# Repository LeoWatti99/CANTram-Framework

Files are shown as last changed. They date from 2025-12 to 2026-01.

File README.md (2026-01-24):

# CAN-TRAM-Framework
Das CAN-TRAM-Framework ist ein mikrocontrollerbasiertes, modulares Steuerungssystem, dass sich aus einzelnen Modulen zusammensetzen lässt. Die Struktur des Systems orientiert sich an üblichen SPS-Systemen, sodass eine CPU bzw. ein Hauptmodul um beliebig viele Module erweitert werden kann, um Funktionen hinzuzufügen.



## Inventor CAD Dateien öffnen
Die CAD Dateien des Projekts sind im Ordner [Inventor CAD](https://github.com/LeoWatti99/CANTram-Framework/tree/main/Inventor%20CAD)) enthalten. Um das Projekt wie vorgesehen zu öffnen muss in **Inventor 2025 oder höher** die Datei [Controller.ipj](https://github.com/LeoWatti99/CANTram-Framework/blob/main/Inventor%20CAD/Controller.ipj) geöffnet werden.

## KiCAD Schaltungen öffnen
Im Ordner [KiCad Schaltungen](https://github.com/LeoWatti99/CANTram-Framework/tree/main/KiCad%20Schaltungen) sind alle Projekte der einzelnen Platinen enthalten. Darin befinden sich sowhol Prototypen Schaltungen als auch aktuelle Modulplatinen. Um die Projekt zu öffnen wird **KiCAD 9.0.6 benötigt**. über die **.kicad_pro-Dateien** in den Unterordnern können die Projekte vollständig mit der Verlinkung zwischen Schaltplan und Layout geöffnet werden.

## C++ Framework
Die Firmware des Systems ist als C++ Bibliothek im Ordner [Framework](https://github.com/LeoWatti99/CANTram-Framework/tree/main/Framework) enthalten. 

## Dokumentation 
Die Software-Dokumentation kann [hier](https://leowatti99.github.io/CANTram-Framework/inherits.html) geöffnet werden. Sie wird automatisch durch **Doxygen** erstellt und nach Änderungen des Codes aktualisiert.

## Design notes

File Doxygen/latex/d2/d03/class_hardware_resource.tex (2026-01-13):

\doxysection{Hardware\+Resource Class Reference}
\hypertarget{class_hardware_resource}{}\label{class_hardware_resource}\index{HardwareResource@{HardwareResource}}

Base class for hardware resources like UART, SPI, I2C, PWM, etc.  

{\ttfamily \#include $<$Hardware\+Resource.\+h$>$}

Inheritance diagram for Hardware\+Resource\+:
\nopagebreak
\begin{figure}[H]
\begin{center}
\leavevmode
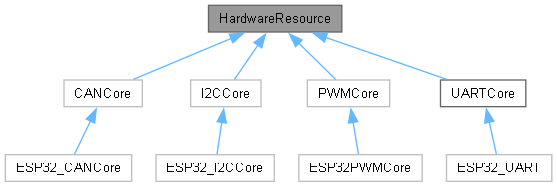
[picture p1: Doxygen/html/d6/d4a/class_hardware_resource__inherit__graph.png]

\end{center}
\end{figure}
\doxysubsubsection*{Public Types}
\begin{DoxyCompactItemize}
\item 
enum \mbox{\hyperlink{class_hardware_resource_adead6978be3d7b86c18e3d3e051381e6}{Type}} \{ \newline
\mbox{\hyperlink{class_hardware_resource_adead6978be3d7b86c18e3d3e051381e6ac6f39e4a2dbc764df53048f26209f0a1}{UART}}
, \mbox{\hyperlink{class_hardware_resource_adead6978be3d7b86c18e3d3e051381e6a63a2eead0d2771007afa8c8af281c50d}{SPI}}
, \mbox{\hyperlink{class_hardware_resource_adead6978be3d7b86c18e3d3e051381e6ac77292ec986f613995babba396598dbc}{I2C}}
, \mbox{\hyperlink{class_hardware_resource_adead6978be3d7b86c18e3d3e051381e6ac2fe3e8cc9a9a8fcb39c32be2da214c5}{PWM}}
, \newline
\mbox{\hyperlink{class_hardware_resource_adead6978be3d7b86c18e3d3e051381e6a0ae946256af51077cacc3c0a11575635}{CAN}}
 \}
\begin{DoxyCompactList}\small\item\em Enumeration of hardware resource types. \end{DoxyCompactList}\end{DoxyCompactItemize}
\doxysubsubsection*{Public Member Functions}
\begin{DoxyCompactItemize}
\item 
virtual \mbox{\hyperlink{class_hardware_resource_adead6978be3d7b86c18e3d3e051381e6}{Type}} \mbox{\hyperlink{class_hardware_resource_ad1058e4c12406f756755fad5db55dc77}{get\+Type}} ()=0
\begin{DoxyCompactList}\small\item\em Get the hardware resource type. \end{DoxyCompactList}\item 
virtual bool \mbox{\hyperlink{class_hardware_resource_a7372684f2afb5139ef8464194a087649}{reset}} ()
\begin{DoxyCompactList}\small\item\em Reset the hardware resource to a known default state. \end{DoxyCompactList}\item 
bool \mbox{\hyperlink{class_hardware_resource_a26f48b38e5bb1d9bdd47ea2e6de87fdb}{request\+Usage}} ()
\begin{DoxyCompactList}\small\item\em Request a usage slot for this resource. \end{DoxyCompactList}\item 
uint8\+\_\+t \mbox{\hyperlink{class_hardware_resource_a07205354c25627a3bb10ad417e335ff9}{get\+Usages}} ()
\begin{DoxyCompactList}\small\item\em Get the current number of usages of this resource. \end{DoxyCompactList}\item 
bool \mbox{\hyperlink{class_hardware_resource_a569821aa9a34d96ed143488a72e6872b}{is\+Used}} ()
\begin{DoxyCompactList}\small\item\em Check if the resource is currently used. \end{DoxyCompactList}\item 
virtual uint8\+\_\+t \mbox{\hyperlink{class_hardware_resource_a470679cae7880c9ca436755a50f68db4}{get\+Remaining\+Usages}} ()
\begin{DoxyCompactList}\small\item\em Get remaining usage capacity for this resource. \end{DoxyCompactList}\end{DoxyCompactItemize}
\doxysubsubsection*{Protected Member Functions}
\begin{DoxyCompactItemize}
\item 
\mbox{\hyperlink{class_hardware_resource_a7ddffb890a743f2df28128d9afd5bfa5}{Hardware\+Resource}} ()=default
\begin{DoxyCompactList}\small\item\em Default constructor. \end{DoxyCompactList}\item 
virtual uint8\+\_\+t \mbox{\hyperlink{class_hardware_resource_a6b7a709561faf5d344b7c3e14bf37558}{get\+Max\+Usages}} ()
\begin{DoxyCompactList}\small\item\em Get the maximum simultaneous usages allowed for this resource. \end{DoxyCompactList}\end{DoxyCompactItemize}
\doxysubsubsection*{Protected Attributes}
\begin{DoxyCompactItemize}
\item 
uint8\+\_\+t \mbox{\hyperlink{class_hardware_resource_a78845b363f906c0383e91ea912bbddbc}{usages}} =0
\begin{DoxyCompactList}\small\item\em Current usage counter. \end{DoxyCompactList}\end{DoxyCompactItemize}

\doxysubsection{Detailed Description}
Base class for hardware resources like UART, SPI, I2C, PWM, etc. 

\doxylink{class_hardware_resource}{Hardware\+Resource} provides a common interface for resources managed by \doxylink{class_c_a_n_tram_core}{CANTram\+Core}. It implements usage counting and default reset/usage behaviour. Derived classes must implement \doxylink{class_hardware_resource_ad1058e4c12406f756755fad5db55dc77}{get\+Type()} and may override \doxylink{class_hardware_resource_a6b7a709561faf5d344b7c3e14bf37558}{get\+Max\+Usages()} and \doxylink{class_hardware_resource_a7372684f2afb5139ef8464194a087649}{reset()} as required. 

\label{doc-enum-members}
\Hypertarget{class_hardware_resource_doc-enum-members}
\doxysubsection{Member Enumeration Documentation}
\Hypertarget{class_hardware_resource_adead6978be3d7b86c18e3d3e051381e6}\index{HardwareResource@{HardwareResource}!Type@{Type}}
\index{Type@{Type}!HardwareResource@{HardwareResource}}
\doxysubsubsection{\texorpdfstring{Type}{Type}}
{\footnotesize\ttfamily \label{class_hardware_resource_adead6978be3d7b86c18e3d3e051381e6} 
enum \mbox{\hyperlink{class_hardware_resource_adead6978be3d7b86c18e3d3e051381e6}{Hardware\+Resource\+::\+Type}}}

Enumeration of hardware resource types. 

Used to identify the concrete resource type when requesting or attaching resources. \begin{DoxyEnumFields}[2]{Enumerator}
\raisebox{\heightof{T}}[0pt][0pt]{\index{UART@{UART}!HardwareResource@{HardwareResource}}\index{HardwareResource@{HardwareResource}!UART@{UART}}}\Hypertarget{class_hardware_resource_adead6978be3d7b86c18e3d3e051381e6ac6f39e4a2dbc764df53048f26209f0a1}\label{class_hardware_resource_adead6978be3d7b86c18e3d3e051381e6ac6f39e4a2dbc764df53048f26209f0a1} 
UART&UART type. \\
\hline

\raisebox{\heightof{T}}[0pt][0pt]{\index{SPI@{SPI}!HardwareResource@{HardwareResource}}\index{HardwareResource@{HardwareResource}!SPI@{SPI}}}\Hypertarget{class_hardware_resource_adead6978be3d7b86c18e3d3e051381e6a63a2eead0d2771007afa8c8af281c50d}\label{class_hardware_resource_adead6978be3d7b86c18e3d3e051381e6a63a2eead0d2771007afa8c8af281c50d} 
SPI&SPI type. \\
\hline

\raisebox{\heightof{T}}[0pt][0pt]{\index{I2C@{I2C}!HardwareResource@{HardwareResource}}\index{HardwareResource@{HardwareResource}!I2C@{I2C}}}\Hypertarget{class_hardware_resource_adead6978be3d7b86c18e3d3e051381e6ac77292ec986f613995babba396598dbc}\label{class_hardware_resource_adead6978be3d7b86c18e3d3e051381e6ac77292ec986f613995babba396598dbc} 
I2C&I2C type. \\
\hline

\raisebox{\heightof{T}}[0pt][0pt]{\index{PWM@{PWM}!HardwareResource@{HardwareResource}}\index{HardwareResource@{HardwareResource}!PWM@{PWM}}}\Hypertarget{class_hardware_resource_adead6978be3d7b86c18e3d3e051381e6ac2fe3e8cc9a9a8fcb39c32be2da214c5}\label{class_hardware_resource_adead6978be3d7b86c18e3d3e051381e6ac2fe3e8cc9a9a8fcb39c32be2da214c5} 
PWM&PWM type. \\
\hline

\raisebox{\heightof{T}}[0pt][0pt]{\index{CAN@{CAN}!HardwareResource@{HardwareResource}}\index{HardwareResource@{HardwareResource}!CAN@{CAN}}}\Hypertarget{class_hardware_resource_adead6978be3d7b86c18e3d3e051381e6a0ae946256af51077cacc3c0a11575635}\label{class_hardware_resource_adead6978be3d7b86c18e3d3e051381e6a0ae946256af51077cacc3c0a11575635} 
CAN&CAN type. \\
\hline

\end{DoxyEnumFields}

\label{doc-constructors}
\Hypertarget{class_hardware_resource_doc-constructors}
\doxysubsection{Constructor \& Destructor Documentation}
\Hypertarget{class_hardware_resource_a7ddffb890a743f2df28128d9afd5bfa5}\index{HardwareResource@{HardwareResource}!HardwareResource@{HardwareResource}}
\index{HardwareResource@{HardwareResource}!HardwareResource@{HardwareResource}}
\doxysubsubsection{\texorpdfstring{HardwareResource()}{HardwareResource()}}
{\footnotesize\ttfamily \label{class_hardware_resource_a7ddffb890a743f2df28128d9afd5bfa5} 
Hardware\+Resource\+::\+Hardware\+Resource (\begin{DoxyParamCaption}{}{}\end{DoxyParamCaption})\hspace{0.3cm}{\ttfamily [protected]}, {\ttfamily [default]}}

Default constructor. 

Protected to prevent direct instantiation of the abstract base class. 

\label{doc-func-members}
\Hypertarget{class_hardware_resource_doc-func-members}
\doxysubsection{Member Function Documentation}
\Hypertarget{class_hardware_resource_a6b7a709561faf5d344b7c3e14bf37558}\index{HardwareResource@{HardwareResource}!getMaxUsages@{getMaxUsages}}
\index{getMaxUsages@{getMaxUsages}!HardwareResource@{HardwareResource}}
\doxysubsubsection{\texorpdfstring{getMaxUsages()}{getMaxUsages()}}
{\footnotesize\ttfamily \label{class_hardware_resource_a6b7a709561faf5d344b7c3e14bf37558} 
virtual uint8\+\_\+t Hardware\+Resource\+::get\+Max\+Usages (\begin{DoxyParamCaption}{}{}\end{DoxyParamCaption})\hspace{0.3cm}{\ttfamily [inline]}, {\ttfamily [protected]}, {\ttfamily [virtual]}}

Get the maximum simultaneous usages allowed for this resource. 

Default implementation returns 1. Override in derived classes to permit multiple users. \begin{DoxyReturn}{Returns}
uint8\+\_\+t Maximum number of concurrent usages allowed. 
\end{DoxyReturn}

Reimplemented in \mbox{\hyperlink{class_e_s_p32_p_w_m_core_a15e540c8230375afdf62ba4175712aa6}{ESP32\+PWMCore}}, \mbox{\hyperlink{class_i2_c_core_a4000d56ed283e62c7d50a4083e4762b6}{I2\+CCore}}, and \mbox{\hyperlink{class_p_w_m_core_a7d8fa8730b71956702cce7fe90b60a8d}{PWMCore}}.

Here is the caller graph for this function\+:
\nopagebreak
\begin{figure}[H]
\begin{center}
\leavevmode

\end{center}
\end{figure}
\Hypertarget{class_hardware_resource_a470679cae7880c9ca436755a50f68db4}\index{HardwareResource@{HardwareResource}!getRemainingUsages@{getRemainingUsages}}
\index{getRemainingUsages@{getRemainingUsages}!HardwareResource@{HardwareResource}}
\doxysubsubsection{\texorpdfstring{getRemainingUsages()}{getRemainingUsages()}}
{\footnotesize\ttfamily \label{class_hardware_resource_a470679cae7880c9ca436755a50f68db4} 
virtual uint8\+\_\+t Hardware\+Resource\+::get\+Remaining\+Usages (\begin{DoxyParamCaption}{}{}\end{DoxyParamCaption})\hspace{0.3cm}{\ttfamily [inline]}, {\ttfamily [virtual]}}

Get remaining usage capacity for this resource. 

Computes remaining usages as max usages minus current usages. Can be overridden by derived classes if needed. \begin{DoxyReturn}{Returns}
uint8\+\_\+t Number of remaining usages available. 
\end{DoxyReturn}
Here is the call graph for this function\+:
\nopagebreak
\begin{figure}[H]
\begin{center}
\leavevmode

\end{center}
\end{figure}
\Hypertarget{class_hardware_resource_ad1058e4c12406f756755fad5db55dc77}\index{HardwareResource@{HardwareResource}!getType@{getType}}
\index{getType@{getType}!HardwareResource@{HardwareResource}}
\doxysubsubsection{\texorpdfstring{getType()}{getType()}}
{\footnotesize\ttfamily \label{class_hardware_resource_ad1058e4c12406f756755fad5db55dc77} 
virtual \mbox{\hyperlink{class_hardware_resource_adead6978be3d7b86c18e3d3e051381e6}{Type}} Hardware\+Resource\+::get\+Type (\begin{DoxyParamCaption}{}{}\end{DoxyParamCaption})\hspace{0.3cm}{\ttfamily [pure virtual]}}

Get the hardware resource type. 

Must be implemented by derived classes to return the correct \doxylink{class_hardware_resource_adead6978be3d7b86c18e3d3e051381e6}{Type} enum value. \begin{DoxyReturn}{Returns}
\doxylink{class_hardware_resource_adead6978be3d7b86c18e3d3e051381e6}{Type} The type of the hardware resource. 
\end{DoxyReturn}

Implemented in \mbox{\hyperlink{class_e_s_p32___c_a_n_core_ac6c187e2a8158cfcc770b568e96706ec}{ESP32\+\_\+\+CANCore}}, \mbox{\hyperlink{class_i2_c_core_a092566ca5aacc4421559e29f6ff12da5}{I2\+CCore}}, \mbox{\hyperlink{class_p_w_m_core_a0d03256d58a18e60ac2375bfd3ad3a00}{PWMCore}}, and \mbox{\hyperlink{class_u_a_r_t_core_af2aad4efeda3999a508c721e8f2ce46e}{UARTCore}}.

Here is the caller graph for this function\+:
\nopagebreak
\begin{figure}[H]
\begin{center}
\leavevmode
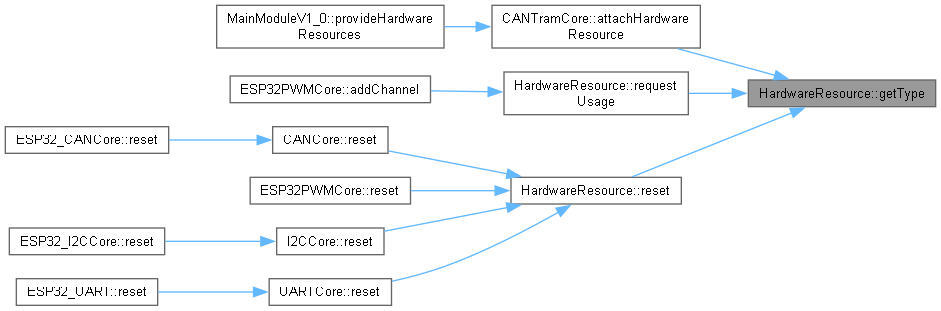
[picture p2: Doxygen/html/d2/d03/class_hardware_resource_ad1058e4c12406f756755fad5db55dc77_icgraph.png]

\end{center}
\end{figure}
\Hypertarget{class_hardware_resource_a07205354c25627a3bb10ad417e335ff9}\index{HardwareResource@{HardwareResource}!getUsages@{getUsages}}
\index{getUsages@{getUsages}!HardwareResource@{HardwareResource}}
\doxysubsubsection{\texorpdfstring{getUsages()}{getUsages()}}
{\footnotesize\ttfamily \label{class_hardware_resource_a07205354c25627a3bb10ad417e335ff9} 
uint8\+\_\+t Hardware\+Resource\+::get\+Usages (\begin{DoxyParamCaption}{}{}\end{DoxyParamCaption})\hspace{0.3cm}{\ttfamily [inline]}}

Get the current number of usages of this resource. 

Returns the number of modules that have requested/are using this hardware resource. \begin{DoxyReturn}{Returns}
uint8\+\_\+t Current usage count. 
\end{DoxyReturn}
\Hypertarget{class_hardware_resource_a569821aa9a34d96ed143488a72e6872b}\index{HardwareResource@{HardwareResource}!isUsed@{isUsed}}
\index{isUsed@{isUsed}!HardwareResource@{HardwareResource}}
\doxysubsubsection{\texorpdfstring{isUsed()}{isUsed()}}
{\footnotesize\ttfamily \label{class_hardware_resource_a569821aa9a34d96ed143488a72e6872b} 
bool Hardware\+Resource\+::is\+Used (\begin{DoxyParamCaption}{}{}\end{DoxyParamCaption})\hspace{0.3cm}{\ttfamily [inline]}}

Check if the resource is currently used. 

Returns true when at least one usage has been requested. \begin{DoxyReturn}{Returns}
true if the resource is in use, false otherwise. 
\end{DoxyReturn}
\Hypertarget{class_hardware_resource_a26f48b38e5bb1d9bdd47ea2e6de87fdb}\index{HardwareResource@{HardwareResource}!requestUsage@{requestUsage}}
\index{requestUsage@{requestUsage}!HardwareResource@{HardwareResource}}
\doxysubsubsection{\texorpdfstring{requestUsage()}{requestUsage()}}
{\footnotesize\ttfamily \label{class_hardware_resource_a26f48b38e5bb1d9bdd47ea2e6de87fdb} 
bool Hardware\+Resource\+::request\+Usage (\begin{DoxyParamCaption}{}{}\end{DoxyParamCaption})\hspace{0.3cm}{\ttfamily [inline]}}

Request a usage slot for this resource. 

Increments the internal usage counter if the resource has remaining capacity. If the resource is already at its maximum usages, the request is rejected and an error is logged. \begin{DoxyReturn}{Returns}
true if the usage request was granted, false if the resource is already fully used. 
\end{DoxyReturn}
Here is the call graph for this function\+:
\nopagebreak
\begin{figure}[H]
\begin{center}
\leavevmode

\end{center}
\end{figure}
Here is the caller graph for this function\+:
\nopagebreak
\begin{figure}[H]
\begin{center}
\leavevmode

\end{center}
\end{figure}
\Hypertarget{class_hardware_resource_a7372684f2afb5139ef8464194a087649}\index{HardwareResource@{HardwareResource}!reset@{reset}}
\index{reset@{reset}!HardwareResource@{HardwareResource}}
\doxysubsubsection{\texorpdfstring{reset()}{reset()}}
{\footnotesize\ttfamily \label{class_hardware_resource_a7372684f2afb5139ef8464194a087649} 
virtual bool Hardware\+Resource\+::reset (\begin{DoxyParamCaption}{}{}\end{DoxyParamCaption})\hspace{0.3cm}{\ttfamily [inline]}, {\ttfamily [virtual]}}

Reset the hardware resource to a known default state. 

Default implementation clears the usage counter and logs the reset. Derived classes should call the base implementation and perform any additional hardware-\/specific reset steps. \begin{DoxyReturn}{Returns}
true if the reset succeeded, false otherwise. 
\end{DoxyReturn}

Reimplemented in \mbox{\hyperlink{class_c_a_n_core_a611efb48b44ea62f1a7b6428671863ca}{CANCore}}, \mbox{\hyperlink{class_e_s_p32___c_a_n_core_a85a0e3c4965503c96d865bbcc200cd2a}{ESP32\+\_\+\+CANCore}}, \mbox{\hyperlink{class_e_s_p32___i2_c_core_aa3e0817cba1f01e19e046fa27a776eab}{ESP32\+\_\+\+I2\+CCore}}, \mbox{\hyperlink{class_e_s_p32___u_a_r_t_a0729d44483caad65176f225c7924755c}{ESP32\+\_\+\+UART}}, \mbox{\hyperlink{class_e_s_p32_p_w_m_core_adb2ff5f5f836bf15913d129c639426dd}{ESP32\+PWMCore}}, \mbox{\hyperlink{class_i2_c_core_a0c8934608811f1a80247981f4e222ce9}{I2\+CCore}}, and \mbox{\hyperlink{class_u_a_r_t_core_aeaf04f4297b48fdaee839a2ff9fb4ad4}{UARTCore}}.

Here is the call graph for this function\+:
\nopagebreak
\begin{figure}[H]
\begin{center}
\leavevmode

\end{center}
\end{figure}
Here is the caller graph for this function\+:
\nopagebreak
\begin{figure}[H]
\begin{center}
\leavevmode
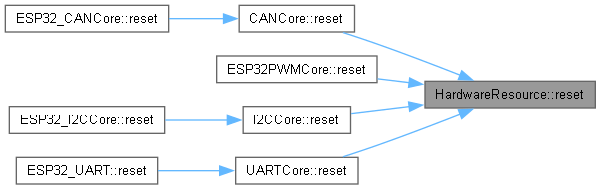
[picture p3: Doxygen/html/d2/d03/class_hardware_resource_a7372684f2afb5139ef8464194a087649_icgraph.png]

\end{center}
\end{figure}

\label{doc-variable-members}
\Hypertarget{class_hardware_resource_doc-variable-members}
\doxysubsection{Member Data Documentation}
\Hypertarget{class_hardware_resource_a78845b363f906c0383e91ea912bbddbc}\index{HardwareResource@{HardwareResource}!usages@{usages}}
\index{usages@{usages}!HardwareResource@{HardwareResource}}
\doxysubsubsection{\texorpdfstring{usages}{usages}}
{\footnotesize\ttfamily \label{class_hardware_resource_a78845b363f906c0383e91ea912bbddbc} 
uint8\+\_\+t Hardware\+Resource\+::usages =0\hspace{0.3cm}{\ttfamily [protected]}}

Current usage counter. 

Tracks how many clients/modules have requested this resource. 

The documentation for this class was generated from the following file\+:\begin{DoxyCompactItemize}
\item 
C\+:/\+Users/leowa/\+Documents/\+Platform\+IO/\+Projects/\+CANTram\+Framework\+Usage/lib/\+CANTram\+Framework/include/\mbox{\hyperlink{_hardware_resource_8h}{Hardware\+Resource.\+h}}\end{DoxyCompactItemize}

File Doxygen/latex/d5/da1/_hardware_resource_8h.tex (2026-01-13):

\doxysection{C\+:/\+Users/leowa/\+Documents/\+Platform\+IO/\+Projects/\+CANTram\+Framework\+Usage/lib/\+CANTram\+Framework/include/\+Hardware\+Resource.h File Reference}
\hypertarget{_hardware_resource_8h}{}\label{_hardware_resource_8h}\index{C:/Users/leowa/Documents/PlatformIO/Projects/CANTramFrameworkUsage/lib/CANTramFramework/include/HardwareResource.h@{C:/Users/leowa/Documents/PlatformIO/Projects/CANTramFrameworkUsage/lib/CANTramFramework/include/HardwareResource.h}}

Base class for hardware resources.  

{\ttfamily \#include "{}Debug.\+h"{}}\newline
Include dependency graph for Hardware\+Resource.\+h\+:
\nopagebreak
\begin{figure}[H]
\begin{center}
\leavevmode
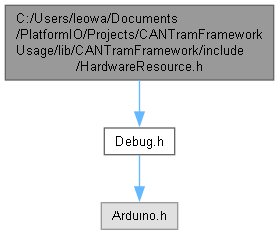
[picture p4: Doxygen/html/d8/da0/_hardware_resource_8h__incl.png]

\end{center}
\end{figure}
This graph shows which files directly or indirectly include this file\+:
\nopagebreak
\begin{figure}[H]
\begin{center}
\leavevmode
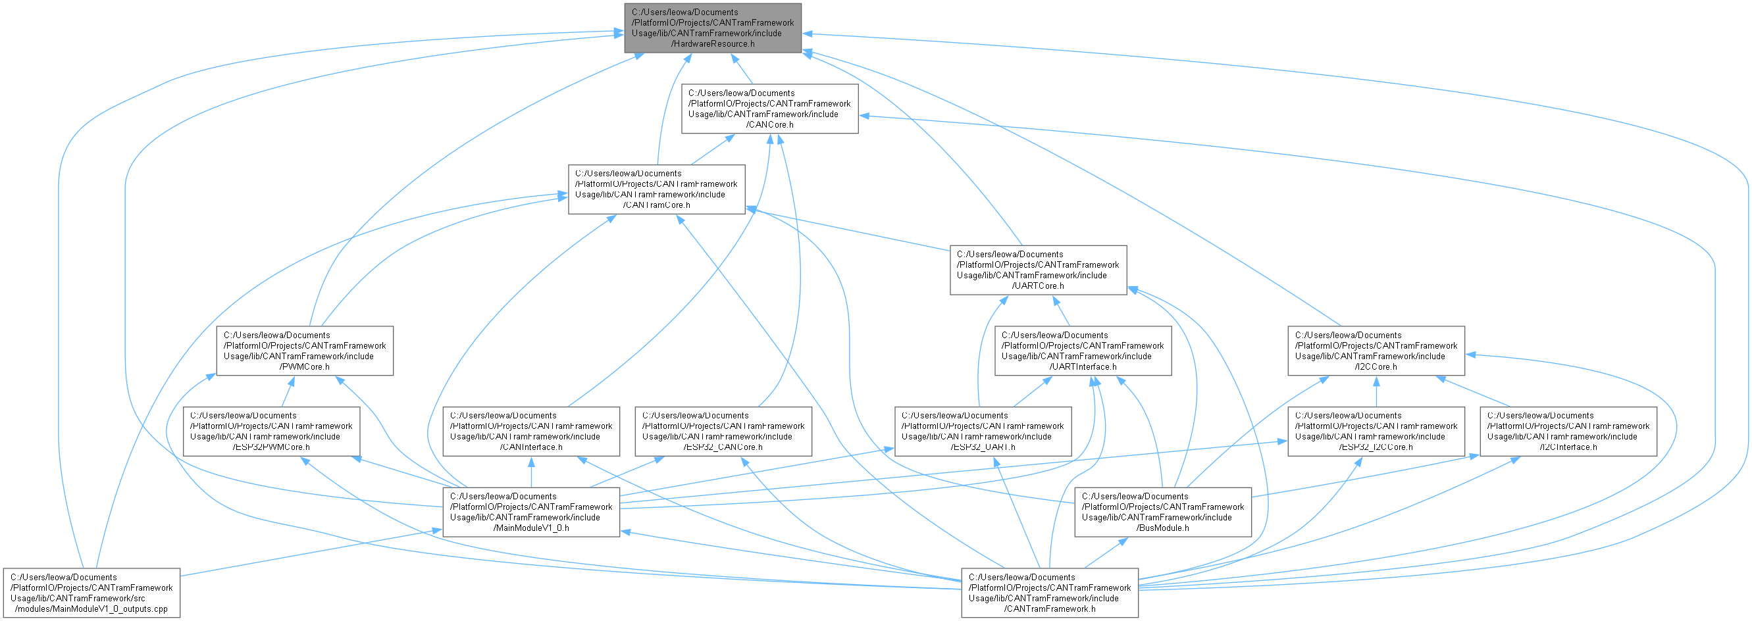
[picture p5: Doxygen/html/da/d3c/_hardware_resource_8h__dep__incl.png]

\end{center}
\end{figure}
\doxysubsubsection*{Classes}
\begin{DoxyCompactItemize}
\item 
class \mbox{\hyperlink{class_hardware_resource}{Hardware\+Resource}}
\begin{DoxyCompactList}\small\item\em Base class for hardware resources like UART, SPI, I2C, PWM, etc. \end{DoxyCompactList}\end{DoxyCompactItemize}

\doxysubsection{Detailed Description}
Base class for hardware resources. 

Defines the abstract base class for hardware resources (UART, SPI, I2C, PWM) used by the \doxylink{class_c_a_n_tram_core}{CANTram\+Core}. Provides usage counting and basic lifecycle methods that concrete hardware resource implementations should override.

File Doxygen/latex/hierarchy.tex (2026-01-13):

\doxysection{Class Hierarchy}
This inheritance list is sorted roughly, but not completely, alphabetically\+:\begin{DoxyCompactList}
\item \contentsline{section}{MAX22531\+::Burst\+Response}{\pageref{struct_m_a_x22531_1_1_burst_response}}{}
\item \contentsline{section}{CANCore\+::CANMessage}{\pageref{struct_c_a_n_core_1_1_c_a_n_message}}{}
\item \contentsline{section}{CANTram\+Core}{\pageref{class_c_a_n_tram_core}}{}
\item \contentsline{section}{CANTram\+Module}{\pageref{class_c_a_n_tram_module}}{}
\begin{DoxyCompactList}
\item \contentsline{section}{Analog\+Module\+V1\+\_\+0}{\pageref{class_analog_module_v1__0}}{}
\item \contentsline{section}{Bus\+Module\+V1\+\_\+0}{\pageref{class_bus_module_v1__0}}{}
\item \contentsline{section}{Digital\+Module\+V1\+\_\+0}{\pageref{class_digital_module_v1__0}}{}
\item \contentsline{section}{Main\+Module\+V1\+\_\+0}{\pageref{class_main_module_v1__0}}{}
\item \contentsline{section}{Relais\+Module\+V1\+\_\+0}{\pageref{class_relais_module_v1__0}}{}
\end{DoxyCompactList}
\item \contentsline{section}{ISO1\+I813T\+::Data}{\pageref{struct_i_s_o1_i813_t_1_1_data}}{}
\item \contentsline{section}{ISO1\+I813T\+::Diag}{\pageref{struct_i_s_o1_i813_t_1_1_diag}}{}
\item \contentsline{section}{Hardware\+Resource}{\pageref{class_hardware_resource}}{}
\begin{DoxyCompactList}
\item \contentsline{section}{CANCore}{\pageref{class_c_a_n_core}}{}
\begin{DoxyCompactList}
\item \contentsline{section}{ESP32\+\_\+\+CANCore}{\pageref{class_e_s_p32___c_a_n_core}}{}
\end{DoxyCompactList}
\item \contentsline{section}{I2\+CCore}{\pageref{class_i2_c_core}}{}
\begin{DoxyCompactList}
\item \contentsline{section}{ESP32\+\_\+\+I2\+CCore}{\pageref{class_e_s_p32___i2_c_core}}{}
\end{DoxyCompactList}
\item \contentsline{section}{PWMCore}{\pageref{class_p_w_m_core}}{}
\begin{DoxyCompactList}
\item \contentsline{section}{ESP32\+PWMCore}{\pageref{class_e_s_p32_p_w_m_core}}{}
\end{DoxyCompactList}
\item \contentsline{section}{UARTCore}{\pageref{class_u_a_r_t_core}}{}
\begin{DoxyCompactList}
\item \contentsline{section}{ESP32\+\_\+\+UART}{\pageref{class_e_s_p32___u_a_r_t}}{}
\end{DoxyCompactList}
\end{DoxyCompactList}
\item \contentsline{section}{Interface}{\pageref{class_interface}}{}
\begin{DoxyCompactList}
\item \contentsline{section}{Analog\+Input}{\pageref{class_analog_input}}{}
\item \contentsline{section}{Analog\+Output}{\pageref{class_analog_output}}{}
\item \contentsline{section}{CANInterface}{\pageref{class_c_a_n_interface}}{}
\item \contentsline{section}{Digital\+Input}{\pageref{class_digital_input}}{}
\item \contentsline{section}{Digital\+Output}{\pageref{class_digital_output}}{}
\item \contentsline{section}{I2\+CInterface}{\pageref{class_i2_c_interface}}{}
\item \contentsline{section}{Relais\+Interface}{\pageref{class_relais_interface}}{}
\item \contentsline{section}{UARTInterface}{\pageref{class_u_a_r_t_interface}}{}
\end{DoxyCompactList}
\item \contentsline{section}{Output\+Definition}{\pageref{class_output_definition}}{}
\item \contentsline{section}{Output\+Provider}{\pageref{class_output_provider}}{}
\begin{DoxyCompactList}
\item \contentsline{section}{PWMOutput\+Provider}{\pageref{class_p_w_m_output_provider}}{}
\begin{DoxyCompactList}
\item \contentsline{section}{Main\+Module\+V1\+\_\+0}{\pageref{class_main_module_v1__0}}{}
\end{DoxyCompactList}
\end{DoxyCompactList}
\item \contentsline{section}{SPIChip}{\pageref{class_s_p_i_chip}}{}
\begin{DoxyCompactList}
\item \contentsline{section}{ISO1\+H816G}{\pageref{class_i_s_o1_h816_g}}{}
\item \contentsline{section}{ISO1\+I813T}{\pageref{class_i_s_o1_i813_t}}{}
\item \contentsline{section}{MAX22531}{\pageref{class_m_a_x22531}}{}
\end{DoxyCompactList}
\item \contentsline{section}{UARTProvider}{\pageref{class_u_a_r_t_provider}}{}
\begin{DoxyCompactList}
\item \contentsline{section}{Main\+Module\+V1\+\_\+0}{\pageref{class_main_module_v1__0}}{}
\end{DoxyCompactList}
\end{DoxyCompactList}

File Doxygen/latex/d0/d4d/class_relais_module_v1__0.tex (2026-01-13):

\doxysection{Relais\+Module\+V1\+\_\+0 Class Reference}
\hypertarget{class_relais_module_v1__0}{}\label{class_relais_module_v1__0}\index{RelaisModuleV1\_0@{RelaisModuleV1\_0}}

Inheritance diagram for Relais\+Module\+V1\+\_\+0\+:
\nopagebreak
\begin{figure}[H]
\begin{center}
\leavevmode

\end{center}
\end{figure}

Collaboration diagram for Relais\+Module\+V1\+\_\+0\+:
\nopagebreak
\begin{figure}[H]
\begin{center}
\leavevmode

\end{center}
\end{figure}
\doxysubsubsection*{Public Member Functions}
\begin{DoxyCompactItemize}
\item 
String \mbox{\hyperlink{class_relais_module_v1__0_ad4d2c5de92e8bee2911ad9f228148c35}{get\+HWType}} () const override
\begin{DoxyCompactList}\small\item\em Get the hardware type string. \end{DoxyCompactList}\item 
String \mbox{\hyperlink{class_relais_module_v1__0_a2256db6eb1b2430fc9fbb82ad05152dd}{get\+HWVersion}} () const override
\begin{DoxyCompactList}\small\item\em Get the hardware version string. \end{DoxyCompactList}\item 
String \mbox{\hyperlink{class_relais_module_v1__0_a5b51d4cb5afd3981a560c4084c8a8933}{get\+FWVersion}} () const override
\begin{DoxyCompactList}\small\item\em Get the firmware version string. \end{DoxyCompactList}\item 
uint8\+\_\+t \mbox{\hyperlink{class_relais_module_v1__0_a078c91e0b5bc3f21a22bc71388ea1b0d}{get\+GPIODemand}} () const override
\begin{DoxyCompactList}\small\item\em Get the GPIO demand of the module. \end{DoxyCompactList}\item 
uint8\+\_\+t \mbox{\hyperlink{class_relais_module_v1__0_ac06c3a60aebdb574e90d3b28a6b944e3}{get\+GPIOSupply}} () const override
\begin{DoxyCompactList}\small\item\em Get the GPIO supply capacity of the module. \end{DoxyCompactList}\item 
bool \mbox{\hyperlink{class_relais_module_v1__0_a1a7004ca779f46212dde0bd70c0a8bca}{attach\+Module}} (uint8\+\_\+t slot, uint8\+\_\+t gpio\+Start) override
\begin{DoxyCompactList}\small\item\em Attach this module to a slot and assign GPIO range. \end{DoxyCompactList}\item 
bool \mbox{\hyperlink{class_relais_module_v1__0_a6373363c88ca982860ec7f07f81005cb}{provide\+GPIOs}} () override
\begin{DoxyCompactList}\small\item\em Provide GPIO definitions to the core. \end{DoxyCompactList}\item 
bool \mbox{\hyperlink{class_relais_module_v1__0_af2e4f33d631bc14e433c404678347b67}{request\+GPIOs}} () override
\begin{DoxyCompactList}\small\item\em Request GPIO definitions from the core. \end{DoxyCompactList}\item 
bool \mbox{\hyperlink{class_relais_module_v1__0_ac9c120d926b21c489108c1f925f2abac}{provide\+Hardware\+Resources}} () override
\begin{DoxyCompactList}\small\item\em Provide hardware resources (e.\+g., I2C, SPI, UART) to the core. \end{DoxyCompactList}\item 
bool \mbox{\hyperlink{class_relais_module_v1__0_abb33be265117a963c1ab9c34e34ea082}{request\+Hardware\+Resources}} () override
\begin{DoxyCompactList}\small\item\em Request hardware resources from the core. \end{DoxyCompactList}\item 
bool \mbox{\hyperlink{class_relais_module_v1__0_ace1bb24ccb82505ab38059203b179f1a}{add\+Interfaces}} () override
\begin{DoxyCompactList}\small\item\em Setup and validate module interfaces. \end{DoxyCompactList}\item 
bool \mbox{\hyperlink{class_relais_module_v1__0_aee1e17f77ccc4737865e34291e86c103}{initialize}} () override
\begin{DoxyCompactList}\small\item\em Initialize the module after attachment and provisioning. \end{DoxyCompactList}\item 
void \mbox{\hyperlink{class_relais_module_v1__0_a6036020b6f6dd6cbb9ab1c6428fa719b}{cycle}} (uint8\+\_\+t \texorpdfstring{$\ast$}{*}response) override
\begin{DoxyCompactList}\small\item\em Periodic cycle callback. \end{DoxyCompactList}\item 
\mbox{\hyperlink{class_interface}{Interface}} \texorpdfstring{$\ast$}{*}\texorpdfstring{$\ast$}{*} \mbox{\hyperlink{class_relais_module_v1__0_a78579ed4ffa12aa6978e2c319632cbef}{get\+Interfaces}} () override
\begin{DoxyCompactList}\small\item\em Get pointer to module\textquotesingle{}s interface array. \end{DoxyCompactList}\item 
size\+\_\+t \mbox{\hyperlink{class_relais_module_v1__0_ae437de38ae5e1caa91ea6d6fca5b7519}{get\+Interface\+Count}} () override
\begin{DoxyCompactList}\small\item\em Get number of interfaces provided by the module. \end{DoxyCompactList}\end{DoxyCompactItemize}
\doxysubsection*{Public Member Functions inherited from \mbox{\hyperlink{class_c_a_n_tram_module}{CANTram\+Module}}}
\begin{DoxyCompactItemize}
\item 
\mbox{\hyperlink{class_c_a_n_tram_module_ae1c9554adb901b7e798a44d521781c0b}{CANTram\+Module}} ()=default
\begin{DoxyCompactList}\small\item\em Default constructor. \end{DoxyCompactList}\item 
virtual \mbox{\hyperlink{class_c_a_n_tram_module_a8f93d67f0d5b49b7864369196cb323e6}{\texorpdfstring{$\sim$}{\string~}\+CANTram\+Module}} ()=default
\begin{DoxyCompactList}\small\item\em Destructor. \end{DoxyCompactList}\item 
virtual bool \mbox{\hyperlink{class_c_a_n_tram_module_a496814b4e5fa5f162c48f17ec33d4475}{reset}} ()
\begin{DoxyCompactList}\small\item\em Reset the module to a known default state. \end{DoxyCompactList}\item 
uint8\+\_\+t \mbox{\hyperlink{class_c_a_n_tram_module_a80b400128bb6f0841953bb7a75cbf99c}{get\+Slot}} () const
\begin{DoxyCompactList}\small\item\em Get assigned slot index. \end{DoxyCompactList}\item 
uint8\+\_\+t \mbox{\hyperlink{class_c_a_n_tram_module_a7905817e8fee9e8bccfc9bbe70ae5669}{get\+GPIOStart}} () const
\begin{DoxyCompactList}\small\item\em Get starting GPIO index assigned to the module. \end{DoxyCompactList}\item 
virtual bool \mbox{\hyperlink{class_c_a_n_tram_module_a329b502ade3a32987994381c93ddbd0b}{pre\+Initialize}} ()
\begin{DoxyCompactList}\small\item\em Pre-\/initialize the module after attachment and provisioning. \end{DoxyCompactList}\end{DoxyCompactItemize}
\doxysubsubsection*{Static Public Attributes}
\begin{DoxyCompactItemize}
\item 
\Hypertarget{class_relais_module_v1__0_aa96cef931f16873dafa159187ee68a7c}\label{class_relais_module_v1__0_aa96cef931f16873dafa159187ee68a7c} 
static const String {\bfseries HW\+\_\+\+TYPE} = "{}Relais\+Module"{}
\item 
\Hypertarget{class_relais_module_v1__0_a9172f8ff4672c64149b891d7386fb1c4}\label{class_relais_module_v1__0_a9172f8ff4672c64149b891d7386fb1c4} 
static const String {\bfseries HW\+\_\+\+VERSION} = "{}1.\+0"{}
\item 
\Hypertarget{class_relais_module_v1__0_a9c40d65dae8fbec4258c6e6706c76a4b}\label{class_relais_module_v1__0_a9c40d65dae8fbec4258c6e6706c76a4b} 
static const String {\bfseries FW\+\_\+\+VERSION} = "{}1.\+0.\+0"{}
\item 
\Hypertarget{class_relais_module_v1__0_a3e492115ca6597982c7edcafd7ec5d6c}\label{class_relais_module_v1__0_a3e492115ca6597982c7edcafd7ec5d6c} 
static constexpr uint8\+\_\+t {\bfseries GPIO\+\_\+\+DEMAND} = 4
\item 
\Hypertarget{class_relais_module_v1__0_a3e86b6606c1915df8015e146bb4bb1c5}\label{class_relais_module_v1__0_a3e86b6606c1915df8015e146bb4bb1c5} 
static constexpr uint8\+\_\+t {\bfseries GPIO\+\_\+\+SUPPLY} = 0
\end{DoxyCompactItemize}
\doxysubsubsection*{Additional Inherited Members}
\doxysubsection*{Protected Attributes inherited from \mbox{\hyperlink{class_c_a_n_tram_module}{CANTram\+Module}}}
\begin{DoxyCompactItemize}
\item 
uint8\+\_\+t {\bfseries SLOT} = 0
\item 
uint8\+\_\+t {\bfseries GPIO\+\_\+\+START} = 0
\end{DoxyCompactItemize}

\label{doc-func-members}
\Hypertarget{class_relais_module_v1__0_doc-func-members}
\doxysubsection{Member Function Documentation}
\Hypertarget{class_relais_module_v1__0_ace1bb24ccb82505ab38059203b179f1a}\index{RelaisModuleV1\_0@{RelaisModuleV1\_0}!addInterfaces@{addInterfaces}}
\index{addInterfaces@{addInterfaces}!RelaisModuleV1\_0@{RelaisModuleV1\_0}}
\doxysubsubsection{\texorpdfstring{addInterfaces()}{addInterfaces()}}
{\footnotesize\ttfamily \label{class_relais_module_v1__0_ace1bb24ccb82505ab38059203b179f1a} 
bool Relais\+Module\+V1\+\_\+0\+::add\+Interfaces (\begin{DoxyParamCaption}{}{}\end{DoxyParamCaption})\hspace{0.3cm}{\ttfamily [override]}, {\ttfamily [virtual]}}

Setup and validate module interfaces. 

Populate the module\textquotesingle{}s Interface\texorpdfstring{$\ast$}{*} array, name interfaces and validate them as needed. \begin{DoxyReturn}{Returns}
true if interfaces were successfully added and validated, false otherwise. 
\end{DoxyReturn}

Implements \mbox{\hyperlink{class_c_a_n_tram_module_a14b79b625e82a3f11ebbb8271b6466b7}{CANTram\+Module}}.

\Hypertarget{class_relais_module_v1__0_a1a7004ca779f46212dde0bd70c0a8bca}\index{RelaisModuleV1\_0@{RelaisModuleV1\_0}!attachModule@{attachModule}}
\index{attachModule@{attachModule}!RelaisModuleV1\_0@{RelaisModuleV1\_0}}
\doxysubsubsection{\texorpdfstring{attachModule()}{attachModule()}}
{\footnotesize\ttfamily \label{class_relais_module_v1__0_a1a7004ca779f46212dde0bd70c0a8bca} 
bool Relais\+Module\+V1\+\_\+0\+::attach\+Module (\begin{DoxyParamCaption}\item[{uint8\+\_\+t}]{slot}{, }\item[{uint8\+\_\+t}]{gpio\+Start}{}\end{DoxyParamCaption})\hspace{0.3cm}{\ttfamily [override]}, {\ttfamily [virtual]}}

Attach this module to a slot and assign GPIO range. 

Attach this module to a slot and assign its GPIO range.

Initializes the module\textquotesingle{}s internal SLOT and GPIO\+\_\+\+START and triggers GPIO/resource provisioning and interface registration sequences. 
\begin{DoxyParams}{Parameters}
{\em slot} & Slot index to attach the module to. \\
\hline
{\em gpio\+Start} & Starting GPIO index assigned to this module. \\
\hline
\end{DoxyParams}
\begin{DoxyReturn}{Returns}
true if attachment and provisioning succeeded, false otherwise.
\end{DoxyReturn}
Sets the module\textquotesingle{}s SLOT and GPIO\+\_\+\+START values, logs the attachment and runs the standard initialization sequence\+: provide\+GPIOs, provide\+Hardware\+Resources, request\+GPIOs, request\+Hardware\+Resources and add\+Interfaces. Logs success or warnings based on the combined result. 
\begin{DoxyParams}{Parameters}
{\em slot} & Slot index to attach the module to. \\
\hline
{\em gpio\+Start} & Starting GPIO index assigned to this module. \\
\hline
\end{DoxyParams}
\begin{DoxyReturn}{Returns}
true if all initialization steps succeeded, false if any step failed. 
\end{DoxyReturn}

Reimplemented from \mbox{\hyperlink{class_c_a_n_tram_module_a67cab1c238257e6d9b88afc4f644e477}{CANTram\+Module}}.

Here is the call graph for this function\+:
\nopagebreak
\begin{figure}[H]
\begin{center}
\leavevmode
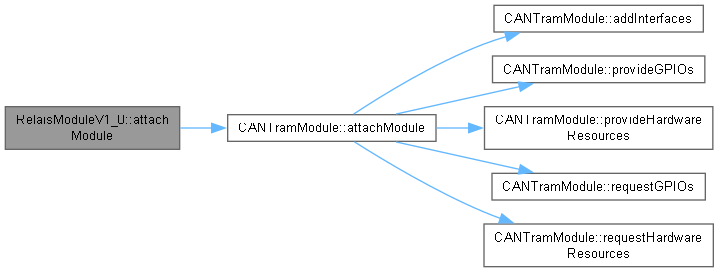
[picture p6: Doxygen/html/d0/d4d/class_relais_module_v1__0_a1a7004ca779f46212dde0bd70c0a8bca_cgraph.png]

\end{center}
\end{figure}
\Hypertarget{class_relais_module_v1__0_a6036020b6f6dd6cbb9ab1c6428fa719b}\index{RelaisModuleV1\_0@{RelaisModuleV1\_0}!cycle@{cycle}}
\index{cycle@{cycle}!RelaisModuleV1\_0@{RelaisModuleV1\_0}}
\doxysubsubsection{\texorpdfstring{cycle()}{cycle()}}
{\footnotesize\ttfamily \label{class_relais_module_v1__0_a6036020b6f6dd6cbb9ab1c6428fa719b} 
void Relais\+Module\+V1\+\_\+0\+::cycle (\begin{DoxyParamCaption}\item[{uint8\+\_\+t \texorpdfstring{$\ast$}{*}}]{response}{}\end{DoxyParamCaption})\hspace{0.3cm}{\ttfamily [override]}, {\ttfamily [virtual]}}

Periodic cycle callback. 

Called regularly by the core to allow the module to perform time-\/based tasks. 
\begin{DoxyParams}{Parameters}
{\em response} & Optional pointer to a response buffer where the module may write response bytes. May be nullptr. \\
\hline
\end{DoxyParams}

Reimplemented from \mbox{\hyperlink{class_c_a_n_tram_module_a1be4a73e5fc8e14edad90741593d2d29}{CANTram\+Module}}.

Here is the call graph for this function\+:
\nopagebreak
\begin{figure}[H]
\begin{center}
\leavevmode

\end{center}
\end{figure}
\Hypertarget{class_relais_module_v1__0_a5b51d4cb5afd3981a560c4084c8a8933}\index{RelaisModuleV1\_0@{RelaisModuleV1\_0}!getFWVersion@{getFWVersion}}
\index{getFWVersion@{getFWVersion}!RelaisModuleV1\_0@{RelaisModuleV1\_0}}
\doxysubsubsection{\texorpdfstring{getFWVersion()}{getFWVersion()}}
{\footnotesize\ttfamily \label{class_relais_module_v1__0_a5b51d4cb5afd3981a560c4084c8a8933} 
String Relais\+Module\+V1\+\_\+0\+::get\+FWVersion (\begin{DoxyParamCaption}{}{}\end{DoxyParamCaption}) const\hspace{0.3cm}{\ttfamily [inline]}, {\ttfamily [override]}, {\ttfamily [virtual]}}

Get the firmware version string. 

Returns the firmware version string implemented by the module. \begin{DoxyReturn}{Returns}
String Firmware version (e.\+g. "{}1.\+0"{}). 
\end{DoxyReturn}

Implements \mbox{\hyperlink{class_c_a_n_tram_module_acf8e6722dc924b1bf4d5289f3684fd29}{CANTram\+Module}}.

\Hypertarget{class_relais_module_v1__0_a078c91e0b5bc3f21a22bc71388ea1b0d}\index{RelaisModuleV1\_0@{RelaisModuleV1\_0}!getGPIODemand@{getGPIODemand}}
\index{getGPIODemand@{getGPIODemand}!RelaisModuleV1\_0@{RelaisModuleV1\_0}}
\doxysubsubsection{\texorpdfstring{getGPIODemand()}{getGPIODemand()}}
{\footnotesize\ttfamily \label{class_relais_module_v1__0_a078c91e0b5bc3f21a22bc71388ea1b0d} 
uint8\+\_\+t Relais\+Module\+V1\+\_\+0\+::get\+GPIODemand (\begin{DoxyParamCaption}{}{}\end{DoxyParamCaption}) const\hspace{0.3cm}{\ttfamily [inline]}, {\ttfamily [override]}, {\ttfamily [virtual]}}

Get the GPIO demand of the module. 

Returns how many GPIOs this module requires from the core. \begin{DoxyReturn}{Returns}
uint8\+\_\+t Number of GPIOs demanded by the module. 
\end{DoxyReturn}

Implements \mbox{\hyperlink{class_c_a_n_tram_module_afa6df5b58f7681a8a316b3910f987cce}{CANTram\+Module}}.

\Hypertarget{class_relais_module_v1__0_ac06c3a60aebdb574e90d3b28a6b944e3}\index{RelaisModuleV1\_0@{RelaisModuleV1\_0}!getGPIOSupply@{getGPIOSupply}}
\index{getGPIOSupply@{getGPIOSupply}!RelaisModuleV1\_0@{RelaisModuleV1\_0}}
\doxysubsubsection{\texorpdfstring{getGPIOSupply()}{getGPIOSupply()}}
{\footnotesize\ttfamily \label{class_relais_module_v1__0_ac06c3a60aebdb574e90d3b28a6b944e3} 
uint8\+\_\+t Relais\+Module\+V1\+\_\+0\+::get\+GPIOSupply (\begin{DoxyParamCaption}{}{}\end{DoxyParamCaption}) const\hspace{0.3cm}{\ttfamily [inline]}, {\ttfamily [override]}, {\ttfamily [virtual]}}

Get the GPIO supply capacity of the module. 

Returns how many GPIOs this module provides/supplies to the system. \begin{DoxyReturn}{Returns}
uint8\+\_\+t Number of GPIOs supplied by the module. 
\end{DoxyReturn}

Implements \mbox{\hyperlink{class_c_a_n_tram_module_ae7247503120b76151cc2086dc4250911}{CANTram\+Module}}.

\Hypertarget{class_relais_module_v1__0_ad4d2c5de92e8bee2911ad9f228148c35}\index{RelaisModuleV1\_0@{RelaisModuleV1\_0}!getHWType@{getHWType}}
\index{getHWType@{getHWType}!RelaisModuleV1\_0@{RelaisModuleV1\_0}}
\doxysubsubsection{\texorpdfstring{getHWType()}{getHWType()}}
{\footnotesize\ttfamily \label{class_relais_module_v1__0_ad4d2c5de92e8bee2911ad9f228148c35} 
String Relais\+Module\+V1\+\_\+0\+::get\+HWType (\begin{DoxyParamCaption}{}{}\end{DoxyParamCaption}) const\hspace{0.3cm}{\ttfamily [inline]}, {\ttfamily [override]}, {\ttfamily [virtual]}}

Get the hardware type string. 

Returns a human readable hardware type identifier for the concrete module implementation. \begin{DoxyReturn}{Returns}
String Hardware type identifier (e.\+g. "{}\+Main\+Module\+V1.\+0"{}). 
\end{DoxyReturn}

Implements \mbox{\hyperlink{class_c_a_n_tram_module_a3edca0142c5fa8a0d91a549f8371b460}{CANTram\+Module}}.

\Hypertarget{class_relais_module_v1__0_a2256db6eb1b2430fc9fbb82ad05152dd}\index{RelaisModuleV1\_0@{RelaisModuleV1\_0}!getHWVersion@{getHWVersion}}
\index{getHWVersion@{getHWVersion}!RelaisModuleV1\_0@{RelaisModuleV1\_0}}
\doxysubsubsection{\texorpdfstring{getHWVersion()}{getHWVersion()}}
{\footnotesize\ttfamily \label{class_relais_module_v1__0_a2256db6eb1b2430fc9fbb82ad05152dd} 
String Relais\+Module\+V1\+\_\+0\+::get\+HWVersion (\begin{DoxyParamCaption}{}{}\end{DoxyParamCaption}) const\hspace{0.3cm}{\ttfamily [inline]}, {\ttfamily [override]}, {\ttfamily [virtual]}}

Get the hardware version string. 

Returns the hardware revision/version string for the module. \begin{DoxyReturn}{Returns}
String Hardware version (e.\+g. "{}1.\+0"{}). 
\end{DoxyReturn}

Implements \mbox{\hyperlink{class_c_a_n_tram_module_a5d9287df902bd2f9ec32b4317f95fff6}{CANTram\+Module}}.

\Hypertarget{class_relais_module_v1__0_ae437de38ae5e1caa91ea6d6fca5b7519}\index{RelaisModuleV1\_0@{RelaisModuleV1\_0}!getInterfaceCount@{getInterfaceCount}}
\index{getInterfaceCount@{getInterfaceCount}!RelaisModuleV1\_0@{RelaisModuleV1\_0}}
\doxysubsubsection{\texorpdfstring{getInterfaceCount()}{getInterfaceCount()}}
{\footnotesize\ttfamily \label{class_relais_module_v1__0_ae437de38ae5e1caa91ea6d6fca5b7519} 
size\+\_\+t Relais\+Module\+V1\+\_\+0\+::get\+Interface\+Count (\begin{DoxyParamCaption}{}{}\end{DoxyParamCaption})\hspace{0.3cm}{\ttfamily [inline]}, {\ttfamily [override]}, {\ttfamily [virtual]}}

Get number of interfaces provided by the module. 

Return the number of entries in the interfaces array returned by \doxylink{class_relais_module_v1__0_a78579ed4ffa12aa6978e2c319632cbef}{get\+Interfaces()}. \begin{DoxyReturn}{Returns}
size\+\_\+t Number of interface pointers. 
\end{DoxyReturn}

Implements \mbox{\hyperlink{class_c_a_n_tram_module_a68c703147d8b495e324febcaccd49dea}{CANTram\+Module}}.

\Hypertarget{class_relais_module_v1__0_a78579ed4ffa12aa6978e2c319632cbef}\index{RelaisModuleV1\_0@{RelaisModuleV1\_0}!getInterfaces@{getInterfaces}}
\index{getInterfaces@{getInterfaces}!RelaisModuleV1\_0@{RelaisModuleV1\_0}}
\doxysubsubsection{\texorpdfstring{getInterfaces()}{getInterfaces()}}
{\footnotesize\ttfamily \label{class_relais_module_v1__0_a78579ed4ffa12aa6978e2c319632cbef} 
\mbox{\hyperlink{class_interface}{Interface}} \texorpdfstring{$\ast$}{*}\texorpdfstring{$\ast$}{*} Relais\+Module\+V1\+\_\+0\+::get\+Interfaces (\begin{DoxyParamCaption}{}{}\end{DoxyParamCaption})\hspace{0.3cm}{\ttfamily [override]}, {\ttfamily [virtual]}}

Get pointer to module\textquotesingle{}s interface array. 

Returns a pointer to the internal Interface\texorpdfstring{$\ast$}{*} array used by the core to enumerate interfaces. \begin{DoxyReturn}{Returns}
Interface\texorpdfstring{$\ast$}{*}\texorpdfstring{$\ast$}{*} Pointer to the first element of the module\textquotesingle{}s interfaces array. 
\end{DoxyReturn}

Implements \mbox{\hyperlink{class_c_a_n_tram_module_a09c919fc31111badfec18faf64c729f4}{CANTram\+Module}}.

\Hypertarget{class_relais_module_v1__0_aee1e17f77ccc4737865e34291e86c103}\index{RelaisModuleV1\_0@{RelaisModuleV1\_0}!initialize@{initialize}}
\index{initialize@{initialize}!RelaisModuleV1\_0@{RelaisModuleV1\_0}}
\doxysubsubsection{\texorpdfstring{initialize()}{initialize()}}
{\footnotesize\ttfamily \label{class_relais_module_v1__0_aee1e17f77ccc4737865e34291e86c103} 
bool Relais\+Module\+V1\+\_\+0\+::initialize (\begin{DoxyParamCaption}{}{}\end{DoxyParamCaption})\hspace{0.3cm}{\ttfamily [override]}, {\ttfamily [virtual]}}

Initialize the module after attachment and provisioning. 

Perform runtime initialization (start drivers, begin peripherals) once all modules have been attached. \begin{DoxyReturn}{Returns}
true if initialization succeeded, false otherwise. 
\end{DoxyReturn}

Implements \mbox{\hyperlink{class_c_a_n_tram_module_a6930dfb86a2e06ab9a9b299520830fb7}{CANTram\+Module}}.

\Hypertarget{class_relais_module_v1__0_a6373363c88ca982860ec7f07f81005cb}\index{RelaisModuleV1\_0@{RelaisModuleV1\_0}!provideGPIOs@{provideGPIOs}}
\index{provideGPIOs@{provideGPIOs}!RelaisModuleV1\_0@{RelaisModuleV1\_0}}
\doxysubsubsection{\texorpdfstring{provideGPIOs()}{provideGPIOs()}}
{\footnotesize\ttfamily \label{class_relais_module_v1__0_a6373363c88ca982860ec7f07f81005cb} 
bool Relais\+Module\+V1\+\_\+0\+::provide\+GPIOs (\begin{DoxyParamCaption}{}{}\end{DoxyParamCaption})\hspace{0.3cm}{\ttfamily [override]}, {\ttfamily [virtual]}}

Provide GPIO definitions to the core. 

Called during module attachment to allow the module to declare any GPIOs it owns or provides. \begin{DoxyReturn}{Returns}
true if GPIO definitions were provided successfully, false otherwise. 
\end{DoxyReturn}

Implements \mbox{\hyperlink{class_c_a_n_tram_module_abaad4d92c02fc8bb525a57d8ac06db7e}{CANTram\+Module}}.

\Hypertarget{class_relais_module_v1__0_ac9c120d926b21c489108c1f925f2abac}\index{RelaisModuleV1\_0@{RelaisModuleV1\_0}!provideHardwareResources@{provideHardwareResources}}
\index{provideHardwareResources@{provideHardwareResources}!RelaisModuleV1\_0@{RelaisModuleV1\_0}}
\doxysubsubsection{\texorpdfstring{provideHardwareResources()}{provideHardwareResources()}}
{\footnotesize\ttfamily \label{class_relais_module_v1__0_ac9c120d926b21c489108c1f925f2abac} 
bool Relais\+Module\+V1\+\_\+0\+::provide\+Hardware\+Resources (\begin{DoxyParamCaption}{}{}\end{DoxyParamCaption})\hspace{0.3cm}{\ttfamily [override]}, {\ttfamily [virtual]}}

Provide hardware resources (e.\+g., I2C, SPI, UART) to the core. 

Called during attachment to attach \doxylink{class_hardware_resource}{Hardware\+Resource} instances that other modules can request. \begin{DoxyReturn}{Returns}
true if resources were successfully provided, false otherwise. 
\end{DoxyReturn}

Implements \mbox{\hyperlink{class_c_a_n_tram_module_aa509ae950722ebd48383c124ec6a63ec}{CANTram\+Module}}.

\Hypertarget{class_relais_module_v1__0_af2e4f33d631bc14e433c404678347b67}\index{RelaisModuleV1\_0@{RelaisModuleV1\_0}!requestGPIOs@{requestGPIOs}}
\index{requestGPIOs@{requestGPIOs}!RelaisModuleV1\_0@{RelaisModuleV1\_0}}
\doxysubsubsection{\texorpdfstring{requestGPIOs()}{requestGPIOs()}}
{\footnotesize\ttfamily \label{class_relais_module_v1__0_af2e4f33d631bc14e433c404678347b67} 
bool Relais\+Module\+V1\+\_\+0\+::request\+GPIOs (\begin{DoxyParamCaption}{}{}\end{DoxyParamCaption})\hspace{0.3cm}{\ttfamily [override]}, {\ttfamily [virtual]}}

Request GPIO definitions from the core. 

Called after provide\+GPIOs to obtain runtime GPIO assignments from \doxylink{class_c_a_n_tram_core}{CANTram\+Core}. \begin{DoxyReturn}{Returns}
true if required GPIOs were acquired and validated, false otherwise. 
\end{DoxyReturn}

Implements \mbox{\hyperlink{class_c_a_n_tram_module_a7f2c1c05cafb19676aed58c11219d0f5}{CANTram\+Module}}.

Here is the call graph for this function\+:
\nopagebreak
\begin{figure}[H]
\begin{center}
\leavevmode

\end{center}
\end{figure}
\Hypertarget{class_relais_module_v1__0_abb33be265117a963c1ab9c34e34ea082}\index{RelaisModuleV1\_0@{RelaisModuleV1\_0}!requestHardwareResources@{requestHardwareResources}}
\index{requestHardwareResources@{requestHardwareResources}!RelaisModuleV1\_0@{RelaisModuleV1\_0}}
\doxysubsubsection{\texorpdfstring{requestHardwareResources()}{requestHardwareResources()}}
{\footnotesize\ttfamily \label{class_relais_module_v1__0_abb33be265117a963c1ab9c34e34ea082} 
bool Relais\+Module\+V1\+\_\+0\+::request\+Hardware\+Resources (\begin{DoxyParamCaption}{}{}\end{DoxyParamCaption})\hspace{0.3cm}{\ttfamily [override]}, {\ttfamily [virtual]}}

Request hardware resources from the core. 

Called when the module should acquire hardware resources supplied by the system (e.\+g., UART core). \begin{DoxyReturn}{Returns}
true if all required hardware resources were granted, false otherwise. 
\end{DoxyReturn}

Implements \mbox{\hyperlink{class_c_a_n_tram_module_a88dd0ab2213df828b576d337e38c1ac8}{CANTram\+Module}}.

The documentation for this class was generated from the following files\+:\begin{DoxyCompactItemize}
\item 
C\+:/\+Users/leowa/\+Documents/\+Platform\+IO/\+Projects/\+CANTram\+Framework\+Usage/lib/\+CANTram\+Framework/include/Relais\+Module\+V1\+\_\+0.\+h\item 
C\+:/\+Users/leowa/\+Documents/\+Platform\+IO/\+Projects/\+CANTram\+Framework\+Usage/lib/\+CANTram\+Framework/src/modules/Relais\+Module\+V1\+\_\+0.\+cpp\end{DoxyCompactItemize}

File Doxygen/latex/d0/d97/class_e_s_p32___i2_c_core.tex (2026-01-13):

\doxysection{ESP32\+\_\+\+I2\+CCore Class Reference}
\hypertarget{class_e_s_p32___i2_c_core}{}\label{class_e_s_p32___i2_c_core}\index{ESP32\_I2CCore@{ESP32\_I2CCore}}

Inheritance diagram for ESP32\+\_\+\+I2\+CCore\+:
\nopagebreak
\begin{figure}[H]
\begin{center}
\leavevmode
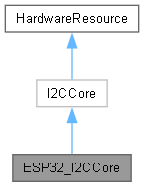
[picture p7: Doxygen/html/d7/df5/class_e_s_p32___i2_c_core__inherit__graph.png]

\end{center}
\end{figure}

Collaboration diagram for ESP32\+\_\+\+I2\+CCore\+:
\nopagebreak
\begin{figure}[H]
\begin{center}
\leavevmode

\end{center}
\end{figure}
\doxysubsubsection*{Public Member Functions}
\begin{DoxyCompactItemize}
\item 
\Hypertarget{class_e_s_p32___i2_c_core_a96c8d7104bc337f5b4cbe957398c7b7f}\label{class_e_s_p32___i2_c_core_a96c8d7104bc337f5b4cbe957398c7b7f} 
{\bfseries ESP32\+\_\+\+I2\+CCore} (uint8\+\_\+t i2c\+\_\+num)
\item 
bool \mbox{\hyperlink{class_e_s_p32___i2_c_core_aa3e0817cba1f01e19e046fa27a776eab}{reset}} () override
\begin{DoxyCompactList}\small\item\em Reset the hardware resource to a known default state. \end{DoxyCompactList}\item 
bool \mbox{\hyperlink{class_e_s_p32___i2_c_core_a816990aa348a4a474c4261199e1a50b9}{begin}} () override
\item 
void \mbox{\hyperlink{class_e_s_p32___i2_c_core_ace5884b298ff52f57bb8108da5c24a83}{begin\+Transmission}} (uint8\+\_\+t address) override
\item 
uint8\+\_\+t \mbox{\hyperlink{class_e_s_p32___i2_c_core_a264b8080518f4ab2c2712c84b15cb2ca}{end\+Transmission}} () override
\item 
size\+\_\+t \mbox{\hyperlink{class_e_s_p32___i2_c_core_abad680001989bb85c128c18ac2864226}{write}} (uint8\+\_\+t data) override
\item 
size\+\_\+t \mbox{\hyperlink{class_e_s_p32___i2_c_core_a56601ccf2dfbf04bfea732889c58878c}{write}} (const uint8\+\_\+t \texorpdfstring{$\ast$}{*}data, size\+\_\+t quantity) override
\item 
size\+\_\+t \mbox{\hyperlink{class_e_s_p32___i2_c_core_a6e03957c38253cc768f44c06169b4443}{request\+From}} (uint8\+\_\+t address, size\+\_\+t len, bool stop\+Bit) override
\item 
int \mbox{\hyperlink{class_e_s_p32___i2_c_core_a31118e49dc19f4d7163340fe21a5066f}{available}} () override
\item 
int \mbox{\hyperlink{class_e_s_p32___i2_c_core_ae64e17fbb9f75f8b748899c549ad325a}{read}} () override
\item 
int \mbox{\hyperlink{class_e_s_p32___i2_c_core_a8e382b13e30ef064473112dc1e4ed4db}{peek}} () override
\item 
void \mbox{\hyperlink{class_e_s_p32___i2_c_core_a83eb634357adb2e099d12eea0cee97c0}{flush}} () override
\item 
\Hypertarget{class_e_s_p32___i2_c_core_a361ae2c63eea47cdf03a825055740d6a}\label{class_e_s_p32___i2_c_core_a361ae2c63eea47cdf03a825055740d6a} 
Two\+Wire \& {\bfseries get\+Wire\+Instance} ()
\end{DoxyCompactItemize}
\doxysubsection*{Public Member Functions inherited from \mbox{\hyperlink{class_i2_c_core}{I2\+CCore}}}
\begin{DoxyCompactItemize}
\item 
virtual \mbox{\hyperlink{class_hardware_resource_adead6978be3d7b86c18e3d3e051381e6}{Hardware\+Resource\+::\+Type}} \mbox{\hyperlink{class_i2_c_core_a092566ca5aacc4421559e29f6ff12da5}{get\+Type}} () override
\begin{DoxyCompactList}\small\item\em Get the hardware resource type. \end{DoxyCompactList}\item 
virtual void {\bfseries set\+Pins} (int8\+\_\+t sda\+Pin, int8\+\_\+t scl\+Pin)
\item 
virtual void {\bfseries set\+Buffer\+Size} (uint32\+\_\+t buffer\+Size)
\item 
virtual void {\bfseries set\+I2\+CNum} (int8\+\_\+t i2c\+\_\+num)
\item 
virtual void {\bfseries set\+Frequency} (uint32\+\_\+t frequency)
\item 
virtual uint32\+\_\+t {\bfseries set\+Max\+Frequency} (uint32\+\_\+t frequency)
\item 
virtual uint8\+\_\+t \mbox{\hyperlink{class_i2_c_core_a4000d56ed283e62c7d50a4083e4762b6}{get\+Max\+Usages}} () override
\begin{DoxyCompactList}\small\item\em Get the maximum simultaneous usages allowed for this resource. \end{DoxyCompactList}\item 
virtual I2\+CStatus {\bfseries get\+I2\+CStatus} () const
\end{DoxyCompactItemize}
\doxysubsection*{Public Member Functions inherited from \mbox{\hyperlink{class_hardware_resource}{Hardware\+Resource}}}
\begin{DoxyCompactItemize}
\item 
bool \mbox{\hyperlink{class_hardware_resource_a26f48b38e5bb1d9bdd47ea2e6de87fdb}{request\+Usage}} ()
\begin{DoxyCompactList}\small\item\em Request a usage slot for this resource. \end{DoxyCompactList}\item 
uint8\+\_\+t \mbox{\hyperlink{class_hardware_resource_a07205354c25627a3bb10ad417e335ff9}{get\+Usages}} ()
\begin{DoxyCompactList}\small\item\em Get the current number of usages of this resource. \end{DoxyCompactList}\item 
bool \mbox{\hyperlink{class_hardware_resource_a569821aa9a34d96ed143488a72e6872b}{is\+Used}} ()
\begin{DoxyCompactList}\small\item\em Check if the resource is currently used. \end{DoxyCompactList}\item 
virtual uint8\+\_\+t \mbox{\hyperlink{class_hardware_resource_a470679cae7880c9ca436755a50f68db4}{get\+Remaining\+Usages}} ()
\begin{DoxyCompactList}\small\item\em Get remaining usage capacity for this resource. \end{DoxyCompactList}\end{DoxyCompactItemize}
\doxysubsubsection*{Static Public Attributes}
\begin{DoxyCompactItemize}
\item 
\Hypertarget{class_e_s_p32___i2_c_core_a8aa7b11adb96569ce136de2c81ea02e9}\label{class_e_s_p32___i2_c_core_a8aa7b11adb96569ce136de2c81ea02e9} 
static constexpr uint8\+\_\+t {\bfseries ESP\+\_\+\+I2\+C\+\_\+\+NUM\+\_\+0} = 0
\item 
\Hypertarget{class_e_s_p32___i2_c_core_a2b91c8daef64c2442dfeaa119f5e963c}\label{class_e_s_p32___i2_c_core_a2b91c8daef64c2442dfeaa119f5e963c} 
static constexpr uint8\+\_\+t {\bfseries ESP\+\_\+\+I2\+C\+\_\+\+NUM\+\_\+1} = 1
\end{DoxyCompactItemize}
\doxysubsection*{Static Public Attributes inherited from \mbox{\hyperlink{class_i2_c_core}{I2\+CCore}}}
\begin{DoxyCompactItemize}
\item 
static constexpr uint32\+\_\+t {\bfseries I2\+C\+\_\+\+DEFAULT\+\_\+\+FREQUENCY} = 1700000
\end{DoxyCompactItemize}
\doxysubsubsection*{Additional Inherited Members}
\doxysubsection*{Public Types inherited from \mbox{\hyperlink{class_i2_c_core}{I2\+CCore}}}
\begin{DoxyCompactItemize}
\item 
\Hypertarget{class_i2_c_core_a56df9b00a465a753a62e5cca8a70c100}\label{class_i2_c_core_a56df9b00a465a753a62e5cca8a70c100} 
enum {\bfseries I2\+CStatus} \{ {\bfseries I2\+C\+\_\+\+NOT\+\_\+\+STARTED} =0
, {\bfseries I2\+C\+\_\+\+STARTED} =1
 \}
\end{DoxyCompactItemize}
\doxysubsection*{Public Types inherited from \mbox{\hyperlink{class_hardware_resource}{Hardware\+Resource}}}
\begin{DoxyCompactItemize}
\item 
enum \mbox{\hyperlink{class_hardware_resource_adead6978be3d7b86c18e3d3e051381e6}{Type}} \{ \newline
\mbox{\hyperlink{class_hardware_resource_adead6978be3d7b86c18e3d3e051381e6ac6f39e4a2dbc764df53048f26209f0a1}{UART}}
, \mbox{\hyperlink{class_hardware_resource_adead6978be3d7b86c18e3d3e051381e6a63a2eead0d2771007afa8c8af281c50d}{SPI}}
, \mbox{\hyperlink{class_hardware_resource_adead6978be3d7b86c18e3d3e051381e6ac77292ec986f613995babba396598dbc}{I2C}}
, \mbox{\hyperlink{class_hardware_resource_adead6978be3d7b86c18e3d3e051381e6ac2fe3e8cc9a9a8fcb39c32be2da214c5}{PWM}}
, \newline
\mbox{\hyperlink{class_hardware_resource_adead6978be3d7b86c18e3d3e051381e6a0ae946256af51077cacc3c0a11575635}{CAN}}
 \}
\begin{DoxyCompactList}\small\item\em Enumeration of hardware resource types. \end{DoxyCompactList}\end{DoxyCompactItemize}
\doxysubsection*{Protected Member Functions inherited from \mbox{\hyperlink{class_hardware_resource}{Hardware\+Resource}}}
\begin{DoxyCompactItemize}
\item 
\mbox{\hyperlink{class_hardware_resource_a7ddffb890a743f2df28128d9afd5bfa5}{Hardware\+Resource}} ()=default
\begin{DoxyCompactList}\small\item\em Default constructor. \end{DoxyCompactList}\end{DoxyCompactItemize}
\doxysubsection*{Protected Attributes inherited from \mbox{\hyperlink{class_i2_c_core}{I2\+CCore}}}
\begin{DoxyCompactItemize}
\item 
int8\+\_\+t {\bfseries \+\_\+sda\+Pin} =-\/1
\item 
int8\+\_\+t {\bfseries \+\_\+scl\+Pin} =-\/1
\item 
uint32\+\_\+t {\bfseries \+\_\+frequency} = I2\+C\+\_\+\+DEFAULT\+\_\+\+FREQUENCY
\item 
int8\+\_\+t {\bfseries \+\_\+i2c\+\_\+num} =-\/1
\item 
uint32\+\_\+t {\bfseries \+\_\+buffer\+Size} = I2\+C\+\_\+\+DEFAULT\+\_\+\+BUFFER\+\_\+\+LENGTH
\item 
I2\+CStatus {\bfseries \+\_\+i2c\+Status} = I2\+C\+\_\+\+NOT\+\_\+\+STARTED
\end{DoxyCompactItemize}
\doxysubsection*{Protected Attributes inherited from \mbox{\hyperlink{class_hardware_resource}{Hardware\+Resource}}}
\begin{DoxyCompactItemize}
\item 
uint8\+\_\+t \mbox{\hyperlink{class_hardware_resource_a78845b363f906c0383e91ea912bbddbc}{usages}} =0
\begin{DoxyCompactList}\small\item\em Current usage counter. \end{DoxyCompactList}\end{DoxyCompactItemize}
\doxysubsection*{Static Protected Attributes inherited from \mbox{\hyperlink{class_i2_c_core}{I2\+CCore}}}
\begin{DoxyCompactItemize}
\item 
static constexpr uint16\+\_\+t {\bfseries I2\+C\+\_\+\+DEFAULT\+\_\+\+BUFFER\+\_\+\+LENGTH} = 32
\end{DoxyCompactItemize}

\label{doc-func-members}
\Hypertarget{class_e_s_p32___i2_c_core_doc-func-members}
\doxysubsection{Member Function Documentation}
\Hypertarget{class_e_s_p32___i2_c_core_a31118e49dc19f4d7163340fe21a5066f}\index{ESP32\_I2CCore@{ESP32\_I2CCore}!available@{available}}
\index{available@{available}!ESP32\_I2CCore@{ESP32\_I2CCore}}
\doxysubsubsection{\texorpdfstring{available()}{available()}}
{\footnotesize\ttfamily \label{class_e_s_p32___i2_c_core_a31118e49dc19f4d7163340fe21a5066f} 
int ESP32\+\_\+\+I2\+CCore\+::available (\begin{DoxyParamCaption}{}{}\end{DoxyParamCaption})\hspace{0.3cm}{\ttfamily [inline]}, {\ttfamily [override]}, {\ttfamily [virtual]}}

Implements \mbox{\hyperlink{class_i2_c_core}{I2\+CCore}}.

\Hypertarget{class_e_s_p32___i2_c_core_a816990aa348a4a474c4261199e1a50b9}\index{ESP32\_I2CCore@{ESP32\_I2CCore}!begin@{begin}}
\index{begin@{begin}!ESP32\_I2CCore@{ESP32\_I2CCore}}
\doxysubsubsection{\texorpdfstring{begin()}{begin()}}
{\footnotesize\ttfamily \label{class_e_s_p32___i2_c_core_a816990aa348a4a474c4261199e1a50b9} 
bool ESP32\+\_\+\+I2\+CCore\+::begin (\begin{DoxyParamCaption}{}{}\end{DoxyParamCaption})\hspace{0.3cm}{\ttfamily [override]}, {\ttfamily [virtual]}}

Implements \mbox{\hyperlink{class_i2_c_core}{I2\+CCore}}.

\Hypertarget{class_e_s_p32___i2_c_core_ace5884b298ff52f57bb8108da5c24a83}\index{ESP32\_I2CCore@{ESP32\_I2CCore}!beginTransmission@{beginTransmission}}
\index{beginTransmission@{beginTransmission}!ESP32\_I2CCore@{ESP32\_I2CCore}}
\doxysubsubsection{\texorpdfstring{beginTransmission()}{beginTransmission()}}
{\footnotesize\ttfamily \label{class_e_s_p32___i2_c_core_ace5884b298ff52f57bb8108da5c24a83} 
void ESP32\+\_\+\+I2\+CCore\+::begin\+Transmission (\begin{DoxyParamCaption}\item[{uint8\+\_\+t}]{address}{}\end{DoxyParamCaption})\hspace{0.3cm}{\ttfamily [inline]}, {\ttfamily [override]}, {\ttfamily [virtual]}}

Implements \mbox{\hyperlink{class_i2_c_core}{I2\+CCore}}.

\Hypertarget{class_e_s_p32___i2_c_core_a264b8080518f4ab2c2712c84b15cb2ca}\index{ESP32\_I2CCore@{ESP32\_I2CCore}!endTransmission@{endTransmission}}
\index{endTransmission@{endTransmission}!ESP32\_I2CCore@{ESP32\_I2CCore}}
\doxysubsubsection{\texorpdfstring{endTransmission()}{endTransmission()}}
{\footnotesize\ttfamily \label{class_e_s_p32___i2_c_core_a264b8080518f4ab2c2712c84b15cb2ca} 
uint8\+\_\+t ESP32\+\_\+\+I2\+CCore\+::end\+Transmission (\begin{DoxyParamCaption}{}{}\end{DoxyParamCaption})\hspace{0.3cm}{\ttfamily [inline]}, {\ttfamily [override]}, {\ttfamily [virtual]}}

Implements \mbox{\hyperlink{class_i2_c_core}{I2\+CCore}}.

\Hypertarget{class_e_s_p32___i2_c_core_a83eb634357adb2e099d12eea0cee97c0}\index{ESP32\_I2CCore@{ESP32\_I2CCore}!flush@{flush}}
\index{flush@{flush}!ESP32\_I2CCore@{ESP32\_I2CCore}}
\doxysubsubsection{\texorpdfstring{flush()}{flush()}}
{\footnotesize\ttfamily \label{class_e_s_p32___i2_c_core_a83eb634357adb2e099d12eea0cee97c0} 
void ESP32\+\_\+\+I2\+CCore\+::flush (\begin{DoxyParamCaption}{}{}\end{DoxyParamCaption})\hspace{0.3cm}{\ttfamily [inline]}, {\ttfamily [override]}, {\ttfamily [virtual]}}

Implements \mbox{\hyperlink{class_i2_c_core}{I2\+CCore}}.

\Hypertarget{class_e_s_p32___i2_c_core_a8e382b13e30ef064473112dc1e4ed4db}\index{ESP32\_I2CCore@{ESP32\_I2CCore}!peek@{peek}}
\index{peek@{peek}!ESP32\_I2CCore@{ESP32\_I2CCore}}
\doxysubsubsection{\texorpdfstring{peek()}{peek()}}
{\footnotesize\ttfamily \label{class_e_s_p32___i2_c_core_a8e382b13e30ef064473112dc1e4ed4db} 
int ESP32\+\_\+\+I2\+CCore\+::peek (\begin{DoxyParamCaption}{}{}\end{DoxyParamCaption})\hspace{0.3cm}{\ttfamily [inline]}, {\ttfamily [override]}, {\ttfamily [virtual]}}

Reimplemented from \mbox{\hyperlink{class_i2_c_core}{I2\+CCore}}.

\Hypertarget{class_e_s_p32___i2_c_core_ae64e17fbb9f75f8b748899c549ad325a}\index{ESP32\_I2CCore@{ESP32\_I2CCore}!read@{read}}
\index{read@{read}!ESP32\_I2CCore@{ESP32\_I2CCore}}
\doxysubsubsection{\texorpdfstring{read()}{read()}}
{\footnotesize\ttfamily \label{class_e_s_p32___i2_c_core_ae64e17fbb9f75f8b748899c549ad325a} 
int ESP32\+\_\+\+I2\+CCore\+::read (\begin{DoxyParamCaption}{}{}\end{DoxyParamCaption})\hspace{0.3cm}{\ttfamily [inline]}, {\ttfamily [override]}, {\ttfamily [virtual]}}

Implements \mbox{\hyperlink{class_i2_c_core}{I2\+CCore}}.

\Hypertarget{class_e_s_p32___i2_c_core_a6e03957c38253cc768f44c06169b4443}\index{ESP32\_I2CCore@{ESP32\_I2CCore}!requestFrom@{requestFrom}}
\index{requestFrom@{requestFrom}!ESP32\_I2CCore@{ESP32\_I2CCore}}
\doxysubsubsection{\texorpdfstring{requestFrom()}{requestFrom()}}
{\footnotesize\ttfamily \label{class_e_s_p32___i2_c_core_a6e03957c38253cc768f44c06169b4443} 
size\+\_\+t ESP32\+\_\+\+I2\+CCore\+::request\+From (\begin{DoxyParamCaption}\item[{uint8\+\_\+t}]{address}{, }\item[{size\+\_\+t}]{len}{, }\item[{bool}]{stop\+Bit}{}\end{DoxyParamCaption})\hspace{0.3cm}{\ttfamily [inline]}, {\ttfamily [override]}, {\ttfamily [virtual]}}

Implements \mbox{\hyperlink{class_i2_c_core}{I2\+CCore}}.

\Hypertarget{class_e_s_p32___i2_c_core_aa3e0817cba1f01e19e046fa27a776eab}\index{ESP32\_I2CCore@{ESP32\_I2CCore}!reset@{reset}}
\index{reset@{reset}!ESP32\_I2CCore@{ESP32\_I2CCore}}
\doxysubsubsection{\texorpdfstring{reset()}{reset()}}
{\footnotesize\ttfamily \label{class_e_s_p32___i2_c_core_aa3e0817cba1f01e19e046fa27a776eab} 
bool ESP32\+\_\+\+I2\+CCore\+::reset (\begin{DoxyParamCaption}{}{}\end{DoxyParamCaption})\hspace{0.3cm}{\ttfamily [override]}, {\ttfamily [virtual]}}

Reset the hardware resource to a known default state. 

Default implementation clears the usage counter and logs the reset. Derived classes should call the base implementation and perform any additional hardware-\/specific reset steps. \begin{DoxyReturn}{Returns}
true if the reset succeeded, false otherwise. 
\end{DoxyReturn}

Reimplemented from \mbox{\hyperlink{class_i2_c_core_a0c8934608811f1a80247981f4e222ce9}{I2\+CCore}}.

Here is the call graph for this function\+:
\nopagebreak
\begin{figure}[H]
\begin{center}
\leavevmode

\end{center}
\end{figure}
\Hypertarget{class_e_s_p32___i2_c_core_a56601ccf2dfbf04bfea732889c58878c}\index{ESP32\_I2CCore@{ESP32\_I2CCore}!write@{write}}
\index{write@{write}!ESP32\_I2CCore@{ESP32\_I2CCore}}
\doxysubsubsection{\texorpdfstring{write()}{write()}\hspace{0.1cm}{\footnotesize\ttfamily [1/2]}}
{\footnotesize\ttfamily \label{class_e_s_p32___i2_c_core_a56601ccf2dfbf04bfea732889c58878c} 
size\+\_\+t ESP32\+\_\+\+I2\+CCore\+::write (\begin{DoxyParamCaption}\item[{const uint8\+\_\+t \texorpdfstring{$\ast$}{*}}]{data}{, }\item[{size\+\_\+t}]{quantity}{}\end{DoxyParamCaption})\hspace{0.3cm}{\ttfamily [inline]}, {\ttfamily [override]}, {\ttfamily [virtual]}}

Implements \mbox{\hyperlink{class_i2_c_core}{I2\+CCore}}.

\Hypertarget{class_e_s_p32___i2_c_core_abad680001989bb85c128c18ac2864226}\index{ESP32\_I2CCore@{ESP32\_I2CCore}!write@{write}}
\index{write@{write}!ESP32\_I2CCore@{ESP32\_I2CCore}}
\doxysubsubsection{\texorpdfstring{write()}{write()}\hspace{0.1cm}{\footnotesize\ttfamily [2/2]}}
{\footnotesize\ttfamily \label{class_e_s_p32___i2_c_core_abad680001989bb85c128c18ac2864226} 
size\+\_\+t ESP32\+\_\+\+I2\+CCore\+::write (\begin{DoxyParamCaption}\item[{uint8\+\_\+t}]{data}{}\end{DoxyParamCaption})\hspace{0.3cm}{\ttfamily [inline]}, {\ttfamily [override]}, {\ttfamily [virtual]}}

Implements \mbox{\hyperlink{class_i2_c_core}{I2\+CCore}}.

The documentation for this class was generated from the following files\+:\begin{DoxyCompactItemize}
\item 
C\+:/\+Users/leowa/\+Documents/\+Platform\+IO/\+Projects/\+CANTram\+Framework\+Usage/lib/\+CANTram\+Framework/include/ESP32\+\_\+\+I2\+CCore.\+h\item 
C\+:/\+Users/leowa/\+Documents/\+Platform\+IO/\+Projects/\+CANTram\+Framework\+Usage/lib/\+CANTram\+Framework/src/hardware/ESP32\+\_\+\+I2\+CCore.\+cpp\end{DoxyCompactItemize}

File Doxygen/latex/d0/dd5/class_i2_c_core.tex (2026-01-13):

\doxysection{I2\+CCore Class Reference}
\hypertarget{class_i2_c_core}{}\label{class_i2_c_core}\index{I2CCore@{I2CCore}}

Inheritance diagram for I2\+CCore\+:
\nopagebreak
\begin{figure}[H]
\begin{center}
\leavevmode
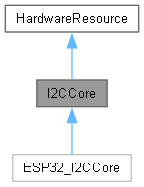
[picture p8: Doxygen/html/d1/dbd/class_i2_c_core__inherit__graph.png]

\end{center}
\end{figure}

Collaboration diagram for I2\+CCore\+:
\nopagebreak
\begin{figure}[H]
\begin{center}
\leavevmode

\end{center}
\end{figure}
\doxysubsubsection*{Public Types}
\begin{DoxyCompactItemize}
\item 
\Hypertarget{class_i2_c_core_a56df9b00a465a753a62e5cca8a70c100}\label{class_i2_c_core_a56df9b00a465a753a62e5cca8a70c100} 
enum {\bfseries I2\+CStatus} \{ {\bfseries I2\+C\+\_\+\+NOT\+\_\+\+STARTED} =0
, {\bfseries I2\+C\+\_\+\+STARTED} =1
 \}
\end{DoxyCompactItemize}
\doxysubsection*{Public Types inherited from \mbox{\hyperlink{class_hardware_resource}{Hardware\+Resource}}}
\begin{DoxyCompactItemize}
\item 
enum \mbox{\hyperlink{class_hardware_resource_adead6978be3d7b86c18e3d3e051381e6}{Type}} \{ \newline
\mbox{\hyperlink{class_hardware_resource_adead6978be3d7b86c18e3d3e051381e6ac6f39e4a2dbc764df53048f26209f0a1}{UART}}
, \mbox{\hyperlink{class_hardware_resource_adead6978be3d7b86c18e3d3e051381e6a63a2eead0d2771007afa8c8af281c50d}{SPI}}
, \mbox{\hyperlink{class_hardware_resource_adead6978be3d7b86c18e3d3e051381e6ac77292ec986f613995babba396598dbc}{I2C}}
, \mbox{\hyperlink{class_hardware_resource_adead6978be3d7b86c18e3d3e051381e6ac2fe3e8cc9a9a8fcb39c32be2da214c5}{PWM}}
, \newline
\mbox{\hyperlink{class_hardware_resource_adead6978be3d7b86c18e3d3e051381e6a0ae946256af51077cacc3c0a11575635}{CAN}}
 \}
\begin{DoxyCompactList}\small\item\em Enumeration of hardware resource types. \end{DoxyCompactList}\end{DoxyCompactItemize}
\doxysubsubsection*{Public Member Functions}
\begin{DoxyCompactItemize}
\item 
virtual bool \mbox{\hyperlink{class_i2_c_core_a0c8934608811f1a80247981f4e222ce9}{reset}} ()
\begin{DoxyCompactList}\small\item\em Reset the hardware resource to a known default state. \end{DoxyCompactList}\item 
\Hypertarget{class_i2_c_core_afa31d5d99e788952f70c83210e2fbd0c}\label{class_i2_c_core_afa31d5d99e788952f70c83210e2fbd0c} 
virtual bool {\bfseries begin} ()=0
\item 
virtual \mbox{\hyperlink{class_hardware_resource_adead6978be3d7b86c18e3d3e051381e6}{Hardware\+Resource\+::\+Type}} \mbox{\hyperlink{class_i2_c_core_a092566ca5aacc4421559e29f6ff12da5}{get\+Type}} () override
\begin{DoxyCompactList}\small\item\em Get the hardware resource type. \end{DoxyCompactList}\item 
\Hypertarget{class_i2_c_core_a89a7270104517c21a193023564c7566f}\label{class_i2_c_core_a89a7270104517c21a193023564c7566f} 
virtual void {\bfseries set\+Pins} (int8\+\_\+t sda\+Pin, int8\+\_\+t scl\+Pin)
\item 
\Hypertarget{class_i2_c_core_ae3c93a5c6dc5759ad4353ece2a072e91}\label{class_i2_c_core_ae3c93a5c6dc5759ad4353ece2a072e91} 
virtual void {\bfseries set\+Buffer\+Size} (uint32\+\_\+t buffer\+Size)
\item 
\Hypertarget{class_i2_c_core_aa7e192891a7b5470765700563f597375}\label{class_i2_c_core_aa7e192891a7b5470765700563f597375} 
virtual void {\bfseries set\+I2\+CNum} (int8\+\_\+t i2c\+\_\+num)
\item 
\Hypertarget{class_i2_c_core_a77c901f94b6943f5c57e66e3a239633d}\label{class_i2_c_core_a77c901f94b6943f5c57e66e3a239633d} 
virtual void {\bfseries set\+Frequency} (uint32\+\_\+t frequency)
\item 
\Hypertarget{class_i2_c_core_a75e8b9d512769fe3058db23fcd7cdf03}\label{class_i2_c_core_a75e8b9d512769fe3058db23fcd7cdf03} 
virtual uint32\+\_\+t {\bfseries set\+Max\+Frequency} (uint32\+\_\+t frequency)
\item 
\Hypertarget{class_i2_c_core_ae9454e6d255aa7cb2b50706d73eb53dc}\label{class_i2_c_core_ae9454e6d255aa7cb2b50706d73eb53dc} 
virtual void {\bfseries begin\+Transmission} (uint8\+\_\+t address)=0
\item 
\Hypertarget{class_i2_c_core_a0ded24841d8ddec869777010d3e86f65}\label{class_i2_c_core_a0ded24841d8ddec869777010d3e86f65} 
virtual uint8\+\_\+t {\bfseries end\+Transmission} ()=0
\item 
\Hypertarget{class_i2_c_core_a384258d1da79a501b572ee72606809c6}\label{class_i2_c_core_a384258d1da79a501b572ee72606809c6} 
virtual size\+\_\+t {\bfseries write} (uint8\+\_\+t data)=0
\item 
\Hypertarget{class_i2_c_core_a847fa558d755693f0051b14393f565f1}\label{class_i2_c_core_a847fa558d755693f0051b14393f565f1} 
virtual size\+\_\+t {\bfseries write} (const uint8\+\_\+t \texorpdfstring{$\ast$}{*}data, size\+\_\+t quantity)=0
\item 
\Hypertarget{class_i2_c_core_ad6e3708ffb56b3f60754b18f7ca11c71}\label{class_i2_c_core_ad6e3708ffb56b3f60754b18f7ca11c71} 
virtual size\+\_\+t {\bfseries request\+From} (uint8\+\_\+t address, size\+\_\+t len, bool stop\+Bit)=0
\item 
\Hypertarget{class_i2_c_core_a6ab60e8baf1d9027568f351070577ca3}\label{class_i2_c_core_a6ab60e8baf1d9027568f351070577ca3} 
virtual int {\bfseries available} ()=0
\item 
\Hypertarget{class_i2_c_core_a67a83aa1b84d4438fb839a21bcf31cfa}\label{class_i2_c_core_a67a83aa1b84d4438fb839a21bcf31cfa} 
virtual int {\bfseries read} ()=0
\item 
\Hypertarget{class_i2_c_core_a508529b187413b38a5fae1da7c1d1af0}\label{class_i2_c_core_a508529b187413b38a5fae1da7c1d1af0} 
virtual int {\bfseries peek} ()
\item 
\Hypertarget{class_i2_c_core_acde29772640d5b3eecca2248b090e3ef}\label{class_i2_c_core_acde29772640d5b3eecca2248b090e3ef} 
virtual void {\bfseries flush} ()=0
\item 
virtual uint8\+\_\+t \mbox{\hyperlink{class_i2_c_core_a4000d56ed283e62c7d50a4083e4762b6}{get\+Max\+Usages}} () override
\begin{DoxyCompactList}\small\item\em Get the maximum simultaneous usages allowed for this resource. \end{DoxyCompactList}\item 
\Hypertarget{class_i2_c_core_aefafd5e5dd47ab2206be06dcfbb47bd2}\label{class_i2_c_core_aefafd5e5dd47ab2206be06dcfbb47bd2} 
virtual I2\+CStatus {\bfseries get\+I2\+CStatus} () const
\end{DoxyCompactItemize}
\doxysubsection*{Public Member Functions inherited from \mbox{\hyperlink{class_hardware_resource}{Hardware\+Resource}}}
\begin{DoxyCompactItemize}
\item 
bool \mbox{\hyperlink{class_hardware_resource_a26f48b38e5bb1d9bdd47ea2e6de87fdb}{request\+Usage}} ()
\begin{DoxyCompactList}\small\item\em Request a usage slot for this resource. \end{DoxyCompactList}\item 
uint8\+\_\+t \mbox{\hyperlink{class_hardware_resource_a07205354c25627a3bb10ad417e335ff9}{get\+Usages}} ()
\begin{DoxyCompactList}\small\item\em Get the current number of usages of this resource. \end{DoxyCompactList}\item 
bool \mbox{\hyperlink{class_hardware_resource_a569821aa9a34d96ed143488a72e6872b}{is\+Used}} ()
\begin{DoxyCompactList}\small\item\em Check if the resource is currently used. \end{DoxyCompactList}\item 
virtual uint8\+\_\+t \mbox{\hyperlink{class_hardware_resource_a470679cae7880c9ca436755a50f68db4}{get\+Remaining\+Usages}} ()
\begin{DoxyCompactList}\small\item\em Get remaining usage capacity for this resource. \end{DoxyCompactList}\end{DoxyCompactItemize}
\doxysubsubsection*{Static Public Attributes}
\begin{DoxyCompactItemize}
\item 
\Hypertarget{class_i2_c_core_a497bb9da08340f9928a392224dafc2d6}\label{class_i2_c_core_a497bb9da08340f9928a392224dafc2d6} 
static constexpr uint32\+\_\+t {\bfseries I2\+C\+\_\+\+DEFAULT\+\_\+\+FREQUENCY} = 1700000
\end{DoxyCompactItemize}
\doxysubsubsection*{Protected Attributes}
\begin{DoxyCompactItemize}
\item 
\Hypertarget{class_i2_c_core_ac457223ae7336cea9cb4ad34377324cc}\label{class_i2_c_core_ac457223ae7336cea9cb4ad34377324cc} 
int8\+\_\+t {\bfseries \+\_\+sda\+Pin} =-\/1
\item 
\Hypertarget{class_i2_c_core_a9061cd7b867338e86bea99fc3c2e07c2}\label{class_i2_c_core_a9061cd7b867338e86bea99fc3c2e07c2} 
int8\+\_\+t {\bfseries \+\_\+scl\+Pin} =-\/1
\item 
\Hypertarget{class_i2_c_core_ad60de441ea1aa8206933531d1b299f7d}\label{class_i2_c_core_ad60de441ea1aa8206933531d1b299f7d} 
uint32\+\_\+t {\bfseries \+\_\+frequency} = I2\+C\+\_\+\+DEFAULT\+\_\+\+FREQUENCY
\item 
\Hypertarget{class_i2_c_core_ae5baa64864d2970a30ece99ccbe4c319}\label{class_i2_c_core_ae5baa64864d2970a30ece99ccbe4c319} 
int8\+\_\+t {\bfseries \+\_\+i2c\+\_\+num} =-\/1
\item 
\Hypertarget{class_i2_c_core_a511ceb95a3ae8e933df62789f200332b}\label{class_i2_c_core_a511ceb95a3ae8e933df62789f200332b} 
uint32\+\_\+t {\bfseries \+\_\+buffer\+Size} = I2\+C\+\_\+\+DEFAULT\+\_\+\+BUFFER\+\_\+\+LENGTH
\item 
\Hypertarget{class_i2_c_core_a308eab39ef932b80cb9fa455011118ae}\label{class_i2_c_core_a308eab39ef932b80cb9fa455011118ae} 
I2\+CStatus {\bfseries \+\_\+i2c\+Status} = I2\+C\+\_\+\+NOT\+\_\+\+STARTED
\end{DoxyCompactItemize}
\doxysubsection*{Protected Attributes inherited from \mbox{\hyperlink{class_hardware_resource}{Hardware\+Resource}}}
\begin{DoxyCompactItemize}
\item 
uint8\+\_\+t \mbox{\hyperlink{class_hardware_resource_a78845b363f906c0383e91ea912bbddbc}{usages}} =0
\begin{DoxyCompactList}\small\item\em Current usage counter. \end{DoxyCompactList}\end{DoxyCompactItemize}
\doxysubsubsection*{Static Protected Attributes}
\begin{DoxyCompactItemize}
\item 
\Hypertarget{class_i2_c_core_a8bf212a85cabca6ccea9540797e89bf2}\label{class_i2_c_core_a8bf212a85cabca6ccea9540797e89bf2} 
static constexpr uint16\+\_\+t {\bfseries I2\+C\+\_\+\+DEFAULT\+\_\+\+BUFFER\+\_\+\+LENGTH} = 32
\end{DoxyCompactItemize}
\doxysubsubsection*{Additional Inherited Members}
\doxysubsection*{Protected Member Functions inherited from \mbox{\hyperlink{class_hardware_resource}{Hardware\+Resource}}}
\begin{DoxyCompactItemize}
\item 
\mbox{\hyperlink{class_hardware_resource_a7ddffb890a743f2df28128d9afd5bfa5}{Hardware\+Resource}} ()=default
\begin{DoxyCompactList}\small\item\em Default constructor. \end{DoxyCompactList}\end{DoxyCompactItemize}

\label{doc-func-members}
\Hypertarget{class_i2_c_core_doc-func-members}
\doxysubsection{Member Function Documentation}
\Hypertarget{class_i2_c_core_a4000d56ed283e62c7d50a4083e4762b6}\index{I2CCore@{I2CCore}!getMaxUsages@{getMaxUsages}}
\index{getMaxUsages@{getMaxUsages}!I2CCore@{I2CCore}}
\doxysubsubsection{\texorpdfstring{getMaxUsages()}{getMaxUsages()}}
{\footnotesize\ttfamily \label{class_i2_c_core_a4000d56ed283e62c7d50a4083e4762b6} 
virtual uint8\+\_\+t I2\+CCore\+::get\+Max\+Usages (\begin{DoxyParamCaption}{}{}\end{DoxyParamCaption})\hspace{0.3cm}{\ttfamily [inline]}, {\ttfamily [override]}, {\ttfamily [virtual]}}

Get the maximum simultaneous usages allowed for this resource. 

Default implementation returns 1. Override in derived classes to permit multiple users. \begin{DoxyReturn}{Returns}
uint8\+\_\+t Maximum number of concurrent usages allowed. 
\end{DoxyReturn}

Reimplemented from \mbox{\hyperlink{class_hardware_resource_a6b7a709561faf5d344b7c3e14bf37558}{Hardware\+Resource}}.

\Hypertarget{class_i2_c_core_a092566ca5aacc4421559e29f6ff12da5}\index{I2CCore@{I2CCore}!getType@{getType}}
\index{getType@{getType}!I2CCore@{I2CCore}}
\doxysubsubsection{\texorpdfstring{getType()}{getType()}}
{\footnotesize\ttfamily \label{class_i2_c_core_a092566ca5aacc4421559e29f6ff12da5} 
virtual \mbox{\hyperlink{class_hardware_resource_adead6978be3d7b86c18e3d3e051381e6}{Hardware\+Resource\+::\+Type}} I2\+CCore\+::get\+Type (\begin{DoxyParamCaption}{}{}\end{DoxyParamCaption})\hspace{0.3cm}{\ttfamily [inline]}, {\ttfamily [override]}, {\ttfamily [virtual]}}

Get the hardware resource type. 

Must be implemented by derived classes to return the correct \doxylink{class_hardware_resource_adead6978be3d7b86c18e3d3e051381e6}{Type} enum value. \begin{DoxyReturn}{Returns}
\doxylink{class_hardware_resource_adead6978be3d7b86c18e3d3e051381e6}{Type} The type of the hardware resource. 
\end{DoxyReturn}

Implements \mbox{\hyperlink{class_hardware_resource_ad1058e4c12406f756755fad5db55dc77}{Hardware\+Resource}}.

\Hypertarget{class_i2_c_core_a0c8934608811f1a80247981f4e222ce9}\index{I2CCore@{I2CCore}!reset@{reset}}
\index{reset@{reset}!I2CCore@{I2CCore}}
\doxysubsubsection{\texorpdfstring{reset()}{reset()}}
{\footnotesize\ttfamily \label{class_i2_c_core_a0c8934608811f1a80247981f4e222ce9} 
virtual bool I2\+CCore\+::reset (\begin{DoxyParamCaption}{}{}\end{DoxyParamCaption})\hspace{0.3cm}{\ttfamily [inline]}, {\ttfamily [virtual]}}

Reset the hardware resource to a known default state. 

Default implementation clears the usage counter and logs the reset. Derived classes should call the base implementation and perform any additional hardware-\/specific reset steps. \begin{DoxyReturn}{Returns}
true if the reset succeeded, false otherwise. 
\end{DoxyReturn}

Reimplemented from \mbox{\hyperlink{class_hardware_resource_a7372684f2afb5139ef8464194a087649}{Hardware\+Resource}}.

Reimplemented in \mbox{\hyperlink{class_e_s_p32___i2_c_core_aa3e0817cba1f01e19e046fa27a776eab}{ESP32\+\_\+\+I2\+CCore}}.

Here is the call graph for this function\+:
\nopagebreak
\begin{figure}[H]
\begin{center}
\leavevmode

\end{center}
\end{figure}
Here is the caller graph for this function\+:
\nopagebreak
\begin{figure}[H]
\begin{center}
\leavevmode

\end{center}
\end{figure}

The documentation for this class was generated from the following file\+:\begin{DoxyCompactItemize}
\item 
C\+:/\+Users/leowa/\+Documents/\+Platform\+IO/\+Projects/\+CANTram\+Framework\+Usage/lib/\+CANTram\+Framework/include/I2\+CCore.\+h\end{DoxyCompactItemize}

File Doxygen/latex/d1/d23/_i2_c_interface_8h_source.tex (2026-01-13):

\doxysection{I2\+CInterface.\+h}
\hypertarget{_i2_c_interface_8h_source}{}\label{_i2_c_interface_8h_source}\index{C:/Users/leowa/Documents/PlatformIO/Projects/CANTramFrameworkUsage/lib/CANTramFramework/include/I2CInterface.h@{C:/Users/leowa/Documents/PlatformIO/Projects/CANTramFrameworkUsage/lib/CANTramFramework/include/I2CInterface.h}}

\begin{DoxyCode}{0}
\DoxyCodeLine{00001\ \textcolor{preprocessor}{\#ifndef\ I2C\_INTERFACE\_H}}
\DoxyCodeLine{00002\ \textcolor{preprocessor}{\#define\ I2C\_INTERFACE\_H}}
\DoxyCodeLine{00003\ }
\DoxyCodeLine{00004\ \textcolor{preprocessor}{\#include\ "{}Interface.h"{}}}
\DoxyCodeLine{00005\ \textcolor{preprocessor}{\#include\ "{}I2CCore.h"{}}}
\DoxyCodeLine{00006\ \textcolor{preprocessor}{\#include\ "{}Wire.h"{}}}
\DoxyCodeLine{00007\ }
\DoxyCodeLine{00008\ \textcolor{keyword}{class\ }I2CInterface\ :\ \textcolor{keyword}{public}\ Interface\{}
\DoxyCodeLine{00009\ \textcolor{keyword}{public}:}
\DoxyCodeLine{00010\ \ \ \ \ I2CInterface()\ =\ \textcolor{keywordflow}{default};}
\DoxyCodeLine{00011\ }
\DoxyCodeLine{00012\ \ \ \ \ Interface::Type\ getType()\textcolor{keyword}{\ const\ override\ }\{}
\DoxyCodeLine{00013\ \ \ \ \ \ \ \ \ \textcolor{keywordflow}{return}\ Interface::BUS;}
\DoxyCodeLine{00014\ \ \ \ \ \}}
\DoxyCodeLine{00015\ }
\DoxyCodeLine{00016\ \ \ \ \ \textcolor{keywordtype}{void}\ setI2CCore(\mbox{\hyperlink{class_i2_c_core}{I2CCore}}*\ core)\{i2cCore\ =\ core;\}}
\DoxyCodeLine{00017\ \ \ \ \ \mbox{\hyperlink{class_i2_c_core}{I2CCore}}*\ getI2CCore()\{\textcolor{keywordflow}{return}\ i2cCore;\}}
\DoxyCodeLine{00018\ }
\DoxyCodeLine{00019\ \ \ \ \ \textcolor{keywordtype}{bool}\ begin()\{}
\DoxyCodeLine{00020\ \ \ \ \ \ \ \ \ \textcolor{keywordflow}{if}(!i2cCore-\/>begin())\{}
\DoxyCodeLine{00021\ \ \ \ \ \ \ \ \ \ \ \ \ \mbox{\hyperlink{_debug_8h_aab934c3f2345fdd7f8ca02ff2c332f60}{ERROR\_PRINTLN}}(\textcolor{stringliteral}{"{}[I2CInterface]\ ERROR:\ I2C\ initialization\ failed."{}});}
\DoxyCodeLine{00022\ \ \ \ \ \ \ \ \ \ \ \ \ \textcolor{keywordflow}{return}\ \textcolor{keyword}{false};}
\DoxyCodeLine{00023\ \ \ \ \ \ \ \ \ \}}
\DoxyCodeLine{00024\ \ \ \ \ \ \ \ \ \textcolor{keywordflow}{return}\ \textcolor{keyword}{true};\ \ }
\DoxyCodeLine{00025\ \ \ \ \ \}}
\DoxyCodeLine{00026\ \ \ \ \ }
\DoxyCodeLine{00027\ \ \ \ \ \textcolor{keywordtype}{void}\ beginTransmission(uint16\_t\ address)\{}
\DoxyCodeLine{00028\ \ \ \ \ \ \ \ \ i2cCore-\/>beginTransmission((uint8\_t)address);}
\DoxyCodeLine{00029\ \ \ \ \ \};}
\DoxyCodeLine{00030\ \ \ \ \ \textcolor{keywordtype}{void}\ beginTransmission(uint8\_t\ address)\{}
\DoxyCodeLine{00031\ \ \ \ \ \ \ \ \ i2cCore-\/>beginTransmission(address);}
\DoxyCodeLine{00032\ \ \ \ \ \};}
\DoxyCodeLine{00033\ }
\DoxyCodeLine{00034\ \ \ \ \ \textcolor{keywordtype}{void}\ beginTransmission(\textcolor{keywordtype}{int}\ address)\{}
\DoxyCodeLine{00035\ \ \ \ \ \ \ \ \ i2cCore-\/>beginTransmission((uint8\_t)address);}
\DoxyCodeLine{00036\ \ \ \ \ \};}
\DoxyCodeLine{00037\ }
\DoxyCodeLine{00038\ \ \ \ \ uint8\_t\ endTransmission(\textcolor{keywordtype}{bool}\ sendStop)\{}
\DoxyCodeLine{00039\ \ \ \ \ \ \ \ \ \textcolor{keywordflow}{return}\ i2cCore-\/>endTransmission();}
\DoxyCodeLine{00040\ \ \ \ \ \};}
\DoxyCodeLine{00041\ \ \ \ \ uint8\_t\ endTransmission(\textcolor{keywordtype}{void})\{}
\DoxyCodeLine{00042\ \ \ \ \ \ \ \ \ \textcolor{keywordflow}{return}\ i2cCore-\/>endTransmission();}
\DoxyCodeLine{00043\ \ \ \ \ \};}
\DoxyCodeLine{00044\ }
\DoxyCodeLine{00045\ \ \ \ \ \textcolor{keywordtype}{size\_t}\ write(uint8\_t\ data)\{}
\DoxyCodeLine{00046\ \ \ \ \ \ \ \ \ \textcolor{keywordflow}{return}\ i2cCore-\/>write(data);}
\DoxyCodeLine{00047\ \ \ \ \ \};}
\DoxyCodeLine{00048\ \ \ \ \ \textcolor{keywordtype}{size\_t}\ write(\textcolor{keyword}{const}\ uint8\_t*\ data,\ \textcolor{keywordtype}{size\_t}\ length)\{}
\DoxyCodeLine{00049\ \ \ \ \ \ \ \ \ \textcolor{keywordflow}{return}\ i2cCore-\/>write(data,\ length);}
\DoxyCodeLine{00050\ \ \ \ \ \}}
\DoxyCodeLine{00051\ \ \ \ \ \textcolor{keywordtype}{int}\ available(\textcolor{keywordtype}{void})\{}
\DoxyCodeLine{00052\ \ \ \ \ \ \ \ \ \textcolor{keywordflow}{return}\ i2cCore-\/>available();}
\DoxyCodeLine{00053\ \ \ \ \ \};}
\DoxyCodeLine{00054\ \ \ \ \ \textcolor{keywordtype}{int}\ read(\textcolor{keywordtype}{void})\{}
\DoxyCodeLine{00055\ \ \ \ \ \ \ \ \ \textcolor{keywordflow}{return}\ i2cCore-\/>read();}
\DoxyCodeLine{00056\ \ \ \ \ \};}
\DoxyCodeLine{00057\ \ \ \ \ \textcolor{keywordtype}{int}\ peek(\textcolor{keywordtype}{void})\{}
\DoxyCodeLine{00058\ \ \ \ \ \ \ \ \ \textcolor{keywordflow}{return}\ i2cCore-\/>peek();}
\DoxyCodeLine{00059\ \ \ \ \ \};}
\DoxyCodeLine{00060\ \ \ \ \ \textcolor{keywordtype}{void}\ flush(\textcolor{keywordtype}{void})\{}
\DoxyCodeLine{00061\ \ \ \ \ \ \ \ \ i2cCore-\/>flush();}
\DoxyCodeLine{00062\ \ \ \ \ \};}
\DoxyCodeLine{00063\ }
\DoxyCodeLine{00064\ \ \ \ \ \textcolor{keyword}{inline}\ \textcolor{keywordtype}{size\_t}\ write(\textcolor{keyword}{const}\ \textcolor{keywordtype}{char}\ *\ s)}
\DoxyCodeLine{00065\ \ \ \ \ \{}
\DoxyCodeLine{00066\ \ \ \ \ \ \ \ \ \textcolor{keywordflow}{return}\ write((uint8\_t*)\ s,\ strlen(s));}
\DoxyCodeLine{00067\ \ \ \ \ \}}
\DoxyCodeLine{00068\ \ \ \ \ \textcolor{keyword}{inline}\ \textcolor{keywordtype}{size\_t}\ write(\textcolor{keywordtype}{unsigned}\ \textcolor{keywordtype}{long}\ n)}
\DoxyCodeLine{00069\ \ \ \ \ \{}
\DoxyCodeLine{00070\ \ \ \ \ \ \ \ \ \textcolor{keywordflow}{return}\ write((uint8\_t)n);}
\DoxyCodeLine{00071\ \ \ \ \ \}}
\DoxyCodeLine{00072\ \ \ \ \ \textcolor{keyword}{inline}\ \textcolor{keywordtype}{size\_t}\ write(\textcolor{keywordtype}{long}\ n)}
\DoxyCodeLine{00073\ \ \ \ \ \{}
\DoxyCodeLine{00074\ \ \ \ \ \ \ \ \ \textcolor{keywordflow}{return}\ write((uint8\_t)n);}
\DoxyCodeLine{00075\ \ \ \ \ \}}
\DoxyCodeLine{00076\ \ \ \ \ \textcolor{keyword}{inline}\ \textcolor{keywordtype}{size\_t}\ write(\textcolor{keywordtype}{unsigned}\ \textcolor{keywordtype}{int}\ n)}
\DoxyCodeLine{00077\ \ \ \ \ \{}
\DoxyCodeLine{00078\ \ \ \ \ \ \ \ \ \textcolor{keywordflow}{return}\ write((uint8\_t)n);}
\DoxyCodeLine{00079\ \ \ \ \ \}}
\DoxyCodeLine{00080\ \ \ \ \ \textcolor{keyword}{inline}\ \textcolor{keywordtype}{size\_t}\ write(\textcolor{keywordtype}{int}\ n)}
\DoxyCodeLine{00081\ \ \ \ \ \{}
\DoxyCodeLine{00082\ \ \ \ \ \ \ \ \ \textcolor{keywordflow}{return}\ write((uint8\_t)n);}
\DoxyCodeLine{00083\ \ \ \ \ \}}
\DoxyCodeLine{00084\ }
\DoxyCodeLine{00085\ \textcolor{keyword}{private}:}
\DoxyCodeLine{00086\ \ \ \ \ \mbox{\hyperlink{class_i2_c_core}{I2CCore}}*\ i2cCore;}
\DoxyCodeLine{00087\ \};}
\DoxyCodeLine{00088\ \textcolor{preprocessor}{\ \ \ \ \#endif}}

\end{DoxyCode}

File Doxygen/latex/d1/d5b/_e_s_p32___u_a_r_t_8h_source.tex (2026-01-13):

\doxysection{ESP32\+\_\+\+UART.\+h}
\hypertarget{_e_s_p32___u_a_r_t_8h_source}{}\label{_e_s_p32___u_a_r_t_8h_source}\index{C:/Users/leowa/Documents/PlatformIO/Projects/CANTramFrameworkUsage/lib/CANTramFramework/include/ESP32\_UART.h@{C:/Users/leowa/Documents/PlatformIO/Projects/CANTramFrameworkUsage/lib/CANTramFramework/include/ESP32\_UART.h}}

\begin{DoxyCode}{0}
\DoxyCodeLine{00001\ \textcolor{preprocessor}{\#ifndef\ ESP32\_UART\_H}}
\DoxyCodeLine{00002\ \textcolor{preprocessor}{\#define\ ESP32\_UART\_H}}
\DoxyCodeLine{00003\ }
\DoxyCodeLine{00004\ \textcolor{preprocessor}{\#include\ <driver/uart.h>}}
\DoxyCodeLine{00005\ \textcolor{preprocessor}{\#include\ "{}UARTInterface.h"{}}}
\DoxyCodeLine{00006\ \textcolor{preprocessor}{\#include\ "{}\mbox{\hyperlink{_u_a_r_t_core_8h}{UARTCore.h}}"{}}}
\DoxyCodeLine{00007\ }
\DoxyCodeLine{00008\ \textcolor{comment}{/*}}
\DoxyCodeLine{00009\ \textcolor{comment}{\ \ \ \ @brief\ Class\ to\ manage\ UART\ Objects\ on\ ESP32}}
\DoxyCodeLine{00010\ \textcolor{comment}{*/}}
\DoxyCodeLine{00011\ \textcolor{keyword}{class\ }ESP32\_UART\ :\ \textcolor{keyword}{public}\ \mbox{\hyperlink{class_u_a_r_t_core}{UARTCore}}\ \{}
\DoxyCodeLine{00012\ \ \ \ \ \textcolor{keyword}{public}:}
\DoxyCodeLine{00013\ }
\DoxyCodeLine{00014\ \ \ \ \ \ \ \ \ \textcolor{keyword}{enum}\ uartState\ \{}
\DoxyCodeLine{00015\ \ \ \ \ \ \ \ \ NONE,}
\DoxyCodeLine{00016\ \ \ \ \ \ \ \ \ INSTALLED,}
\DoxyCodeLine{00017\ \ \ \ \ \ \ \ \ CONFIGURED,}
\DoxyCodeLine{00018\ \ \ \ \ \ \ \ \ STARTED}
\DoxyCodeLine{00019\ \ \ \ \ \ \ \ \ \};}
\DoxyCodeLine{00020\ \ \ \ \ \ \ \ \ ESP32\_UART()\ =\ \textcolor{keywordflow}{default};}
\DoxyCodeLine{00021\ \ \ \ \ \ \ \ \ \textcolor{keyword}{virtual}\ \textcolor{keywordtype}{bool}\ \mbox{\hyperlink{class_e_s_p32___u_a_r_t_a0729d44483caad65176f225c7924755c}{reset}}()\ \textcolor{keyword}{override};}
\DoxyCodeLine{00022\ \ \ \ \ \ \ \ \ }
\DoxyCodeLine{00023\ \ \ \ \ \ \ \ \ \textcolor{keywordtype}{bool}\ \mbox{\hyperlink{class_e_s_p32___u_a_r_t_a6da4b5cb2f0ffee5af03f66224e4bcb2}{install}}(}
\DoxyCodeLine{00024\ \ \ \ \ \ \ \ \ \ \ \ \ \textcolor{keywordtype}{int}\ uart\_num,}
\DoxyCodeLine{00025\ \ \ \ \ \ \ \ \ \ \ \ \ uint8\_t\ tx\_pin,\ }
\DoxyCodeLine{00026\ \ \ \ \ \ \ \ \ \ \ \ \ uint8\_t\ rx\_pin,\ }
\DoxyCodeLine{00027\ \ \ \ \ \ \ \ \ \ \ \ \ uint16\_t\ bufferSize}
\DoxyCodeLine{00028\ \ \ \ \ \ \ \ \ )\ \textcolor{keyword}{override};\ \textcolor{comment}{//Prepare\ the\ driver\ and\ allocate\ memory}}
\DoxyCodeLine{00029\ }
\DoxyCodeLine{00030\ \ \ \ \ \ \ \ \ \textcolor{keywordtype}{bool}\ \mbox{\hyperlink{class_e_s_p32___u_a_r_t_a1a0b6a3517aeeda8f92cb43054d47436}{applyConfig}}();\ \textcolor{comment}{//Start\ the\ driver}}
\DoxyCodeLine{00031\ \ \ \ \ \ \ \ \ \ \textcolor{keywordtype}{bool}\ \mbox{\hyperlink{class_e_s_p32___u_a_r_t_acdf2bf644ded75b797ef85f44fcb5f60}{applyPins}}(\textcolor{keywordtype}{int}\ tx\_pin,\ \textcolor{keywordtype}{int}\ rx\_pin);\ \textcolor{comment}{//Set\ the\ TX\ and\ RX\ pins}}
\DoxyCodeLine{00032\ \ \ \ \ \ \ \ \ \textcolor{keywordtype}{bool}\ \mbox{\hyperlink{class_e_s_p32___u_a_r_t_acdf2bf644ded75b797ef85f44fcb5f60}{applyPins}}();\ }
\DoxyCodeLine{00033\ \ \ \ \ \ \ \ \ \textcolor{keywordtype}{void}\ setUARTPort(uart\_port\_t\ uartPort)\ \{\ \_uartPort\ =\ uartPort;\ \}}
\DoxyCodeLine{00034\ }
\DoxyCodeLine{00035\ \ \ \ \ \ \ \ \ \textcolor{keywordtype}{bool}\ \mbox{\hyperlink{class_e_s_p32___u_a_r_t_aa16ed83457d3ddb3ca9290581082fcba}{send}}(\textcolor{keyword}{const}\ \textcolor{keywordtype}{char}\ buffer[],\ \textcolor{keywordtype}{size\_t}\ size)\ \textcolor{keyword}{override};}
\DoxyCodeLine{00036\ \ \ \ \ \ \ \ \ \textcolor{keywordtype}{size\_t}\ \mbox{\hyperlink{class_e_s_p32___u_a_r_t_a9347eb37496924596031fac5adbfca56}{read}}(\textcolor{keywordtype}{char}\ buffer[])\ \textcolor{keyword}{override};}
\DoxyCodeLine{00037\ \ \ \ \ \ \ \ \ \textcolor{keywordtype}{size\_t}\ \mbox{\hyperlink{class_e_s_p32___u_a_r_t_ab7b05058426c5c21323ba8b113f2ec5e}{available}}()\ \textcolor{keyword}{override};}
\DoxyCodeLine{00038\ \ \ \ \ \ \ \ \ \textcolor{keywordtype}{void}\ \mbox{\hyperlink{class_e_s_p32___u_a_r_t_a48a03e2bed3b8320ca1f4c65fa814867}{flush}}()\ \textcolor{keyword}{override};}
\DoxyCodeLine{00039\ \ \ \ \ \textcolor{keyword}{private}:}
\DoxyCodeLine{00040\ \ \ \ \ \ \ \ \ uartState\ \_state\ =\ NONE;}
\DoxyCodeLine{00041\ \ \ \ \ \ \ \ \ QueueHandle\_t\ uart\_queue\ =\ \textcolor{keyword}{nullptr};}
\DoxyCodeLine{00042\ \ \ \ \ \ \ \ \ uart\_port\_t\ \_uartPort=DEFAULT\_REF;}
\DoxyCodeLine{00043\ }
\DoxyCodeLine{00044\ \ \ \ \ \ \ \ \ uart\_word\_length\_t\ toEsp32DataBits(\mbox{\hyperlink{class_u_a_r_t_core_a1895842f7c33678bdf154e12cc617903}{UARTCore::DataBits}}\ bits)\ \{}
\DoxyCodeLine{00045\ \ \ \ \ \ \ \ \ \ \ \ \ \textcolor{keywordflow}{switch}\ (bits)\ \{}
\DoxyCodeLine{00046\ \ \ \ \ \ \ \ \ \ \ \ \ \textcolor{keywordflow}{case}\ UARTCore::DataBits::UART\_DATA\_5\_BITS:\ \textcolor{keywordflow}{return}\ uart\_word\_length\_t(UART\_DATA\_5\_BITS);}
\DoxyCodeLine{00047\ \ \ \ \ \ \ \ \ \ \ \ \ \textcolor{keywordflow}{case}\ UARTCore::DataBits::UART\_DATA\_6\_BITS:\ \textcolor{keywordflow}{return}\ uart\_word\_length\_t(UART\_DATA\_6\_BITS);}
\DoxyCodeLine{00048\ \ \ \ \ \ \ \ \ \ \ \ \ \textcolor{keywordflow}{case}\ UARTCore::DataBits::UART\_DATA\_7\_BITS:\ \textcolor{keywordflow}{return}\ uart\_word\_length\_t(UART\_DATA\_7\_BITS);}
\DoxyCodeLine{00049\ \ \ \ \ \ \ \ \ \ \ \ \ \textcolor{keywordflow}{case}\ UARTCore::DataBits::UART\_DATA\_8\_BITS:\ \textcolor{keywordflow}{return}\ uart\_word\_length\_t(UART\_DATA\_8\_BITS);}
\DoxyCodeLine{00050\ \ \ \ \ \ \ \ \ \ \ \ \ \textcolor{keywordflow}{default}:\ \textcolor{keywordflow}{return}\ uart\_word\_length\_t(UART\_DATA\_8\_BITS);\ \textcolor{comment}{//\ fallback\ or\ handle\ error}}
\DoxyCodeLine{00051\ \ \ \ \ \ \ \ \ \ \ \ \ \}}
\DoxyCodeLine{00052\ \ \ \ \ \ \ \ \ \}}
\DoxyCodeLine{00053\ }
\DoxyCodeLine{00054\ \ \ \ \ \ \ \ \ uart\_parity\_t\ toEsp32Parity(\mbox{\hyperlink{class_u_a_r_t_core_a53addcd39a841913c86bd7e25cca94a0}{UARTCore::Parity}}\ parity)\ \{}
\DoxyCodeLine{00055\ \ \ \ \ \ \ \ \ \ \ \ \ \textcolor{keywordflow}{switch}\ (parity)\ \{}
\DoxyCodeLine{00056\ \ \ \ \ \ \ \ \ \ \ \ \ \textcolor{keywordflow}{case}\ UARTCore::Parity::UART\_PARITY\_NONE:\ \textcolor{keywordflow}{return}\ uart\_parity\_t(UART\_PARITY\_DISABLE);}
\DoxyCodeLine{00057\ \ \ \ \ \ \ \ \ \ \ \ \ \textcolor{keywordflow}{case}\ UARTCore::Parity::UART\_PARITY\_EVEN:\ \textcolor{keywordflow}{return}\ uart\_parity\_t(UART\_PARITY\_EVEN);}
\DoxyCodeLine{00058\ \ \ \ \ \ \ \ \ \ \ \ \ \textcolor{keywordflow}{case}\ UARTCore::Parity::UART\_PARITY\_ODD:\ \ \textcolor{keywordflow}{return}\ uart\_parity\_t(UART\_PARITY\_ODD);}
\DoxyCodeLine{00059\ \ \ \ \ \ \ \ \ \ \ \ \ \textcolor{keywordflow}{default}:\ \textcolor{keywordflow}{return}\ uart\_parity\_t(UART\_PARITY\_DISABLE);\ \textcolor{comment}{//\ fallback\ or\ handle\ error}}
\DoxyCodeLine{00060\ \ \ \ \ \ \ \ \ \ \ \ \ \}}
\DoxyCodeLine{00061\ \ \ \ \ \ \ \ \ \}}
\DoxyCodeLine{00062\ }
\DoxyCodeLine{00063\ \ \ \ \ \ \ \ \ uart\_stop\_bits\_t\ toEsp32StopBits(\mbox{\hyperlink{class_u_a_r_t_core_ab88ed673e8897a7804c27ac7d749f00b}{UARTCore::StopBits}}\ stopBits)\ \{}
\DoxyCodeLine{00064\ \ \ \ \ \ \ \ \ \ \ \ \ \textcolor{keywordflow}{switch}\ (stopBits)\ \{}
\DoxyCodeLine{00065\ \ \ \ \ \ \ \ \ \ \ \ \ \textcolor{keywordflow}{case}\ UARTCore::StopBits::UART\_STOP\_BITS\_1:\ \ \ \textcolor{keywordflow}{return}\ uart\_stop\_bits\_t(UART\_STOP\_BITS\_1);}
\DoxyCodeLine{00066\ \ \ \ \ \ \ \ \ \ \ \ \ \textcolor{keywordflow}{case}\ UARTCore::StopBits::UART\_STOP\_BITS\_1\_5:\ \textcolor{keywordflow}{return}\ uart\_stop\_bits\_t(UART\_STOP\_BITS\_1\_5);}
\DoxyCodeLine{00067\ \ \ \ \ \ \ \ \ \ \ \ \ \textcolor{keywordflow}{case}\ UARTCore::StopBits::UART\_STOP\_BITS\_2:\ \ \ \textcolor{keywordflow}{return}\ uart\_stop\_bits\_t(UART\_STOP\_BITS\_2);}
\DoxyCodeLine{00068\ \ \ \ \ \ \ \ \ \ \ \ \ \textcolor{keywordflow}{default}:\ \textcolor{keywordflow}{return}\ uart\_stop\_bits\_t(UART\_STOP\_BITS\_1);\ \textcolor{comment}{//\ fallback\ or\ handle\ error}}
\DoxyCodeLine{00069\ \ \ \ \ \ \ \ \ \ \ \ \ \}}
\DoxyCodeLine{00070\ \ \ \ \ \ \ \ \ \}}
\DoxyCodeLine{00071\ }
\DoxyCodeLine{00072\ }
\DoxyCodeLine{00073\ \};}
\DoxyCodeLine{00074\ }
\DoxyCodeLine{00075\ \textcolor{preprocessor}{\#endif}}

\end{DoxyCode}

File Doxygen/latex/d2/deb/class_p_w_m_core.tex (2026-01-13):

\doxysection{PWMCore Class Reference}
\hypertarget{class_p_w_m_core}{}\label{class_p_w_m_core}\index{PWMCore@{PWMCore}}

Inheritance diagram for PWMCore\+:
\nopagebreak
\begin{figure}[H]
\begin{center}
\leavevmode
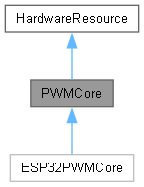
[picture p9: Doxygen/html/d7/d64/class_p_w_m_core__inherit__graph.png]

\end{center}
\end{figure}

Collaboration diagram for PWMCore\+:
\nopagebreak
\begin{figure}[H]
\begin{center}
\leavevmode

\end{center}
\end{figure}
\doxysubsubsection*{Public Member Functions}
\begin{DoxyCompactItemize}
\item 
virtual void \mbox{\hyperlink{class_p_w_m_core_a169fc8e6e28c21b75af25da238fd9896}{begin}} ()
\begin{DoxyCompactList}\small\item\em Initialize PWM core resources. \end{DoxyCompactList}\item 
virtual bool \mbox{\hyperlink{class_p_w_m_core_a054f5a4b0ac5b5cac1bb40e34c0f8912}{add\+Channel}} (\mbox{\hyperlink{class_output_definition}{Output\+Definition}} \texorpdfstring{$\ast$}{*}def)=0
\begin{DoxyCompactList}\small\item\em Add/allocate a PWM channel for the given output definition. \end{DoxyCompactList}\item 
virtual void \mbox{\hyperlink{class_p_w_m_core_ad4ee3115a671d8df6f18ccfaf2b84848}{set\+Duty}} (\mbox{\hyperlink{class_output_definition}{Output\+Definition}} \texorpdfstring{$\ast$}{*}def, uint16\+\_\+t duty)=0
\begin{DoxyCompactList}\small\item\em Set PWM duty cycle for a registered output. \end{DoxyCompactList}\item 
\mbox{\hyperlink{class_hardware_resource_adead6978be3d7b86c18e3d3e051381e6}{Hardware\+Resource\+::\+Type}} \mbox{\hyperlink{class_p_w_m_core_a0d03256d58a18e60ac2375bfd3ad3a00}{get\+Type}} () override
\begin{DoxyCompactList}\small\item\em Get the hardware resource type. \end{DoxyCompactList}\end{DoxyCompactItemize}
\doxysubsection*{Public Member Functions inherited from \mbox{\hyperlink{class_hardware_resource}{Hardware\+Resource}}}
\begin{DoxyCompactItemize}
\item 
virtual bool \mbox{\hyperlink{class_hardware_resource_a7372684f2afb5139ef8464194a087649}{reset}} ()
\begin{DoxyCompactList}\small\item\em Reset the hardware resource to a known default state. \end{DoxyCompactList}\item 
bool \mbox{\hyperlink{class_hardware_resource_a26f48b38e5bb1d9bdd47ea2e6de87fdb}{request\+Usage}} ()
\begin{DoxyCompactList}\small\item\em Request a usage slot for this resource. \end{DoxyCompactList}\item 
uint8\+\_\+t \mbox{\hyperlink{class_hardware_resource_a07205354c25627a3bb10ad417e335ff9}{get\+Usages}} ()
\begin{DoxyCompactList}\small\item\em Get the current number of usages of this resource. \end{DoxyCompactList}\item 
bool \mbox{\hyperlink{class_hardware_resource_a569821aa9a34d96ed143488a72e6872b}{is\+Used}} ()
\begin{DoxyCompactList}\small\item\em Check if the resource is currently used. \end{DoxyCompactList}\item 
virtual uint8\+\_\+t \mbox{\hyperlink{class_hardware_resource_a470679cae7880c9ca436755a50f68db4}{get\+Remaining\+Usages}} ()
\begin{DoxyCompactList}\small\item\em Get remaining usage capacity for this resource. \end{DoxyCompactList}\end{DoxyCompactItemize}
\doxysubsubsection*{Protected Member Functions}
\begin{DoxyCompactItemize}
\item 
\mbox{\hyperlink{class_p_w_m_core_adf80491c0bcb78e790102703a7f45e2b}{PWMCore}} ()=default
\begin{DoxyCompactList}\small\item\em Protected default constructor. \end{DoxyCompactList}\item 
virtual uint8\+\_\+t \mbox{\hyperlink{class_p_w_m_core_a7d8fa8730b71956702cce7fe90b60a8d}{get\+Max\+Usages}} () override
\begin{DoxyCompactList}\small\item\em Get the maximum simultaneous usages allowed for this resource. \end{DoxyCompactList}\end{DoxyCompactItemize}
\doxysubsection*{Protected Member Functions inherited from \mbox{\hyperlink{class_hardware_resource}{Hardware\+Resource}}}
\begin{DoxyCompactItemize}
\item 
\mbox{\hyperlink{class_hardware_resource_a7ddffb890a743f2df28128d9afd5bfa5}{Hardware\+Resource}} ()=default
\begin{DoxyCompactList}\small\item\em Default constructor. \end{DoxyCompactList}\end{DoxyCompactItemize}
\doxysubsubsection*{Protected Attributes}
\begin{DoxyCompactItemize}
\item 
bool \mbox{\hyperlink{class_p_w_m_core_a8aecc6ed076e3ddc10aa8e9a57bf67da}{\+\_\+initialized}} =false
\begin{DoxyCompactList}\small\item\em Internal initialized flag. \end{DoxyCompactList}\end{DoxyCompactItemize}
\doxysubsection*{Protected Attributes inherited from \mbox{\hyperlink{class_hardware_resource}{Hardware\+Resource}}}
\begin{DoxyCompactItemize}
\item 
uint8\+\_\+t \mbox{\hyperlink{class_hardware_resource_a78845b363f906c0383e91ea912bbddbc}{usages}} =0
\begin{DoxyCompactList}\small\item\em Current usage counter. \end{DoxyCompactList}\end{DoxyCompactItemize}
\doxysubsubsection*{Additional Inherited Members}
\doxysubsection*{Public Types inherited from \mbox{\hyperlink{class_hardware_resource}{Hardware\+Resource}}}
\begin{DoxyCompactItemize}
\item 
enum \mbox{\hyperlink{class_hardware_resource_adead6978be3d7b86c18e3d3e051381e6}{Type}} \{ \newline
\mbox{\hyperlink{class_hardware_resource_adead6978be3d7b86c18e3d3e051381e6ac6f39e4a2dbc764df53048f26209f0a1}{UART}}
, \mbox{\hyperlink{class_hardware_resource_adead6978be3d7b86c18e3d3e051381e6a63a2eead0d2771007afa8c8af281c50d}{SPI}}
, \mbox{\hyperlink{class_hardware_resource_adead6978be3d7b86c18e3d3e051381e6ac77292ec986f613995babba396598dbc}{I2C}}
, \mbox{\hyperlink{class_hardware_resource_adead6978be3d7b86c18e3d3e051381e6ac2fe3e8cc9a9a8fcb39c32be2da214c5}{PWM}}
, \newline
\mbox{\hyperlink{class_hardware_resource_adead6978be3d7b86c18e3d3e051381e6a0ae946256af51077cacc3c0a11575635}{CAN}}
 \}
\begin{DoxyCompactList}\small\item\em Enumeration of hardware resource types. \end{DoxyCompactList}\end{DoxyCompactItemize}

\label{doc-constructors}
\Hypertarget{class_p_w_m_core_doc-constructors}
\doxysubsection{Constructor \& Destructor Documentation}
\Hypertarget{class_p_w_m_core_adf80491c0bcb78e790102703a7f45e2b}\index{PWMCore@{PWMCore}!PWMCore@{PWMCore}}
\index{PWMCore@{PWMCore}!PWMCore@{PWMCore}}
\doxysubsubsection{\texorpdfstring{PWMCore()}{PWMCore()}}
{\footnotesize\ttfamily \label{class_p_w_m_core_adf80491c0bcb78e790102703a7f45e2b} 
PWMCore\+::\+PWMCore (\begin{DoxyParamCaption}{}{}\end{DoxyParamCaption})\hspace{0.3cm}{\ttfamily [protected]}, {\ttfamily [default]}}

Protected default constructor. 

Prevent direct instantiation of the base class. Derived implementations should call this constructor from their constructors. 

\label{doc-func-members}
\Hypertarget{class_p_w_m_core_doc-func-members}
\doxysubsection{Member Function Documentation}
\Hypertarget{class_p_w_m_core_a054f5a4b0ac5b5cac1bb40e34c0f8912}\index{PWMCore@{PWMCore}!addChannel@{addChannel}}
\index{addChannel@{addChannel}!PWMCore@{PWMCore}}
\doxysubsubsection{\texorpdfstring{addChannel()}{addChannel()}}
{\footnotesize\ttfamily \label{class_p_w_m_core_a054f5a4b0ac5b5cac1bb40e34c0f8912} 
virtual bool PWMCore\+::add\+Channel (\begin{DoxyParamCaption}\item[{\mbox{\hyperlink{class_output_definition}{Output\+Definition}} \texorpdfstring{$\ast$}{*}}]{def}{}\end{DoxyParamCaption})\hspace{0.3cm}{\ttfamily [pure virtual]}}

Add/allocate a PWM channel for the given output definition. 

Reserve any internal timer/channel resources required to drive PWM on the provided \doxylink{class_output_definition}{Output\+Definition}. The implementation should validate that the \doxylink{class_output_definition}{Output\+Definition} supports PWM and return true on success. 
\begin{DoxyParams}{Parameters}
{\em def} & Pointer to the \doxylink{class_output_definition}{Output\+Definition} to register for PWM. \\
\hline
\end{DoxyParams}
\begin{DoxyReturn}{Returns}
true if the channel was added/allocated successfully, false otherwise. 
\end{DoxyReturn}

Implemented in \mbox{\hyperlink{class_e_s_p32_p_w_m_core_aa519c3a55207f3d0122a2c0e63ffaf5d}{ESP32\+PWMCore}}.

\Hypertarget{class_p_w_m_core_a169fc8e6e28c21b75af25da238fd9896}\index{PWMCore@{PWMCore}!begin@{begin}}
\index{begin@{begin}!PWMCore@{PWMCore}}
\doxysubsubsection{\texorpdfstring{begin()}{begin()}}
{\footnotesize\ttfamily \label{class_p_w_m_core_a169fc8e6e28c21b75af25da238fd9896} 
virtual void PWMCore\+::begin (\begin{DoxyParamCaption}{}{}\end{DoxyParamCaption})\hspace{0.3cm}{\ttfamily [virtual]}}

Initialize PWM core resources. 

Perform any platform-\/specific initialization required before PWM channels can be allocated or used. Implementations should set internal initialized state and configure timers/hardware as needed. \begin{DoxyReturn}{Returns}
void 
\end{DoxyReturn}

Reimplemented in \mbox{\hyperlink{class_e_s_p32_p_w_m_core_a0f842f0b6d66e76ebcf186334ba04330}{ESP32\+PWMCore}}.

\Hypertarget{class_p_w_m_core_a7d8fa8730b71956702cce7fe90b60a8d}\index{PWMCore@{PWMCore}!getMaxUsages@{getMaxUsages}}
\index{getMaxUsages@{getMaxUsages}!PWMCore@{PWMCore}}
\doxysubsubsection{\texorpdfstring{getMaxUsages()}{getMaxUsages()}}
{\footnotesize\ttfamily \label{class_p_w_m_core_a7d8fa8730b71956702cce7fe90b60a8d} 
virtual uint8\+\_\+t PWMCore\+::get\+Max\+Usages (\begin{DoxyParamCaption}{}{}\end{DoxyParamCaption})\hspace{0.3cm}{\ttfamily [inline]}, {\ttfamily [override]}, {\ttfamily [protected]}, {\ttfamily [virtual]}}

Get the maximum simultaneous usages allowed for this resource. 

\doxylink{class_p_w_m_core}{PWMCore} limits concurrent users by default to a single module (the main module). Override in derived classes only if multiple simultaneous users are supported. \begin{DoxyReturn}{Returns}
uint8\+\_\+t Maximum number of concurrent usages (default 1). 
\end{DoxyReturn}

Reimplemented from \mbox{\hyperlink{class_hardware_resource_a6b7a709561faf5d344b7c3e14bf37558}{Hardware\+Resource}}.

Reimplemented in \mbox{\hyperlink{class_e_s_p32_p_w_m_core_a15e540c8230375afdf62ba4175712aa6}{ESP32\+PWMCore}}.

\Hypertarget{class_p_w_m_core_a0d03256d58a18e60ac2375bfd3ad3a00}\index{PWMCore@{PWMCore}!getType@{getType}}
\index{getType@{getType}!PWMCore@{PWMCore}}
\doxysubsubsection{\texorpdfstring{getType()}{getType()}}
{\footnotesize\ttfamily \label{class_p_w_m_core_a0d03256d58a18e60ac2375bfd3ad3a00} 
\mbox{\hyperlink{class_hardware_resource_adead6978be3d7b86c18e3d3e051381e6}{Hardware\+Resource\+::\+Type}} PWMCore\+::get\+Type (\begin{DoxyParamCaption}{}{}\end{DoxyParamCaption})\hspace{0.3cm}{\ttfamily [inline]}, {\ttfamily [override]}, {\ttfamily [virtual]}}

Get the hardware resource type.
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

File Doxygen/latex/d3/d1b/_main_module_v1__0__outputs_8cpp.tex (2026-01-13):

\doxysection{C\+:/\+Users/leowa/\+Documents/\+Platform\+IO/\+Projects/\+CANTram\+Framework\+Usage/lib/\+CANTram\+Framework/src/modules/\+Main\+Module\+V1\+\_\+0\+\_\+outputs.cpp File Reference}
\hypertarget{_main_module_v1__0__outputs_8cpp}{}\label{_main_module_v1__0__outputs_8cpp}\index{C:/Users/leowa/Documents/PlatformIO/Projects/CANTramFrameworkUsage/lib/CANTramFramework/src/modules/MainModuleV1\_0\_outputs.cpp@{C:/Users/leowa/Documents/PlatformIO/Projects/CANTramFrameworkUsage/lib/CANTramFramework/src/modules/MainModuleV1\_0\_outputs.cpp}}
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

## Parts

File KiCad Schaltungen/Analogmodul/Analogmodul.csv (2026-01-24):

Reference | Value | Footprint | Qty | Manufacturer_Name | Manufacturer_Part_Number | Mouser Part Number | Exclude from BOM | Projekt
C1 | 330n | Capacitor_SMD:C_1206_3216Metric | 1 | KEMET | C1206X334J1RECAUTO | 80-C1206X334J1RECAUT |  | Analogmodul
C2 | 100n | Capacitor_SMD:C_1206_3216Metric | 1 | Murata Electronics | GRM3195C2A104JA01D | 81-GRM3195C2A104JA1D |  | Analogmodul
C3 | 1u | Capacitor_SMD:C_1206_3216Metric | 1 | KEMET | C1206X105J1RACTU | 80-C1206X105J1R |  | Analogmodul
C4 | 100n | Capacitor_SMD:C_1206_3216Metric | 1 | Murata Electronics | GRM3195C2A104JA01D | 81-GRM3195C2A104JA1D |  | Analogmodul
C5 | 100n | Capacitor_SMD:C_1206_3216Metric | 1 | Murata Electronics | GRM3195C2A104JA01D | 81-GRM3195C2A104JA1D |  | Analogmodul
C6 | 100n | Capacitor_SMD:C_1206_3216Metric | 1 | Murata Electronics | GRM3195C2A104JA01D | 81-GRM3195C2A104JA1D |  | Analogmodul
C7 | 100n | Capacitor_SMD:C_1206_3216Metric | 1 | Murata Electronics | GRM3195C2A104JA01D | 81-GRM3195C2A104JA1D |  | Analogmodul
C8 | 21n | Capacitor_SMD:C_1206_3216Metric | 1 | Murata Electronics | GRM3195C2A104JA01D | 81-GRM3195C2A104JA1D |  | Analogmodul
C9 | 100n | Capacitor_SMD:C_1206_3216Metric | 1 | Murata Electronics | GRM3195C2A104JA01D | 81-GRM3195C2A104JA1D |  | Analogmodul
C10 | 21n | Capacitor_SMD:C_1206_3216Metric | 1 | Murata Electronics | GRM3195C2A104JA01D | 81-GRM3195C2A104JA1D |  | Analogmodul
C11 | 100n | Capacitor_SMD:C_1206_3216Metric | 1 | Murata Electronics | GRM3195C2A104JA01D | 81-GRM3195C2A104JA1D |  | Analogmodul
C12 | 1u | Capacitor_SMD:C_1206_3216Metric | 1 | KEMET | C1206X105J1RACTU | 80-C1206X105J1R |  | Analogmodul
C13 | 1u | Capacitor_SMD:C_1206_3216Metric | 1 | KEMET | C1206X105J1RACTU | 80-C1206X105J1R |  | Analogmodul
C15 | 10n | Capacitor_SMD:C_1206_3216Metric | 1 | Murata Electronics | GRT3195C2A103JA02D | 81-GRT3195C2A103JA2D |  | Analogmodul
C16 | 10n | Capacitor_SMD:C_1206_3216Metric | 1 | Murata Electronics | GRT3195C2A103JA02D | 81-GRT3195C2A103JA2D |  | Analogmodul
C17 | 100n | Capacitor_SMD:C_1206_3216Metric | 1 | Murata Electronics | GRT3195C2A103JA02D | 81-GRT3195C2A103JA2D |  | Analogmodul
C18 | 10u | Capacitor_SMD:C_1206_3216Metric | 1 | Murata Electronics | GRT3195C2A103JA02D | 81-GRT3195C2A103JA2D |  | Analogmodul
C19 | 100n | Capacitor_SMD:C_1206_3216Metric | 1 | KEMET | C1206C224J1RECAUTO | 80-C1206C224J1RECAUT |  | Analogmodul
C20 | 100n | Capacitor_SMD:C_1206_3216Metric | 1 | KEMET | C1206C224J1RECAUTO | 80-C1206C224J1RECAUT |  | Analogmodul
C21 | 100n | Capacitor_SMD:C_1206_3216Metric | 1 | KEMET | C1206C224J1RECAUTO | 80-C1206C224J1RECAUT |  | Analogmodul
C22 | 100n | Capacitor_SMD:C_1206_3216Metric | 1 | KEMET | C1206C224J1RECAUTO | 80-C1206C224J1RECAUT |  | Analogmodul
C23 | 10n | Capacitor_SMD:C_1206_3216Metric | 1 | Murata Electronics | GRT3195C2A103JA02D | 81-GRT3195C2A103JA2D |  | Analogmodul
HS1 | ICK 20 L | SamacSys_Parts:Heatsink ICK 20 L | 1 |  |  |  |  | Analogmodul
IC1 | SI8261BAD-C-ISR | SamacSys_Parts:SOIC127P1150X265-6N | 1 | Skyworks | SI8261BAD-C-ISR | 634-SI8261BAD-C-ISR |  | Analogmodul
IC2 | SI8261BAD-C-ISR | SamacSys_Parts:SOIC127P1150X265-6N | 1 | Skyworks | SI8261BAD-C-ISR | 634-SI8261BAD-C-ISR |  | Analogmodul
IC3 | SI8261BAD-C-ISR | SamacSys_Parts:SOIC127P1150X265-6N | 1 | Skyworks | SI8261BAD-C-ISR | 634-SI8261BAD-C-ISR |  | Analogmodul
IC4 | SI8261BAD-C-ISR | SamacSys_Parts:SOIC127P1150X265-6N | 1 | Skyworks | SI8261BAD-C-ISR | 634-SI8261BAD-C-ISR |  | Analogmodul
IC5 | TPS259621DDAR | SamacSys_Parts:SOIC127P600X170-9N | 1 | Texas Instruments | TPS259621DDAR | 595-TPS259621DDAR |  | Analogmodul
IC6 | L78M10ABDT-TR | SamacSys_Parts:TO228P972X240-3N | 1 | STMicroelectronics | L78M10ABDT-TR | 511-L78M10ABDT-TR |  | Analogmodul
IC7 | TPS259621DDAR | SamacSys_Parts:SOIC127P600X170-9N | 1 | Texas Instruments | TPS259621DDAR | 595-TPS259621DDAR |  | Analogmodul
IC8 | MAX22531AAP+ | SamacSys_Parts:SOP65P778X199-20N | 1 | Analog Devices | MAX22531AAP+ | 700-MAX22531AAP+ |  | Analogmodul
IC9 | TS924IPT | SamacSys_Parts:SOP65P640X120-14N | 1 | STMicroelectronics | TS924IPT | 511-TS924IP |  | Analogmodul
J1 | 39502-1004 | SamacSys_Parts:SHDRRA4W80P0X350_1X4_1540X920X730P | 1 | Molex | 39502-1004 | 538-39502-1004 |  | Analogmodul
J3 | 658801103040 | SamacSys_Parts:658801103040 | 1 | Wurth Elektronik | 658801103040 | 710-658801103040 |  | Analogmodul
J4 | 39502-1008 | SamacSys_Parts:SHDRRA8W80P0X350_1X8_2940X920X690P | 1 | Molex | 39502-1008 | 538-39502-1008 |  | Analogmodul
J6 | 658855603040 | SamacSys_Parts:658855603040 | 1 | Wurth Elektronik | 658855603040 | 710-658855603040 |  | Analogmodul
JP1 | SolderJumper_2_Bridged | Jumper:SolderJumper-2_P1.3mm_Bridged2Bar_Pad1.0x1.5mm | 1 |  |  |  | Von Bauteilliste ausgeschlossen | Analogmodul
LED1 | 156120GS75000 | SamacSys_Parts:LEDM3216X130N | 1 | Wurth Elektronik | 156120GS75000 | 710-156120GS75000 |  | Analogmodul
LED2 | 156120RS75000 | SamacSys_Parts:LEDM3216X130N | 1 | Wurth Elektronik | 156120RS75000 | 710-156120RS75000 |  | Analogmodul
LED3 | 156120GS75000 | SamacSys_Parts:LEDM3216X130N | 1 | Wurth Elektronik | 156120GS75000 | 710-156120GS75000 |  | Analogmodul
LED4 | 156120GS75000 | SamacSys_Parts:LEDM3216X130N | 1 | Wurth Elektronik | 156120GS75000 | 710-156120GS75000 |  | Analogmodul
LED5 | 156120GS75000 | SamacSys_Parts:LEDM3216X130N | 1 | Wurth Elektronik | 156120GS75000 | 710-156120GS75000 |  | Analogmodul
LED6 | 156120GS75000 | SamacSys_Parts:LEDM3216X130N | 1 | Wurth Elektronik | 156120GS75000 | 710-156120GS75000 |  | Analogmodul
Q1 | 2N7002K | SamacSys_Parts:SOT95P240X120-3N | 1 | onsemi | 2N7002K | 512-2N7002K |  | Analogmodul
R1 | 100 | Resistor_SMD:R_1206_3216Metric | 1 | YAGEO | AC1206FR-07100RL | 603-AC1206FR-07100RL |  | Analogmodul
R2 | 100 | Resistor_SMD:R_1206_3216Metric | 1 | YAGEO | AC1206FR-07100RL | 603-AC1206FR-07100RL |  | Analogmodul
R3 | 100 | Resistor_SMD:R_1206_3216Metric | 1 | YAGEO | AC1206FR-07100RL | 603-AC1206FR-07100RL |  | Analogmodul
R4 | 100 | Resistor_SMD:R_1206_3216Metric | 1 | YAGEO | AC1206FR-07100RL | 603-AC1206FR-07100RL |  | Analogmodul
R5 | 6,2k | Resistor_SMD:R_1206_3216Metric | 1 | YAGEO | AC1206FR-076K2L | 603-AC1206FR-076K2L |  | Analogmodul
R6 | 4,7k | Resistor_SMD:R_1206_3216Metric | 1 | YAGEO | AC1206FR-07100RL | 603-AC1206FR-07100RL |  | Analogmodul
R7 | 4,7k | Resistor_SMD:R_1206_3216Metric | 1 | YAGEO | AC1206FR-07100RL | 603-AC1206FR-07100RL |  | Analogmodul
R8 | 10k | Resistor_SMD:R_1206_3216Metric | 1 | YAGEO | AC1206FR-07100RL | 603-AC1206FR-07100RL |  | Analogmodul
R9 | 100 | Resistor_SMD:R_1206_3216Metric | 1 | YAGEO | AC1206FR-07100RL | 603-AC1206FR-07100RL |  | Analogmodul
R10 | 6,2k | Resistor_SMD:R_1206_3216Metric | 1 | YAGEO | AC1206FR-076K2L | 603-AC1206FR-076K2L |  | Analogmodul
R11 | 6,2k | Resistor_SMD:R_1206_3216Metric | 1 | YAGEO | AC1206FR-076K2L | 603-AC1206FR-076K2L |  | Analogmodul
R12 | 6,2k | Resistor_SMD:R_1206_3216Metric | 1 | YAGEO | AC1206FR-076K2L | 603-AC1206FR-076K2L |  | Analogmodul
R13 | 6,2k | Resistor_SMD:R_1206_3216Metric | 1 | YAGEO | AC1206FR-076K2L | 603-AC1206FR-076K2L |  | Analogmodul
R14 | 6,2k | Resistor_SMD:R_1206_3216Metric | 1 | YAGEO | AC1206FR-076K2L | 603-AC1206FR-076K2L |  | Analogmodul
R16 | 8,2k | Resistor_SMD:R_1206_3216Metric | 1 | TE Connectivity / Holsworthy | CRGCQ1206F8K2 | 279-CRGCQ1206F8K2 |  | Analogmodul
R17 | 1,8k | Resistor_SMD:R_1206_3216Metric | 1 | Vishay / Dale | CRCW12061K80FKEAC | 71-CRCW12061K80FKEAC |  | Analogmodul
R18 | 8,2k | Resistor_SMD:R_1206_3216Metric | 1 | TE Connectivity / Holsworthy | CRGCQ1206F8K2 | 279-CRGCQ1206F8K2 |  | Analogmodul
R19 | 1,8k | Resistor_SMD:R_1206_3216Metric | 1 | Vishay / Dale | CRCW12061K80FKEAC | 71-CRCW12061K80FKEAC |  | Analogmodul
R20 | 8,2k | Resistor_SMD:R_1206_3216Metric | 1 | TE Connectivity / Holsworthy | CRGCQ1206F8K2 | 279-CRGCQ1206F8K2 |  | Analogmodul
R21 | 1,8k | Resistor_SMD:R_1206_3216Metric | 1 | Vishay / Dale | CRCW12061K80FKEAC | 71-CRCW12061K80FKEAC |  | Analogmodul
R22 | 8,2k | Resistor_SMD:R_1206_3216Metric | 1 | TE Connectivity / Holsworthy | CRGCQ1206F8K2 | 279-CRGCQ1206F8K2 |  | Analogmodul
R23 | 1,8k | Resistor_SMD:R_1206_3216Metric | 1 | Vishay / Dale | CRCW12061K80FKEAC | 71-CRCW12061K80FKEAC |  | Analogmodul
R27 | 470 | Resistor_SMD:R_1206_3216Metric | 1 | TE Connectivity / Holsworthy | CRGCQ1206F8K2 | 279-CRGCQ1206F8K2 |  | Analogmodul
R28 | 470 | Resistor_SMD:R_1206_3216Metric | 1 | TE Connectivity / Holsworthy | CRGCQ1206F8K2 | 279-CRGCQ1206F8K2 |  | Analogmodul
R29 | 470 | Resistor_SMD:R_1206_3216Metric | 1 | TE Connectivity / Holsworthy | CRGCQ1206F8K2 | 279-CRGCQ1206F8K2 |  | Analogmodul
R30 | 470 | Resistor_SMD:R_1206_3216Metric | 1 | TE Connectivity / Holsworthy | CRGCQ1206F8K2 | 279-CRGCQ1206F8K2 |  | Analogmodul
Z1 | SZMMSZ4679T1G | SamacSys_Parts:SOD3716X135N | 1 | onsemi | SZMMSZ4679T1G | 863-SZMMSZ4679T1G |  | Analogmodul
Z2 | SZMMSZ4679T1G | SamacSys_Parts:SOD3716X135N | 1 | onsemi | SZMMSZ4679T1G | 863-SZMMSZ4679T1G |  | Analogmodul
Z3 | SZMMSZ4679T1G | SamacSys_Parts:SOD3716X135N | 1 | onsemi | SZMMSZ4679T1G | 863-SZMMSZ4679T1G |  | Analogmodul
Z4 | SZMMSZ4679T1G | SamacSys_Parts:SOD3716X135N | 1 | onsemi | SZMMSZ4679T1G | 863-SZMMSZ4679T1G |  | Analogmodul

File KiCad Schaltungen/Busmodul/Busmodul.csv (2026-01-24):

Reference | Value | Footprint | Qty | Manufacturer_Name | Manufacturer_Part_Number | Mouser Part Number | Exclude from BOM | Projekt
C1 | 100n | Capacitor_SMD:C_1206_3216Metric | 1 |  |  |  |  | Busmodul
C2 | 100n | Capacitor_SMD:C_1206_3216Metric | 1 |  |  |  |  | Busmodul
C3 | 100n | Capacitor_SMD:C_1206_3216Metric | 1 |  |  |  |  | Busmodul
C4 | 100n | Capacitor_SMD:C_1206_3216Metric | 1 |  |  |  |  | Busmodul
C5 | 100n | Capacitor_SMD:C_1206_3216Metric | 1 |  |  |  |  | Busmodul
C6 | 100n | Capacitor_SMD:C_1206_3216Metric | 1 |  |  |  |  | Busmodul
C7 | 2,2u | Capacitor_SMD:C_1206_3216Metric | 1 |  |  |  |  | Busmodul
C8 | 1u | Capacitor_SMD:C_1206_3216Metric | 1 |  |  |  |  | Busmodul
IC1 | ISO1540DR | SamacSys_Parts:SOIC127P600X175-8N | 1 | Texas Instruments | ISO1540DR | 595-ISO1540DR |  | Busmodul
IC2 | ISO7721FDR | SamacSys_Parts:SOIC127P600X175-8N | 1 | Texas Instruments | ISO7721FDR | 595-ISO7721FDR |  | Busmodul
IC3 | ISO6741FQDWRQ1 | SamacSys_Parts:SOIC127P1030X265-16N | 1 | Texas Instruments | ISO6741FQDWRQ1 | 595-ISO6741FQDWRQ1 |  | Busmodul
IC4 | TLV76133DCYR | SamacSys_Parts:SOT230P700X180-4N | 1 | Texas Instruments | TLV76133DCYR | 595-TLV76133DCYR |  | Busmodul
J1 | 39502-1008 | SamacSys_Parts:SHDRRA8W80P0X350_1X8_2940X920X690P | 1 | Molex | 39502-1008 | 538-39502-1008 |  | Busmodul
J2 | 39502-1008 | SamacSys_Parts:SHDRRA8W80P0X350_1X8_2940X920X690P | 1 | Molex | 39502-1008 | 538-39502-1008 |  | Busmodul
J3 | 658801103040 | SamacSys_Parts:658801103040 | 1 | Wurth Elektronik | 658801103040 | 710-658801103040 |  | Busmodul
J4 | 658855603040 | SamacSys_Parts:658855603040 | 1 | Wurth Elektronik | 658855603040 | 710-658855603040 |  | Busmodul
LED1 | 156120GS75000 | SamacSys_Parts:156120GS75000 | 1 | Wurth Elektronik | 156120GS75000 | 710-156120GS75000 |  | Busmodul
Q1 | 2N7002K | SOT95P240X120-3N | 1 | onsemi | 2N7002K | 512-2N7002K |  | Busmodul
Q2 | BSS223PWH6327XTSA1 | SOT65P210X100-3N | 1 | Infineon | BSS223PWH6327XTSA1 | 726-BSS223PWH6327XTS |  | Busmodul
Q3 | BSS223PWH6327XTSA1 | SOT65P210X100-3N | 1 | Infineon | BSS223PWH6327XTSA1 | 726-BSS223PWH6327XTS |  | Busmodul
Q4 | 2N7002K | SOT95P240X120-3N | 1 | onsemi | 2N7002K | 512-2N7002K |  | Busmodul
Q5 | BSS223PWH6327XTSA1 | SOT65P210X100-3N | 1 | Infineon | BSS223PWH6327XTSA1 | 726-BSS223PWH6327XTS |  | Busmodul
Q6 | 2N7002K | SOT95P240X120-3N | 1 | onsemi | 2N7002K | 512-2N7002K |  | Busmodul
R1 | 470 | Resistor_SMD:R_1206_3216Metric | 1 |  |  |  |  | Busmodul
R2 | 1k | Resistor_SMD:R_1206_3216Metric | 1 |  |  |  |  | Busmodul
R3 | 1k | Resistor_SMD:R_1206_3216Metric | 1 |  |  |  |  | Busmodul
R4 | 1k | Resistor_SMD:R_1206_3216Metric | 1 |  |  |  |  | Busmodul
R5 | 1k | Resistor_SMD:R_1206_3216Metric | 1 |  |  |  |  | Busmodul
R6 | 10k | Resistor_SMD:R_1206_3216Metric | 1 |  |  |  |  | Busmodul
R7 | 10k | Resistor_SMD:R_1206_3216Metric | 1 |  |  |  |  | Busmodul
R8 | 10k | Resistor_SMD:R_1206_3216Metric | 1 |  |  |  |  | Busmodul
S1 | DS02C-254-1L-03BE | DS02C2541L03BE | 1 | Same Sky | DS02C-254-1L-03BE | 490-DS02C-254-1L03BE |  | Busmodul

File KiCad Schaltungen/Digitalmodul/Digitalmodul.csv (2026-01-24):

Reference | Value | Footprint | Qty | Manufacturer_Name | Manufacturer_Part_Number | Mouser Part Number | Exclude from BOM | Projekt
C1 | 100n | Capacitor_SMD:C_1206_3216Metric | 1 |  |  |  |  | Digitalmodul
C2 | 470n | Capacitor_SMD:C_1206_3216Metric | 1 |  |  |  |  | Digitalmodul
C3 | 330n | Capacitor_SMD:C_1206_3216Metric | 1 |  |  |  |  | Digitalmodul
C4 | 100n | Capacitor_SMD:C_1206_3216Metric | 1 |  |  |  |  | Digitalmodul
D9 | SS24FL | SamacSys_Parts:SODFL3617X108N | 1 | onsemi | SS24FL | 512-SS24FL |  | Digitalmodul
D10 | SS24FL | SamacSys_Parts:SODFL3617X108N | 1 | onsemi | SS24FL | 512-SS24FL |  | Digitalmodul
D11 | SS24FL | SamacSys_Parts:SODFL3617X108N | 1 | onsemi | SS24FL | 512-SS24FL |  | Digitalmodul
D12 | SS24FL | SamacSys_Parts:SODFL3617X108N | 1 | onsemi | SS24FL | 512-SS24FL |  | Digitalmodul
D13 | SS24FL | SamacSys_Parts:SODFL3617X108N | 1 | onsemi | SS24FL | 512-SS24FL |  | Digitalmodul
D14 | SS24FL | SamacSys_Parts:SODFL3617X108N | 1 | onsemi | SS24FL | 512-SS24FL |  | Digitalmodul
D15 | SS24FL | SamacSys_Parts:SODFL3617X108N | 1 | onsemi | SS24FL | 512-SS24FL |  | Digitalmodul
D16 | SS24FL | SamacSys_Parts:SODFL3617X108N | 1 | onsemi | SS24FL | 512-SS24FL |  | Digitalmodul
D17 | 156120YS75000 | SamacSys_Parts:LEDC5017X140N | 1 | Wurth Elektronik | 156120YS75000 | 710-156120YS75000 |  | Digitalmodul
D18 | 156120YS75000 | SamacSys_Parts:LEDC5017X140N | 1 | Wurth Elektronik | 156120YS75000 | 710-156120YS75000 |  | Digitalmodul
D19 | 156120YS75000 | SamacSys_Parts:LEDC5017X140N | 1 | Wurth Elektronik | 156120YS75000 | 710-156120YS75000 |  | Digitalmodul
D20 | 156120YS75000 | SamacSys_Parts:LEDC5017X140N | 1 | Wurth Elektronik | 156120YS75000 | 710-156120YS75000 |  | Digitalmodul
D21 | 156120YS75000 | SamacSys_Parts:LEDC5017X140N | 1 | Wurth Elektronik | 156120YS75000 | 710-156120YS75000 |  | Digitalmodul
D22 | 156120YS75000 | SamacSys_Parts:LEDC5017X140N | 1 | Wurth Elektronik | 156120YS75000 | 710-156120YS75000 |  | Digitalmodul
D23 | 156120YS75000 | SamacSys_Parts:LEDC5017X140N | 1 | Wurth Elektronik | 156120YS75000 | 710-156120YS75000 |  | Digitalmodul
D24 | 156120YS75000 | SamacSys_Parts:LEDC5017X140N | 1 | Wurth Elektronik | 156120YS75000 | 710-156120YS75000 |  | Digitalmodul
D25 | 156120YS75000 | SamacSys_Parts:LEDC5017X140N | 1 | Wurth Elektronik | 156120YS75000 | 710-156120YS75000 |  | Digitalmodul
D26 | 156120YS75000 | SamacSys_Parts:LEDC5017X140N | 1 | Wurth Elektronik | 156120YS75000 | 710-156120YS75000 |  | Digitalmodul
D27 | 156120YS75000 | SamacSys_Parts:LEDC5017X140N | 1 | Wurth Elektronik | 156120YS75000 | 710-156120YS75000 |  | Digitalmodul
D28 | 156120YS75000 | SamacSys_Parts:LEDC5017X140N | 1 | Wurth Elektronik | 156120YS75000 | 710-156120YS75000 |  | Digitalmodul
IC1 | ISO1I813T | SamacSys_Parts:SOP50P810X110-48N | 1 | Infineon | ISO1I813T | 726-ISO1I813T |  | Digitalmodul
IC2 | ISO1H816G | SamacSys_Parts:SOP65P1420X350-37N | 1 | Infineon | ISO1H816G | 726-ISO1H816G |  | Digitalmodul
J1 | 39502-1002 | SamacSys_Parts:SHDR2W80P0X350_1X2_840X920X690P | 1 | Molex | 39502-1002 | 538-39502-1002 |  | Digitalmodul
J3 | 39502-1004 | SamacSys_Parts:SHDRRA4W80P0X350_1X4_1540X920X730P | 1 | Molex | 39502-1004 | 538-39502-1004 |  | Digitalmodul
J4 | 658855603040 | SamacSys_Parts:658855603040 | 1 | Wurth Elektronik | 658855603040 | 710-658855603040 |  | Digitalmodul
J5 | 39502-1004 | SamacSys_Parts:SHDRRA4W80P0X350_1X4_1540X920X730P | 1 | Molex | 39502-1004 | 538-39502-1004 |  | Digitalmodul
J6 | 39502-1004 | SamacSys_Parts:SHDRRA4W80P0X350_1X4_1540X920X730P | 1 | Molex | 39502-1004 | 538-39502-1004 |  | Digitalmodul
J7 | 658801103040 | SamacSys_Parts:658801103040 | 1 | Wurth Elektronik | 658801103040 | 710-658801103040 |  | Digitalmodul
LED1 | 156120GS75000 | SamacSys_Parts:LEDC5017X140N | 1 | Wurth Elektronik | 156120GS75000 | 710-156120GS75000 |  | Digitalmodul
LED2 | 156120RS75000 | SamacSys_Parts:LEDC5017X140N | 1 | Wurth Elektronik | 156120RS75000 | 710-156120RS75000 |  | Digitalmodul
LED3 | 156120GS75000 | SamacSys_Parts:LEDC5017X140N | 1 | Wurth Elektronik | 156120GS75000 | 710-156120GS75000 |  | Digitalmodul
Q1 | FQD8P10TM | SamacSys_Parts:DPAK3-CASE-369AS | 1 | onsemi | FQD8P10TM | 512-FQD8P10TM |  | Digitalmodul
R1 | 6,2k | Resistor_SMD:R_1206_3216Metric | 1 | YAGEO | AC1206FR-076K2L | 603-AC1206FR-076K2L |  | Digitalmodul
R2 | 2k | Resistor_SMD:R_1206_3216Metric | 1 | YAGEO | AC1206FR-076K2L | 603-AC1206FR-076K2L |  | Digitalmodul
R3 | 12k | Resistor_SMD:R_1206_3216Metric | 1 | YAGEO | AC1206FR-076K2L | 603-AC1206FR-076K2L |  | Digitalmodul
R4 | 2k | Resistor_SMD:R_1206_3216Metric | 1 | YAGEO | AC1206FR-076K2L | 603-AC1206FR-076K2L |  | Digitalmodul
R5 | 22k | Resistor_SMD:R_1206_3216Metric | 1 | YAGEO | RT1206FRD0722KL | 603-RT1206FRD0722KL |  | Digitalmodul
R6 | 12k | Resistor_SMD:R_1206_3216Metric | 1 | YAGEO | AC1206FR-076K2L | 603-AC1206FR-076K2L |  | Digitalmodul
R7 | 2k | Resistor_SMD:R_1206_3216Metric | 1 | YAGEO | AC1206FR-076K2L | 603-AC1206FR-076K2L |  | Digitalmodul
R8 | 12k | Resistor_SMD:R_1206_3216Metric | 1 | YAGEO | AC1206FR-076K2L | 603-AC1206FR-076K2L |  | Digitalmodul
R9 | 2k | Resistor_SMD:R_1206_3216Metric | 1 | YAGEO | AC1206FR-076K2L | 603-AC1206FR-076K2L |  | Digitalmodul
R10 | 12k | Resistor_SMD:R_1206_3216Metric | 1 | YAGEO | AC1206FR-076K2L | 603-AC1206FR-076K2L |  | Digitalmodul
R11 | 40k | Resistor_SMD:R_1206_3216Metric | 1 | YAGEO | AC1206FR-076K2L | 603-AC1206FR-076K2L |  | Digitalmodul
R12 | 330k | Resistor_SMD:R_1206_3216Metric | 1 | YAGEO | AC1206FR-076K2L | 603-AC1206FR-076K2L |  | Digitalmodul
R13 | 2k | Resistor_SMD:R_1206_3216Metric | 1 | YAGEO | AC1206FR-076K2L | 603-AC1206FR-076K2L |  | Digitalmodul
R14 | 12k | Resistor_SMD:R_1206_3216Metric | 1 | YAGEO | AC1206FR-076K2L | 603-AC1206FR-076K2L |  | Digitalmodul
R15 | 2k | Resistor_SMD:R_1206_3216Metric | 1 | YAGEO | AC1206FR-076K2L | 603-AC1206FR-076K2L |  | Digitalmodul
R16 | 12k | Resistor_SMD:R_1206_3216Metric | 1 | YAGEO | AC1206FR-076K2L | 603-AC1206FR-076K2L |  | Digitalmodul
R17 | 2k | Resistor_SMD:R_1206_3216Metric | 1 | YAGEO | AC1206FR-076K2L | 603-AC1206FR-076K2L |  | Digitalmodul
R18 | 12k | Resistor_SMD:R_1206_3216Metric | 1 | YAGEO | AC1206FR-076K2L | 603-AC1206FR-076K2L |  | Digitalmodul
R19 | 2k | Resistor_SMD:R_1206_3216Metric | 1 | YAGEO | AC1206FR-076K2L | 603-AC1206FR-076K2L |  | Digitalmodul
R20 | 12k | Resistor_SMD:R_1206_3216Metric | 1 | YAGEO | AC1206FR-076K2L | 603-AC1206FR-076K2L |  | Digitalmodul
R21 | 100 | Resistor_SMD:R_1206_3216Metric | 1 | YAGEO | AC1206FR-076K2L | 603-AC1206FR-076K2L |  | Digitalmodul
R22 | 100k | Resistor_SMD:R_1206_3216Metric | 1 | YAGEO | RT1206FRD0722KL | 603-RT1206FRD0722KL |  | Digitalmodul
R23 | 100k | Resistor_SMD:R_1206_3216Metric | 1 | YAGEO | RT1206FRD0722KL | 603-RT1206FRD0722KL |  | Digitalmodul
R24 | 100k | Resistor_SMD:R_1206_3216Metric | 1 | YAGEO | RT1206FRD0722KL | 603-RT1206FRD0722KL |  | Digitalmodul
R25 | 100k | Resistor_SMD:R_1206_3216Metric | 1 | YAGEO | RT1206FRD0722KL | 603-RT1206FRD0722KL |  | Digitalmodul
R26 | 100k | Resistor_SMD:R_1206_3216Metric | 1 | YAGEO | RT1206FRD0722KL | 603-RT1206FRD0722KL |  | Digitalmodul
R27 | 100k | Resistor_SMD:R_1206_3216Metric | 1 | YAGEO | RT1206FRD0722KL | 603-RT1206FRD0722KL |  | Digitalmodul
R28 | 100k | Resistor_SMD:R_1206_3216Metric | 1 | YAGEO | RT1206FRD0722KL | 603-RT1206FRD0722KL |  | Digitalmodul
R29 | 100k | Resistor_SMD:R_1206_3216Metric | 1 | YAGEO | RT1206FRD0722KL | 603-RT1206FRD0722KL |  | Digitalmodul
R38 | 12k | Resistor_SMD:R_1206_3216Metric | 1 | YAGEO | AC1206FR-076K2L | 603-AC1206FR-076K2L |  | Digitalmodul
R39 | 12k | Resistor_SMD:R_1206_3216Metric | 1 | YAGEO | AC1206FR-076K2L | 603-AC1206FR-076K2L |  | Digitalmodul
R40 | 12k | Resistor_SMD:R_1206_3216Metric | 1 | YAGEO | AC1206FR-076K2L | 603-AC1206FR-076K2L |  | Digitalmodul
R41 | 12k | Resistor_SMD:R_1206_3216Metric | 1 | YAGEO | AC1206FR-076K2L | 603-AC1206FR-076K2L |  | Digitalmodul
R42 | 4,7k | Resistor_SMD:R_1206_3216Metric | 1 | YAGEO | AC1206FR-076K2L | 603-AC1206FR-076K2L |  | Digitalmodul
R43 | 2k | Resistor_SMD:R_1206_3216Metric | 1 | YAGEO | AC1206FR-076K2L | 603-AC1206FR-076K2L |  | Digitalmodul
TP1 | TestPoint | TestPoint:TestPoint_Pad_D2.0mm | 1 |  |  |  |  | Digitalmodul

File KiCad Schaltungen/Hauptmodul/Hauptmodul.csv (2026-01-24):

Reference | Value | Footprint | Qty | Manufacturer_Name | Manufacturer_Part_Number | Mouser Part Number | Exclude from BOM | Projekt
C1 | 330n | Capacitor_SMD:C_1206_3216Metric | 1 | Samsung Electro-Mechanics | CL31A106KBHNNNE | 187-CL31A106KBHNNNE |  | Hauptmodul
C2 | 100n | Capacitor_SMD:C_1206_3216Metric | 1 | Samsung Electro-Mechanics | CL31A106KBHNNNE | 187-CL31A106KBHNNNE |  | Hauptmodul
C3 | 10u | Capacitor_SMD:C_1206_3216Metric | 1 | Samsung Electro-Mechanics | CL31A106KBHNNNE | 187-CL31A106KBHNNNE |  | Hauptmodul
C4 | 100n | Capacitor_SMD:C_1206_3216Metric | 1 | Samsung Electro-Mechanics | CL31A106KBHNNNE | 187-CL31A106KBHNNNE |  | Hauptmodul
C5 | 100n | Capacitor_SMD:C_1206_3216Metric | 1 | Samsung Electro-Mechanics | CL31A106KBHNNNE | 187-CL31A106KBHNNNE |  | Hauptmodul
C6 | 100n | Capacitor_SMD:C_1206_3216Metric | 1 | Samsung Electro-Mechanics | CL31A106KBHNNNE | 187-CL31A106KBHNNNE |  | Hauptmodul
C7 | 100n | Capacitor_SMD:C_1206_3216Metric | 1 | Samsung Electro-Mechanics | CL31A106KBHNNNE | 187-CL31A106KBHNNNE |  | Hauptmodul
C8 | 100n | Capacitor_SMD:C_1206_3216Metric | 1 | Samsung Electro-Mechanics | CL31A106KBHNNNE | 187-CL31A106KBHNNNE |  | Hauptmodul
C9 | 100n | Capacitor_SMD:C_1206_3216Metric | 1 | Samsung Electro-Mechanics | CL31A106KBHNNNE | 187-CL31A106KBHNNNE |  | Hauptmodul
D1 | SD1206S040S1R0 | SamacSys_Parts:DIOC3419X116N | 1 | Kyocera AVX | SD1206S040S1R0 | 581-SD1206S040S1R0 |  | Hauptmodul
D3 | PESD1CAN,215 | SamacSys_Parts:SOT95P230X110-3N | 1 | Nexperia | PESD1CAN,215 | 771-PESD1CAN-T/R |  | Hauptmodul
H1 | MountingHole | MountingHole:MountingHole_3.2mm_M3 | 1 |  |  |  | Von Bauteilliste ausgeschlossen | Hauptmodul
H2 | MountingHole | MountingHole:MountingHole_3.2mm_M3 | 1 |  |  |  | Von Bauteilliste ausgeschlossen | Hauptmodul
IC1 | SN65HVD230QDRG4Q1 | SamacSys_Parts:SOIC127P600X175-8N | 1 | Texas Instruments | SN65HVD230QDRG4Q1 | 595-S65HVD230QDRG4Q1 |  | Hauptmodul
IC2 | L78L05ACZ | SamacSys_Parts:L78L05ACZ | 1 | STMicroelectronics | L78L05ACZ | 511-L78L05ACZ |  | Hauptmodul
IC3 | VOFD341A-X008T | SamacSys_Parts:SOIC127P1150X378-6N | 1 | Vishay | VOFD341A-X008T | 625-VOFD341A-X008T |  | Hauptmodul
IC4 | ISO7721FDR | SamacSys_Parts:SOIC127P600X175-8N | 1 | Texas Instruments | ISO7721FDR | 595-ISO7721FDR |  | Hauptmodul
IC5 | ESP32-DEVKITC-VE | SamacSys_Parts:ESP32DEVKITCVE | 1 | Espressif Systems | ESP32-DEVKITC-VE | 356-ESP32-DEVKTC32VE |  | Hauptmodul
IC6 | MCP602-E_SN | SamacSys_Parts:SOIC127P600X175-8N | 1 | Microchip | MCP602-E/SN | 579-MCP602-E/SN |  | Hauptmodul
IC7 | MCP23017T-E_SO | SamacSys_Parts:SOIC127P1030X265-28N | 1 | Microchip | MCP23017T-E/SO | 579-MCP23017T-E/SO |  | Hauptmodul
IC9 | AD22100KTZ | SamacSys_Parts:TO128P419X483X533-3P | 1 | Analog Devices | AD22100KTZ | 584-AD22100KTZ |  | Hauptmodul
J1 | 43860-5025 | SamacSys_Parts:438605025 | 1 | Molex | 43860-5025 | 538-43860-5025 |  | Hauptmodul
J2 | 39502-1004 | SamacSys_Parts:SHDRRA4W80P0X350_1X4_1540X920X730P | 1 | Molex | 39502-1004 | 538-39502-1004 |  | Hauptmodul
J3 | 39502-1002 | SamacSys_Parts:SHDR2W80P0X350_1X2_840X920X690P | 1 | Molex | 39502-1002 | 538-39502-1002 |  | Hauptmodul
J4 | Conn_01x19_Socket | Connector_PinSocket_2.54mm:PinSocket_1x19_P2.54mm_Vertical | 1 |  |  |  |  | Hauptmodul
J5 | Conn_01x19_Socket | Connector_PinSocket_2.54mm:PinSocket_1x19_P2.54mm_Vertical | 1 |  |  |  |  | Hauptmodul
J6 | B3B-XH-A_LF__SN_ | SamacSys_Parts:B3BXHALFSN | 1 | JST (JAPAN SOLDERLESS TERMINALS) | B3B-XH-A(LF)(SN) | 306-B3BXHALFSNP |  | Hauptmodul
J7 | 658855603040 | SamacSys_Parts:658855603040 | 1 | Wurth Elektronik | 658855603040 | 710-658855603040 |  | Hauptmodul
JP1 | SolderJumper_2_Open | Jumper:SolderJumper-2_P1.3mm_Open_Pad1.0x1.5mm | 1 |  |  |  | Von Bauteilliste ausgeschlossen | Hauptmodul
JP2 | SolderJumper_2_Open | Jumper:SolderJumper-2_P1.3mm_Open_Pad1.0x1.5mm | 1 |  |  |  | Von Bauteilliste ausgeschlossen | Hauptmodul
LED1 | 156120RS75000 | SamacSys_Parts:LEDM3216X130N | 1 | Wurth Elektronik | 156120RS75000 | 710-156120RS75000 |  | Hauptmodul
LED2 | 156120YS75000 | SamacSys_Parts:LEDC5017X140N | 1 | Wurth Elektronik | 156120YS75000 | 710-156120YS75000 |  | Hauptmodul
LED3 | 156120RS75000 | SamacSys_Parts:LEDM3216X130N | 1 | Wurth Elektronik | 156120RS75000 | 710-156120RS75000 |  | Hauptmodul
LED4 | 156120GS75000 | SamacSys_Parts:156120GS75000 | 1 | Wurth Elektronik | 156120GS75000 | 710-156120GS75000 |  | Hauptmodul
PS1 | RSH3-2405S_H2-R | SamacSys_Parts:RSH32405SH2R | 1 | RECOM Power | RSH3-2405S/H2-R | 919-RSH3-2405S/H2-R |  | Hauptmodul
Q1 | 2N7002K | SamacSys_Parts:SOT95P240X120-3N | 1 | onsemi | 2N7002K | 512-2N7002K |  | Hauptmodul
R1 | 10k | Resistor_SMD:R_1206_3216Metric | 1 | YAGEO | AC1206FR-076K2L | 603-AC1206FR-076K2L |  | Hauptmodul
R2 | 10k | Resistor_SMD:R_1206_3216Metric | 1 | YAGEO | RC1206FR-1310KL | 603-RC1206FR-1310KL |  | Hauptmodul
R3 | 6,2k | Resistor_SMD:R_1206_3216Metric | 1 | YAGEO | AC1206FR-076K2L | 603-AC1206FR-076K2L |  | Hauptmodul
R4 | 10k | Resistor_SMD:R_1206_3216Metric | 1 | YAGEO | AC1206FR-076K2L | 603-AC1206FR-076K2L |  | Hauptmodul
R5 | 1k | Resistor_SMD:R_1206_3216Metric | 1 |  |  |  |  | Hauptmodul
R6 | 1k | Resistor_SMD:R_1206_3216Metric | 1 |  |  |  |  | Hauptmodul
R7 | 470 | Resistor_SMD:R_1206_3216Metric | 1 | YAGEO | RC1206FR-0712KL | 603-RC1206FR-0712KL |  | Hauptmodul
R8 | 470 | Resistor_SMD:R_1206_3216Metric | 1 |  |  |  |  | Hauptmodul
R9 | 10k | Resistor_SMD:R_1206_3216Metric | 1 | YAGEO | RC1206FR-0712KL | 603-RC1206FR-0712KL |  | Hauptmodul
R10 | 470 | Resistor_SMD:R_1206_3216Metric | 1 |  |  |  |  | Hauptmodul
R11 | 6,2k | Resistor_SMD:R_1206_3216Metric | 1 | YAGEO | AC1206FR-076K2L | 603-AC1206FR-076K2L |  | Hauptmodul
R12 | 12k | Resistor_SMD:R_1206_3216Metric | 1 | YAGEO | RC1206FR-0712KL | 603-RC1206FR-0712KL |  | Hauptmodul
R13 | 470 | Resistor_SMD:R_1206_3216Metric | 1 | YAGEO | AC1206FR-076K2L | 603-AC1206FR-076K2L |  | Hauptmodul
R14 | 2,2k | Resistor_SMD:R_1206_3216Metric | 1 | YAGEO | AC1206FR-076K2L | 603-AC1206FR-076K2L |  | Hauptmodul
R15 | 2,2k | Resistor_SMD:R_1206_3216Metric | 1 | YAGEO | AC1206FR-076K2L | 603-AC1206FR-076K2L |  | Hauptmodul
VR1 | TC33X-2-503E | SamacSys_Parts:TC33X2503E | 1 | Bourns | TC33X-2-503E | 652-TC33X-2-503E |  | Hauptmodul

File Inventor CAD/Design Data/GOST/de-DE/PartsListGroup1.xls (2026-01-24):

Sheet: Лист 1
Инв. № подл |  |  |  | Подп. и дата | Взам. инв. № | Инв. № дубл. |  |  | Подп. и дата
Формат | Зона | Поз. | Обозначение |  |  |  | Наименование |  |  |  |  |  | Кол. на исполнение
 |  |  |  |  |  |  |  |  |  |  |  | Лит.
 |  |  |  |  |  |  |  |  |  |  |  | Код
 |  |  |  |  |  |  |  | Изм. | Лист | № докум | Подпись |  | Дата
 |  |  |  |  |  |  |  | Разраб.
 |  |  |  |  |  |  |  | Пров.
 |  |  |  |  |  |  |  | Н.контр
 |  |  |  |  |  |  |  | Утв.
 |  |  |  |  |  |  |  |  |  |  |  |  |  | Копировал

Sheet: Лист 2
Инв. № подл |  |  |  | Подп. и дата | Взам. инв. № | Инв. № дубл. |  |  | Подп. и дата
Формат | Зона | Поз. | Обозначение |  |  |  | Наименование |  |  |  |  | Кол. на исполнение
 |  |  |  |  |  |  |  | Изм. | Лист | № докум. | Подп. | Дата
 |  |  |  |  |  |  |  |  |  |  |  |  | Копировал
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

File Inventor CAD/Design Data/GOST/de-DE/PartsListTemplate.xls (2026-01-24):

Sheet: Лист 1
 | Формат | Зона |  | Поз. |  | Обозначение |  |  |  | Наименование |  |  |  | Кол. | Приме-чание
Подп. и дата
Инв. № дубл.
Взам. инв. №
Подп. и дата
 | Изм. |  | Лист |  | № докум |  | Подпись | Дата
Инв. № подл | Разраб. |  |  |  |  |  |  |  |  |  | Литера |  | Лист |  |  | Листов
 | Пров.
 | Н.контр
 | Утв.
 |  |  |  |  |  |  |  |  | Копировал |  |  | Формат А4

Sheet: Лист 2
 | Формат | Зона |  | Поз. |  | Обозначение |  |  |  | Наименование |  | Кол. | Приме-чание
Подп. и дата
Инв. № дубл.
Взам. инв. №
Подп. и дата
Инв. № подл
 | Изм. |  | Лист |  | № докум. |  | Подп. |  | Дата
 |  |  |  |  |  |  |  | Копировал |  |  | Формат А4
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

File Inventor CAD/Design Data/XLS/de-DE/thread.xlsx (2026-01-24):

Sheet: Inch Tapping Threads
I Q X | Zoll-Blechschraubgewinde |  | Sort Order - 5 |  | External |  |  |  |  |  |  | Internal
 |  |  |  |  |  | Major Dia |  | Pitch Dia |  | Minor Dia |  |  | Minor Dia |  | Pitch Dia |  | Major Dia |  | Tap Drill
Size | Size Suffix | Thread Designation | Custom Thread Designation | TPI | Class | Max | Min | Max | Min | Max | Min | Class | Min | Max | Min | Max | Min | Max | Basic
0.0600 |  | 0-48 | 0-48 | 48 | 2B | 0.0600 | 0.0540 | 0.0480 | 0.0435 | 0.0360 | 0.0330
0.0730 |  | 1-42 | 1-42 | 42 | 2B | 0.0750 | 0.0690 | 0.0620 | 0.0575 | 0.0490 | 0.0460
0.0860 |  | 2-32 | 2-32 | 32 | 2B | 0.0880 | 0.0820 | 0.0760 | 0.0710 | 0.0640 | 0.0600
0.0990 |  | 3-28 | 3-28 | 28 | 2B | 0.1010 | 0.0950 | 0.0880 | 0.0830 | 0.0750 | 0.0710
0.1120 |  | 4-24 | 4-24 | 24 | 2B | 0.1140 | 0.1080 | 0.1000 | 0.0950 | 0.0860 | 0.0820
0.1250 |  | 5-20 | 5-20 | 20 | 2B | 0.1300 | 0.1230 | 0.1120 | 0.1065 | 0.0940 | 0.0900
0.1380 |  | 6-20 | 6-20 | 20 | 2B | 0.1390 | 0.1320 | 0.1215 | 0.1155 | 0.1040 | 0.0990
0.1510 |  | 7-19 | 7-19 | 19 | 2B | 0.1540 | 0.1470 | 0.1345 | 0.1280 | 0.1150 | 0.1090
0.1640 |  | 8-18 | 8-18 | 18 | 2B | 0.1660 | 0.1590 | 0.1440 | 0.1375 | 0.1220 | 0.1160
0.1900 |  | 10-16 | 10-16 | 16 | 2B | 0.1890 | 0.1820 | 0.1650 | 0.1585 | 0.1410 | 0.1350
0.2160 |  | 12-14 | 12-14 | 14 | 2B | 0.2150 | 0.2080 | 0.1895 | 0.1825 | 0.1640 | 0.1570
0.2420 |  | 14-14 | 14-14 | 14 | 2B | 0.2410 | 0.2340 | 0.2130 | 0.2060 | 0.1850 | 0.1780
0.2500 |  | 1/4-14 | 1/4-14 | 14 | 2B | 0.2460 | 0.2370 | 0.2190 | 0.2110 | 0.1920 | 0.1850
0.3125 |  | 5/16-12 | 5/16-12 | 12 | 2B | 0.3150 | 0.3060 | 0.2795 | 0.2710 | 0.2440 | 0.2360
0.3750 |  | 3/8-12 | 3/8-12 | 12 | 2B | 0.3800 | 0.3710 | 0.3445 | 0.3350 | 0.3090 | 0.2990
0.4375 |  | 7/16-10 | 7/16-10 | 10 | 2B | 0.4400 | 0.4290 | 0.3995 | 0.3890 | 0.3590 | 0.3490
0.5000 |  | 1/2-10 | 1/2-10 | 10 | 2B | 0.5040 | 0.4930 | 0.4635 | 0.4530 | 0.4230 | 0.4130

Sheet: Metric Forming Screw Threads
M P X | Metrisch geform. Schraubgewinde |  | Sort Order - 6 |  | External |  |  |  |  |  |  | Internal
 |  |  |  |  |  | Major Dia |  | Pitch Dia |  | Minor Dia |  |  | Minor Dia |  | Pitch Dia |  | Major Dia |  | Tap Drill
Size | Size Suffix | Thread Designation | Custom Thread Designation | Pitch | Class | Max | Min | Max | Min | Max | Min | Class | Min | Max | Min | Max | Min | Max | Basic
1.5 |  | 1.5x0.5 | 1.5x0.5 | 0.5 | 6g | 1.520 | 1.380 | 1.215 | 1.110 | 0.910 | 0.840
1.5 |  | ST1.5x0.5 | ST1.5x0.5 | 0.5 | 6g | 1.520 | 1.380 | 1.215 | 1.110 | 0.910 | 0.840
1.9 |  | 1.9x0.6 | 1.9x0.6 | 0.6 | 6g | 1.900 | 1.760 | 1.570 | 1.465 | 1.240 | 1.170
1.9 |  | ST1.9x0.6 | ST1.9x0.6 | 0.6 | 6g | 1.900 | 1.760 | 1.570 | 1.465 | 1.240 | 1.170
2.2 |  | 2.2x0.8 | 2.2x0.8 | 0.8 | 6g | 2.240 | 2.100 | 1.935 | 1.810 | 1.630 | 1.520
2.2 |  | ST2.2x0.8 | ST2.2x0.8 | 0.8 | 6g | 2.240 | 2.100 | 1.935 | 1.810 | 1.630 | 1.520
2.6 |  | 2.6x0.9 | 2.6x0.9 | 0.9 | 6g | 2.570 | 2.430 | 2.235 | 2.115 | 1.900 | 1.800
2.6 |  | ST2.6x0.9 | ST2.6x0.9 | 0.9 | 6g | 2.570 | 2.430 | 2.235 | 2.115 | 1.900 | 1.800
2.9 |  | 2.9x1 | 2.9x1 | 1 | 6g | 2.900 | 2.760 | 2.540 | 2.420 | 2.180 | 2.080
2.9 |  | 2.9x1.1 | 2.9x1.1 | 1.1 | 6g | 2.900 | 2.760 | 2.540 | 2.420 | 2.180 | 2.080
2.9 |  | ST2.9x1.1 | ST2.9x1.1 | 1.1 | 6g | 2.900 | 2.760 | 2.540 | 2.420 | 2.180 | 2.080
2.9 |  | 2.9x1.3 | 2.9x1.3 | 1.3 | 6g | 2.900 | 2.720 | 2.540 | 2.355 | 1.890 | 1.700
2.9 |  | 2.9x1.4 | 2.9x1.4 | 1.4 | 6g | 2.900 | 2.720 | 2.340 | 2.175 | 1.780 | 1.630
3.3 |  | 3.3x1.3 | 3.3x1.3 | 1.3 | 6g | 3.300 | 3.120 | 2.795 | 2.665 | 2.290 | 2.210
3.3 |  | ST3.3x1.3 | ST3.3x1.3 | 1.3 | 6g | 3.300 | 3.120 | 2.795 | 2.665 | 2.290 | 2.210
3.5 |  | 3.5x1.3 | 3.5x1.3 | 1.3 | 6g | 3.530 | 3.350 | 3.085 | 2.930 | 2.640 | 2.510
3.5 |  | ST3.5x1.3 | ST3.5x1.3 | 1.3 | 6g | 3.530 | 3.350 | 3.085 | 2.930 | 2.640 | 2.510
3.5 |  | 3.5x1.6 | 3.5x1.6 | 1.6 | 6g | 3.530 | 3.350 | 2.920 | 2.755 | 2.310 | 2.160
3.5 |  | 3.5x3.2 | 3.5x3.2 | 3.2 | 6g | 3.530 | 3.310 | 2.800 | 2.600 | 2.070 | 1.890
3.9 |  | 3.9x1.3 | 3.9x1.3 | 1.3 | 6g | 3.910 | 3.730 | 3.415 | 3.250 | 2.920 | 2.770
3.9 |  | ST3.9x1.3 | ST3.9x1.3 | 1.3 | 6g | 3.910 | 3.730 | 3.415 | 3.250 | 2.920 | 2.770
3.9 |  | 3.9x1.6 | 3.9x1.6 | 1.6 | 6g | 3.910 | 3.730 | 3.300 | 3.135 | 2.690 | 2.540
3.9 |  | 3.9x3.2 | 3.9x3.2 | 3.2 | 6g | 3.910 | 3.690 | 3.180 | 2.980 | 2.450 | 2.270
4.2 |  | 4.2x1.4 | 4.2x1.4 | 1.4 | 6g | 4.220 | 4.040 | 3.660 | 3.495 | 3.100 | 2.950
4.2 |  | ST4.2x1.4 | ST4.2x1.4 | 1.4 | 6g | 4.220 | 4.040 | 3.660 | 3.495 | 3.100 | 2.950
4.2 |  | 4.2x1.6 | 4.2x1.6 | 1.6 | 6g | 4.220 | 4.040 | 3.610 | 3.445 | 3.000 | 2.850
4.2 |  | 4.2x3.2 | 4.2x3.2 | 3.2 | 6g | 4.220 | 4.000 | 3.380 | 3.180 | 2.540 | 2.360
4.8 |  | 4.8x1.6 | 4.8x1.6 | 1.6 | 6g | 4.800 | 4.620 | 4.190 | 4.025 | 3.580 | 3.430
4.8 |  | ST4.8x1.6 | ST4.8x1.6 | 1.6 | 6g | 4.800 | 4.620 | 4.190 | 4.025 | 3.580 | 3.430
4.8 |  | 4.8x1.8 | 4.8x1.8 | 1.8 | 6g | 4.800 | 4.620 | 4.065 | 3.885 | 3.330 | 3.150
4.8 |  | 4.8x3.2 | 4.8x3.2 | 3.2 | 6g | 4.800 | 4.580 | 3.960 | 3.760 | 3.120 | 2.940
5.5 |  | 5.5x1.8 | 5.5x1.8 | 1.8 | 6g | 5.460 | 5.280 | 4.815 | 4.635 | 4.170 | 3.990
5.5 |  | ST5.5x1.8 | ST5.5x1.8 | 1.8 | 6g | 5.460 | 5.280 | 4.815 | 4.635 | 4.170 | 3.990
6.3 |  | 6.3x1.8 | 6.3x1.8 | 1.8 | 6g | 6.250 | 6.030 | 5.565 | 5.365 | 4.880 | 4.700
6.3 |  | ST6.3x1.8 | ST6.3x1.8 | 1.8 | 6g | 6.250 | 6.030 | 5.565 | 5.365 | 4.880 | 4.700
8.0 |  | 8x2.1 | 8x2.1 | 2.1 | 6g | 8.000 | 7.780 | 7.100 | 6.885 | 6.200 | 5.990
8.0 |  | ST8x2.1 | ST8x2.1 | 2.1 | 6g | 8.000 | 7.780 | 7.100 | 6.885 | 6.200 | 5.990
9.5 |  | 9.5x2.1 | 9.5x2.1 | 2.1 | 6g | 9.650 | 9.430 | 8.750 | 8.510 | 7.850 | 7.590
9.5 |  | ST9.5x2.1 | ST9.5x2.1 | 2.1 | 6g | 9.650 | 9.430 | 8.750 | 8.510 | 7.850 | 7.590

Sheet: ISO Pipe Threads
M Q | ISO-Rohrgewinde |  | Sort Order - 9 |  | External |  |  |  |  |  |  | Internal
 |  |  |  |  |  | Major Dia |  | Pitch Dia |  | Minor Dia |  |  | Minor Dia |  | Pitch Dia |  | Major Dia |  | Tap Drill | Thread Depth | Thread Runouts
Size | Size Suffix | Thread Designation | Custom Thread Designation | TPI | Class | Max | Min | Max | Min | Max | Min | Class | Min | Max | Min | Max | Min | Max | Basic
7.723 |  | G7.723x0.907 | G 1/16 | 28 | A | 7.723 | 7.509 | 7.142 | 7.035 | 6.561 |  |  | 6.561 | 6.834 | 7.142 | 7.249 | 7.723 |  | 1.5875 | 15.446 | 4.5000
7.723 |  | G7.723x0.907 | G 1/16 | 28 | B | 7.723 | 7.509 | 7.142 | 6.928 | 6.561
9.728 |  | G9.728x0.907 | G 1/8 | 28 | A | 9.728 | 9.514 | 9.147 | 9.040 | 8.566 |  |  | 8.566 | 8.848 | 9.147 | 9.254 | 9.728 |  | 3.1750 | 19.456 | 4.5000
9.728 |  | G9.728x0.907 | G 1/8 | 28 | B | 9.728 | 9.514 | 9.147 | 8.933 | 8.566
13.157 |  | G13.157x1.337 | G 1/4 | 19 | A | 13.157 | 12.907 | 12.301 | 12.176 | 11.445 |  |  | 11.445 | 11.89 | 12.301 | 12.426 | 13.157 |  | 6.3500 | 26.314 | 6.5000
13.157 |  | G13.157x1.337 | G 1/4 | 19 | B | 13.157 | 12.907 | 12.301 | 12.051 | 11.445
16.662 |  | G16.662x1.337 | G 3/8 | 19 | A | 16.662 | 16.412 | 15.806 | 15.681 | 14.950 |  |  | 14.95 | 15.395 | 15.806 | 15.931 | 16.662 |  | 9.5250 | 33.324 | 6.5000
16.662 |  | G16.662x1.337 | G 3/8 | 19 | B | 16.662 | 16.412 | 15.806 | 15.556 | 14.950
20.955 |  | G20.955x1.814 | G 1/2 | 14 | A | 20.955 | 20.671 | 19.793 | 19.651 | 18.631 |  |  | 18.631 | 19.172 | 19.793 | 19.935 | 20.955 |  | 12.7000 | 41.910 | 8.5000
20.955 |  | G20.955x1.814 | G 1/2 | 14 | B | 20.955 | 20.671 | 19.793 | 19.509 | 18.631
22.911 |  | G22.911x1.814 | G 5/8 | 14 | A | 22.911 | 22.627 | 21.749 | 21.607 | 20.587 |  |  | 20.587 | 21.128 | 21.749 | 21.891 | 22.911 |  |  | 45.822 | 8.5000
22.911 |  | G22.911x1.814 | G 5/8 | 14 | B | 22.911 | 22.627 | 21.749 | 21.465 | 20.587
26.441 |  | G26.441x1.814 | G 3/4 | 14 | A | 26.441 | 26.157 | 25.279 | 25.137 | 24.117 |  |  | 24.117 | 24.658 | 25.279 | 25.421 | 26.441 |  | 15.8750 | 52.882 | 8.5000
26.441 |  | G26.441x1.814 | G 3/4 | 14 | B | 26.441 | 26.157 | 25.279 | 24.995 | 24.117
30.201 |  | G30.201x1.814 | G 7/8 | 14 | A | 30.201 | 29.917 | 29.039 | 28.897 | 27.877 |  |  | 27.877 | 28.418 | 29.039 | 29.181 | 30.201 |  | 22.2250 | 60.402 | 8.5000
30.201 |  | G30.201x1.814 | G 7/8 | 14 | B | 30.201 | 29.917 | 29.039 | 28.755 | 27.877
33.249 |  | G33.249x2.309 | G 1 | 11 | A | 33.249 | 32.889 | 31.770 | 31.590 | 30.291 |  |  | 30.291 | 30.931 | 31.77 | 31.95 | 33.249 |  | 25.4000 | 66.498 | 10.0000
33.249 |  | G33.249x2.309 | G 1 | 11 | B | 33.249 | 32.889 | 31.770 | 31.410 | 30.291
37.897 |  | G37.897x2.309 | G 1 1/8 | 11 | A | 37.897 | 37.537 | 36.418 | 36.238 | 34.939 |  |  | 34.939 | 35.579 | 36.418 | 36.598 | 37.897 |  | 28.5750 | 75.794 | 10.0000
37.897 |  | G37.897x2.309 | G 1 1/8 | 11 | B | 37.897 | 37.537 | 36.418 | 36.058 | 34.939
41.910 |  | G41.91x2.309 | G 1 1/4 | 11 | A | 41.910 | 41.550 | 40.431 | 40.251 | 38.952 |  |  | 38.952 | 39.592 | 40.431 | 40.611 | 41.910 |  | 31.7500 | 83.820 | 10.0000
41.910 |  | G41.91x2.309 | G 1 1/4 | 11 | B | 41.910 | 41.550 | 40.431 | 40.071 | 38.952
47.803 |  | G47.803x2.309 | G 1 1/2 | 11 | A | 47.803 | 47.443 | 46.324 | 46.144 | 44.845 |  |  | 44.845 | 45.485 | 46.324 | 46.504 | 47.803 |  | 38.1000 | 95.606 | 10.0000
47.803 |  | G47.803x2.309 | G 1 1/2 | 11 | B | 47.803 | 47.443 | 46.324 | 45.964 | 44.845
53.746 |  | G53.746x2.309 | G 1 3/4 | 11 | A | 53.746 | 53.386 | 52.267 | 52.087 | 50.788 |  |  | 50.788 | 51.428 | 52.267 | 52.447 | 53.746 |  | 44.4500 | 107.492 | 10.0000
53.746 |  | G53.746x2.309 | G 1 3/4 | 11 | B | 53.746 | 53.386 | 52.267 | 51.907 | 50.788
59.614 |  | G59.614x2.309 | G 2 | 11 | A | 59.614 | 59.254 | 58.135 | 57.955 | 56.656 |  |  | 56.656 | 57.296 | 58.135 | 58.315 | 59.614 |  | 50.8000 | 119.228 | 10.0000
59.614 |  | G59.614x2.309 | G 2 | 11 | B | 59.614 | 59.254 | 58.135 | 57.775 | 56.656
65.710 |  | G65.71x2.309 | G 2 1/4 | 11 | A | 65.710 | 65.276 | 64.231 | 64.014 | 62.752 |  |  | 62.752 | 63.392 | 64.231 | 64.448 | 65.710 |  | 57.1500 | 131.420 | 10.0000
65.710 |  | G65.71x2.309 | G 2 1/4 | 11 | B | 65.710 | 65.276 | 64.231 | 63.797 | 62.752
75.184 |  | G75.184x2.309 | G 2 1/2 | 11 | A | 75.184 | 74.750 | 73.705 | 73.488 | 72.226 |  |  | 72.226 | 72.866 | 73.705 | 73.922 | 75.184 |  |  | 150.368 | 10.0000
75.184 |  | G75.184x2.309 | G 2 1/2 | 11 | B | 75.184 | 74.750 | 73.705 | 73.271 | 72.226
81.534 |  | G81.534x2.309 | G 2 3/4 | 11 | A | 81.534 | 81.100 | 80.055 | 79.838 | 78.576 |  |  | 78.576 | 79.216 | 80.055 | 80.272 | 81.534 |  | 69.8500 | 163.068 | 10.0000
81.534 |  | G81.534x2.309 | G 2 3/4 | 11 | B | 81.534 | 81.100 | 80.055 | 79.621 | 78.576
87.884 |  | G87.884x2.309 | G 3 | 11 | A | 87.884 | 87.450 | 86.405 | 86.188 | 84.926 |  |  | 84.926 | 85.566 | 86.405 | 86.622 | 87.884 |  | 76.2000 | 175.768 | 10.0000
87.884 |  | G87.884x2.309 | G 3 | 11 | B | 87.884 | 87.450 | 86.405 | 85.971 | 84.926
100.330 |  | G100.33x2.309 | G 3 1/2 | 11 | A | 100.330 | 99.896 | 98.851 | 98.634 | 97.372 |  |  | 97.372 | 98.012 | 98.851 | 99.068 | 100.330 |  | 88.9000 | 200.660 | 10.0000
100.330 |  | G100.33x2.309 | G 3 1/2 | 11 | B | 100.330 | 99.896 | 98.851 | 98.417 | 97.372
113.030 |  | G113.03x2.309 | G 4 | 11 | A | 113.030 | 112.596 | 111.551 | 111.334 | 110.072 |  |  | 110.072 | 110.712 | 111.551 | 111.768 | 113.030 |  | 101.6000 | 226.060 | 10.0000
113.030 |  | G113.03x2.309 | G 4 | 11 | B | 113.030 | 112.596 | 111.551 | 111.117 | 110.072
125.730 |  | G125.73x2.309 | G 4 1/2 | 11 | A | 125.730 | 125.296 | 124.251 | 124.034 | 122.772 |  |  | 122.772 | 123.412 | 124.251 | 124.468 | 125.730 |  | 114.3000 | 251.460 | 10.0000
125.730 |  | G125.73x2.309 | G 4 1/2 | 11 | B | 125.730 | 125.296 | 124.251 | 123.817 | 122.772
138.430 |  | G138.43x2.309 | G 5 | 11 | A | 138.430 | 137.996 | 136.951 | 136.734 | 135.472 |  |  | 135.472 | 136.112 | 136.951 | 137.168 | 138.430 |  | 127.0000 | 276.860 | 10.0000
138.430 |  | G138.43x2.309 | G 5 | 11 | B | 138.430 | 137.996 | 136.951 | 136.517 | 135.472
151.130 |  | G151.13x2.309 | G 5 1/2 | 11 | A | 151.130 | 150.696 | 149.651 | 149.434 | 148.172 |  |  | 148.172 | 148.812 | 149.651 | 149.868 | 151.130 |  | 139.7000 | 302.260 | 10.0000
151.130 |  | G151.13x2.309 | G 5 1/2 | 11 | B | 151.130 | 150.696 | 149.651 | 149.217 | 148.172
163.830 |  | G163.83x2.309 | G 6 | 11 | A | 163.830 | 163.396 | 162.351 | 162.134 | 160.872 |  |  | 160.872 | 161.512 | 162.351 | 162.568 | 163.830 |  | 152.4000 | 327.660 | 10.0000
163.830 |  | G163.83x2.309 | G 6 | 11 | B | 163.830 | 163.396 | 162.351 | 161.917 | 160.872

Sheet: JIS Pipe Threads
M Q | JIS-Rohrgewinde |  | Sort Order -12 |  | External |  |  |  |  |  |  | Internal
 |  |  |  |  |  | Major Dia |  | Pitch Dia |  | Minor Dia |  |  | Minor Dia |  | Pitch Dia |  | Major Dia |  | Tap Drill | Thread Depth | Thread Runouts
Size | Size Suffix | Thread Designation | Custom Thread Designation | TPI | Class | Max | Min | Max | Min | Max | Min | Class | Min | Max | Min | Max | Min | Max | Basic |  | Basic
7.723 |  | G7.723x0.907 | G 1/16 | 28 | A | 7.723 | 7.509 | 7.142 | 7.035 | 6.561 |  |  | 6.561 | 6.834 | 7.142 | 7.249 | 7.723 |  | 1.5875 | 15.446 | 4.5000
7.723 |  | G7.723x0.907 | G 1/16 | 28 | B | 7.723 | 7.509 | 7.142 | 6.928 | 6.561
9.728 |  | G9.728x0.907 | G 1/8 | 28 | A | 9.728 | 9.514 | 9.147 | 9.040 | 8.566 |  |  | 8.566 | 8.848 | 9.147 | 9.254 | 9.728 |  | 3.1750 | 19.456 | 4.5000
9.728 |  | G9.728x0.907 | G 1/8 | 28 | B | 9.728 | 9.514 | 9.147 | 8.933 | 8.566
13.157 |  | G13.157x1.337 | G 1/4 | 19 | A | 13.157 | 12.907 | 12.301 | 12.176 | 11.445 |  |  | 11.445 | 11.89 | 12.301 | 12.426 | 13.157 |  | 6.3500 | 26.314 | 6.5000
13.157 |  | G13.157x1.337 | G 1/4 | 19 | B | 13.157 | 12.907 | 12.301 | 12.051 | 11.445
16.662 |  | G16.662x1.337 | G 3/8 | 19 | A | 16.662 | 16.412 | 15.806 | 15.681 | 14.950 |  |  | 14.95 | 15.395 | 15.806 | 15.931 | 16.662 |  | 9.5250 | 33.324 | 6.5000
16.662 |  | G16.662x1.337 | G 3/8 | 19 | B | 16.662 | 16.412 | 15.806 | 15.556 | 14.950
20.955 |  | G20.955x1.814 | G 1/2 | 14 | A | 20.955 | 20.671 | 19.793 | 19.651 | 18.631 |  |  | 18.631 | 19.172 | 19.793 | 19.935 | 20.955 |  | 12.7000 | 41.910 | 8.5000
20.955 |  | G20.955x1.814 | G 1/2 | 14 | B | 20.955 | 20.671 | 19.793 | 19.509 | 18.631
22.911 |  | G22.911x1.814 | G 5/8 | 14 | A | 22.911 | 22.627 | 21.749 | 21.607 | 20.587 |  |  | 20.587 | 21.128 | 21.749 | 21.891 | 22.911 |  |  | 45.822 | 8.5000
22.911 |  | G22.911x1.814 | G 5/8 | 14 | B | 22.911 | 22.627 | 21.749 | 21.465 | 20.587
26.441 |  | G26.441x1.814 | G 3/4 | 14 | A | 26.441 | 26.157 | 25.279 | 25.137 | 24.117 |  |  | 24.117 | 24.658 | 25.279 | 25.421 | 26.441 |  | 15.8750 | 52.882 | 8.5000
26.441 |  | G26.441x1.814 | G 3/4 | 14 | B | 26.441 | 26.157 | 25.279 | 24.995 | 24.117
30.201 |  | G30.201x1.814 | G 7/8 | 14 | A | 30.201 | 29.917 | 29.039 | 28.897 | 27.877 |  |  | 27.877 | 28.418 | 29.039 | 29.181 | 30.201 |  | 22.2250 | 60.402 | 8.8000
30.201 |  | G30.201x1.814 | G 7/8 | 14 | B | 30.201 | 29.917 | 29.039 | 28.755 | 27.877
33.249 |  | G33.249x2.309 | G 1 | 11 | A | 33.249 | 32.889 | 31.770 | 31.590 | 30.291 |  |  | 30.291 | 30.931 | 31.77 | 31.95 | 33.249 |  | 25.4000 | 66.498 | 10.0000
33.249 |  | G33.249x2.309 | G 1 | 11 | B | 33.249 | 32.889 | 31.770 | 31.410 | 30.291
37.897 |  | G37.897x2.309 | G 1 1/8 | 11 | A | 37.897 | 37.537 | 36.418 | 36.238 | 34.939 |  |  | 34.939 | 35.579 | 36.418 | 36.598 | 37.897 |  | 28.5750 | 75.794 | 10.0000
37.897 |  | G37.897x2.309 | G 1 1/8 | 11 | B | 37.897 | 37.537 | 36.418 | 36.058 | 34.939
41.910 |  | G41.91x2.309 | G 1 1/4 | 11 | A | 41.910 | 41.550 | 40.431 | 40.251 | 38.952 |  |  | 38.952 | 39.592 | 40.431 | 40.611 | 41.910 |  | 31.7500 | 83.820 | 10.0000
41.910 |  | G41.91x2.309 | G 1 1/4 | 11 | B | 41.910 | 41.550 | 40.431 | 40.071 | 38.952
47.803 |  | G47.803x2.309 | G 1 1/2 | 11 | A | 47.803 | 47.443 | 46.324 | 46.144 | 44.845 |  |  | 44.845 | 45.485 | 46.324 | 46.504 | 47.803 |  | 38.1000 | 95.606 | 10.0000
47.803 |  | G47.803x2.309 | G 1 1/2 | 11 | B | 47.803 | 47.443 | 46.324 | 45.964 | 44.845
53.746 |  | G53.746x2.309 | G 1 3/4 | 11 | A | 53.746 | 53.386 | 52.267 | 52.087 | 50.788 |  |  | 50.788 | 51.428 | 52.267 | 52.447 | 53.746 |  | 44.4500 | 107.492 | 10.0000
53.746 |  | G53.746x2.309 | G 1 3/4 | 11 | B | 53.746 | 53.386 | 52.267 | 51.907 | 50.788
59.614 |  | G59.614x2.309 | G 2 | 11 | A | 59.614 | 59.254 | 58.135 | 57.955 | 56.656 |  |  | 56.656 | 57.296 | 58.135 | 58.315 | 59.614 |  | 50.8000 | 119.228 | 10.0000
59.614 |  | G59.614x2.309 | G 2 | 11 | B | 59.614 | 59.254 | 58.135 | 57.775 | 56.656
65.710 |  | G65.71x2.309 | G 2 1/4 | 11 | A | 65.710 | 65.276 | 64.231 | 64.014 | 62.752 |  |  | 62.752 | 63.392 | 64.231 | 64.448 | 65.710 |  | 57.1500 | 131.420 | 10.0000
65.710 |  | G65.71x2.309 | G 2 1/4 | 11 | B | 65.710 | 65.276 | 64.231 | 63.797 | 62.752
75.184 |  | G75.184x2.309 | G 2 1/2 | 11 | A | 75.184 | 74.750 | 73.705 | 73.488 | 72.226 |  |  | 72.226 | 72.866 | 73.705 | 73.922 | 75.184 |  |  | 150.368 | 10.0000
75.184 |  | G75.184x2.309 | G 2 1/2 | 11 | B | 75.184 | 74.750 | 73.705 | 73.271 | 72.226
81.534 |  | G81.534x2.309 | G 2 3/4 | 11 | A | 81.534 | 81.100 | 80.055 | 79.838 | 78.576 |  |  | 78.576 | 79.216 | 80.055 | 80.272 | 81.534 |  | 69.8500 | 163.068 | 10.0000
81.534 |  | G81.534x2.309 | G 2 3/4 | 11 | B | 81.534 | 81.100 | 80.055 | 79.621 | 78.576
87.884 |  | G87.884x2.309 | G 3 | 11 | A | 87.884 | 87.450 | 86.405 | 86.188 | 84.926 |  |  | 84.926 | 85.566 | 86.405 | 86.622 | 87.884 |  | 76.2000 | 175.768 | 10.0000
87.884 |  | G87.884x2.309 | G 3 | 11 | B | 87.884 | 87.450 | 86.405 | 85.971 | 84.926
100.330 |  | G100.33x2.309 | G 3 1/2 | 11 | A | 100.330 | 99.896 | 98.851 | 98.634 | 97.372 |  |  | 97.372 | 98.012 | 98.851 | 99.068 | 100.330 |  | 88.9000 | 200.660 | 10.0000
100.330 |  | G100.33x2.309 | G 3 1/2 | 11 | B | 100.330 | 99.896 | 98.851 | 98.417 | 97.372
113.030 |  | G113.03x2.309 | G 4 | 11 | A | 113.030 | 112.596 | 111.551 | 111.334 | 110.072 |  |  | 110.072 | 110.712 | 111.551 | 111.768 | 113.030 |  | 101.6000 | 226.060 | 10.0000
113.030 |  | G113.03x2.309 | G 4 | 11 | B | 113.030 | 112.596 | 111.551 | 111.117 | 110.072
125.730 |  | G125.73x2.309 | G 4 1/2 | 11 | A | 125.730 | 125.296 | 124.251 | 124.034 | 122.772 |  |  | 122.772 | 123.412 | 124.251 | 124.468 | 125.730 |  | 114.3000 | 251.460 | 10.0000
125.730 |  | G125.73x2.309 | G 4 1/2 | 11 | B | 125.730 | 125.296 | 124.251 | 123.817 | 122.772
138.430 |  | G138.43x2.309 | G 5 | 11 | A | 138.430 | 137.996 | 136.951 | 136.734 | 135.472 |  |  | 135.472 | 136.112 | 136.951 | 137.168 | 138.430 |  | 127.0000 | 276.860 | 10.0000
138.430 |  | G138.43x2.309 | G 5 | 11 | B | 138.430 | 137.996 | 136.951 | 136.517 | 135.472
151.130 |  | G151.13x2.309 | G 5 1/2 | 11 | A | 151.130 | 150.696 | 149.651 | 149.434 | 148.172 |  |  | 148.172 | 148.812 | 149.651 | 149.868 | 151.130 |  | 139.7000 | 302.260 | 10.0000
151.130 |  | G151.13x2.309 | G 5 1/2 | 11 | B | 151.130 | 150.696 | 149.651 | 149.217 | 148.172
163.830 |  | G163.83x2.309 | G 6 | 11 | A | 163.830 | 163.396 | 162.351 | 162.134 | 160.872 |  |  | 160.872 | 161.512 | 162.351 | 162.568 | 163.830 |  | 152.4000 | 327.660 | 10.0000
163.830 |  | G163.83x2.309 | G 6 | 11 | B | 163.830 | 163.396 | 162.351 | 161.917 | 160.872
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

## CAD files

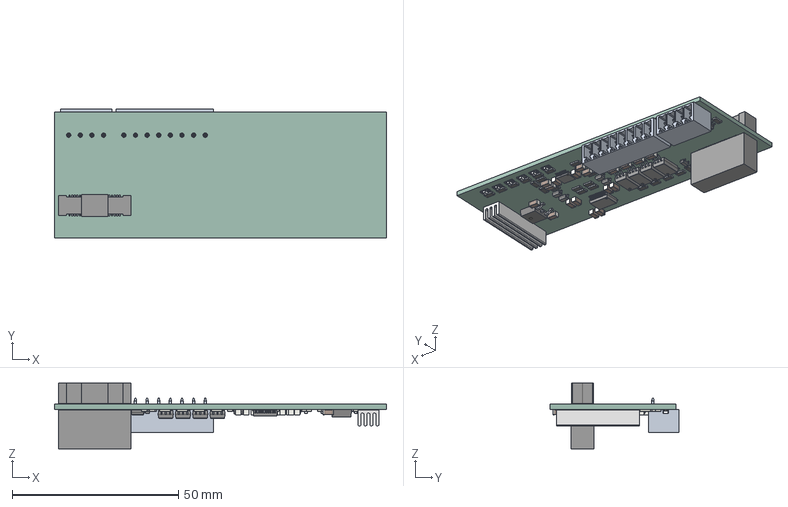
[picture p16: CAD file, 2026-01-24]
KiCad Schaltungen/Analogmodul/Analogmodul.step
100.0 x 38.9 x 19.8 mm
Pins x 2
Lugs x 3
C_1206_3216Metric x 22
PinsArrayLR x 6
R_1206_3216Metric x 26
BODY-SO x 2
LEAD-SO x 16
THERMALPAD-SO x 2
contact-pins x 12
PCB x 6
glass housing x 6
Polarity Mark x 6
FilletPinL x 4
FilletPinR x 5
PinsArrayL
Linear Pattern 01
Heatsink DIL20 Fischer
Analogmodul_PCB

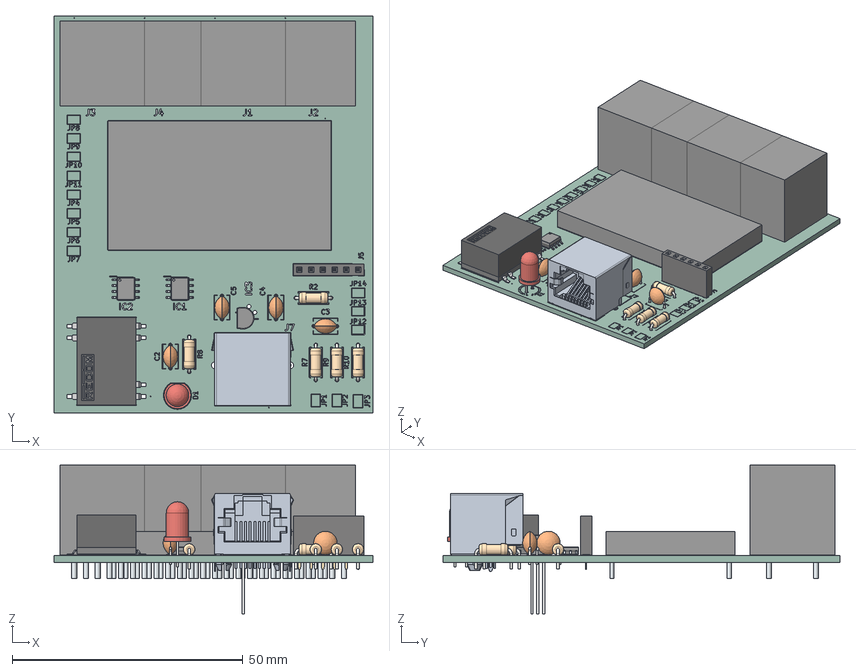
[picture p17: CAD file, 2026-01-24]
KiCad Schaltungen/ESP Interface Board/ESP Interface Board.step
69.0 x 86.0 x 32.2 mm
LED_D5.0mm
PinSocket_1x06_P2.54mm_Vertical
C_Disc_D5.1mm_W3.2mm_P5.00mm x 4
Leads x 5
R_Axial_DIN0207_L6.3mm_D2.5mm_P7.62mm_Horizontal x 5
PinsArrayLR x 2
Heater 膠體-Type_3
PIN-TYPE_3 x 7
N1818 Cover Type_3
TS110-7A1-AP_Bulk Pack (Straight)
STMicro Logo
ESP Interface Board_silkscreen
ESP Interface Board_PCB

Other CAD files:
Inventor CAD/Templates/JIS.dwg
Inventor CAD/Templates/GOST.dwg
Inventor CAD/Templates/BSI.dwg
Inventor CAD/Templates/ISO.dwg
Inventor CAD/Templates/ANSI (mm).dwg
Inventor CAD/Templates/GB.dwg
Inventor CAD/Templates/DIN.dwg
Inventor CAD/Design Data/AIT/Mold Design/mold design stop pin.ipt
Inventor CAD/Design Data/Cable & Harness/de-DE/harness.iam
Inventor CAD/Design Data/Tube & Pipe/de-DE/piping runs.iam
Inventor CAD/Templates/ANSI (mm).idw
Inventor CAD/Templates/BSI.idw
Inventor CAD/Templates/DIN.idw
Inventor CAD/Templates/GB.idw
Inventor CAD/Templates/GOST.idw
Inventor CAD/Templates/ISO.idw
Inventor CAD/Templates/JIS.idw
Inventor CAD/Templates/Mold Design (DIN).iam
Inventor CAD/Templates/Mold Design (mm).iam
Inventor CAD/Templates/Sheet Metal (DIN).ipt
Inventor CAD/Templates/Sheet Metal (mm).ipt
Inventor CAD/Templates/Standard (DIN).iam
Inventor CAD/Templates/Standard (DIN).ipn
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

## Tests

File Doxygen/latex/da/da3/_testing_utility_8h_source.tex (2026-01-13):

\doxysection{Testing\+Utility.\+h}
\hypertarget{_testing_utility_8h_source}{}\label{_testing_utility_8h_source}\index{C:/Users/leowa/Documents/PlatformIO/Projects/CANTramFrameworkUsage/lib/CANTramFramework/include/TestingUtility.h@{C:/Users/leowa/Documents/PlatformIO/Projects/CANTramFrameworkUsage/lib/CANTramFramework/include/TestingUtility.h}}

\begin{DoxyCode}{0}
\DoxyCodeLine{00001\ \textcolor{preprocessor}{\#ifndef\ TESTING\_UTILITY\_H}}
\DoxyCodeLine{00002\ \textcolor{preprocessor}{\#define\ TESTING\_UTILITY\_H}}
\DoxyCodeLine{00003\ }
\DoxyCodeLine{00004\ \textcolor{preprocessor}{\#include\ <Arduino.h>}}
\DoxyCodeLine{00005\ \textcolor{preprocessor}{\#include\ "{}\mbox{\hyperlink{_debug_8h}{Debug.h}}"{}}}
\DoxyCodeLine{00006\ }
\DoxyCodeLine{00007\ }
\DoxyCodeLine{00008\ \textcolor{keywordtype}{void}\ generateRandomString(\textcolor{keywordtype}{char}\ buffer[],\ \textcolor{keywordtype}{size\_t}\ length)\ \{}
\DoxyCodeLine{00009\ \ \ \ \ \textcolor{keyword}{static}\ \textcolor{keyword}{const}\ \textcolor{keywordtype}{char}\ charset[]\ =\ \textcolor{stringliteral}{"{}ABCDEFGHIJKLMNOPQRSTUVWXYZabcdefghijklmnopqrstuvwxyz0123456789"{}};}
\DoxyCodeLine{00010\ \ \ \ \ \textcolor{keywordflow}{for}\ (\textcolor{keywordtype}{size\_t}\ i\ =\ 0;\ i\ <\ length;\ i++)\ \{}
\DoxyCodeLine{00011\ \ \ \ \ \ \ \ \ \textcolor{keywordtype}{int}\ key\ =\ random(0,\ \textcolor{keyword}{sizeof}(charset)\ -\/\ 1);}
\DoxyCodeLine{00012\ \ \ \ \ \ \ \ \ buffer[i]\ =\ charset[key];}
\DoxyCodeLine{00013\ \ \ \ \ \}}
\DoxyCodeLine{00014\ \ \ \ \ buffer[length]\ =\ \textcolor{charliteral}{'\(\backslash\)0'};\ \textcolor{comment}{//\ Null-\/terminate\ the\ string}}
\DoxyCodeLine{00015\ \ \ \ \ \mbox{\hyperlink{_debug_8h_a8e30ff0704664fcb13dabf0c4dc5c8f5}{DEBUG\_PRINTLN}}(\textcolor{stringliteral}{"{}Generated\ random\ string:\ "{}}\ +\ String(buffer));}
\DoxyCodeLine{00016\ }
\DoxyCodeLine{00017\ \}}
\DoxyCodeLine{00018\ }
\DoxyCodeLine{00019\ \textcolor{keywordtype}{void}\ clearBuffer(\textcolor{keywordtype}{char}\ buffer[],\ \textcolor{keywordtype}{size\_t}\ length)\ \{}
\DoxyCodeLine{00020\ \ \ \ \ memset(buffer,\ 0,\ length);}
\DoxyCodeLine{00021\ \ \ \ \ \mbox{\hyperlink{_debug_8h_a8e30ff0704664fcb13dabf0c4dc5c8f5}{DEBUG\_PRINTLN}}(\textcolor{stringliteral}{"{}Cleared\ buffer:\ "{}}\ +\ String(buffer));}
\DoxyCodeLine{00022\ \}}
\DoxyCodeLine{00023\ }
\DoxyCodeLine{00024\ String\ addLeadingZeros(\textcolor{keywordtype}{int}\ number,\ \textcolor{keywordtype}{int}\ bits)\ \{}
\DoxyCodeLine{00025\ \ \ \ \ String\ numStr\ =\ String(number,\ BIN);}
\DoxyCodeLine{00026\ \ \ \ \ \textcolor{keywordflow}{while}\ (numStr.length()\ <\ bits)\ \{}
\DoxyCodeLine{00027\ \ \ \ \ \ \ \ \ numStr\ =\ \textcolor{stringliteral}{"{}0"{}}\ +\ numStr;}
\DoxyCodeLine{00028\ \ \ \ \ \}}
\DoxyCodeLine{00029\ \ \ \ \ \textcolor{keywordflow}{return}\ numStr;}
\DoxyCodeLine{00030\ \}}
\DoxyCodeLine{00031\ }
\DoxyCodeLine{00032\ \textcolor{preprocessor}{\#endif}}

\end{DoxyCode}

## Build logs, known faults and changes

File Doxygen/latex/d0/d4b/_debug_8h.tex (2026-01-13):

\doxysection{C\+:/\+Users/leowa/\+Documents/\+Platform\+IO/\+Projects/\+CANTram\+Framework\+Usage/lib/\+CANTram\+Framework/include/\+Debug.h File Reference}
\hypertarget{_debug_8h}{}\label{_debug_8h}\index{C:/Users/leowa/Documents/PlatformIO/Projects/CANTramFrameworkUsage/lib/CANTramFramework/include/Debug.h@{C:/Users/leowa/Documents/PlatformIO/Projects/CANTramFrameworkUsage/lib/CANTramFramework/include/Debug.h}}

Logging and debug macro definitions for \doxylink{class_c_a_n_tram_core}{CANTram\+Core}.  

{\ttfamily \#include $<$Arduino.\+h$>$}\newline
Include dependency graph for Debug.\+h\+:
\nopagebreak
\begin{figure}[H]
\begin{center}
\leavevmode
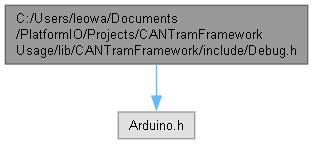
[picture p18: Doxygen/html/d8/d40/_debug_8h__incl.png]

\end{center}
\end{figure}
This graph shows which files directly or indirectly include this file\+:
\nopagebreak
\begin{figure}[H]
\begin{center}
\leavevmode
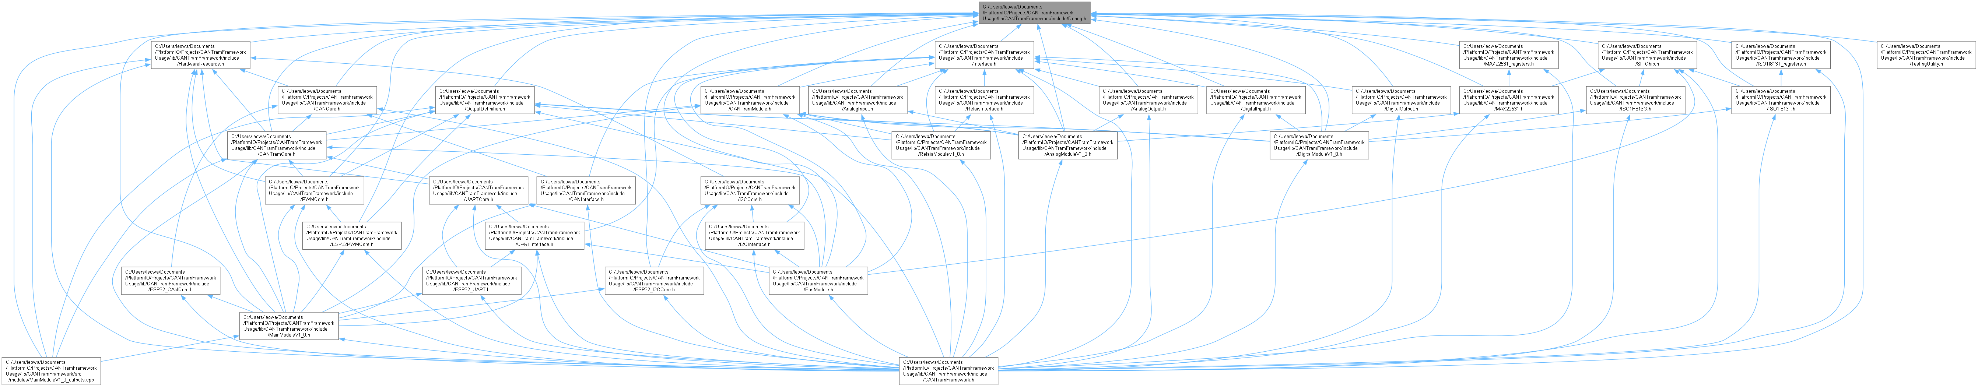
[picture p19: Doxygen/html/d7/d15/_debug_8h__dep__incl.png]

\end{center}
\end{figure}
\doxysubsubsection*{Macros}
\begin{DoxyCompactItemize}
\item 
\#define \mbox{\hyperlink{_debug_8h_a2b1da0cb514f35f2dad5f19754377274}{DEBUG\+\_\+\+OUTPUT}}
\begin{DoxyCompactList}\small\item\em Disable all output when defined. \end{DoxyCompactList}\item 
\Hypertarget{_debug_8h_afd2af33eff1aa55142249e4ba9317605}\label{_debug_8h_afd2af33eff1aa55142249e4ba9317605} 
\#define {\bfseries INFO\+\_\+\+OUTPUT}
\item 
\Hypertarget{_debug_8h_a5508e02ae09c9565a66427c56909c82f}\label{_debug_8h_a5508e02ae09c9565a66427c56909c82f} 
\#define {\bfseries ERROR\+\_\+\+OUTPUT}
\item 
\Hypertarget{_debug_8h_aa823b67eb1c9de891dae980c12ec9990}\label{_debug_8h_aa823b67eb1c9de891dae980c12ec9990} 
\#define {\bfseries WARNING\+\_\+\+OUTPUT}
\item 
\Hypertarget{_debug_8h_a1e6f9b59835399ea72711ab60ab2d958}\label{_debug_8h_a1e6f9b59835399ea72711ab60ab2d958} 
\#define {\bfseries CRITICAL\+\_\+\+ERROR\+\_\+\+OUTPUT}
\item 
\Hypertarget{_debug_8h_ae8ecfa3976a455beb3a24ef1d7cecbe9}\label{_debug_8h_ae8ecfa3976a455beb3a24ef1d7cecbe9} 
\#define {\bfseries DEV\+\_\+\+ERROR\+\_\+\+OUTPUT}
\item 
\Hypertarget{_debug_8h_a710fd7accfba27ed9250129eb7f55b2c}\label{_debug_8h_a710fd7accfba27ed9250129eb7f55b2c} 
\#define {\bfseries INSTRUCTION\+\_\+\+OUTPUT}
\item 
\Hypertarget{_debug_8h_abdd60bad2ed9c548f3b7ec12ac096639}\label{_debug_8h_abdd60bad2ed9c548f3b7ec12ac096639} 
\#define {\bfseries CHIP\+\_\+\+OUTPUT}
\item 
\Hypertarget{_debug_8h_a839d49d8b25c37c91a1a8ed3090c7cb0}\label{_debug_8h_a839d49d8b25c37c91a1a8ed3090c7cb0} 
\#define {\bfseries MEASUREMENT\+\_\+\+OUTPUT}
\item 
\Hypertarget{_debug_8h_af972dc9d988e79f1c53964a9b3b9860f}\label{_debug_8h_af972dc9d988e79f1c53964a9b3b9860f} 
\#define {\bfseries MACRO\+\_\+\+LOCATION}~"{}"{}
\item 
\#define \mbox{\hyperlink{_debug_8h_af6551f0b4c3964c3128f808e7bf987c7}{DEBUG\+\_\+\+PRINT}}(x)
\begin{DoxyCompactList}\small\item\em Print a debug message without newline. \end{DoxyCompactList}\item 
\#define \mbox{\hyperlink{_debug_8h_a8e30ff0704664fcb13dabf0c4dc5c8f5}{DEBUG\+\_\+\+PRINTLN}}(x)
\begin{DoxyCompactList}\small\item\em Print a debug message with newline. \end{DoxyCompactList}\item 
\#define \mbox{\hyperlink{_debug_8h_af1bb2a2c18de0a487366724efb4f1b8c}{MEASUREMENT\+\_\+\+PRINT}}(x)
\begin{DoxyCompactList}\small\item\em Print a measurement message without newline. \end{DoxyCompactList}\item 
\#define \mbox{\hyperlink{_debug_8h_aee4ea675d26ff667e6641d91ccc5bf1a}{MEASUREMENT\+\_\+\+PRINTLN}}(x)
\begin{DoxyCompactList}\small\item\em Print a measurement message with newline. \end{DoxyCompactList}\item 
\#define \mbox{\hyperlink{_debug_8h_ac55217e6814de7894a11b7e7cd54f708}{INSTRUCTION\+\_\+\+PRINT}}(x)
\begin{DoxyCompactList}\small\item\em Print a INSTRUCTION message without newline. \end{DoxyCompactList}\item 
\#define \mbox{\hyperlink{_debug_8h_a625610458d92e74e7a0eb4dbe1d78c79}{INSTRUCTION\+\_\+\+PRINTLN}}(x)
\begin{DoxyCompactList}\small\item\em Print a INSTRUCTION message without newline. \end{DoxyCompactList}\item 
\#define \mbox{\hyperlink{_debug_8h_ada3de6ba49d97903fbf36000cc99d55d}{INFO\+\_\+\+PRINT}}(x)
\begin{DoxyCompactList}\small\item\em Print an info-\/level message without newline. \end{DoxyCompactList}\item 
\#define \mbox{\hyperlink{_debug_8h_a693063ba84ad2119e7f3ea1b97947055}{INFO\+\_\+\+PRINTLN}}(x)
\begin{DoxyCompactList}\small\item\em Print an info-\/level message with newline. \end{DoxyCompactList}\item 
\#define \mbox{\hyperlink{_debug_8h_aefd58cef04351b40871f9aa0c84a895a}{ERROR\+\_\+\+PRINT}}(x)
\begin{DoxyCompactList}\small\item\em Print an error-\/level message without newline. \end{DoxyCompactList}\item 
\#define \mbox{\hyperlink{_debug_8h_aab934c3f2345fdd7f8ca02ff2c332f60}{ERROR\+\_\+\+PRINTLN}}(x)
\begin{DoxyCompactList}\small\item\em Print an error-\/level message with newline. \end{DoxyCompactList}\item 
\#define \mbox{\hyperlink{_debug_8h_af25901a0f15375b04a19c6089aba7abe}{WARNING\+\_\+\+PRINT}}(x)
\begin{DoxyCompactList}\small\item\em Print a warning-\/level message without newline. \end{DoxyCompactList}\item 
\#define \mbox{\hyperlink{_debug_8h_a2ab63874bfdcb0637ccb2dff37bdb8af}{WARNING\+\_\+\+PRINTLN}}(x)
\begin{DoxyCompactList}\small\item\em Print a warning-\/level message with newline. \end{DoxyCompactList}\item 
\#define \mbox{\hyperlink{_debug_8h_af5ac1d6712be8931a015904d3e7b671a}{DEV\+\_\+\+ERROR\+\_\+\+PRINT}}(x)
\begin{DoxyCompactList}\small\item\em Print a developer-\/error-\/level message without newline. \end{DoxyCompactList}\item 
\#define \mbox{\hyperlink{_debug_8h_aeb03a131ff07c832ab6ad83b6e6a0744}{DEV\+\_\+\+ERROR\+\_\+\+PRINTLN}}(x)
\begin{DoxyCompactList}\small\item\em Print a developer-\/error-\/level message with newline. \end{DoxyCompactList}\item 
\#define \mbox{\hyperlink{_debug_8h_aa701e4f6c5d2d6affe69e633f63b67f2}{CHIP\+\_\+\+PRINT}}(x)
\begin{DoxyCompactList}\small\item\em Print a chip-\/level message without newline. \end{DoxyCompactList}\item 
\#define \mbox{\hyperlink{_debug_8h_a6d7fbffe38d5c736fd08a08c3632ecef}{CHIP\+\_\+\+PRINTLN}}(x)
\begin{DoxyCompactList}\small\item\em Print a chip-\/level message with newline. \end{DoxyCompactList}\item 
\#define \mbox{\hyperlink{_debug_8h_a1832fbfe80e31438e395951e4fa75882}{CRITICAL\+\_\+\+ERROR\+\_\+\+PRINT}}(x)
\begin{DoxyCompactList}\small\item\em Print a critical error message and halt execution. \end{DoxyCompactList}\item 
\#define \mbox{\hyperlink{_debug_8h_a80f4fbd5eca866a2e8c9aacafe26b2a4}{CRITICAL\+\_\+\+ERROR\+\_\+\+PRINTLN}}(x)
\begin{DoxyCompactList}\small\item\em Print a critical error message with newline and halt execution. \end{DoxyCompactList}\item 
\#define \mbox{\hyperlink{_debug_8h_a98e7c49c7900880470d265bce927fba1}{NULL\+\_\+\+PTR\+\_\+\+CHECK}}(ptr)
\begin{DoxyCompactList}\small\item\em Check a pointer for null and report a critical error if null. \end{DoxyCompactList}\end{DoxyCompactItemize}

\doxysubsection{Detailed Description}
Logging and debug macro definitions for \doxylink{class_c_a_n_tram_core}{CANTram\+Core}. 

Defines macros for debug, info, error, warning, developer error and chip-\/level logging. Macros prepend a level prefix and optionally include file/line information when DEBUG\+\_\+\+SHOW\+\_\+\+LOCATION is defined. Also provides a NULL pointer check macro that prints a critical error and halts execution when a null pointer is detected. 

\label{doc-define-members}
\Hypertarget{_debug_8h_doc-define-members}
\doxysubsection{Macro Definition Documentation}
\Hypertarget{_debug_8h_aa701e4f6c5d2d6affe69e633f63b67f2}\index{Debug.h@{Debug.h}!CHIP\_PRINT@{CHIP\_PRINT}}
\index{CHIP\_PRINT@{CHIP\_PRINT}!Debug.h@{Debug.h}}
\doxysubsubsection{\texorpdfstring{CHIP\_PRINT}{CHIP\_PRINT}}
{\footnotesize\ttfamily \label{_debug_8h_aa701e4f6c5d2d6affe69e633f63b67f2} 
\#define CHIP\+\_\+\+PRINT(\begin{DoxyParamCaption}\item[{}]{x}{}\end{DoxyParamCaption})}

{\bfseries Value\+:}
\begin{DoxyCode}{0}
\DoxyCodeLine{Serial.print((String)\ \textcolor{stringliteral}{"{}CHIP:\ "{}}\ +\ x\ +\ \ MACRO\_LOCATION)}

\end{DoxyCode}

Print a chip-\/level message without newline. 

Used for chip-\/related informational messages. Expands to Serial.\+print with "{}\+CHIP\+: "{} prefix and optional file/line info. 
\begin{DoxyParams}{Parameters}
{\em x} & Expression or string to print (will be converted to String). \\
\hline
\end{DoxyParams}
\Hypertarget{_debug_8h_a6d7fbffe38d5c736fd08a08c3632ecef}\index{Debug.h@{Debug.h}!CHIP\_PRINTLN@{CHIP\_PRINTLN}}
\index{CHIP\_PRINTLN@{CHIP\_PRINTLN}!Debug.h@{Debug.h}}
\doxysubsubsection{\texorpdfstring{CHIP\_PRINTLN}{CHIP\_PRINTLN}}
{\footnotesize\ttfamily \label{_debug_8h_a6d7fbffe38d5c736fd08a08c3632ecef} 
\#define CHIP\+\_\+\+PRINTLN(\begin{DoxyParamCaption}\item[{}]{x}{}\end{DoxyParamCaption})}

{\bfseries Value\+:}
\begin{DoxyCode}{0}
\DoxyCodeLine{Serial.println((String)\ \textcolor{stringliteral}{"{}CHIP:\ "{}}\ +\ x\ +\ \ MACRO\_LOCATION)}

\end{DoxyCode}

Print a chip-\/level message with newline. 

Used for chip-\/related informational messages. Expands to Serial.\+println with "{}\+CHIP\+: "{} prefix and optional file/line info. 
\begin{DoxyParams}{Parameters}
{\em x} & Expression or string to print (will be converted to String). \\
\hline
\end{DoxyParams}
\Hypertarget{_debug_8h_a1832fbfe80e31438e395951e4fa75882}\index{Debug.h@{Debug.h}!CRITICAL\_ERROR\_PRINT@{CRITICAL\_ERROR\_PRINT}}
\index{CRITICAL\_ERROR\_PRINT@{CRITICAL\_ERROR\_PRINT}!Debug.h@{Debug.h}}
\doxysubsubsection{\texorpdfstring{CRITICAL\_ERROR\_PRINT}{CRITICAL\_ERROR\_PRINT}}
{\footnotesize\ttfamily \label{_debug_8h_a1832fbfe80e31438e395951e4fa75882} 
\#define CRITICAL\+\_\+\+ERROR\+\_\+\+PRINT(\begin{DoxyParamCaption}\item[{}]{x}{}\end{DoxyParamCaption})}

{\bfseries Value\+:}
\begin{DoxyCode}{0}
\DoxyCodeLine{\ \ \ \ Serial.print((String)\ \textcolor{stringliteral}{"{}CRITICAL\ ERROR:\ "{}}\ +\ x\ +\ \ MACRO\_LOCATION);\ \(\backslash\)}
\DoxyCodeLine{\ \ \ \ while\ (\textcolor{keyword}{true})}

\end{DoxyCode}

Print a critical error message and halt execution. 

Prints "{}\+CRITICAL ERROR\+: "{} prefix with the provided message and optional file/line info, then enters an infinite loop to stop execution. 
\begin{DoxyParams}{Parameters}
{\em x} & Expression or string to print (will be converted to String). \\
\hline
\end{DoxyParams}
\begin{DoxyNote}{Note}
This macro does not return. 
\end{DoxyNote}
\Hypertarget{_debug_8h_a80f4fbd5eca866a2e8c9aacafe26b2a4}\index{Debug.h@{Debug.h}!CRITICAL\_ERROR\_PRINTLN@{CRITICAL\_ERROR\_PRINTLN}}
\index{CRITICAL\_ERROR\_PRINTLN@{CRITICAL\_ERROR\_PRINTLN}!Debug.h@{Debug.h}}
\doxysubsubsection{\texorpdfstring{CRITICAL\_ERROR\_PRINTLN}{CRITICAL\_ERROR\_PRINTLN}}
{\footnotesize\ttfamily \label{_debug_8h_a80f4fbd5eca866a2e8c9aacafe26b2a4} 
\#define CRITICAL\+\_\+\+ERROR\+\_\+\+PRINTLN(\begin{DoxyParamCaption}\item[{}]{x}{}\end{DoxyParamCaption})}

{\bfseries Value\+:}
\begin{DoxyCode}{0}
\DoxyCodeLine{\ \ \ \ Serial.println((String)\ \textcolor{stringliteral}{"{}CRITICAL\ ERROR:\ "{}}\ +\ x\ +\ \ MACRO\_LOCATION);\ \(\backslash\)}
\DoxyCodeLine{\ \ \ \ while\ (\textcolor{keyword}{true})}

\end{DoxyCode}

Print a critical error message with newline and halt execution. 

Prints "{}\+CRITICAL ERROR\+: "{} prefix with the provided message and optional file/line info, then enters an infinite loop to stop execution. 
\begin{DoxyParams}{Parameters}
{\em x} & Expression or string to print (will be converted to String). \\
\hline
\end{DoxyParams}
\begin{DoxyNote}{Note}
This macro does not return. 
\end{DoxyNote}
\Hypertarget{_debug_8h_a2b1da0cb514f35f2dad5f19754377274}\index{Debug.h@{Debug.h}!DEBUG\_OUTPUT@{DEBUG\_OUTPUT}}
\index{DEBUG\_OUTPUT@{DEBUG\_OUTPUT}!Debug.h@{Debug.h}}
\doxysubsubsection{\texorpdfstring{DEBUG\_OUTPUT}{DEBUG\_OUTPUT}}
{\footnotesize\ttfamily \label{_debug_8h_a2b1da0cb514f35f2dad5f19754377274} 
\#define DEBUG\+\_\+\+OUTPUT}

Disable all output when defined. 

Uncomment to completely disable all logging macros. If not defined, individual level macros control output. \Hypertarget{_debug_8h_af6551f0b4c3964c3128f808e7bf987c7}\index{Debug.h@{Debug.h}!DEBUG\_PRINT@{DEBUG\_PRINT}}
\index{DEBUG\_PRINT@{DEBUG\_PRINT}!Debug.h@{Debug.h}}
\doxysubsubsection{\texorpdfstring{DEBUG\_PRINT}{DEBUG\_PRINT}}
{\footnotesize\ttfamily \label{_debug_8h_af6551f0b4c3964c3128f808e7bf987c7} 
\#define DEBUG\+\_\+\+PRINT(\begin{DoxyParamCaption}\item[{}]{x}{}\end{DoxyParamCaption})}

{\bfseries Value\+:}
\begin{DoxyCode}{0}
\DoxyCodeLine{Serial.print((String)\ \textcolor{stringliteral}{"{}DEBUG:\ "{}}\ +\ x\ +\ MACRO\_LOCATION)}

\end{DoxyCode}

Print a debug message without newline. 

Expands to Serial.\+print with "{}\+DEBUG\+: "{} prefix and optional file/line info. 
\begin{DoxyParams}{Parameters}
{\em x} & Expression or string to print (will be converted to String). \\
\hline
\end{DoxyParams}
\Hypertarget{_debug_8h_a8e30ff0704664fcb13dabf0c4dc5c8f5}\index{Debug.h@{Debug.h}!DEBUG\_PRINTLN@{DEBUG\_PRINTLN}}
\index{DEBUG\_PRINTLN@{DEBUG\_PRINTLN}!Debug.h@{Debug.h}}
\doxysubsubsection{\texorpdfstring{DEBUG\_PRINTLN}{DEBUG\_PRINTLN}}
{\footnotesize\ttfamily \label{_debug_8h_a8e30ff0704664fcb13dabf0c4dc5c8f5} 
\#define DEBUG\+\_\+\+PRINTLN(\begin{DoxyParamCaption}\item[{}]{x}{}\end{DoxyParamCaption})}

{\bfseries Value\+:}
\begin{DoxyCode}{0}
\DoxyCodeLine{Serial.println((String)\ \textcolor{stringliteral}{"{}DEBUG:\ "{}}\ +\ x\ +\ MACRO\_LOCATION)}

\end{DoxyCode}

Print a debug message with newline. 

Expands to Serial.\+println with "{}\+DEBUG\+: "{} prefix and optional file/line info. 
\begin{DoxyParams}{Parameters}
{\em x} & Expression or string to print (will be converted to String). \\
\hline
\end{DoxyParams}
\Hypertarget{_debug_8h_af5ac1d6712be8931a015904d3e7b671a}\index{Debug.h@{Debug.h}!DEV\_ERROR\_PRINT@{DEV\_ERROR\_PRINT}}
\index{DEV\_ERROR\_PRINT@{DEV\_ERROR\_PRINT}!Debug.h@{Debug.h}}
\doxysubsubsection{\texorpdfstring{DEV\_ERROR\_PRINT}{DEV\_ERROR\_PRINT}}
{\footnotesize\ttfamily \label{_debug_8h_af5ac1d6712be8931a015904d3e7b671a} 
\#define DEV\+\_\+\+ERROR\+\_\+\+PRINT(\begin{DoxyParamCaption}\item[{}]{x}{}\end{DoxyParamCaption})}

{\bfseries Value\+:}
\begin{DoxyCode}{0}
\DoxyCodeLine{Serial.print((String)\ \textcolor{stringliteral}{"{}DEV\_ERROR:\ "{}}\ +\ x\ +\ \ MACRO\_LOCATION)}

\end{DoxyCode}

Print a developer-\/error-\/level message without newline. 

For development-\/only diagnostics. Expands to Serial.\+print with "{}\+DEV\+\_\+\+ERROR\+: "{} prefix and optional file/line info. 
\begin{DoxyParams}{Parameters}
{\em x} & Expression or string to print (will be converted to String). \\
\hline
\end{DoxyParams}
\Hypertarget{_debug_8h_aeb03a131ff07c832ab6ad83b6e6a0744}\index{Debug.h@{Debug.h}!DEV\_ERROR\_PRINTLN@{DEV\_ERROR\_PRINTLN}}
\index{DEV\_ERROR\_PRINTLN@{DEV\_ERROR\_PRINTLN}!Debug.h@{Debug.h}}
\doxysubsubsection{\texorpdfstring{DEV\_ERROR\_PRINTLN}{DEV\_ERROR\_PRINTLN}}
{\footnotesize\ttfamily \label{_debug_8h_aeb03a131ff07c832ab6ad83b6e6a0744} 
\#define DEV\+\_\+\+ERROR\+\_\+\+PRINTLN(\begin{DoxyParamCaption}\item[{}]{x}{}\end{DoxyParamCaption})}

{\bfseries Value\+:}
\begin{DoxyCode}{0}
\DoxyCodeLine{Serial.println((String)\ \textcolor{stringliteral}{"{}DEV\_ERROR:\ "{}}\ +\ x\ +\ \ MACRO\_LOCATION)}

\end{DoxyCode}

Print a developer-\/error-\/level message with newline. 

For development-\/only diagnostics. Expands to Serial.\+println with "{}\+DEV\+\_\+\+ERROR\+: "{} prefix and optional file/line info. 
\begin{DoxyParams}{Parameters}
{\em x} & Expression or string to print (will be converted to String). \\
\hline
\end{DoxyParams}
\Hypertarget{_debug_8h_aefd58cef04351b40871f9aa0c84a895a}\index{Debug.h@{Debug.h}!ERROR\_PRINT@{ERROR\_PRINT}}
\index{ERROR\_PRINT@{ERROR\_PRINT}!Debug.h@{Debug.h}}
\doxysubsubsection{\texorpdfstring{ERROR\_PRINT}{ERROR\_PRINT}}
{\footnotesize\ttfamily \label{_debug_8h_aefd58cef04351b40871f9aa0c84a895a} 
\#define ERROR\+\_\+\+PRINT(\begin{DoxyParamCaption}\item[{}]{x}{}\end{DoxyParamCaption})}

{\bfseries Value\+:}
\begin{DoxyCode}{0}
\DoxyCodeLine{Serial.print((String)\ \textcolor{stringliteral}{"{}ERROR:\ "{}}\ +\ x\ +\ \ MACRO\_LOCATION)}

\end{DoxyCode}

Print an error-\/level message without newline. 

Expands to Serial.\+print with "{}\+ERROR\+: "{} prefix and optional file/line info. 
\begin{DoxyParams}{Parameters}
{\em x} & Expression or string to print (will be converted to String). \\
\hline
\end{DoxyParams}
\Hypertarget{_debug_8h_aab934c3f2345fdd7f8ca02ff2c332f60}\index{Debug.h@{Debug.h}!ERROR\_PRINTLN@{ERROR\_PRINTLN}}
\index{ERROR\_PRINTLN@{ERROR\_PRINTLN}!Debug.h@{Debug.h}}
\doxysubsubsection{\texorpdfstring{ERROR\_PRINTLN}{ERROR\_PRINTLN}}
{\footnotesize\ttfamily \label{_debug_8h_aab934c3f2345fdd7f8ca02ff2c332f60} 
\#define ERROR\+\_\+\+PRINTLN(\begin{DoxyParamCaption}\item[{}]{x}{}\end{DoxyParamCaption})}

{\bfseries Value\+:}
\begin{DoxyCode}{0}
\DoxyCodeLine{Serial.println((String)\ \textcolor{stringliteral}{"{}ERROR:\ "{}}\ +\ x\ +\ \ MACRO\_LOCATION)}

\end{DoxyCode}

Print an error-\/level message with newline. 

Expands to Serial.\+println with "{}\+ERROR\+: "{} prefix and optional file/line info. 
\begin{DoxyParams}{Parameters}
{\em x} & Expression or string to print (will be converted to String). \\
\hline
\end{DoxyParams}
\Hypertarget{_debug_8h_ada3de6ba49d97903fbf36000cc99d55d}\index{Debug.h@{Debug.h}!INFO\_PRINT@{INFO\_PRINT}}
\index{INFO\_PRINT@{INFO\_PRINT}!Debug.h@{Debug.h}}
\doxysubsubsection{\texorpdfstring{INFO\_PRINT}{INFO\_PRINT}}
{\footnotesize\ttfamily \label{_debug_8h_ada3de6ba49d97903fbf36000cc99d55d} 
\#define INFO\+\_\+\+PRINT(\begin{DoxyParamCaption}\item[{}]{x}{}\end{DoxyParamCaption})}

{\bfseries Value\+:}
\begin{DoxyCode}{0}
\DoxyCodeLine{Serial.print((String)\ \textcolor{stringliteral}{"{}INFO:\ "{}}\ +\ x\ +\ \ MACRO\_LOCATION)}

\end{DoxyCode}

Print an info-\/level message without newline. 

Expands to Serial.\+print with "{}\+INFO\+: "{} prefix and optional file/line info. 
\begin{DoxyParams}{Parameters}
{\em x} & Expression or string to print (will be converted to String). \\
\hline
\end{DoxyParams}
\Hypertarget{_debug_8h_a693063ba84ad2119e7f3ea1b97947055}\index{Debug.h@{Debug.h}!INFO\_PRINTLN@{INFO\_PRINTLN}}
\index{INFO\_PRINTLN@{INFO\_PRINTLN}!Debug.h@{Debug.h}}
\doxysubsubsection{\texorpdfstring{INFO\_PRINTLN}{INFO\_PRINTLN}}
{\footnotesize\ttfamily \label{_debug_8h_a693063ba84ad2119e7f3ea1b97947055} 
\#define INFO\+\_\+\+PRINTLN(\begin{DoxyParamCaption}\item[{}]{x}{}\end{DoxyParamCaption})}

{\bfseries Value\+:}
\begin{DoxyCode}{0}
\DoxyCodeLine{Serial.println((String)\ \textcolor{stringliteral}{"{}INFO:\ "{}}\ +\ x\ +\ \ MACRO\_LOCATION)}

\end{DoxyCode}

Print an info-\/level message with newline. 

Expands to Serial.\+println with "{}\+INFO\+: "{} prefix and optional file/line info. 
\begin{DoxyParams}{Parameters}
{\em x} & Expression or string to print (will be converted to String). \\
\hline
\end{DoxyParams}
\Hypertarget{_debug_8h_ac55217e6814de7894a11b7e7cd54f708}\index{Debug.h@{Debug.h}!INSTRUCTION\_PRINT@{INSTRUCTION\_PRINT}}
\index{INSTRUCTION\_PRINT@{INSTRUCTION\_PRINT}!Debug.h@{Debug.h}}
\doxysubsubsection{\texorpdfstring{INSTRUCTION\_PRINT}{INSTRUCTION\_PRINT}}
{\footnotesize\ttfamily \label{_debug_8h_ac55217e6814de7894a11b7e7cd54f708} 
\#define INSTRUCTION\+\_\+\+PRINT(\begin{DoxyParamCaption}\item[{}]{x}{}\end{DoxyParamCaption})}

{\bfseries Value\+:}
\begin{DoxyCode}{0}
\DoxyCodeLine{Serial.print((String)\ \textcolor{stringliteral}{"{}INSTRUCTION:\ "{}}\ +\ x\ +\ MACRO\_LOCATION)}

\end{DoxyCode}

Print a INSTRUCTION message without newline. 

Expands to Serial.\+print with "{}\+INSTRUCTION\+: "{} prefix and optional file/line info. 
\begin{DoxyParams}{Parameters}
{\em x} & Expression or string to print (will be converted to String). \\
\hline
\end{DoxyParams}
\Hypertarget{_debug_8h_a625610458d92e74e7a0eb4dbe1d78c79}\index{Debug.h@{Debug.h}!INSTRUCTION\_PRINTLN@{INSTRUCTION\_PRINTLN}}
\index{INSTRUCTION\_PRINTLN@{INSTRUCTION\_PRINTLN}!Debug.h@{Debug.h}}
\doxysubsubsection{\texorpdfstring{INSTRUCTION\_PRINTLN}{INSTRUCTION\_PRINTLN}}
{\footnotesize\ttfamily \label{_debug_8h_a625610458d92e74e7a0eb4dbe1d78c79} 
\#define INSTRUCTION\+\_\+\+PRINTLN(\begin{DoxyParamCaption}\item[{}]{x}{}\end{DoxyParamCaption})}

{\bfseries Value\+:}
\begin{DoxyCode}{0}
\DoxyCodeLine{Serial.println((String)\ \textcolor{stringliteral}{"{}INSTRUCTION:\ "{}}\ +\ x\ +\ MACRO\_LOCATION)}

\end{DoxyCode}

Print a INSTRUCTION message without newline. 

Expands to Serial.\+println with "{}\+INSTRUCTION\+: "{} prefix and optional file/line info. 
\begin{DoxyParams}{Parameters}
{\em x} & Expression or string to print (will be converted to String). \\
\hline
\end{DoxyParams}
\Hypertarget{_debug_8h_af1bb2a2c18de0a487366724efb4f1b8c}\index{Debug.h@{Debug.h}!MEASUREMENT\_PRINT@{MEASUREMENT\_PRINT}}
\index{MEASUREMENT\_PRINT@{MEASUREMENT\_PRINT}!Debug.h@{Debug.h}}
\doxysubsubsection{\texorpdfstring{MEASUREMENT\_PRINT}{MEASUREMENT\_PRINT}}
{\footnotesize\ttfamily \label{_debug_8h_af1bb2a2c18de0a487366724efb4f1b8c} 
\#define MEASUREMENT\+\_\+\+PRINT(\begin{DoxyParamCaption}\item[{}]{x}{}\end{DoxyParamCaption})}

{\bfseries Value\+:}
\begin{DoxyCode}{0}
\DoxyCodeLine{Serial.print((String)\ \textcolor{stringliteral}{"{}MEASUREMENT:\ "{}}\ +\ x\ +\ MACRO\_LOCATION)}

\end{DoxyCode}

Print a measurement message without newline. 

Expands to Serial.\+print with "{}\+MEASUREMENT\+: "{} prefix and optional file/line info. 
\begin{DoxyParams}{Parameters}
{\em x} & Expression or string to print (will be converted to String). \\
\hline
\end{DoxyParams}
\Hypertarget{_debug_8h_aee4ea675d26ff667e6641d91ccc5bf1a}\index{Debug.h@{Debug.h}!MEASUREMENT\_PRINTLN@{MEASUREMENT\_PRINTLN}}
\index{MEASUREMENT\_PRINTLN@{MEASUREMENT\_PRINTLN}!Debug.h@{Debug.h}}
\doxysubsubsection{\texorpdfstring{MEASUREMENT\_PRINTLN}{MEASUREMENT\_PRINTLN}}
{\footnotesize\ttfamily \label{_debug_8h_aee4ea675d26ff667e6641d91ccc5bf1a} 
\#define MEASUREMENT\+\_\+\+PRINTLN(\begin{DoxyParamCaption}\item[{}]{x}{}\end{DoxyParamCaption})}

{\bfseries Value\+:}
\begin{DoxyCode}{0}
\DoxyCodeLine{Serial.println((String)\ \textcolor{stringliteral}{"{}MEASUREMENT:\ "{}}\ +\ x\ +\ MACRO\_LOCATION)}

\end{DoxyCode}

Print a measurement message with newline. 

Expands to Serial.\+println with "{}\+MEASUREMENT\+: "{} prefix and optional file/line info. 
\begin{DoxyParams}{Parameters}
{\em x} & Expression or string to print (will be converted to String). \\
\hline
\end{DoxyParams}
\Hypertarget{_debug_8h_a98e7c49c7900880470d265bce927fba1}\index{Debug.h@{Debug.h}!NULL\_PTR\_CHECK@{NULL\_PTR\_CHECK}}
\index{NULL\_PTR\_CHECK@{NULL\_PTR\_CHECK}!Debug.h@{Debug.h}}
\doxysubsubsection{\texorpdfstring{NULL\_PTR\_CHECK}{NULL\_PTR\_CHECK}}
{\footnotesize\ttfamily \label{_debug_8h_a98e7c49c7900880470d265bce927fba1} 
\#define NULL\+\_\+\+PTR\+\_\+\+CHECK(\begin{DoxyParamCaption}\item[{}]{ptr}{}\end{DoxyParamCaption})}

{\bfseries Value\+:}
\begin{DoxyCode}{0}
\DoxyCodeLine{\ \ \ \ \textcolor{keywordflow}{if}\ (ptr\ ==\ \textcolor{keyword}{nullptr})\ \{\ \ \ \ \ \ \ \ \ \ \ \ \ \ \ \ \ \ \ \ \ \ \ \ \ \ \ \ \ \ \ \ \ \ \ \ \ \(\backslash\)}
\DoxyCodeLine{\ \ \ \ \ \ \ \ CRITICAL\_ERROR\_PRINTLN(\textcolor{stringliteral}{"{}Null\ pointer\ exception:\ "{}}\ +\ \#ptr);\ \(\backslash\)}
\DoxyCodeLine{\ \ \ \ \}}

\end{DoxyCode}

Check a pointer for null and report a critical error if null. 

Evaluates the provided pointer expression and if it is nullptr, prints a critical error with the pointer name and halts execution. 
\begin{DoxyParams}{Parameters}
{\em ptr} & Pointer expression to check. \\
\hline
\end{DoxyParams}
\begin{DoxyReturn}{Returns}
This macro does not return on failure; execution halts in an infinite loop after reporting the error. 
\end{DoxyReturn}
\Hypertarget{_debug_8h_af25901a0f15375b04a19c6089aba7abe}\index{Debug.h@{Debug.h}!WARNING\_PRINT@{WARNING\_PRINT}}
\index{WARNING\_PRINT@{WARNING\_PRINT}!Debug.h@{Debug.h}}
\doxysubsubsection{\texorpdfstring{WARNING\_PRINT}{WARNING\_PRINT}}
{\footnotesize\ttfamily \label{_debug_8h_af25901a0f15375b04a19c6089aba7abe} 
\#define WARNING\+\_\+\+PRINT(\begin{DoxyParamCaption}\item[{}]{x}{}\end{DoxyParamCaption})}

{\bfseries Value\+:}
\begin{DoxyCode}{0}
\DoxyCodeLine{Serial.print((String)\ \textcolor{stringliteral}{"{}WARNING:\ "{}}\ +\ x\ +\ \ MACRO\_LOCATION)}

\end{DoxyCode}

Print a warning-\/level message without newline. 

Expands to Serial.\+print with "{}\+WARNING\+: "{} prefix and optional file/line info. 
\begin{DoxyParams}{Parameters}
{\em x} & Expression or string to print (will be converted to String). \\
\hline
\end{DoxyParams}
\Hypertarget{_debug_8h_a2ab63874bfdcb0637ccb2dff37bdb8af}\index{Debug.h@{Debug.h}!WARNING\_PRINTLN@{WARNING\_PRINTLN}}
\index{WARNING\_PRINTLN@{WARNING\_PRINTLN}!Debug.h@{Debug.h}}
\doxysubsubsection{\texorpdfstring{WARNING\_PRINTLN}{WARNING\_PRINTLN}}
{\footnotesize\ttfamily \label{_debug_8h_a2ab63874bfdcb0637ccb2dff37bdb8af} 
\#define WARNING\+\_\+\+PRINTLN(\begin{DoxyParamCaption}\item[{}]{x}{}\end{DoxyParamCaption})}

{\bfseries Value\+:}
\begin{DoxyCode}{0}
\DoxyCodeLine{Serial.println((String)\ \textcolor{stringliteral}{"{}WARNING:\ "{}}\ +\ x\ +\ \ MACRO\_LOCATION)}

\end{DoxyCode}

Print a warning-\/level message with newline. 

Expands to Serial.\+println with "{}\+WARNING\+: "{} prefix and optional file/line info. 
\begin{DoxyParams}{Parameters}
{\em x} & Expression or string to print (will be converted to String). \\
\hline
\end{DoxyParams}

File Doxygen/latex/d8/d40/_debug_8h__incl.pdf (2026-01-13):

C:/Users/leowa/Documents
/PlatformIO/Projects/CANTramFramework Usage/lib/CANTramFramework/include/Debug.h

Arduino.h

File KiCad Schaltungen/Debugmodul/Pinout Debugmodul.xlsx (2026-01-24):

Software Adresse | Hardware Pins | Kontakte |  | Hardware Pins | Software Adresse
GENERAL_ENABLE | SR_8 | 40 | 39 | x
 | x | 38 | 37 | x
 | x | 36 | 35 | x
24 | SR_9 | 34 | 33 | SR_7 | 23
22 | SR_10 | 32 | 31 | SR_6 | 21
20 | SR_11 | 30 | 29 | SR_5 | 19
18 | SR_12 | 28 | 27 | SR_4 | 17
16 | SR_13 | 26 | 25 | SR_3 | 15
14 | SR_14 | 24 | 23 | SR_2 | 13
12 | SR_15 | 22 | 21 | GPIO_5 | 11
10 | GPIO_27 | 20 | 19 | GPIO_4 | 9
8 | GPIO_26 | 18 | 17 | GPIO_0 | 7
6 | GPIO_25 | 16 | 15 | GPIO_2 | 5
4 | GPIO_33 | 14 | 13 | GPIO_15 | 3
2 | GPIO_32 | 12 | 11 | GPIO_19 | 1 / UART_TX
0 / UART_RX | GPIO_23 | 10 | 9 | I2C_SCL
 | I2C_SDA | 8 | 7 | GPIO_34 | INT
 | SPI_SCK | 6 | 5 | SPI_CIPO
 | SPI_COPI | 4 | 3 | GND
 | 3V3 | 2 | 1 | 5V

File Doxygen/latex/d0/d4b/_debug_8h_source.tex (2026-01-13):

\doxysection{Debug.\+h}
\hypertarget{_debug_8h_source}{}\label{_debug_8h_source}\index{C:/Users/leowa/Documents/PlatformIO/Projects/CANTramFrameworkUsage/lib/CANTramFramework/include/Debug.h@{C:/Users/leowa/Documents/PlatformIO/Projects/CANTramFrameworkUsage/lib/CANTramFramework/include/Debug.h}}
\mbox{\hyperlink{_debug_8h}{Go to the documentation of this file.}}
\begin{DoxyCode}{0}
\DoxyCodeLine{00001\ \textcolor{preprocessor}{\#pragma\ once}}
\DoxyCodeLine{00002\ }
\DoxyCodeLine{00003\ \textcolor{preprocessor}{\#include\ <Arduino.h>}}
\DoxyCodeLine{00004\ }
\DoxyCodeLine{00012\ }
\DoxyCodeLine{00017\ \textcolor{comment}{//\ \#define\ NO\_OUTPUT\ //\ Uncomment\ to\ disable\ all\ output}}
\DoxyCodeLine{00018\ \textcolor{preprocessor}{\#ifndef\ NO\_OUTPUT}}
\DoxyCodeLine{00019\ \textcolor{preprocessor}{\#define\ DEBUG\_OUTPUT\ \ \ \ \ \ \ \ \ \ }\textcolor{comment}{//\ Comment\ out\ to\ disable\ debug\ output}}
\DoxyCodeLine{00020\ \textcolor{preprocessor}{\#define\ INFO\_OUTPUT\ \ \ \ \ \ \ \ \ \ \ }\textcolor{comment}{//\ Comment\ out\ to\ disable\ info\ output}}
\DoxyCodeLine{00021\ \textcolor{preprocessor}{\#define\ ERROR\_OUTPUT\ \ \ \ \ \ \ \ \ \ }\textcolor{comment}{//\ Comment\ out\ to\ disable\ error\ output}}
\DoxyCodeLine{00022\ \textcolor{preprocessor}{\#define\ WARNING\_OUTPUT\ \ \ \ \ \ \ \ }\textcolor{comment}{//\ Comment\ out\ to\ disable\ warning\ output}}
\DoxyCodeLine{00023\ \textcolor{preprocessor}{\#define\ CRITICAL\_ERROR\_OUTPUT\ }\textcolor{comment}{//\ Comment\ out\ to\ disable\ critical\ error\ output}}
\DoxyCodeLine{00024\ \textcolor{preprocessor}{\#define\ DEV\_ERROR\_OUTPUT}}
\DoxyCodeLine{00025\ \textcolor{preprocessor}{\#define\ INSTRUCTION\_OUTPUT\ \ \ \ }\textcolor{comment}{//\ Comment\ out\ to\ disable\ instruction\ output}}
\DoxyCodeLine{00026\ \textcolor{preprocessor}{\#define\ CHIP\_OUTPUT\ \ \ \ \ \ \ \ \ \ \ }\textcolor{comment}{//\ Comment\ out\ to\ disable\ chip\ output}}
\DoxyCodeLine{00027\ \textcolor{preprocessor}{\#define\ MEASUREMENT\_OUTPUT\ \ \ \ }\textcolor{comment}{//\ Comment\ out\ to\ disable\ measurement\ output}}
\DoxyCodeLine{00028\ \textcolor{preprocessor}{\#endif}}
\DoxyCodeLine{00029\ }
\DoxyCodeLine{00036\ \textcolor{preprocessor}{\#ifdef\ DEBUG\_SHOW\_LOCATION}}
\DoxyCodeLine{00037\ \textcolor{preprocessor}{\ \ \ \ \#define\ MACRO\_LOCATION\ ("{}\(\backslash\)n"{}\ +\ String(\_\_FILE\_\_)\ +\ "{}:"{}\ +\ String(\_\_LINE\_\_))}}
\DoxyCodeLine{00038\ \textcolor{preprocessor}{\#else}}
\DoxyCodeLine{00039\ \textcolor{preprocessor}{\ \ \ \ \#define\ MACRO\_LOCATION\ "{}"{}}}
\DoxyCodeLine{00040\ \textcolor{preprocessor}{\#endif}}
\DoxyCodeLine{00041\ }
\DoxyCodeLine{00048\ \textcolor{preprocessor}{\#ifdef\ DEBUG\_OUTPUT}}
\DoxyCodeLine{00049\ \textcolor{preprocessor}{\#define\ DEBUG\_PRINT(x)\ Serial.print((String)\ "{}DEBUG:\ "{}\ +\ x\ +\ MACRO\_LOCATION)}}
\DoxyCodeLine{00050\ \textcolor{preprocessor}{\#else}}
\DoxyCodeLine{00051\ \textcolor{preprocessor}{\#define\ DEBUG\_PRINT(x)}}
\DoxyCodeLine{00052\ \textcolor{preprocessor}{\#endif}}
\DoxyCodeLine{00053\ }
\DoxyCodeLine{00054\ }
\DoxyCodeLine{00055\ }
\DoxyCodeLine{00062\ \textcolor{preprocessor}{\#ifdef\ DEBUG\_OUTPUT}}
\DoxyCodeLine{00063\ \textcolor{preprocessor}{\#define\ DEBUG\_PRINTLN(x)\ Serial.println((String)\ "{}DEBUG:\ "{}\ +\ x\ +\ MACRO\_LOCATION)}}
\DoxyCodeLine{00064\ \textcolor{preprocessor}{\#else}}
\DoxyCodeLine{00065\ \textcolor{preprocessor}{\#define\ DEBUG\_PRINTLN(x)}}
\DoxyCodeLine{00066\ \textcolor{preprocessor}{\#endif}}
\DoxyCodeLine{00067\ }
\DoxyCodeLine{00074\ \textcolor{preprocessor}{\#ifdef\ MEASUREMENT\_OUTPUT}}
\DoxyCodeLine{00075\ \textcolor{preprocessor}{\#define\ MEASUREMENT\_PRINT(x)\ Serial.print((String)\ "{}MEASUREMENT:\ "{}\ +\ x\ +\ MACRO\_LOCATION)}}
\DoxyCodeLine{00076\ \textcolor{preprocessor}{\#else}}
\DoxyCodeLine{00077\ \textcolor{preprocessor}{\#define\ MEASUREMENT\_PRINT(x)}}
\DoxyCodeLine{00078\ \textcolor{preprocessor}{\#endif}}
\DoxyCodeLine{00079\ }
\DoxyCodeLine{00080\ }
\DoxyCodeLine{00081\ }
\DoxyCodeLine{00088\ \textcolor{preprocessor}{\#ifdef\ MEASUREMENT\_OUTPUT}}
\DoxyCodeLine{00089\ \textcolor{preprocessor}{\#define\ MEASUREMENT\_PRINTLN(x)\ Serial.println((String)\ "{}MEASUREMENT:\ "{}\ +\ x\ +\ MACRO\_LOCATION)}}
\DoxyCodeLine{00090\ \textcolor{preprocessor}{\#else}}
\DoxyCodeLine{00091\ \textcolor{preprocessor}{\#define\ MEASUREMENT\_PRINTLN(x)}}
\DoxyCodeLine{00092\ \textcolor{preprocessor}{\#endif}}
\DoxyCodeLine{00093\ }
\DoxyCodeLine{00100\ \textcolor{preprocessor}{\#ifdef\ INSTRUCTION\_OUTPUT}}
\DoxyCodeLine{00101\ \textcolor{preprocessor}{\#define\ INSTRUCTION\_PRINT(x)\ Serial.print((String)\ "{}INSTRUCTION:\ "{}\ +\ x\ +\ MACRO\_LOCATION)}}
\DoxyCodeLine{00102\ \textcolor{preprocessor}{\#else}}
\DoxyCodeLine{00103\ \textcolor{preprocessor}{\#define\ INSTRUCTION\_PRINT(x)}}
\DoxyCodeLine{00104\ \textcolor{preprocessor}{\#endif}}
\DoxyCodeLine{00105\ }
\DoxyCodeLine{00112\ \textcolor{preprocessor}{\#ifdef\ INSTRUCTION\_OUTPUT}}
\DoxyCodeLine{00113\ \textcolor{preprocessor}{\#define\ INSTRUCTION\_PRINTLN(x)\ Serial.println((String)\ "{}INSTRUCTION:\ "{}\ +\ x\ +\ MACRO\_LOCATION)}}
\DoxyCodeLine{00114\ \textcolor{preprocessor}{\#else}}
\DoxyCodeLine{00115\ \textcolor{preprocessor}{\#define\ INSTRUCTION\_PRINTLN(x)}}
\DoxyCodeLine{00116\ \textcolor{preprocessor}{\#endif}}
\DoxyCodeLine{00117\ }
\DoxyCodeLine{00124\ \textcolor{preprocessor}{\#ifdef\ INFO\_OUTPUT}}
\DoxyCodeLine{00125\ \textcolor{preprocessor}{\#define\ INFO\_PRINT(x)\ Serial.print((String)\ "{}INFO:\ "{}\ +\ x\ +\ \ MACRO\_LOCATION)}}
\DoxyCodeLine{00126\ \textcolor{preprocessor}{\#else}}
\DoxyCodeLine{00127\ \textcolor{preprocessor}{\#define\ INFO\_PRINT(x)}}
\DoxyCodeLine{00128\ \textcolor{preprocessor}{\#endif}}
\DoxyCodeLine{00129\ }
\DoxyCodeLine{00136\ \textcolor{preprocessor}{\#ifdef\ INFO\_OUTPUT}}
\DoxyCodeLine{00137\ \textcolor{preprocessor}{\#define\ INFO\_PRINTLN(x)\ Serial.println((String)\ "{}INFO:\ "{}\ +\ x\ +\ \ MACRO\_LOCATION)}}
\DoxyCodeLine{00138\ \textcolor{preprocessor}{\#else}}
\DoxyCodeLine{00139\ \textcolor{preprocessor}{\#define\ INFO\_PRINTLN(x)}}
\DoxyCodeLine{00140\ \textcolor{preprocessor}{\#endif}}
\DoxyCodeLine{00141\ }
\DoxyCodeLine{00148\ \textcolor{preprocessor}{\#ifdef\ ERROR\_OUTPUT}}
\DoxyCodeLine{00149\ \textcolor{preprocessor}{\#define\ ERROR\_PRINT(x)\ Serial.print((String)\ "{}ERROR:\ "{}\ +\ x\ +\ \ MACRO\_LOCATION)}}
\DoxyCodeLine{00150\ \textcolor{preprocessor}{\#else}}
\DoxyCodeLine{00151\ \textcolor{preprocessor}{\#define\ ERROR\_PRINT(x)}}
\DoxyCodeLine{00152\ \textcolor{preprocessor}{\#endif}}
\DoxyCodeLine{00153\ }
\DoxyCodeLine{00160\ \textcolor{preprocessor}{\#ifdef\ ERROR\_OUTPUT}}
\DoxyCodeLine{00161\ \textcolor{preprocessor}{\#define\ ERROR\_PRINTLN(x)\ Serial.println((String)\ "{}ERROR:\ "{}\ +\ x\ +\ \ MACRO\_LOCATION)}}
\DoxyCodeLine{00162\ \textcolor{preprocessor}{\#else}}
\DoxyCodeLine{00163\ \textcolor{preprocessor}{\#define\ ERROR\_PRINTLN(x)}}
\DoxyCodeLine{00164\ \textcolor{preprocessor}{\#endif}}
\DoxyCodeLine{00165\ }
\DoxyCodeLine{00172\ \textcolor{preprocessor}{\#ifdef\ WARNING\_OUTPUT}}
\DoxyCodeLine{00173\ \textcolor{preprocessor}{\#define\ WARNING\_PRINT(x)\ Serial.print((String)\ "{}WARNING:\ "{}\ +\ x\ +\ \ MACRO\_LOCATION)}}
\DoxyCodeLine{00174\ \textcolor{preprocessor}{\#else}}
\DoxyCodeLine{00175\ \textcolor{preprocessor}{\#define\ WARNING\_PRINT(x)}}
\DoxyCodeLine{00176\ \textcolor{preprocessor}{\#endif}}
\DoxyCodeLine{00177\ }
\DoxyCodeLine{00184\ \textcolor{preprocessor}{\#ifdef\ WARNING\_OUTPUT}}
\DoxyCodeLine{00185\ \textcolor{preprocessor}{\#define\ WARNING\_PRINTLN(x)\ Serial.println((String)\ "{}WARNING:\ "{}\ +\ x\ +\ \ MACRO\_LOCATION)}}
\DoxyCodeLine{00186\ \textcolor{preprocessor}{\#else}}
\DoxyCodeLine{00187\ \textcolor{preprocessor}{\#define\ WARNING\_PRINTLN(x)}}
\DoxyCodeLine{00188\ \textcolor{preprocessor}{\#endif}}
\DoxyCodeLine{00189\ }
\DoxyCodeLine{00196\ \textcolor{preprocessor}{\#ifdef\ DEV\_ERROR\_OUTPUT}}
\DoxyCodeLine{00197\ \textcolor{preprocessor}{\#define\ DEV\_ERROR\_PRINT(x)\ Serial.print((String)\ "{}DEV\_ERROR:\ "{}\ +\ x\ +\ \ MACRO\_LOCATION)}}
\DoxyCodeLine{00198\ \textcolor{preprocessor}{\#else}}
\DoxyCodeLine{00199\ \textcolor{preprocessor}{\#define\ DEV\_ERROR\_PRINT(x)}}
\DoxyCodeLine{00200\ \textcolor{preprocessor}{\#endif}}
\DoxyCodeLine{00201\ }
\DoxyCodeLine{00208\ \textcolor{preprocessor}{\#ifdef\ DEV\_ERROR\_OUTPUT}}
\DoxyCodeLine{00209\ \textcolor{preprocessor}{\#define\ DEV\_ERROR\_PRINTLN(x)\ Serial.println((String)\ "{}DEV\_ERROR:\ "{}\ +\ x\ +\ \ MACRO\_LOCATION)}}
\DoxyCodeLine{00210\ \textcolor{preprocessor}{\#else}}
\DoxyCodeLine{00211\ \textcolor{preprocessor}{\#define\ DEV\_ERROR\_PRINTLN(x)}}
\DoxyCodeLine{00212\ \textcolor{preprocessor}{\#endif}}
\DoxyCodeLine{00213\ }
\DoxyCodeLine{00220\ \textcolor{preprocessor}{\#ifdef\ CHIP\_OUTPUT}}
\DoxyCodeLine{00221\ \textcolor{preprocessor}{\#define\ CHIP\_PRINT(x)\ Serial.print((String)\ "{}CHIP:\ "{}\ +\ x\ +\ \ MACRO\_LOCATION)}}
\DoxyCodeLine{00222\ \textcolor{preprocessor}{\#else}}
\DoxyCodeLine{00223\ \textcolor{preprocessor}{\#define\ CHIP\_PRINT(x)}}
\DoxyCodeLine{00224\ \textcolor{preprocessor}{\#endif}}
\DoxyCodeLine{00225\ }
\DoxyCodeLine{00232\ \textcolor{preprocessor}{\#ifdef\ CHIP\_OUTPUT}}
\DoxyCodeLine{00233\ \textcolor{preprocessor}{\#define\ CHIP\_PRINTLN(x)\ Serial.println((String)\ "{}CHIP:\ "{}\ +\ x\ +\ \ MACRO\_LOCATION)}}
\DoxyCodeLine{00234\ \textcolor{preprocessor}{\#else}}
\DoxyCodeLine{00235\ \textcolor{preprocessor}{\#define\ CHIP\_PRINTLN(x)}}
\DoxyCodeLine{00236\ \textcolor{preprocessor}{\#endif}}
\DoxyCodeLine{00237\ }
\DoxyCodeLine{00245\ \textcolor{preprocessor}{\#ifdef\ CRITICAL\_ERROR\_OUTPUT}}
\DoxyCodeLine{00246\ \textcolor{preprocessor}{\#define\ CRITICAL\_ERROR\_PRINT(x)\ \ \ \ \ \ \ \ \ \ \ \ \ \ \ \ \ \ \ \ \ \ \ \ \ \ \ \ \ \ \ \ \ \ \ \ \ \ \ \ \ \ \ \ \(\backslash\)}}
\DoxyCodeLine{00247\ \textcolor{preprocessor}{\ \ \ \ Serial.print((String)\ "{}CRITICAL\ ERROR:\ "{}\ +\ x\ +\ \ MACRO\_LOCATION);\ \(\backslash\)}}
\DoxyCodeLine{00248\ \textcolor{preprocessor}{\ \ \ \ while\ (true)}}
\DoxyCodeLine{00249\ \textcolor{preprocessor}{\#else}}
\DoxyCodeLine{00250\ \textcolor{preprocessor}{\#define\ CRITICAL\_ERROR\_PRINT(x)}}
\DoxyCodeLine{00251\ \textcolor{preprocessor}{\#endif}}
\DoxyCodeLine{00252\ }
\DoxyCodeLine{00260\ \textcolor{preprocessor}{\#ifdef\ CRITICAL\_ERROR\_OUTPUT}}
\DoxyCodeLine{00261\ \textcolor{preprocessor}{\#define\ CRITICAL\_ERROR\_PRINTLN(x)\ \ \ \ \ \ \ \ \ \ \ \ \ \ \ \ \ \ \ \ \ \ \ \ \ \ \ \ \ \ \ \ \ \ \ \ \ \ \ \ \ \ \ \ \(\backslash\)}}
\DoxyCodeLine{00262\ \textcolor{preprocessor}{\ \ \ \ Serial.println((String)\ "{}CRITICAL\ ERROR:\ "{}\ +\ x\ +\ \ MACRO\_LOCATION);\ \(\backslash\)}}
\DoxyCodeLine{00263\ \textcolor{preprocessor}{\ \ \ \ while\ (true)}}
\DoxyCodeLine{00264\ \textcolor{preprocessor}{\#else}}
\DoxyCodeLine{00265\ \textcolor{preprocessor}{\#define\ CRITICAL\_ERROR\_PRINTLN(x)}}
\DoxyCodeLine{00266\ \textcolor{preprocessor}{\#endif}}
\DoxyCodeLine{00267\ }
\DoxyCodeLine{00275\ \textcolor{preprocessor}{\#define\ NULL\_PTR\_CHECK(ptr)\ \ \ \ \ \ \ \ \ \ \ \ \ \ \ \ \ \ \ \ \ \ \ \ \ \ \ \ \ \ \ \ \ \ \ \ \ \ \(\backslash\)}}
\DoxyCodeLine{00276\ \textcolor{preprocessor}{\ \ \ \ if\ (ptr\ ==\ nullptr)\ \{\ \ \ \ \ \ \ \ \ \ \ \ \ \ \ \ \ \ \ \ \ \ \ \ \ \ \ \ \ \ \ \ \ \ \ \ \ \(\backslash\)}}
\DoxyCodeLine{00277\ \textcolor{preprocessor}{\ \ \ \ \ \ \ \ CRITICAL\_ERROR\_PRINTLN("{}Null\ pointer\ exception:\ "{}\ +\ \#ptr);\ \(\backslash\)}}
\DoxyCodeLine{00278\ \textcolor{preprocessor}{\ \ \ \ \}}}
\DoxyCodeLine{00279\ }

\end{DoxyCode}

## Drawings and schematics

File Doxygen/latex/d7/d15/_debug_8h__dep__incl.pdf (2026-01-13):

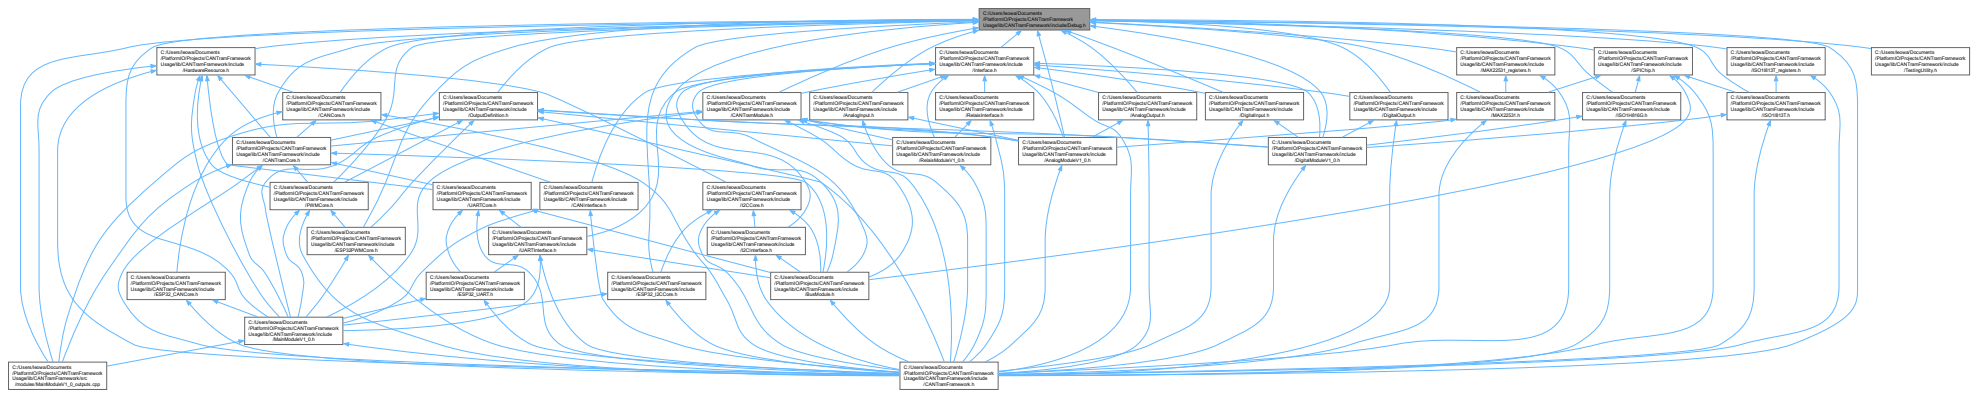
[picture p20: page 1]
/AnalogInput.h; /AnalogModuleV1_0.h; /CANTramFramework.h; /AnalogOutput.h; /BusModule.h; /CANCore.h; /MainModuleV1_0.h; /CANTramCore.h; /PWMCore.h; /ESP32PWMCore.h; /CANTramModule.h; /DigitalModuleV1_0.h; /DigitalInput.h; /DigitalOutput.h; /ESP32_I2CCore.h; /HardwareResource.h; /ISO1H816G.h; /ISO1I813T.h; /ISO1I813T_registers.h; /Interface.h; /MAX22531.h; /MAX22531_registers.h; /OutputDefinition.h; /SPIChip.h; /TestingUtility.h; /CANInterface.h; /ESP32_CANCore.h; /UARTCore.h; /ESP32_UART.h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

C:/Users/leowa/Documents
/PlatformIO/Projects/CANTramFramework
Usage/lib/CANTramFramework/include/Debug.h

Usage/lib/CANTramFramework/include

Usage/lib/CANTramFramework/src
/modules/MainModuleV1_0_outputs.cpp

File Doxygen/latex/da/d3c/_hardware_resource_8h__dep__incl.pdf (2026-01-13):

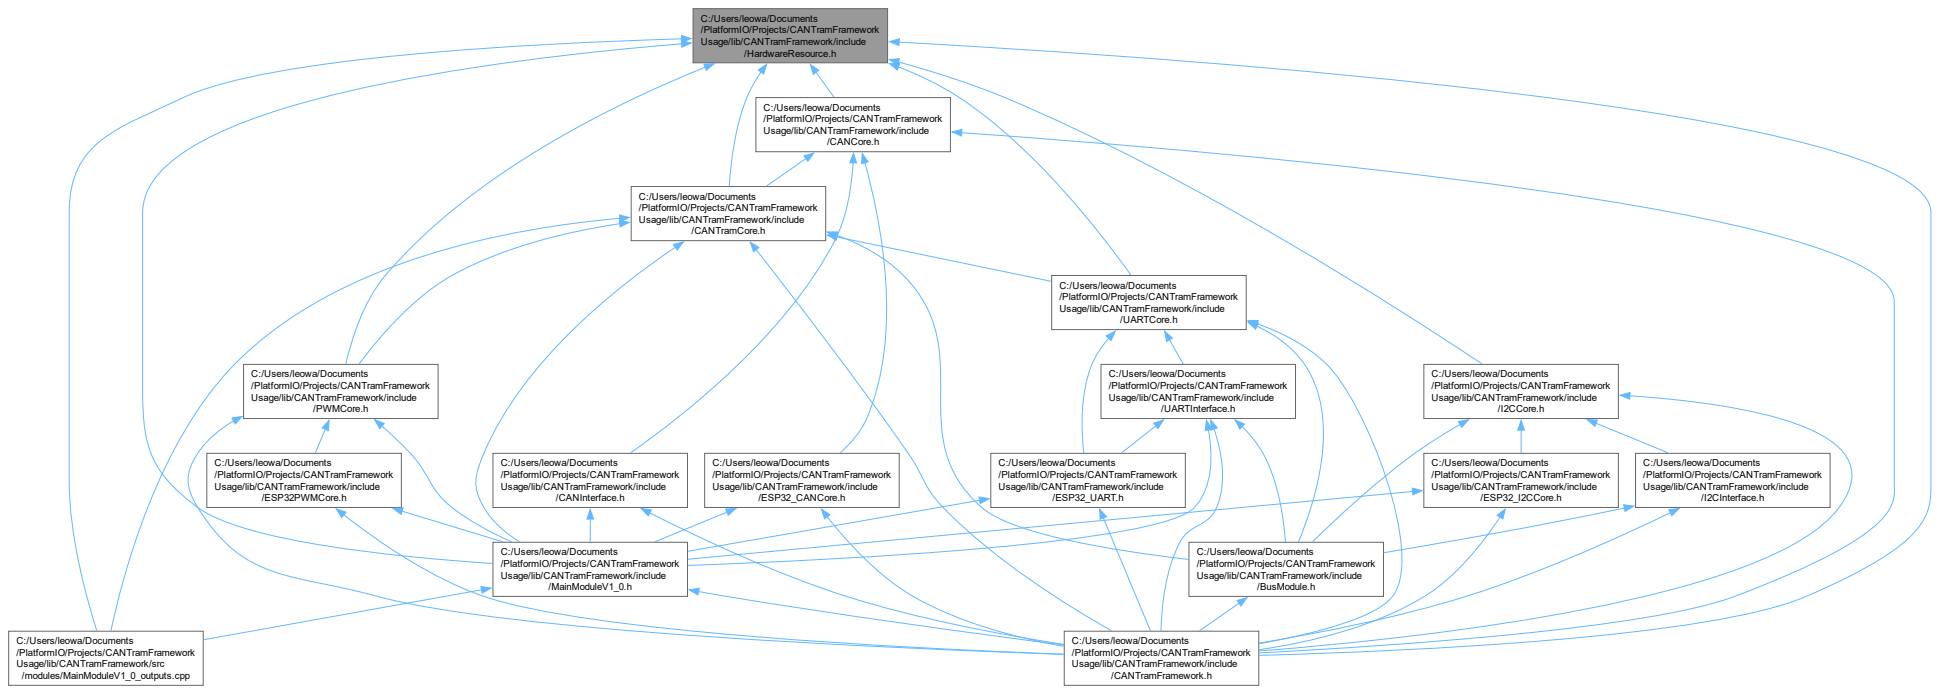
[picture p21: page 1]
/HardwareResource.h; /CANCore.h; /CANTramFramework.h; /MainModuleV1_0.h; /CANTramCore.h; /PWMCore.h; /UARTCore.h; /I2CCore.h; /CANInterface.h; /ESP32_CANCore.h; /BusModule.h; /ESP32PWMCore.h; /ESP32_UART.h; /UARTInterface.h; /ESP32_I2CCore.h; /I2CInterface.h

C:/Users/leowa/Documents
/PlatformIO/Projects/CANTramFramework
Usage/lib/CANTramFramework/include

Usage/lib/CANTramFramework/src
/modules/MainModuleV1_0_outputs.cpp

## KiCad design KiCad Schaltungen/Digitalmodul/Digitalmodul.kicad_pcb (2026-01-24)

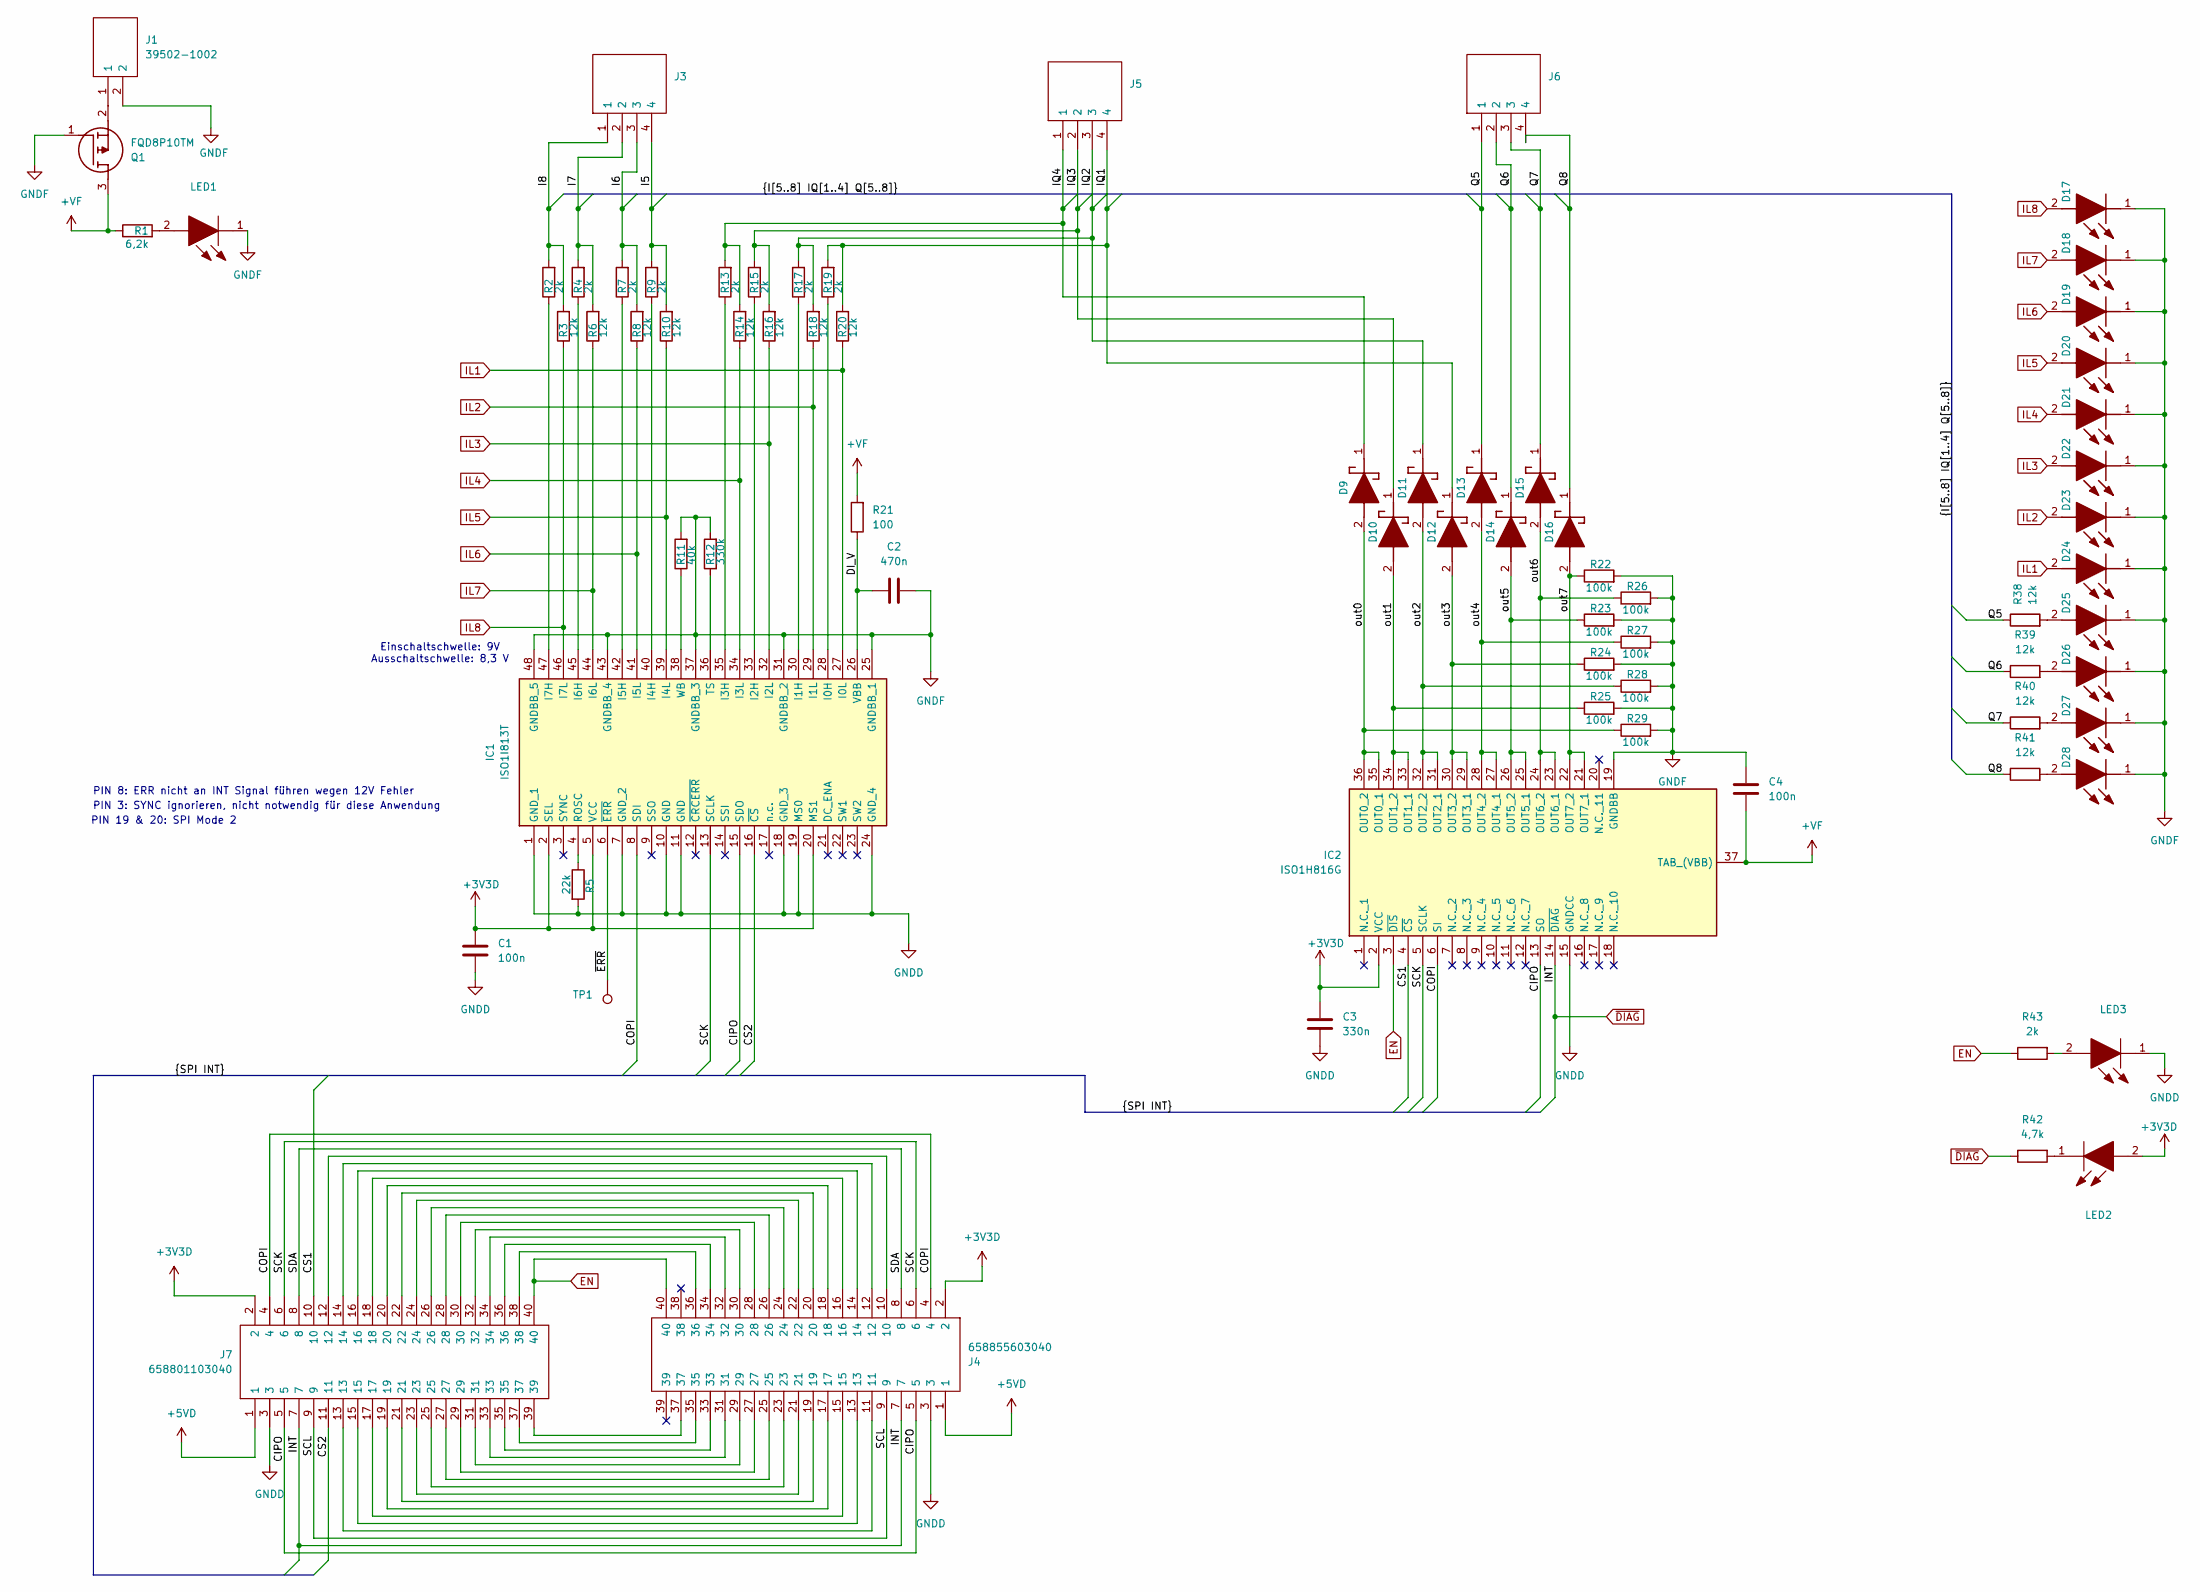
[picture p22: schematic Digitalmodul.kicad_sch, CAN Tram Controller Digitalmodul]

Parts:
C1, C4: 100n; C_1206_3216Metric
C2: 470n; C_1206_3216Metric
C3: 330n; C_1206_3216Metric
D9, D10, D11, D12, D13, D14, D15, D16: SS24FL; SODFL3617X108N; Mouser Part Number 512-SS24FL
D17, D18, D19, D20, D21, D22, D23, D24, D25, D26, D27, D28: 156120YS75000; LEDC5017X140N; Mouser Part Number 710-156120YS75000
IC1: ISO1I813T; SOP50P810X110-48N; Mouser Part Number 726-ISO1I813T
IC2: ISO1H816G; SOP65P1420X350-37N; Mouser Part Number 726-ISO1H816G
J1: 39502-1002; SHDR2W80P0X350_1X2_840X920X690P; Mouser Part Number 538-39502-1002
J3, J5, J6: 39502-1004; SHDRRA4W80P0X350_1X4_1540X920X730P; Mouser Part Number 538-39502-1004
J4: 658855603040; Mouser Part Number 710-658855603040
J7: 658801103040; Mouser Part Number 710-658801103040
LED1, LED3: 156120GS75000; LEDC5017X140N; Mouser Part Number 710-156120GS75000
LED2: 156120RS75000; LEDC5017X140N; Mouser Part Number 710-156120RS75000
Q1: FQD8P10TM; DPAK3-CASE-369AS; Mouser Part Number 512-FQD8P10TM
R1: 6,2k; R_1206_3216Metric; Manufacturer_Part_Number AC1206FR-076K2L; Mouser Part Number 603-AC1206FR-076K2L
R2, R4, R7, R9, R13, R15, R17, R19, R43: 2k; R_1206_3216Metric; Manufacturer_Part_Number AC1206FR-076K2L; Mouser Part Number 603-AC1206FR-076K2L
R3, R6, R8, R10, R14, R16, R18, R20, R38, R39, R40, R41: 12k; R_1206_3216Metric; Manufacturer_Part_Number AC1206FR-076K2L; Mouser Part Number 603-AC1206FR-076K2L
R5: 22k; R_1206_3216Metric; Manufacturer_Part_Number RT1206FRD0722KL; Mouser Part Number 603-RT1206FRD0722KL
R11: 40k; R_1206_3216Metric; Manufacturer_Part_Number AC1206FR-076K2L; Mouser Part Number 603-AC1206FR-076K2L
R12: 330k; R_1206_3216Metric; Manufacturer_Part_Number AC1206FR-076K2L; Mouser Part Number 603-AC1206FR-076K2L
R21: 100; R_1206_3216Metric; Manufacturer_Part_Number AC1206FR-076K2L; Mouser Part Number 603-AC1206FR-076K2L
R22, R23, R24, R25, R26, R27, R28, R29: 100k; R_1206_3216Metric; Manufacturer_Part_Number RT1206FRD0722KL; Mouser Part Number 603-RT1206FRD0722KL
R42: 4,7k; R_1206_3216Metric; Manufacturer_Part_Number AC1206FR-076K2L; Mouser Part Number 603-AC1206FR-076K2L
TP1: TestPoint; TestPoint_Pad_D2.0mm

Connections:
+3V3D: C1.1, C3.1, IC1.2 (SEL), IC1.5 (VCC), IC1.20 (MS1), IC2.2 (VCC), J4.2, J7.2, LED2.2
+5VD: J4.1, J7.1
+VF: C4.2, IC2.37 (TAB_(VBB)), Q1.3 (D), R1.1, R21.2
/CIPO: IC1.15 (SDO), IC2.13 (SO), J4.5, J7.5
/COPI: IC1.8 (SDI), IC2.6 (SI), J4.4, J7.4
/CS1: IC2.4 (~CS), J7.10
/CS2: IC1.16 (~CS), J7.11
/DI_V: C2.1, IC1.26 (VBB), R21.1
/I5: J3.4, R9.2, R10.2
/I6: J3.3, R7.2, R8.2
/I7: J3.2, R4.2, R6.2
/I8: J3.1, R2.2, R3.2
/IQ1: D12.1 (K), J5.4, R19.2, R20.2
/IQ2: D11.1 (K), J5.3, R17.2, R18.2
/IQ3: D10.1 (K), J5.2, R15.2, R16.2
/IQ4: D9.1 (K), J5.1, R13.2, R14.2
/Q5: D13.1 (K), J6.1, R38.1
/Q6: D14.1 (K), J6.2, R39.1
/Q7: D15.1 (K), J6.3, R40.1
/Q8: D16.1 (K), J6.4, R41.1
/SCK: IC1.13 (SCLK), IC2.5 (SCLK), J4.6, J7.6
/SCL: J4.9, J7.9
/SDA: J4.8, J7.8
/out0: D9.2 (A), IC2.35 (OUT0_1), IC2.36 (OUT0_2), R29.1
/out1: D10.2 (A), IC2.33 (OUT1_1), IC2.34 (OUT1_2), R25.1
/out2: D11.2 (A), IC2.31 (OUT2_1), IC2.32 (OUT2_2), R28.1
/out3: D12.2 (A), IC2.29 (OUT3_1), IC2.30 (OUT3_2), R24.1
/out4: D13.2 (A), IC2.27 (OUT4_1), IC2.28 (OUT4_2), R27.1
/out5: D14.2 (A), IC2.25 (OUT5_1), IC2.26 (OUT5_2), R23.1
/out6: D15.2 (A), IC2.23 (OUT6_1), IC2.24 (OUT6_2), R26.1
/out7: D16.2 (A), IC2.21 (OUT7_1), IC2.22 (OUT7_2), R22.1
/~ERR: IC1.6 (~ERR), TP1.1
EN: IC2.3 (~DIS), J4.40, J7.40, R43.1
GNDD: C1.2, C3.2, IC1.1 (GND_1), IC1.7 (GND_2), IC1.10 (GND), IC1.11 (GND), IC1.18 (GND_3), IC1.19 (MS0), IC1.24 (GND_4), IC2.15 (GNDCC), J4.3, J7.3, LED3.1, R5.2
GNDF: C2.2, C4.1, D17.1 (K), D18.1 (K), D19.1 (K), D20.1 (K), D21.1 (K), D22.1 (K), D23.1 (K), D24.1 (K), D25.1 (K), D26.1 (K), D27.1 (K), D28.1 (K), IC1.25 (GNDBB_1), IC1.31 (GNDBB_2), IC1.37 (GNDBB_3), IC1.43 (GNDBB_4), IC1.48 (GNDBB_5), IC2.19 (GNDBB), J1.2, LED1.1, Q1.1 (G), R11.2, R12.2, R22.2, R23.2, R24.2, R25.2, R26.2, R27.2, R28.2, R29.2
IL1: D24.2 (A), IC1.27 (I0L), R20.1
IL2: D23.2 (A), IC1.29 (I1L), R18.1
IL3: D22.2 (A), IC1.32 (I2L), R16.1
IL4: D21.2 (A), IC1.34 (I3L), R14.1
IL5: D20.2 (A), IC1.39 (I4L), R10.1
IL6: D19.2 (A), IC1.41 (I5L), R8.1
IL7: D18.2 (A), IC1.44 (I6L), R6.1
IL8: D17.2 (A), IC1.46 (I7L), R3.1
unnamed: D25.2 (A), R38.2
unnamed: D26.2 (A), R39.2
unnamed: D27.2 (A), R40.2
unnamed: D28.2 (A), R41.2
unnamed: IC1.28 (I0H), R19.1
unnamed: IC1.30 (I1H), R17.1
unnamed: IC1.33 (I2H), R15.1
unnamed: IC1.35 (I3H), R13.1
unnamed: IC1.40 (I4H), R9.1
unnamed: IC1.42 (I5H), R7.1
unnamed: IC1.45 (I6H), R4.1
unnamed: IC1.47 (I7H), R2.1
unnamed: IC1.4 (ROSC), R5.1
unnamed: IC1.36 (TS), R12.1
unnamed: IC1.38 (WB), R11.1
unnamed: J4.10, J7.12
unnamed: J4.11, J7.13
unnamed: J4.12, J7.14
unnamed: J4.13, J7.15
unnamed: J4.14, J7.16
unnamed: J4.15, J7.17
unnamed: J4.16, J7.18
unnamed: J4.17, J7.19
unnamed: J4.18, J7.20
unnamed: J4.19, J7.21
unnamed: J4.20, J7.22
unnamed: J4.21, J7.23
unnamed: J4.22, J7.24
unnamed: J4.23, J7.25
unnamed: J4.24, J7.26
unnamed: J4.25, J7.27
unnamed: J4.26, J7.28
unnamed: J4.27, J7.29
unnamed: J4.28, J7.30
unnamed: J4.29, J7.31
unnamed: J4.30, J7.32
unnamed: J4.31, J7.33
unnamed: J4.32, J7.34
unnamed: J4.33, J7.35
unnamed: J4.34, J7.36
unnamed: J4.35, J7.37
unnamed: J4.36, J7.38
unnamed: J4.37, J7.39
unnamed: LED1.2, R1.2
unnamed: LED2.1, R42.2
unnamed: LED3.2, R43.2
unnamed: J1.1, Q1.2 (S)
~DIAG: IC2.14 (~DIAG), J4.7, J7.7, R42.1

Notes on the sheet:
PIN 8: ERR nicht an INT Signal führen wegen 12V Fehler
PIN 3: SYNC ignorieren, nicht notwendig für diese Anwendung
PIN 19 & 20: SPI Mode 2
Einschaltschwelle: 9V Ausschaltschwelle: 8,3 V

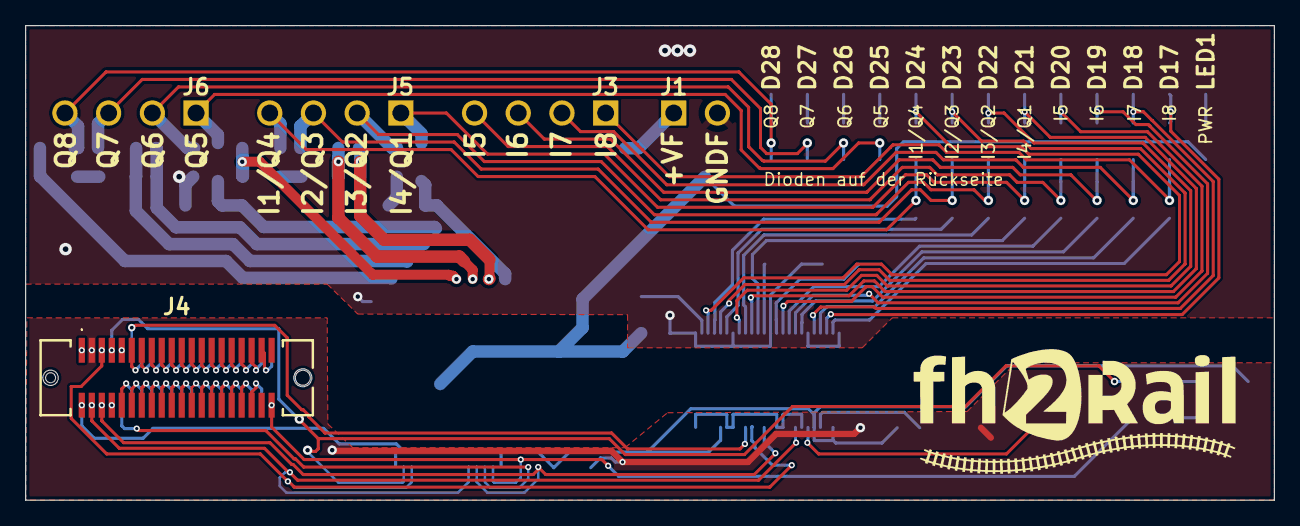
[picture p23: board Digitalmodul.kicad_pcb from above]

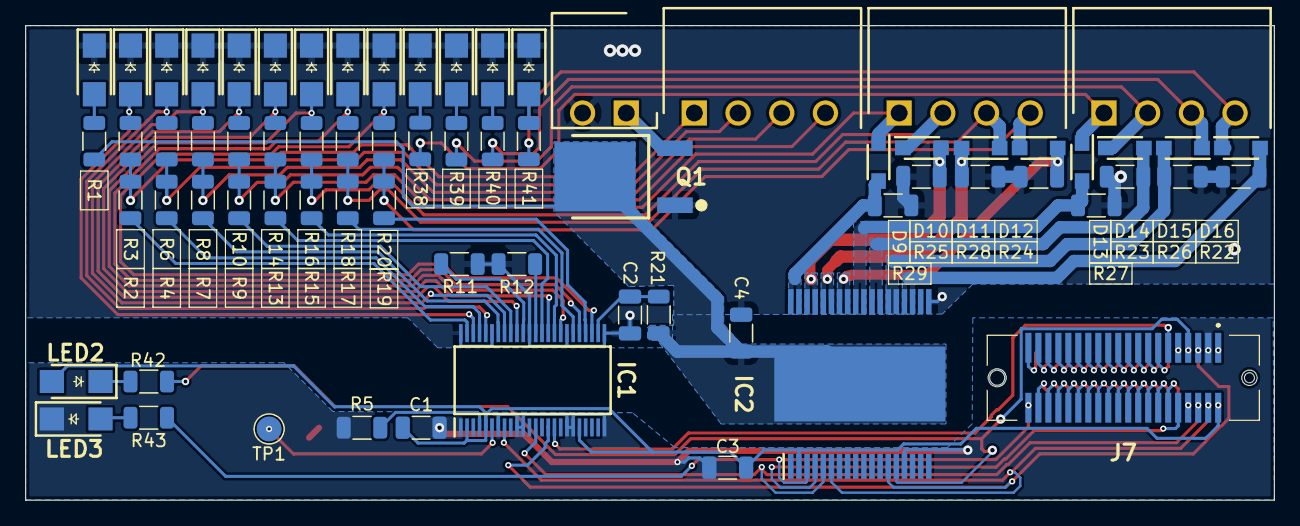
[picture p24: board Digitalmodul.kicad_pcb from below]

Board: 2 copper layers, 100.0 x 38.0 mm, 72 parts (71 on the bottom side), 91 nets.

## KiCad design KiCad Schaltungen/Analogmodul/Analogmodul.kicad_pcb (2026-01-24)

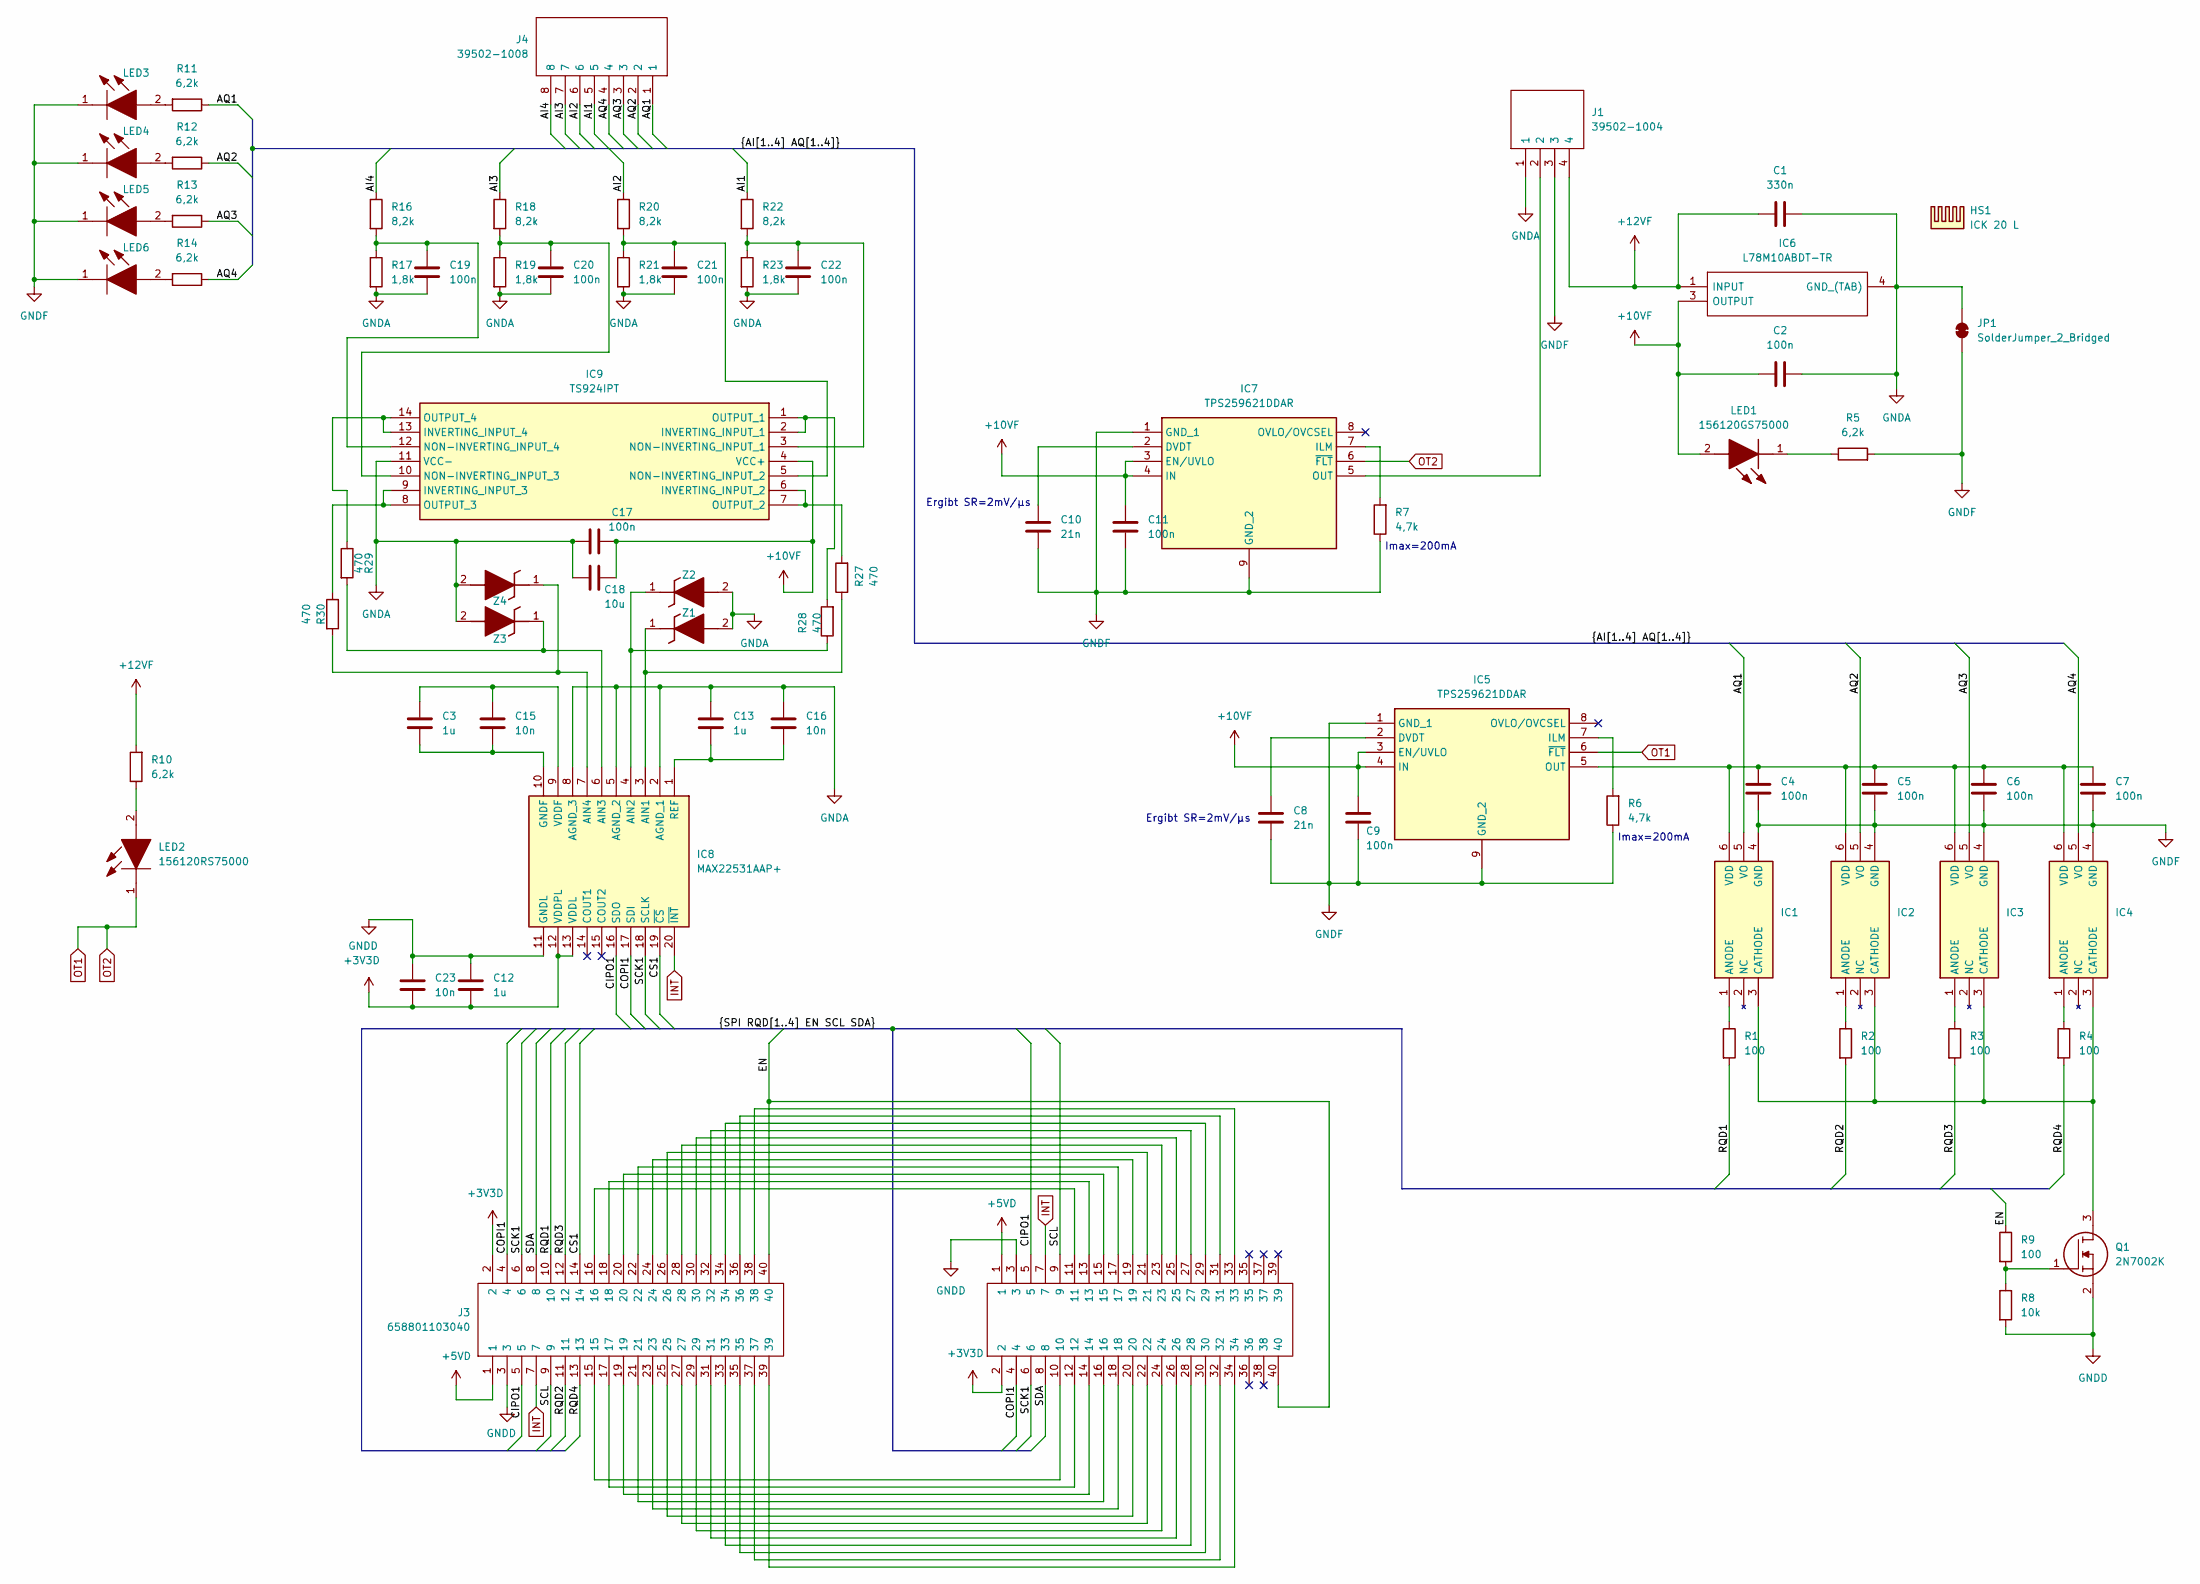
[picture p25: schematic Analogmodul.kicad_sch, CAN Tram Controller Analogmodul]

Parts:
C1: 330n; C_1206_3216Metric; Manufacturer_Part_Number C1206X334J1RECAUTO; Mouser Part Number 80-C1206X334J1RECAUT
C2, C4, C5, C6, C7, C9, C11: 100n; C_1206_3216Metric; Manufacturer_Part_Number GRM3195C2A104JA01D; Mouser Part Number 81-GRM3195C2A104JA1D
C3, C12, C13: 1u; C_1206_3216Metric; Manufacturer_Part_Number C1206X105J1RACTU; Mouser Part Number 80-C1206X105J1R
C8, C10: 21n; C_1206_3216Metric; Manufacturer_Part_Number GRM3195C2A104JA01D; Mouser Part Number 81-GRM3195C2A104JA1D
C15, C16, C23: 10n; C_1206_3216Metric; Manufacturer_Part_Number GRT3195C2A103JA02D; Mouser Part Number 81-GRT3195C2A103JA2D
C17: 100n; C_1206_3216Metric; Manufacturer_Part_Number GRT3195C2A103JA02D; Mouser Part Number 81-GRT3195C2A103JA2D
C18: 10u; C_1206_3216Metric; Manufacturer_Part_Number GRT3195C2A103JA02D; Mouser Part Number 81-GRT3195C2A103JA2D
C19, C20, C21, C22: 100n; C_1206_3216Metric; Manufacturer_Part_Number C1206C224J1RECAUTO; Mouser Part Number 80-C1206C224J1RECAUT
HS1: ICK 20 L; Heatsink ICK 20 L
IC1, IC2, IC3, IC4: SI8261BAD-C-ISR; SOIC127P1150X265-6N; Mouser Part Number 634-SI8261BAD-C-ISR
IC5, IC7: TPS259621DDAR; SOIC127P600X170-9N; Mouser Part Number 595-TPS259621DDAR
IC6: L78M10ABDT-TR; TO228P972X240-3N; Mouser Part Number 511-L78M10ABDT-TR
IC8: MAX22531AAP+; SOP65P778X199-20N; Mouser Part Number 700-MAX22531AAP+
IC9: TS924IPT; SOP65P640X120-14N; Mouser Part Number 511-TS924IP
J1: 39502-1004; SHDRRA4W80P0X350_1X4_1540X920X730P; Mouser Part Number 538-39502-1004
J3: 658801103040; Mouser Part Number 710-658801103040
J4: 39502-1008; SHDRRA8W80P0X350_1X8_2940X920X690P; Mouser Part Number 538-39502-1008
J6: 658855603040; Mouser Part Number 710-658855603040
JP1: SolderJumper_2_Bridged; SolderJumper-2_P1.3mm_Bridged2Bar_Pad1.0x1.5mm
LED1, LED3, LED4, LED5, LED6: 156120GS75000; LEDM3216X130N; Mouser Part Number 710-156120GS75000
LED2: 156120RS75000; LEDM3216X130N; Mouser Part Number 710-156120RS75000
Q1: 2N7002K; SOT95P240X120-3N; Mouser Part Number 512-2N7002K
R1, R2, R3, R4, R9: 100; R_1206_3216Metric; Manufacturer_Part_Number AC1206FR-07100RL; Mouser Part Number 603-AC1206FR-07100RL
R5, R10, R11, R12, R13, R14: 6,2k; R_1206_3216Metric; Manufacturer_Part_Number AC1206FR-076K2L; Mouser Part Number 603-AC1206FR-076K2L
R6, R7: 4,7k; R_1206_3216Metric; Manufacturer_Part_Number AC1206FR-07100RL; Mouser Part Number 603-AC1206FR-07100RL
R8: 10k; R_1206_3216Metric; Manufacturer_Part_Number AC1206FR-07100RL; Mouser Part Number 603-AC1206FR-07100RL
R16, R18, R20, R22: 8,2k; R_1206_3216Metric; Manufacturer_Part_Number CRGCQ1206F8K2; Mouser Part Number 279-CRGCQ1206F8K2
R17, R19, R21, R23: 1,8k; R_1206_3216Metric; Manufacturer_Part_Number CRCW12061K80FKEAC; Mouser Part Number 71-CRCW12061K80FKEAC
R27, R28, R29, R30: 470; R_1206_3216Metric; Manufacturer_Part_Number CRGCQ1206F8K2; Mouser Part Number 279-CRGCQ1206F8K2
Z1, Z2, Z3, Z4: SZMMSZ4679T1G; SOD3716X135N; Mouser Part Number 863-SZMMSZ4679T1G

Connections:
+3V3D: C12.1, C23.1, IC8.12 (VDDPL), IC8.13 (VDDL), J3.2, J6.2
+5VD: J3.1, J6.1
+10VF: C2.1, C9.2, C11.2, C17.2, C18.2, IC5.3 (EN/UVLO), IC5.4 (IN), IC6.3 (OUTPUT), IC7.3 (EN/UVLO), IC7.4 (IN), IC9.4 (VCC+), LED1.2 (A)
+12VF: C1.1, IC6.1 (INPUT), J1.4, R10.2
/AI1: J4.5, R22.1
/AI2: J4.6, R20.1
/AI3: J4.7, R18.1
/AI4: J4.8, R16.1
/AQ1: IC1.5 (VO), J4.1, R11.1
/AQ2: IC2.5 (VO), J4.2, R12.1
/AQ3: IC3.5 (VO), J4.3, R13.1
/AQ4: IC4.5 (VO), J4.4, R14.1
/CIPO1: IC8.16 (SDO), J3.5, J6.5
/COPI1: IC8.17 (SDI), J3.4, J6.4
/CS1: IC8.19 (~CS), J3.14
/EN: J3.40, J6.40, R9.1
/RQD1: J3.10, R1.2
/RQD2: J3.11, R2.2
/RQD3: J3.12, R3.2
/RQD4: J3.13, R4.2
/SCK1: IC8.18 (SCLK), J3.6, J6.6
/SCL: J3.9, J6.9
/SDA: J3.8, J6.8
GNDA: C1.2, C2.2, C13.1, C16.1, C17.1, C18.1, C19.2, C20.2, C21.2, C22.2, IC6.4 (GND_(TAB)), IC8.2 (AGND_1), IC8.5 (AGND_2), IC8.8 (AGND_3), IC9.11 (VCC-), J1.1, JP1.2 (B), R17.2, R19.2, R21.2, R23.2, Z1.2 (A), Z2.2 (A), Z3.2 (A), Z4.2 (A)
GNDD: C12.2, C23.2, IC8.11 (GNDL), J3.3, J6.3, Q1.2, R8.2
GNDF: C4.1, C5.1, C6.1, C7.1, C8.2, C9.1, C10.2, C11.1, IC1.4 (GND), IC2.4 (GND), IC3.4 (GND), IC4.4 (GND), IC5.1 (GND_1), IC5.9 (GND_2), IC7.1 (GND_1), IC7.9 (GND_2), J1.3, JP1.1 (A), LED3.1, LED4.1, LED5.1, LED6.1, R5.2, R6.1, R7.1
INT: IC8.20 (~INT), J3.7, J6.7
unnamed: IC1.1 (ANODE), R1.1
unnamed: IC1.3 (CATHODE), IC2.3 (CATHODE), IC3.3 (CATHODE), IC4.3 (CATHODE), Q1.3
unnamed: C4.2, C5.2, C6.2, C7.2, IC1.6 (VDD), IC2.6 (VDD), IC3.6 (VDD), IC4.6 (VDD), IC5.5 (OUT)
unnamed: IC2.1 (ANODE), R2.1
unnamed: IC3.1 (ANODE), R3.1
unnamed: IC4.1 (ANODE), R4.1
unnamed: C8.1, IC5.2 (DVDT)
unnamed: IC5.7 (ILM), R6.2
unnamed: C10.1, IC7.2 (DVDT)
unnamed: IC7.7 (ILM), R7.2
unnamed: IC7.5 (OUT), J1.2
unnamed: IC8.3 (AIN1), R27.1, Z1.1 (K)
unnamed: IC8.4 (AIN2), R28.1, Z2.1 (K)
unnamed: IC8.6 (AIN3), R29.2, Z3.1 (K)
unnamed: IC8.7 (AIN4), R30.2, Z4.1 (K)
unnamed: C3.2, C15.2, IC8.10 (GNDF)
unnamed: C13.2, C16.2, IC8.1 (REF)
unnamed: C3.1, C15.1, IC8.9 (VDDF)
unnamed: IC9.1 (OUTPUT_1), IC9.2 (INVERTING_INPUT_1), R28.2
unnamed: IC9.6 (INVERTING_INPUT_2), IC9.7 (OUTPUT_2), R27.2
unnamed: IC9.8 (OUTPUT_3), IC9.9 (INVERTING_INPUT_3), R30.1
unnamed: IC9.13 (INVERTING_INPUT_4), IC9.14 (OUTPUT_4), R29.1
unnamed: C22.1, IC9.3 (NON-INVERTING_INPUT_1), R22.2, R23.1
unnamed: C21.1, IC9.5 (NON-INVERTING_INPUT_2), R20.2, R21.1
unnamed: C20.1, IC9.10 (NON-INVERTING_INPUT_3), R18.2, R19.1
unnamed: C19.1, IC9.12 (NON-INVERTING_INPUT_4), R16.2, R17.1
unnamed: J3.15, J6.10
unnamed: J3.16, J6.11
unnamed: J3.17, J6.12
unnamed: J3.18, J6.13
unnamed: J3.19, J6.14
unnamed: J3.20, J6.15
unnamed: J3.21, J6.16
unnamed: J3.22, J6.17
unnamed: J3.23, J6.18
unnamed: J3.24, J6.19
unnamed: J3.25, J6.20
unnamed: J3.26, J6.21
unnamed: J3.27, J6.22
unnamed: J3.28, J6.23
unnamed: J3.29, J6.24
unnamed: J3.30, J6.25
unnamed: J3.31, J6.26
unnamed: J3.32, J6.27
unnamed: J3.33, J6.28
unnamed: J3.34, J6.29
unnamed: J3.35, J6.30
unnamed: J3.36, J6.31
unnamed: J3.37, J6.32
unnamed: J3.38, J6.33
unnamed: J3.39, J6.34
unnamed: LED1.1 (K), R5.1
unnamed: LED2.2, R10.1
unnamed: LED3.2, R11.2
unnamed: LED4.2, R12.2
unnamed: LED5.2, R13.2
unnamed: LED6.2, R14.2
unnamed: Q1.1, R8.1, R9.2
OT1: IC5.6 (~FLT), IC7.6 (~FLT), LED2.1

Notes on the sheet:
Imax=200mA
Ergibt SR=2mV/µs

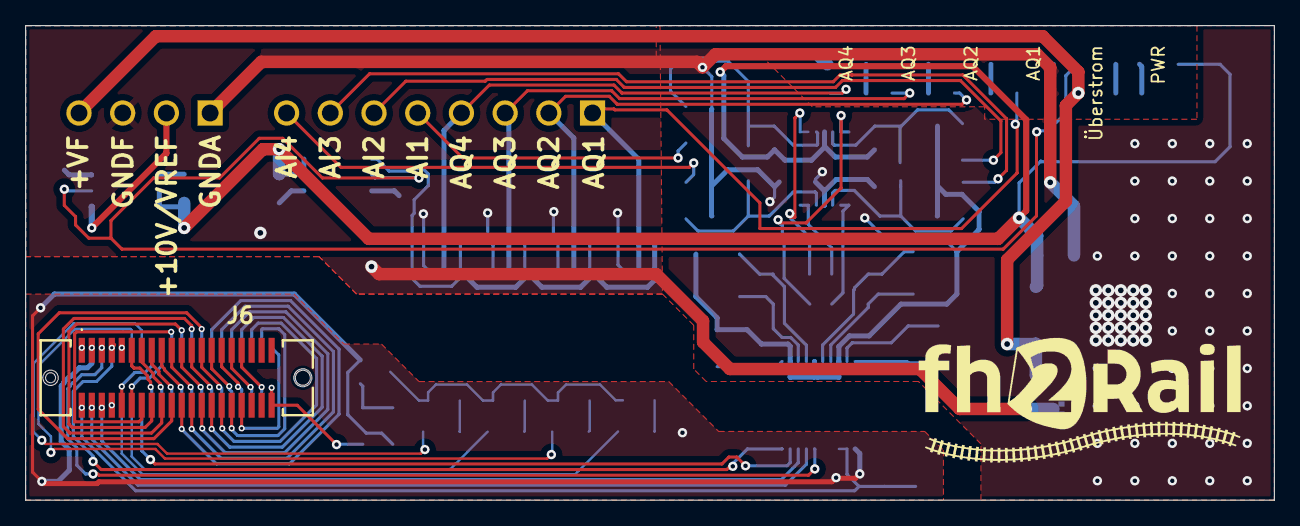
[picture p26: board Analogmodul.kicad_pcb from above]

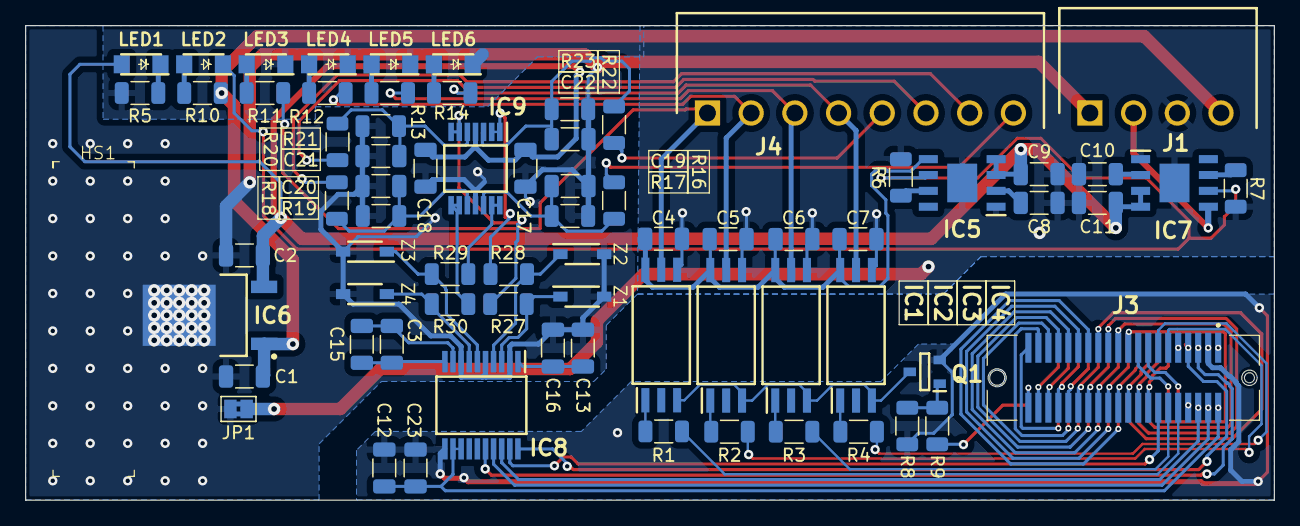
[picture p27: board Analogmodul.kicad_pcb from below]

Board: 2 copper layers, 100.0 x 38.0 mm, 74 parts (73 on the bottom side), 86 nets.

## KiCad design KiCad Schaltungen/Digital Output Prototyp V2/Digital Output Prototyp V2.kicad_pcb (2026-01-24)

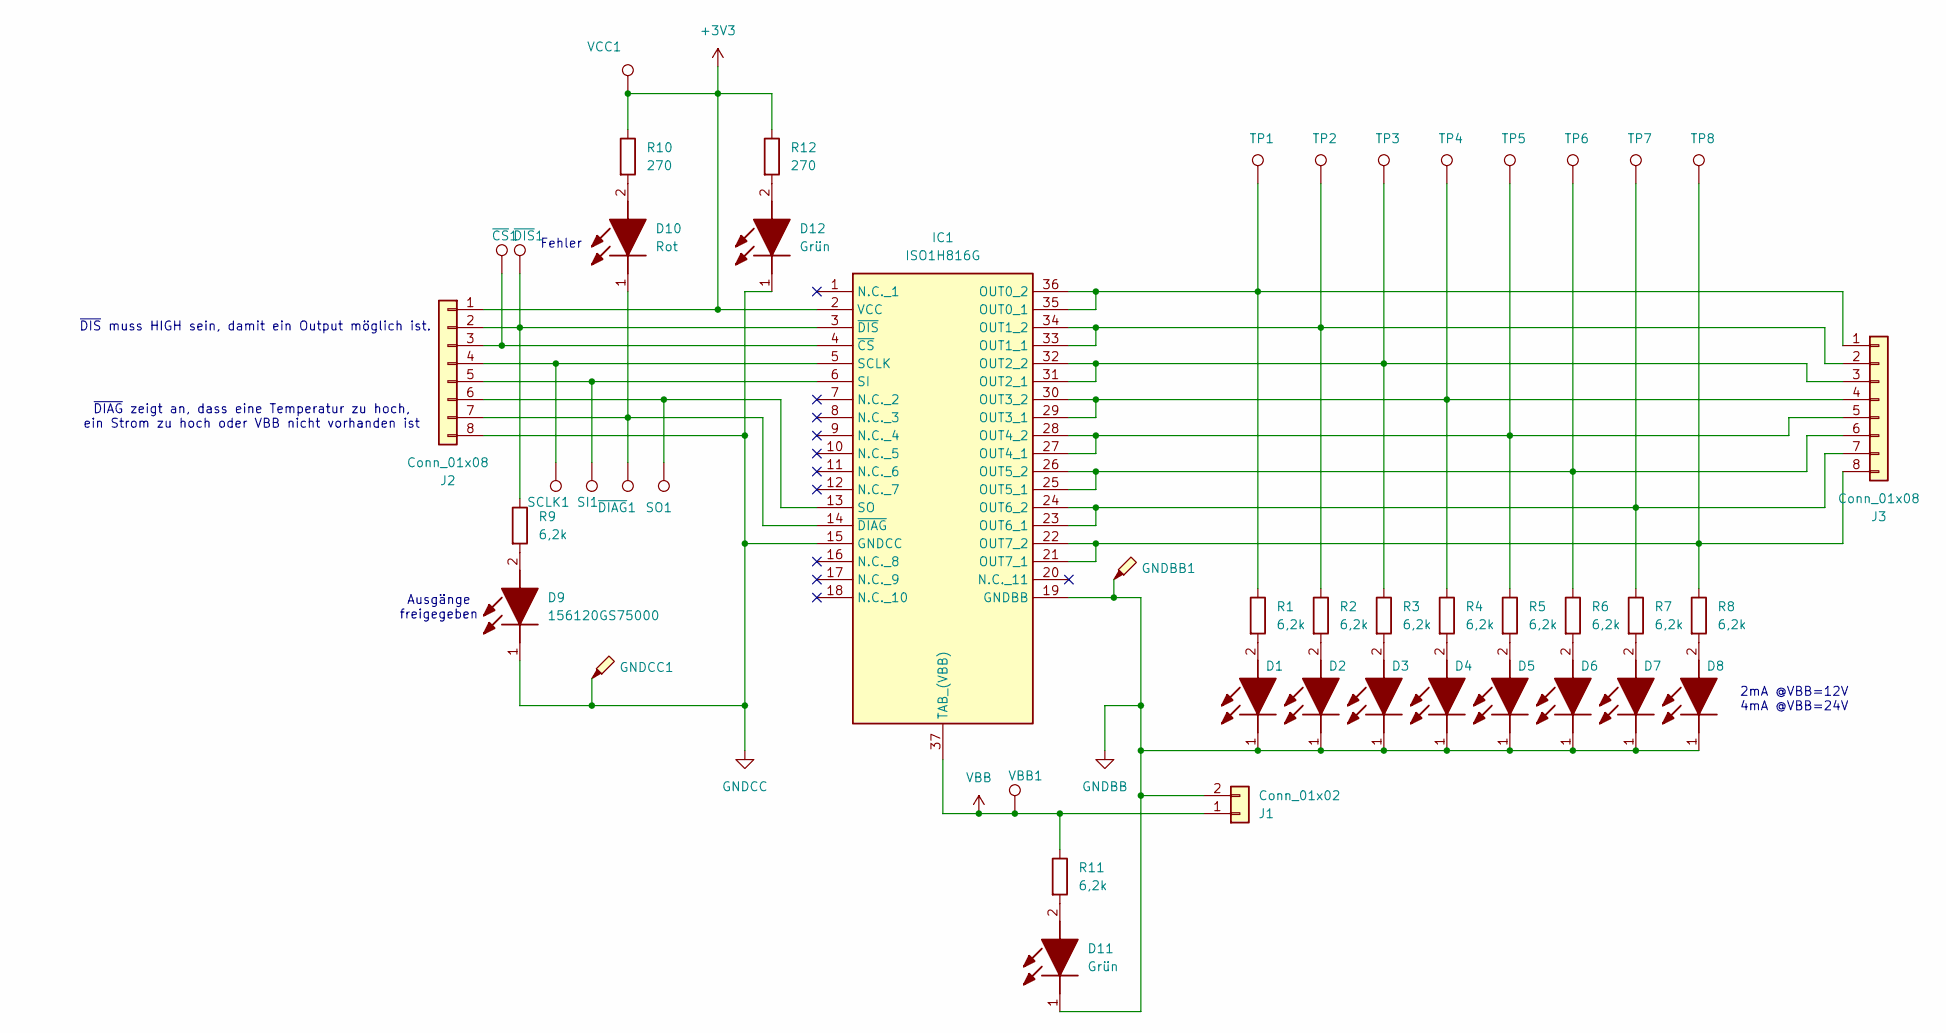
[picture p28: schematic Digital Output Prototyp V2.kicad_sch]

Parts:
D1, D2, D3, D4, D5, D6, D7, D8: 156120YS75000; LEDC5017X140N; Mouser Part Number 710-156120YS75000
D9: 156120GS75000; LEDC5017X140N; Mouser Part Number 710-156120GS75000
D10: Rot; LEDC5017X140N; Mouser Part Number 710-156120RS75000
D11, D12: Grün; LEDC5017X140N; Mouser Part Number 710-156120GS75000
GNDBB1: TestPoint_Probe; TestPoint_Keystone_5000-5004_Miniature; Manufacturer_Part_Number 5001; Mouser Part Number 534-5001
GNDCC1: TestPoint_Probe; TestPoint_Keystone_5000-5004_Miniature; Manufacturer_Part_Number 5001; Mouser Part Number 534-5001
IC1: ISO1H816G; SOP65P1420X350-37N; Mouser Part Number 726-ISO1H816G
J1: Conn_01x02; PinSocket_1x02_P2.54mm_Vertical
J2, J3: Conn_01x08; PinSocket_1x08_P2.54mm_Vertical
R1, R2, R3, R4, R5, R6, R7, R8, R9, R11: 6,2k; R_1206_3216Metric; Manufacturer_Part_Number AC1206FR-076K2L; Mouser Part Number 603-AC1206FR-076K2L
R10, R12: 270; R_1206_3216Metric; Mouser Part Number 603-RT1206FRE07270RL
SCLK1: TestPoint; TestPoint_Pad_D2.0mm
SI1: TestPoint; TestPoint_Pad_D2.0mm
SO1: TestPoint; TestPoint_Pad_D2.0mm
TP1, TP2, TP3, TP4, TP5, TP6, TP7, TP8: TestPoint; TestPoint_Pad_D2.0mm
VBB1: TestPoint; TestPoint_Pad_D2.0mm
VCC1: TestPoint; TestPoint_Pad_D2.0mm
~{CS}1: TestPoint; TestPoint_Pad_D2.0mm
~{DIAG}1: TestPoint; TestPoint_Pad_D2.0mm
~{DIS}1: TestPoint; TestPoint_Pad_D2.0mm

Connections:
+3V3: IC1.2 (VCC), J2.1, R10.1, R12.1, VCC1.1
GNDBB: D1.1 (K), D2.1 (K), D3.1 (K), D4.1 (K), D5.1 (K), D6.1 (K), D7.1 (K), D8.1 (K), D11.1 (K), GNDBB1.1, IC1.19 (GNDBB), J1.2
GNDCC: D9.1 (K), D12.1 (K), GNDCC1.1, IC1.15 (GNDCC), J2.8
unnamed: D1.2 (A), R1.2
unnamed: D2.2 (A), R2.2
unnamed: D3.2 (A), R3.2
unnamed: D4.2 (A), R4.2
unnamed: D5.2 (A), R5.2
unnamed: D6.2 (A), R6.2
unnamed: D7.2 (A), R7.2
unnamed: D8.2 (A), R8.2
unnamed: D9.2 (A), R9.2
unnamed: D10.2 (A), R10.2
unnamed: D10.1 (K), IC1.14 (~DIAG), J2.7, ~{DIAG}1.1
unnamed: D11.2 (A), R11.2
unnamed: D12.2 (A), R12.2
unnamed: IC1.35 (OUT0_1), IC1.36 (OUT0_2), J3.1, R1.1, TP1.1
unnamed: IC1.33 (OUT1_1), IC1.34 (OUT1_2), J3.2, R2.1, TP2.1
unnamed: IC1.31 (OUT2_1), IC1.32 (OUT2_2), J3.3, R3.1, TP3.1
unnamed: IC1.29 (OUT3_1), IC1.30 (OUT3_2), J3.4, R4.1, TP4.1
unnamed: IC1.27 (OUT4_1), IC1.28 (OUT4_2), J3.5, R5.1, TP5.1
unnamed: IC1.25 (OUT5_1), IC1.26 (OUT5_2), J3.6, R6.1, TP6.1
unnamed: IC1.23 (OUT6_1), IC1.24 (OUT6_2), J3.7, R7.1, TP7.1
unnamed: IC1.21 (OUT7_1), IC1.22 (OUT7_2), J3.8, R8.1, TP8.1
unnamed: IC1.5 (SCLK), J2.4, SCLK1.1
unnamed: IC1.6 (SI), J2.5, SI1.1
unnamed: IC1.13 (SO), J2.6, SO1.1
unnamed: IC1.4 (~CS), J2.3, ~{CS}1.1
unnamed: IC1.3 (~DIS), J2.2, R9.1, ~{DIS}1.1
VBB: IC1.37 (TAB_(VBB)), J1.1, R11.1, VBB1.1

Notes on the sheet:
Fehler
~{DIAG} zeigt an, dass eine Temperatur zu hoch, ein Strom zu hoch oder VBB nicht vorhanden ist
~{DIS} muss HIGH sein, damit ein Output möglich ist.
2mA @VBB=12V 4mA @VBB=24V
Ausgänge freigegeben

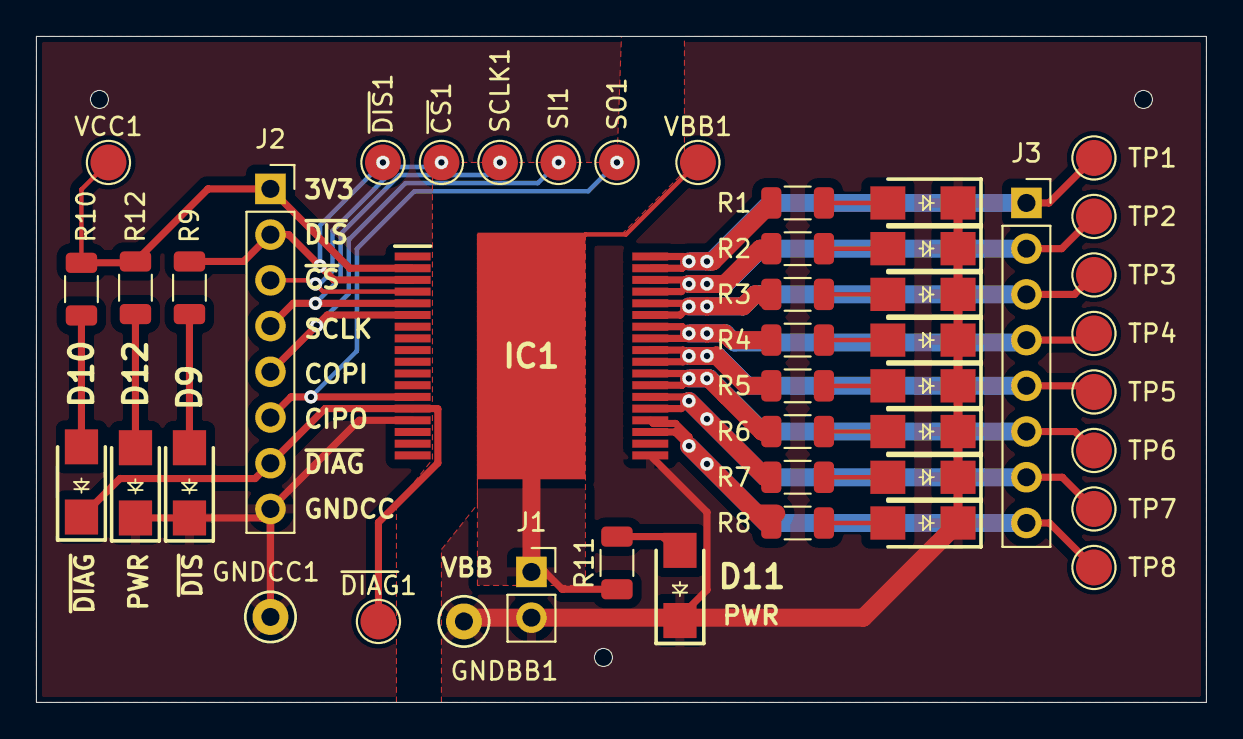
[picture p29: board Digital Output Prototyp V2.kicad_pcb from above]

Board: 2 copper layers, 65.0 x 37.0 mm, 43 parts (0 on the bottom side), 30 nets.

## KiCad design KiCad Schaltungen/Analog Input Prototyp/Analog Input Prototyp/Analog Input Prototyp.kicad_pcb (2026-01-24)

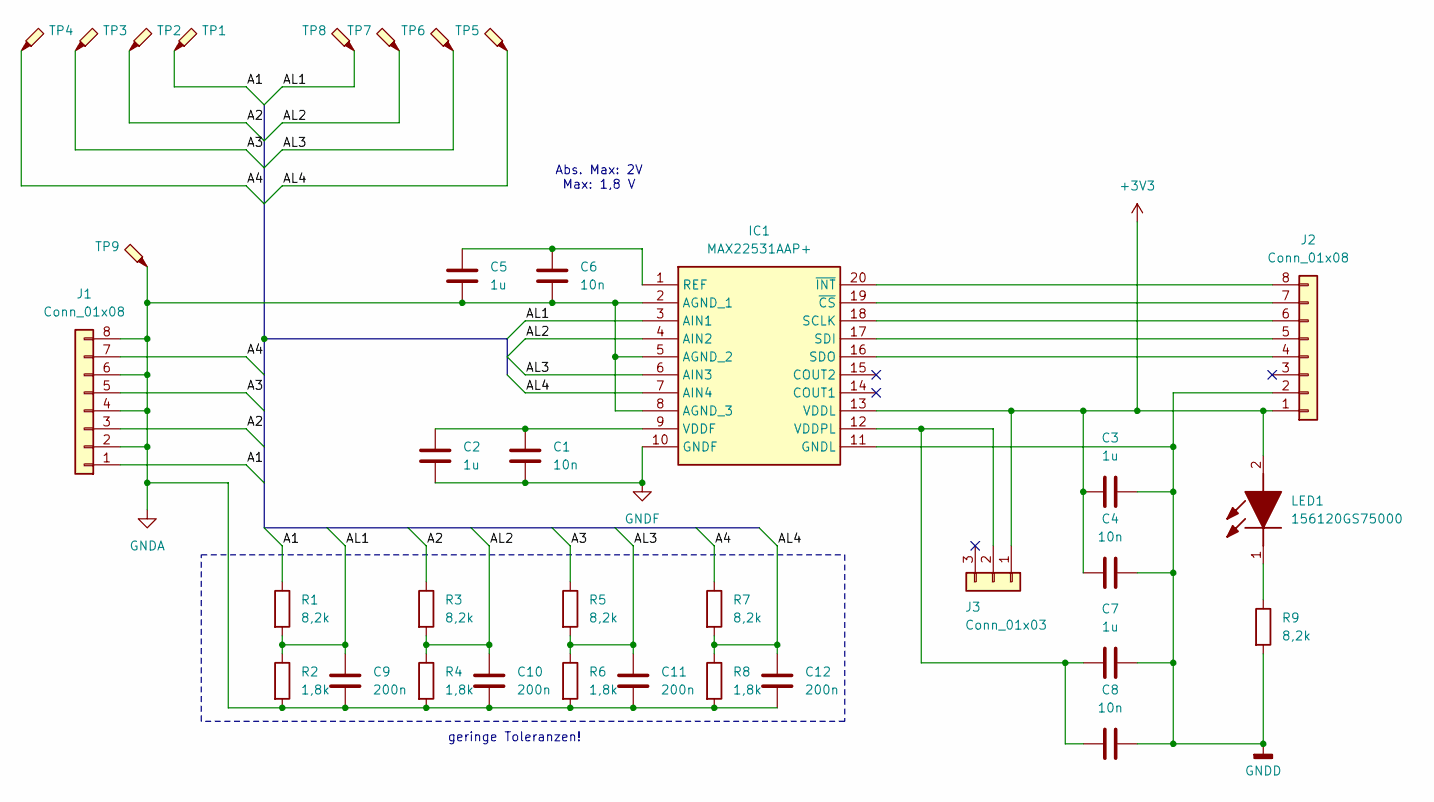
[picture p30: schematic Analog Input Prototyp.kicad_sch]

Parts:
C1, C4, C6, C8: 10n; C_1206_3216Metric; Manufacturer_Part_Number GRT3195C2A103JA02D; Mouser Part Number 81-GRT3195C2A103JA2D
C2, C3, C5, C7: 1u; C_1206_3216Metric; Manufacturer_Part_Number C1206X105J1RACTU; Mouser Part Number 80-C1206X105J1R
C9, C10, C11, C12: 200n; C_1206_3216Metric; Manufacturer_Part_Number C1206C224J1RECAUTO; Mouser Part Number 80-C1206C224J1RECAUT
IC1: MAX22531AAP+; SOP65P778X199-20N; Mouser Part Number 700-MAX22531AAP+
J1, J2: Conn_01x08; PinHeader_1x08_P2.54mm_Vertical
J3: Conn_01x03; PinHeader_1x03_P2.54mm_Vertical
LED1: 156120GS75000; Mouser Part Number 710-156120GS75000
R1, R3, R5, R7, R9: 8,2k; R_1206_3216Metric; Manufacturer_Part_Number CRGCQ1206F8K2; Mouser Part Number 279-CRGCQ1206F8K2
R2, R4, R6, R8: 1,8k; R_1206_3216Metric; Manufacturer_Part_Number CRCW12061K80FKEAC; Mouser Part Number 71-CRCW12061K80FKEAC
TP1, TP2, TP3, TP4, TP5, TP6, TP7, TP8, TP9: TestPoint_Probe; TestPoint_Keystone_5000-5004_Miniature; Manufacturer_Part_Number 5001; Mouser Part Number 534-5001

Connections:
+3V3: C3.1, C4.1, IC1.13 (VDDL), J2.1, J3.1, LED1.2 (A)
/A1: J1.1, R1.1, TP1.1
/A2: J1.3, R3.1, TP2.1
/A3: J1.5, R5.1, TP3.1
/A4: J1.7, R7.1, TP4.1
/AL1: C9.1, IC1.3 (AIN1), R1.2, R2.1, TP8.1
/AL2: C10.1, IC1.4 (AIN2), R3.2, R4.1, TP7.1
/AL3: C11.1, IC1.6 (AIN3), R5.2, R6.1, TP6.1
/AL4: C12.1, IC1.7 (AIN4), R7.2, R8.1, TP5.1
GNDA: C5.2, C6.2, C9.2, C10.2, C11.2, C12.2, IC1.2 (AGND_1), IC1.5 (AGND_2), IC1.8 (AGND_3), J1.2, J1.4, J1.6, J1.8, R2.2, R4.2, R6.2, R8.2, TP9.1
GNDD: C3.2, C4.2, C7.2, C8.2, IC1.11 (GNDL), J2.2, R9.2
GNDF: C1.2, C2.2, IC1.10 (GNDF)
unnamed: C5.1, C6.1, IC1.1 (REF)
unnamed: IC1.18 (SCLK), J2.6
unnamed: IC1.17 (SDI), J2.5
unnamed: IC1.16 (SDO), J2.4
unnamed: C1.1, C2.1, IC1.9 (VDDF)
unnamed: C7.1, C8.1, IC1.12 (VDDPL), J3.2
unnamed: IC1.19 (~CS), J2.7
unnamed: IC1.20 (~INT), J2.8
unnamed: LED1.1 (K), R9.1

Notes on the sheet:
geringe Toleranzen!
Abs. Max: 2V Max: 1,8 V

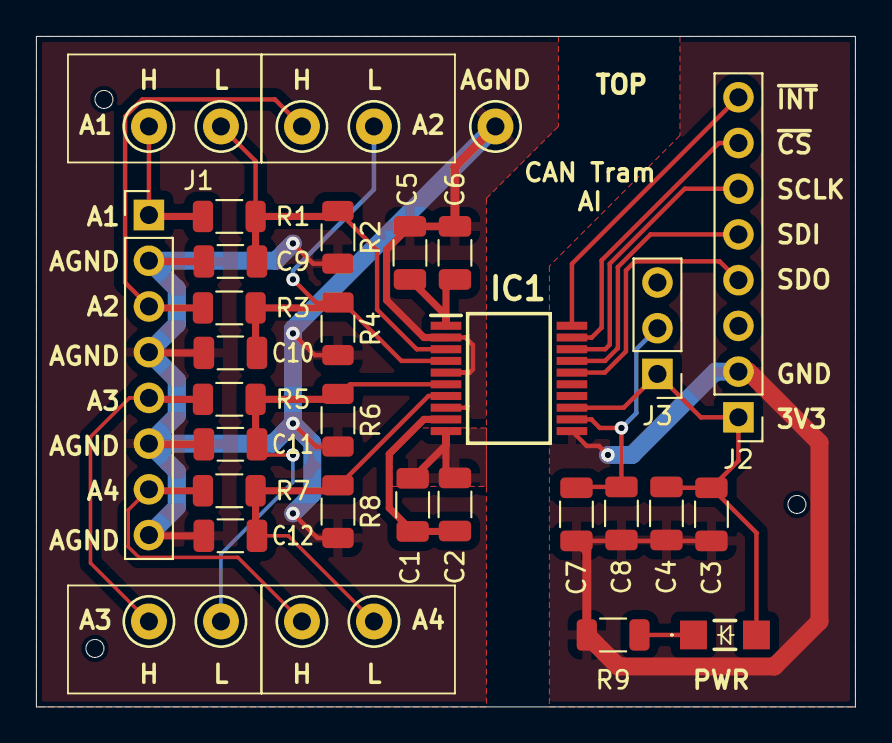
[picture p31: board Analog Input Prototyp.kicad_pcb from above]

Board: 2 copper layers, 45.5 x 37.2 mm, 35 parts (0 on the bottom side), 21 nets.

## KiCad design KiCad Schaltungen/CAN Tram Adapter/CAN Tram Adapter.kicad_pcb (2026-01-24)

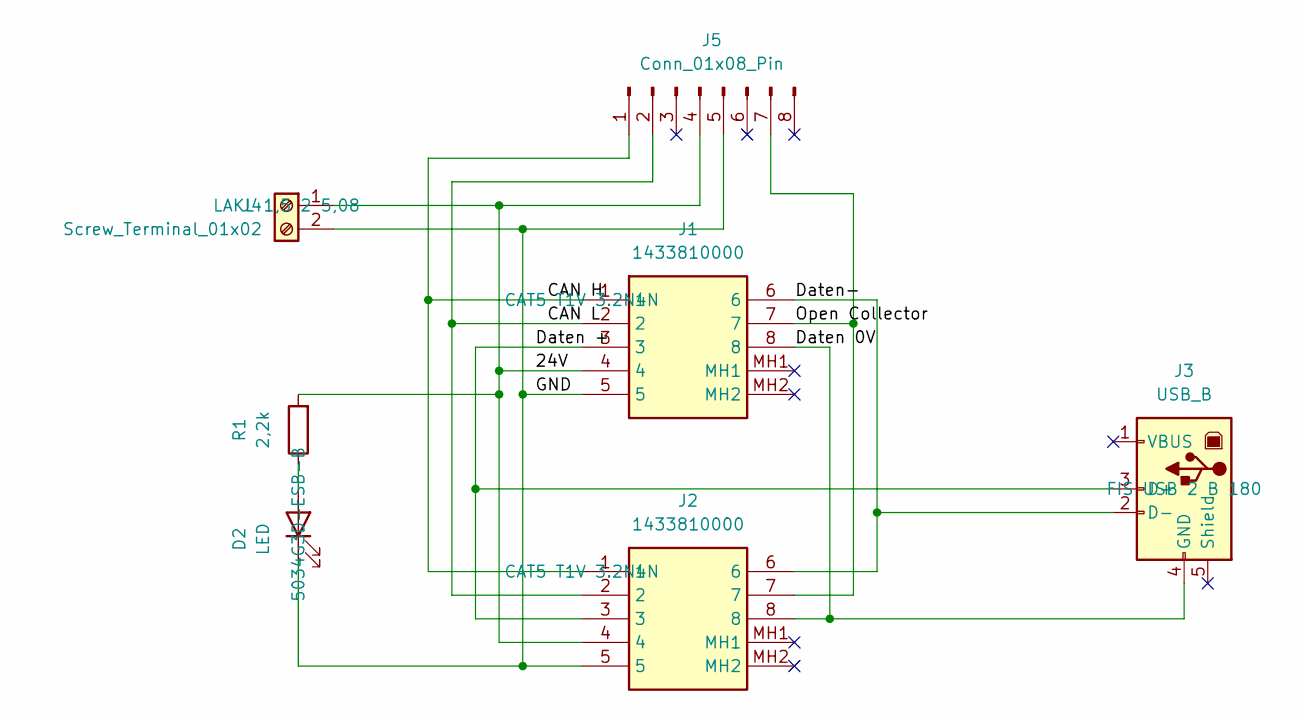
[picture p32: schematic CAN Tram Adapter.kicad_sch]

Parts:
D2: LED; LED_D5.0mm
J1, J2: 1433810000; Mouser Part Number 470-1433810000
J3: USB_B; Fischer_USB_2_B_180
J4: Screw_Terminal_01x02; TerminalBlock_Phoenix_MKDS-1,5-2-5.08_1x02_P5.08mm_Horizont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
J5: Conn_01x08_Pin; PinHeader_1x08_P2.54mm_Vertical
R1: 2,2k; R_Axial_DIN0207_L6.3mm_D2.5mm_P2.54mm_Vertical

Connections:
/24V: J1.4, J2.4, J4.1, J5.4, R1.2
/CAN H: J1.1, J2.1, J5.1
/CAN L: J1.2, J2.2, J5.2
/Daten 0V: J1.8, J2.8, J3.4 (GND)
/Daten +: J1.3, J2.3, J3.3 (D+)
/Daten-: J1.6, J2.6, J3.2 (D-)
/GND: D2.1 (K), J1.5, J2.5, J4.2, J5.5
/Open Collector: J1.7, J2.7, J5.7
unnamed: D2.2 (A), R1.1

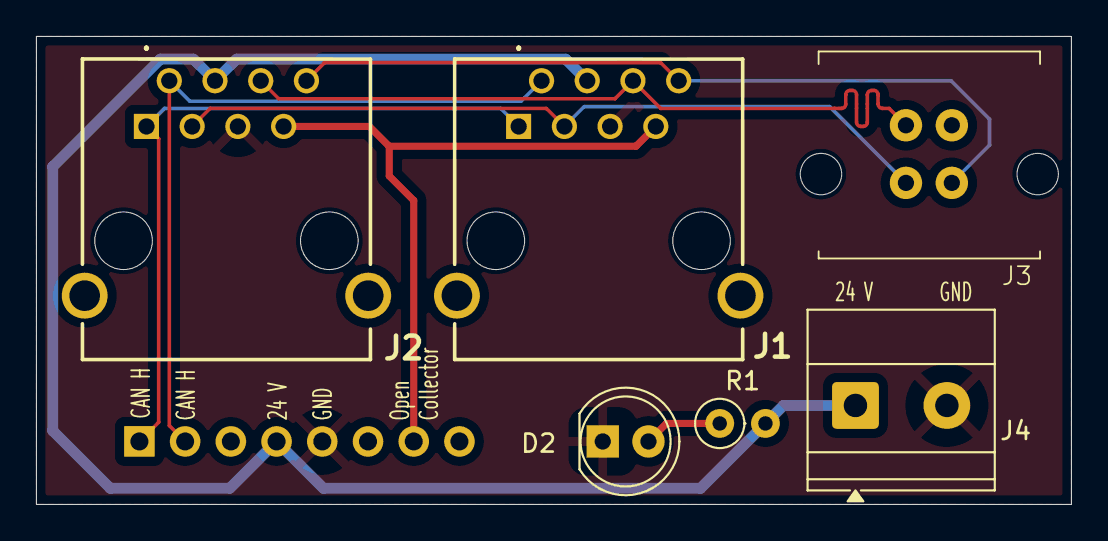
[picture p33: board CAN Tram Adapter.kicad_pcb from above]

Board: 2 copper layers, 57.5 x 26.0 mm, 7 parts (1 on the bottom side), 9 nets.

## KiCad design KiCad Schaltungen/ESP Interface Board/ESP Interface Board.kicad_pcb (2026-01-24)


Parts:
C2: 10u; C_Disc_D5.1mm_W3.2mm_P5.00mm; Manufacturer_Part_Number CL31A106KBHNNNE; Mouser Part Number 187-CL31A106KBHNNNE
C3, C5: 0,1u; C_Disc_D5.1mm_W3.2mm_P5.00mm; Manufacturer_Part_Number CL31A106KBHNNNE; Mouser Part Number 187-CL31A106KBHNNNE
C4: 0,33u; C_Disc_D5.1mm_W3.2mm_P5.00mm; Manufacturer_Part_Number CL31A106KBHNNNE; Mouser Part Number 187-CL31A106KBHNNNE
D1: LED; LED_D5.0mm
IC1: SN65HVD230QDRG4Q1; SOIC127P600X175-8N; Mouser Part Number 595-S65HVD230QDRG4Q1
IC2: ISO7721FDR; SOIC127P600X175-8N; Mouser Part Number 595-ISO7721FDR
IC3: L78L05ACZ; Mouser Part Number 511-L78L05ACZ
IC4: ESP32-DEVKITC-VE; ESP32DEVKITCVE; Manufacturer_Part_Number ESP32-DEVKITC-VE; Mouser Part Number 356-ESP32-DEVKTC32VE
J1, J2, J3, J4: DG127A-5.08-06P-14-00AH; DG127A50806P1400AH; Manufacturer_Part_Number DG127A-5.08-06P-14-00AH
J5: Conn_01x06; PinSocket_1x06_P2.54mm_Vertical
J7: 43860-5025; 438605025; Mouser Part Number 538-43860-5025
JP1, JP2, JP3, JP4, JP5, JP6, JP7, JP8, JP9, JP10, JP11, JP12, JP13, JP14: SolderJumper_2_Open; SolderJumper-2_P1.3mm_Open_Pad1.0x1.5mm
PS1: RSH3-2405S_H2-R; RSH32405SH2R; Mouser Part Number 919-RSH3-2405S/H2-R
R2: 10k; R_Axial_DIN0207_L6.3mm_D2.5mm_P7.62mm_Horizontal; Manufacturer_Part_Number RC1206FR-1310KL; Mouser Part Number 603-RC1206FR-1310KL
R7: 120; R_Axial_DIN0207_L6.3mm_D2.5mm_P7.62mm_Horizontal
R8: 2,2k; R_Axial_DIN0207_L6.3mm_D2.5mm_P7.62mm_Horizontal
R9, R10: 1k; R_Axial_DIN0207_L6.3mm_D2.5mm_P7.62mm_Horizontal

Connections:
+3V3A: IC2.1 (VCC1), IC4.1 (3V3), J5.1, JP4.2 (B), JP6.2 (B), JP8.2 (B), JP10.2 (B)
+5VA: IC4.19 (5V), JP5.2 (B), JP7.2 (B), JP9.2 (B), JP11.2 (B), PS1.8 (+VOUT)
+5VB: C5.1, IC1.3 (VCC), IC2.8 (VCC2), IC3.1 (VOUT)
+24V: C2.1, C4.1, D1.2 (A), IC3.3 (VIN), J7.4, PS1.14 (+VIN)
/GPIO 4: IC4.26 (IO4), J4.1
/GPIO 12: IC4.13 (IO12), J4.2
/GPIO 13: IC4.15 (IO13), J4.4
/GPIO 14: IC4.12 (IO14), J1.3
/GPIO 15: IC4.23 (IO15), J4.3
/GPIO 25: IC4.9 (IO25), J1.2
/GPIO 26: IC4.10 (IO26), J1.4
/GPIO 27: IC4.11 (IO27), J1.1
/I2C SCL: IC4.7 (IO32), J2.1
/I2C SDA: IC4.8 (IO33), J2.3
/SPI CLK: IC4.30 (IO18), J3.3
/SPI CS: IC4.29 (IO5), J3.1
/SPI MISO: IC4.31 (IO19), J3.2
/SPI MOSI: IC4.37 (IO23), J3.4
/UART2 RX: IC4.27 (IO16), J2.4
/UART2 TX: IC4.28 (IO17), J2.2
GNDA: IC2.4 (GND1), IC4.14 (GND_1), IC4.32 (GND_2), IC4.38 (GND_3), J1.5, J2.5, J3.5, J4.5, J5.2, JP14.2 (B), PS1.9 (-VOUT)
GNDB: C2.2, C3.2, C4.2, C5.2, IC1.2 (GND), IC2.5 (GND2), IC3.2 (GND), J7.5, JP14.1 (A), PS1.1 (-VIN), R2.2, R8.1
unnamed: C3.1, R9.2, R10.1
unnamed: D1.1 (K), R8.2
unnamed: IC1.7 (CANH), J7.1, JP1.2 (B), JP2.2 (B), JP13.2 (B)
unnamed: IC1.6 (CANL), J7.2, JP3.1 (A), JP12.2 (B), R7.2
unnamed: IC1.1 (D), IC2.6 (OUTB)
unnamed: IC1.4 (R), IC2.7 (INA)
unnamed: IC1.8 (RS), R2.1
unnamed: IC2.3 (INB), IC4.33 (IO21), J5.3
unnamed: IC2.2 (OUTA), IC4.36 (IO22), J5.4
unnamed: J5.5, JP13.1 (A)
unnamed: J5.6, JP12.1 (A)
unnamed: JP1.1 (A), R7.1
unnamed: JP2.1 (A), R9.1
unnamed: JP3.2 (B), R10.2
unnamed: J1.6, JP4.1 (A), JP5.1 (A)
unnamed: J2.6, JP6.1 (A), JP7.1 (A)
unnamed: J3.6, JP8.1 (A), JP9.1 (A)
unnamed: J4.6, JP10.1 (A), JP11.1 (A)

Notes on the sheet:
optionaler Steckplatz für Transceiver Breakout
Digital IO
UART / I2C
SPI
Analog/Digital IO


Board: 2 copper layers, 69.0 x 86.0 mm, 35 parts (0 on the bottom side), 40 nets.

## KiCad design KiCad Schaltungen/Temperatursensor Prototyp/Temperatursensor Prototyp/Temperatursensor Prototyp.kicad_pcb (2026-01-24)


Board: 2 copper layers, 36.5 x 25.5 mm, 19 parts (0 on the bottom side), 11 nets.

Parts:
5V: TestPoint; TestPoint_Pad_D2.0mm
D1: D; DIOM5336X250N
D2: Rot; LEDM3216X130N
GND: TestPoint_Probe; TestPoint_Keystone_5000-5004_Miniature
GNDB: TestPoint_Probe; TestPoint_Keystone_5000-5004_Miniature
IC1: AD22100KTZ; TO128P419X483X533-3P
IC2: LMV331ILT; SOT95P280X145-5N
IC3: VOFD341A-X008T; SOIC127P1150X378-6N
J1, J2: Conn_01x03; PinSocket_1x03_P2.54mm_Vertical
R1, R4: 6,2k; R_1206_3216Metric
R2: 12k; R_1206_3216Metric
R3: 220; R_1206_3216Metric
REF: TestPoint_Probe; TestPoint_Keystone_5000-5004_Miniature
Signal: TestPoint; TestPoint_Pad_D2.0mm
Temp: TestPoint; TestPoint_Pad_D2.0mm
VBB: TestPoint; TestPoint_Pad_D2.0mm
VR1: TC33X-2-503E; TC33X2503E

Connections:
+5V: 5V.1, IC1.1 (V+), IC2.5 (VCC+), J2.1, R3.2, VR1.3 (CW)
/V_Temp: IC2.3 (IN-), J2.2, R1.2, R2.1, Temp.1
GND: GND.1, IC1.3 (GND), IC2.2 (VCC-), IC3.3 (C), J2.3, R2.2, VR1.1 (CCW)
GNDBB: GNDB.1, IC3.4 (VEE), J1.3
unnamed: D1.2 (A), J1.2
unnamed: D1.1 (K), D2.1 (K), IC3.5 (VO), Signal.1
unnamed: IC1.2 (VO), R1.1
unnamed: IC2.1 (IN+), REF.1, VR1.2 (WIPER)
unnamed: IC2.4 (OUT), IC3.1 (A), R3.1
unnamed: IC3.6 (VCC), J1.1, R4.2, VBB.1
unnamed: D2.2 (A), R4.1

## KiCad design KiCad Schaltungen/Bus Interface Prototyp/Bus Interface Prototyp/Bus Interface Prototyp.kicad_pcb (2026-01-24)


Board: 2 copper layers, 38.5 x 35.0 mm, 18 parts (0 on the bottom side), 15 nets.

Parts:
3V3F, 3V3L, 5V, 24V: TestPoint; TestPoint_Pad_D2.0mm
C2: 10u; C_1206_3216Metric
GNDB: TestPoint_Probe; TestPoint_Keystone_5000-5004_Miniature
GNDL: TestPoint_Probe; TestPoint_Keystone_5000-5004_Miniature
IC1: SN65HVD230QDRG4Q1; SOIC127P600X175-8N
IC2: ISO7721FDR; SOIC127P600X175-8N
IC3: L78L33ABUTR
J1: Conn_01x04; PinHeader_1x04_P2.54mm_Vertical
J2: Conn_01x06; PinHeader_1x06_P2.54mm_Vertical
J4: Conn_01x03; PinHeader_1x03_P2.54mm_Vertical
LED1: 156120GS75000
PS1: RSH3-2405S_H2-R; RSH32405SH2R
R1: 470; R_1206_3216Metric
R2: 10k; R_1206_3216Metric
R3: 120; R_1206_3216Metric

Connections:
+3V3B: 3V3F.1, IC1.3 (VCC), IC2.8 (VCC2), IC3.1 (VOUT), LED1.2 (A)
+5V: 5V.1, J2.5, PS1.8 (+VOUT)
+24V: 24V.1, C2.1, IC3.3 (VIN), J1.1, PS1.14 (+VIN)
GNDB: C2.2, GNDB.1, IC1.2 (GND), IC2.5 (GND2), IC3.2 (GND_1), IC3.4 (GND_2), J1.2, PS1.1 (-VIN), R1.2, R2.2
GNDL: GNDL.1, IC2.4 (GND1), J2.4, J2.6, PS1.9 (-VOUT)
unnamed: IC1.7 (CANH), J1.3, J4.1
unnamed: IC1.6 (CANL), J1.4, R3.2
unnamed: IC1.1 (D), IC2.6 (OUTB)
unnamed: IC1.4 (R), IC2.7 (INA)
unnamed: IC1.8 (RS), R2.1
unnamed: IC2.3 (INB), J2.3
unnamed: IC2.2 (OUTA), J2.2
unnamed: 3V3L.1, IC2.1 (VCC1), J2.1
unnamed: J4.2, R3.1
unnamed: LED1.1 (K), R1.1

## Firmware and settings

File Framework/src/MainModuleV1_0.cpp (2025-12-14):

#include "MainModuleV1_0.h"
#include <Arduino.h>
#include "CANTramCore.h"
#include <SPI.h>
#include "OutputDefinition.h"
#include "Debug.h"
#include "HardwareResource.h"
#include "driver/adc.h"
#include "soc/adc_channel.h"
#include "esp_adc_cal.h"
#include "Adafruit_MCP23X17.h"


const String MainModuleV1_0::HW_TYPE = "MainModuleV1.0";
const String MainModuleV1_0::HW_VERSION = "1.0";
const String MainModuleV1_0::FW_VERSION = "1.0";

/**
 * @brief Reset the module and its hardware cores.
 * @details Calls reset on UART and PWM cores and resets the shift register to return the module to a known default state.
 * @return true if all resets succeeded, false if any reset failed.
 */
bool MainModuleV1_0::reset(){
    INFO_PRINTLN("[MainModuleV1_0] Resetting module...");
    bool result = uart.reset();
    result &= _pwmCore.reset();
    //reset i2c
    result &= resetShiftRegister();

    //reset CAN core
    result &= canCore.reset();

    INFO_PRINTLN("[MainModuleV1_0] Module reset complete.");
    return result;
}

/**
 * @brief Attach this module to a slot and GPIO start index.
 * @details Calls the base CANTramModule attach implementation and performs any module-specific attach logic.
 * @param slot Slot index to attach the module to.
 * @param gpioStart Starting GPIO index assigned to this module.
 * @return true if the attach operation was successful, false otherwise.
 */
bool MainModuleV1_0::attachModule(uint8_t slot, uint8_t gpioStart){
    bool result = true;
    result &= CANTramModule::attachModule(slot, gpioStart);
    
    return result;
}

/**
 * @brief Provide GPIO output definitions to CANTramCore.
 * @details Registers the module's output definition table with CANTramCore so the core can manage GPIO provisioning for this module.
 * @return true if output definitions were added successfully, false otherwise.
 */
bool MainModuleV1_0::provideGPIOs(){

    
    
    //Add output definitions to core
    CANTramCoreError err = CANTramCore::addOutputDefinitions(EXTEND, GPIO_SUPPLY);
    DEBUG_PRINTLN("[MainModuleV1_0] Added " + String(GPIO_SUPPLY) + " output definitions, result: " + String((int)err));
    bool result = (err == CANTramCoreError::CAN_TRAM_OK);

    

    return result;
}

/**
 * @brief Request GPIOs from the core.
 * @details Called by the core when module GPIOs should be configured/allocated. Module should request any runtime GPIOs here.
 * @return true if requests succeeded, false otherwise.
 */
bool MainModuleV1_0::requestGPIOs(){
    return true;
}

/**
 * @brief Provide hardware resources (UART, PWM, etc.) to CANTramCore.
 * @details Attaches hardware resource instances to the core so other modules may request/use them.
 * @return true if all resources were attached successfully, false otherwise.
 */
bool MainModuleV1_0::provideHardwareResources(){
    bool result = true;
    
    result &= CANTramCore::attachHardwareResource(&uart);
    uart.setUARTPort(UART_NUM); 
    result &= CANTramCore::attachHardwareResource(&_pwmCore);
    result &= CANTramCore::attachHardwareResource(&canCore);
    result &= CANTramCore::attachHardwareResource(&i2cCore);
    i2cCore.setMaxFrequency(SHIFTREGISTER_I2C_FREQUENCY); //Set max allowed frequency for I2C bus
    return result;
}

/**
 * @brief Request hardware resources from the core.
 * @details Called when the module should request any hardware resources it needs. Implement module-specific requests here.
 * @return true if all resource requests were granted, false otherwise.
 */
bool MainModuleV1_0::requestHardwareResources(){

    
    return true;
}

/**
 * @brief Register any interfaces provided by this module.
 * @details Add interface instances to the module so the core can enumerate and use them.
 * @return true if interfaces were added successfully, false otherwise.
 */
bool MainModuleV1_0::addInterfaces(){
    
    //Add CAN interface
    canInterface.rename("CAN1");
    canInterface.setCANCore(&canCore);
    _interfaces[0] = &canInterface;

    return true;
}
/**
 * @brief Pre-initialize the module after attachment.
 * @details Initializes I2C core before main intialization, because the shiftregister needs to be started to set the gpios of the extend bus.
 * @return true if pre-initialization succeeded, false otherwise.
 */
bool MainModuleV1_0::preInitialize(){
    bool result=true;
    //Init I2C
    auto initI2C = [&]() -> bool {
        if(i2cCore.getI2CStatus() == I2CCore::I2CStatus::I2C_STARTED) {
            INFO_PRINTLN("[MainModuleV1_0] I2C already started.");
            return true;
        }
        INFO_PRINT("[MainModuleV1_0] Initializing I2C... ");
        i2cCore.setPins(I2C_SDA, I2C_SCL);
        i2cCore.setBufferSize(I2C_BUFFER_LENGTH);
        i2cCore.setI2CNum(I2C_NUM_0);
        
        if(!i2cCore.begin()){
            ERROR_PRINTLN("[MainModuleV1_0] I2C initialization failed! ");
            return false;
        }
        INFO_PRINTLN("Done.");
        return true;
    };
    result &= initI2C();

    auto initShiftRegister = [&]() -> bool {
        INFO_PRINTLN("[MainModuleV1_0] Initializing shift register... ");
        //Wire.begin(I2C_SDA, I2C_SCL,I2CCore::I2C_DEFAULT_FREQUENCY); //should already be initialized by i2cCore
        bool res = startShiftRegister();
        return res;
    };
    result &= initShiftRegister();

    auto initOutputs = [&]() -> bool {
    //Configure outputs
        bool b=true;
        INFO_PRINTLN("[MainModuleV1_0] Configuring outputs...");
        for (OutputDefinition& def : EXTEND) {
         b &= configureOutput(&def);
        }
        return b;
    };
    result &= initOutputs();
    
    return result;
}
/**
 * @brief Initialize the module and its hardware subsystems.
 * @details Initializes UART, PWM, I2C, SPI and ADC subsystems as required by the module. This prepares the module for operation after attachment and resource provisioning.
 * @return true if all initialization steps succeeded, false if any step failed.
 */
bool MainModuleV1_0::initialize(){
    bool result = true;

    

    /**
     * @brief Initialize the shift register for GPIO expansion.
     * @details Configuration of shift register must happen before initialization of the core!
     * @details Otherwise errors will be generated since the core is not able to set the initial values of these outputs
     * @return true if initialization succeeded, false otherwise.
     */
    

    

    //Init UART
    auto initUART = [&]() -> bool {
        if(!uart.isUsed()) return true;
        INFO_PRINT("[MainModuleV1_0] Initializing UART... ");
        if(!uart.install(UART_NUM, UART_TX, UART_RX, UART_BUFFER_SIZE)){
            ERROR_PRINTLN("[MainModuleV1_0] UART initialization failed! Programm stopped.");
            return false;
        }
        if(!uart.applyConfig()){
            ERROR_PRINTLN("[MainModuleV1_0] UART configuration failed! Programm stopped.");
            return false;
        }
        if(!uart.applyPins()){
            ERROR_PRINTLN("[MainModuleV1_0] UART pin assignment failed! Programm stopped.");
            return false;
        }
        INFO_PRINTLN("Done.");
        return true;
    };
    result &= initUART();

    //Init PWM
    auto initPWM = [&]() -> bool {
        if(!_pwmCore.isUsed()) return true;
        INFO_PRINT("[MainModuleV1_0] Initializing PWM... ");
        _pwmCore.begin();
        
        INFO_PRINTLN("Done.");
        return true;
    };
    result &= initPWM();

    

    //Init SPI
    auto initSPI = [&]() -> bool {
        INFO_PRINT("[MainModuleV1_0] Initializing SPI... ");
        SPI.begin(SPI_SCK, SPI_CIPO, SPI_COPI, -1); // -1 for CS pin, as we will set it manually
        if (!SPI.bus()) {
            CRITICAL_ERROR_PRINTLN("[MainModuleV1_0] SPI initialization failed! No SPI bus available. Program stopped.");
            while(1);
        };
        INFO_PRINTLN("Done.");
        return true;
    };
    result &= initSPI();

    //Init ADC for temperature measurement
    auto initADC = [&]() -> bool {
        INFO_PRINTLN("[MainModuleV1_0] Initializing ADC for temperature measurement... ");

        #ifdef CONFIG_IDF_TARGET_ESP32_C3
        //Init DMA Controller for ADC
        adc_digi_init_config_t adc_init_config = {
            .max_store_buf_size = TEMP_MULTISAMPLE * sizeof(adc_digi_output_data_t),
            .conv_num_each_intr = TEMP_MULTISAMPLE,
            .adc1_chan_mask = (1 << TEMP_ADC_CHANNEL),
            .adc2_chan_mask = 0
        };

        //Configuration for used ADC Channel
        adc_digi_pattern_config_t adc_pattern = {
            .atten = ADC_ATTEN_DB_12,
            .channel = TEMP_ADC_CHANNEL,
            .unit = ADC_UNIT_1,
            .bit_width = ADC_WIDTH_BIT_11,
            
            
        };

        //Configuration for digital controller
        adc_digi_configuration_t adc_config = {
            .conv_limit_en = false,
            .conv_limit_num = 0,
            .pattern_num = 1,
            .adc_pattern = &adc_pattern,
            .sample_freq_hz = 1024,
            .format = ADC_DIGI_OUTPUT_FORMAT_TYPE1 //uses 11bit for data
        };

        adc_digi_initialize(&adc_init_config);
        adc_digi_controller_configure(&adc_config);
        adc_digi_start();
        INFO_PRINTLN("[MainModuleV1_0] ADC for temperature measurement initialized. Multisampling: " + String(TEMP_MULTISAMPLE) + " samples.");

        #elif CONFIG_IDF_TARGET_ESP32

        INFO_PRINTLN("[MainModuleV1_0] Calibrating ADC... ");
        //Calibrate ADC
        esp_err_t ret = esp_adc_cal_check_efuse(ESP_ADC_CAL_VAL_EFUSE_TP);
        if(!(ret == ESP_OK)) {
            WARNING_PRINTLN("[MainModuleV1_0] Warning: eFuse Two Point values not supported. ADC calibration disabled.");
        }else{
            INFO_PRINTLN("[MainModuleV1_0] eFuse Two Point values supported. ADC calibration enabled.");
            esp_adc_cal_characterize(ADC_UNIT_1, ADC_ATTEN_DB_12, ADC_WIDTH_BIT_12, ADC_DEFAULT_VREF, &adc1_chars);
            adc_calibrated = true;
        }

        ret = esp_adc_cal_check_efuse(ESP_ADC_CAL_VAL_EFUSE_VREF);
        if(!(ret == ESP_OK)) {
            WARNING_PRINTLN("[MainModuleV1_0] Warning: eFuse Vref value not supported. ADC calibration disabled.");
        }else{
            INFO_PRINTLN("[MainModuleV1_0] eFuse Vref value supported. ADC calibration enabled.");
            esp_adc_cal_characterize(ADC_UNIT_1, ADC_ATTEN_DB_12, ADC_WIDTH_BIT_12, ADC_DEFAULT_VREF, &adc1_chars);
            adc_calibrated = true;
        }
        

        //Configure single read mode for temperature measurement
        adc1_config_width(ADC_WIDTH_BIT_12);
        adc1_config_channel_atten(TEMP_ADC_CHANNEL, ADC_ATTEN_DB_12);
        INFO_PRINTLN("[MainModuleV1_0] ADC for temperature measurement initialized.(Hardware multisampling not supported)");

        #endif

        

        return true;
    };
    result &= initADC();

    

    

    //Init CAN
    auto initCAN = [&]() -> bool {
        INFO_PRINT("[MainModuleV1_0] Initializing CAN... ");

        //set pins for can 
        canCore.setPins(CAN_TX, CAN_RX);
        if(canCore.getBaudrate() == CANCore::BR_NOT_SET){
            //Set default baudrate if not set
            canCore.setBaudrate(CANTramCore::DEFAULT_CAN_BAUDRATE);
        }
        if(!canCore.begin()){
            ERROR_PRINTLN("[MainModuleV1_0] CAN initialization failed! Program stopped.");
            canInterface.invalidate();
            return false;
        }

        //Baudrate should be set by CAN interface when requested by user, so just set default here
        
        INFO_PRINTLN("Done.");
        return true;
    };
    result &= initCAN();

    //Init LEDs
    shiftRegister.pinMode(LED_WARNING, OUTPUT);
    shiftRegister.pinMode(LED_ERROR, OUTPUT);

    return result;
}

/**
 * @brief Periodic cycle callback for the module.
 * @details Called by the core to perform periodic tasks. Implement module-specific cyclic behavior here.
 * @param response Pointer to a response buffer where the module may write response bytes. May be nullptr if not used.
 */
void MainModuleV1_0::cycle(uint8_t* response){

    getTemperatureCelsius(); //Just read temperature periodically

    //Not implemented correctly yet, just for testing
    #warning "DEV WARNING: LED handling in MainModuleV1_0::cycle() is just for testing purposes!. Remove or implement proper status LED handling!"
    shiftRegister.digitalWrite(LED_WARNING, 1); //Toggle warning LED
    shiftRegister.digitalWrite(LED_ERROR, 1); //Toggle error
}



/**
 * @brief Set PWM duty for an output definition.
 * @details Validates the output definition for PWM capability and delegates to the PWM core to set the duty cycle.
 * @param def Pointer to the OutputDefinition describing the output.
 * @param value Duty value to set (implementation-specific range).
 * @return true if PWM was set successfully, false on error (e.g., non-PWM output).
 */
bool MainModuleV1_0::setPWM(OutputDefinition* def, uint16_t value) {
    if(!def->pwm) {
        ERROR_PRINTLN("[MainModuleV1_0] ERROR: Attempted to set PWM on non-PWM output "+ String(def->toString()));
        return false;
    }
    if(def->isShift) {
        ERROR_PRINTLN("[MainModuleV1_0] ERROR: Shift register PWM output not implemented yet for output "+ String(def->toString()));
        return false;
    } else {
        // Handle direct GPIO PWM output
        _pwmCore.setDuty(def, value);
        INFO_PRINTLN("[MainModuleV1_0] INFO: Setting PWM on GPIO pin " + String(def->pinOrBit) + " to " + String(value));
        return true; //Assume always successful for now
    }
}

/**
 * @brief Register a PWM channel for an output.
 * @details Initializes PWM core and requests a channel allocation for the given output definition.
 * @param def Pointer to the OutputDefinition to register for PWM.
 * @return true if channel registration succeeded, false otherwise.
 */
bool MainModuleV1_0::registerPWMChannel(OutputDefinition* def) {
    _pwmCore.begin();
    if(!def->pwm) {
        ERROR_PRINTLN("[MainModuleV1_0] Attempted to register PWM channel on non-PWM output "+ String(def->toString()));
        return false;
    }
    if(def->isShift) {
        ERROR_PRINTLN("[MainModuleV1_0] Attempted to register PWM channel on shift register output "+ String(def->toString()));
        return false;
    } else {
        return _pwmCore.addChannel(def);
    }
}
/**
 * @brief Get the temperature in Celsius in 0.1°C steps
 * @details Reads ADC samples (digital controller on C3, single reads on ESP32) and converts them to temperature using calibration or approximation. Returns temperature in tenths of a degree Celsius (e.g., 253 means 25.3°C).
 * @return int16_t Temperature in 0.1°C steps.
 */
uint16_t MainModuleV1_0::getTemperatureCelsius() {

    #ifdef CONFIG_IDF_TARGET_ESP32_C3
    //Using digital controller with DMA
   //Read multiple samples and calculate average
    uint8_t adc_reading[TEMP_MULTISAMPLE*sizeof(adc_digi_output_data_t)];
    uint32_t total = 0;
    adc_digi_read_bytes((uint8_t*)adc_reading, sizeof(adc_reading),&total, ADC_MAX_DELAY);

    //calculate sum of samples
    adc_digi_output_data_t* data = (adc_digi_output_data_t*)adc_reading;  //Pointer to the data
    uint32_t sum = 0;
    for(int i=0; i < TEMP_MULTISAMPLE; i++) {
        sum += data[i].type1.data; //Using type1 as we configured ADC to use 12bit format
    }
    DEBUG_PRINTLN("[MainModuleV1_0] ADC Temperature reading sum: " + String(sum));
    DEBUG_PRINTLN("[MainModuleV1_0] ADC Temperature samples: "+String(total));

    //calculate average
    uint16_t avg = sum / TEMP_MULTISAMPLE;
    DEBUG_PRINTLN("[MainModuleV1_0] ADC Temperature reading average: " + String(avg));
    #elif CONFIG_IDF_TARGET_ESP32

    //Using single read mode with hardware multisampling not supported
    uint32_t avg;
    uint16_t voltage;
    avg = adc1_get_raw(TEMP_ADC_CHANNEL);
    DEBUG_PRINTLN("[MainModuleV1_0] ADC Temperature reading raw value: " + String(avg));

    if(adc_calibrated) {
        //Convert raw reading to voltage in millivolts using calibration
        voltage = esp_adc_cal_raw_to_voltage(avg, &adc1_chars);
        DEBUG_PRINTLN("[MainModuleV1_0] ADC Temperature reading voltage(calibrated): " + String(voltage) + " mV");
    }else{
        //Convert to voltage in millivolts
        voltage = uint16_t(avg * ADC_MAX_VOLTAGE / 4095); //12bit ADC max value is 4095
        DEBUG_PRINTLN("[MainModuleV1_0] ADC Temperature reading voltage(uncalibrated): " + String(voltage) + " mV");

    }
    #endif

    //Convert to sensor voltage in millivolts
    uint16_t sensorVoltage = uint16_t((float)voltage / TEMP_FAKTOR);
    DEBUG_PRINTLN("[MainModuleV1_0] ADC Temperature sensor voltage: " + String(sensorVoltage) + " mV");

    //Convert to temperature using the sensor characteristics
    int16_t temperatureC = float(sensorVoltage - 1375) / float(22.5f)*10.0f; //in 0.1°C steps
    DEBUG_PRINTLN("[MainModuleV1_0] Calculated temperature: " + String(temperatureC/10.0f) + " °C");
    
    return temperatureC;
}

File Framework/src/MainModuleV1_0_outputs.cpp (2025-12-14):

/**
 * @file MainModuleV1_0_outputs.cpp
 * @author your name (you@domain.com)
 * @brief This file contains all output related functionallity of the MainmoduleV1_0. This includes native GPIO pins and shift register pins.
 * @version 0.1
 * @date 2025-10-24
 * 
 * @copyright Copyright (c) 2025
 * 
 */
#include "MainModuleV1_0.h"
#include <Arduino.h>
#include "CANTramCore.h"
#include <SPI.h>
#include "OutputDefinition.h"
#include "Debug.h"
#include "HardwareResource.h"
#include "driver/adc.h"
#include "soc/adc_channel.h"
#include "esp_adc_cal.h"
#include "Adafruit_MCP23X17.h"

/**
 * @brief Construct a new MainModuleV1_0::MainModuleV1_0 object
 * 
 * @details This constructor explicitly calls the ESP32_I2CCore constructor with I2C bus 0 so Wire instead of Wire1 is used.
 */
MainModuleV1_0::MainModuleV1_0() : i2cCore(ESP32_I2CCore::ESP_I2C_NUM_0) {    
}


/**
 * @brief Configures the output for a specific pin or bit.
 * 
 * @param def GPIO number or shiftRegister output ID of desired output
 * @param mode (Optional) Specify the direction of the pin. Default is OUTPUT
 * @return true, if the cofiguration was completed successfully
 * @return false, if error were encountered during the configuration. See output log for more details
 */
bool MainModuleV1_0::configureOutput(OutputDefinition* def, uint8_t mode) {
    if(def->isShift) {
        #ifdef MAINMODULE_NO_SHIFTREGISTER
        DEV_ERROR_PRINTLN("[MainModuleV1_0] Shift register functionality disabled. Check your code for the Makro \"MAINMODULE_NO_SHIFTREGISTER\". This macro prevents the usage of the shiftregister");
        return true;
        #endif
        //Check if shift register is accessible
        if(!startShiftRegister()){
            ERROR_PRINTLN("[MainModuleV1_0] Output "+ def->toString()+ "couldn't be configured.");
            return false;
        }
        shiftRegister.pinMode(def->pinOrBit, mode);
        INFO_PRINTLN("[MainModuleV1_0] Output "+def->toString() + " configured in mode "+String(mode));
        
        
        // Example: ShiftRegister.configure(def.pinOrBit, mode);
        //ERROR_PRINTLN("[MainModuleV1_0] ERROR: Shift register configure output not implemented yet for output "+ String(def->toString()));
        return true;
    }
    if(def->inputOnly) {
        ERROR_PRINTLN("[MainModuleV1_0] ERROR: Attempted to configure input-only output "+ String(def->toString()));
        return false;
    }
    gpio_reset_pin(static_cast<gpio_num_t>(def->pinOrBit));
    gpio_set_direction(static_cast<gpio_num_t>(def->pinOrBit), static_cast<gpio_mode_t>(mode));
    INFO_PRINTLN("[MainModuleV1_0] INFO: Configured GPIO pin " + String(def->pinOrBit) + " as OUTPUT");
    return true;
}

/**
 * @brief Set the logic level on a pin of the module
 * 
 * @param def Output to set the state
 * @param state logic level HIGH or LOW
 * @return true, if logic level was set correctly
 */
bool MainModuleV1_0::setOutput(OutputDefinition* def, bool state) {
    if(def->isShift) {
        //Check if shift register is accessible
        #ifdef MAINMODULE_NO_SHIFTREGISTER
        DEV_ERROR_PRINTLN("[MainModuleV1_0] Shift register functionality disabled. Check your code for the Makro \"MAINMODULE_NO_SHIFTREGISTER\". This macro prevents the usage of the shiftregister");
        return true;
        #endif

        
        if(!_shiftregisterStatus==STARTED){
            ERROR_PRINTLN("[MainModuleV1_0] Shift register not started. Cannot set output "+ def->toString());
            return false;
        }  
        
        //Set new state of the desired pin
        shiftRegister.digitalWrite(def->pinOrBit,state);

        //Check if pin was set correctly
        if(shiftRegister.digitalRead(def->pinOrBit)!=state){
            ERROR_PRINTLN("[MainModuleV1_0] Failed to write logic level "+ String(state)+" to output "+ def->toString());
            return false;
        }
        // Handle shift register output
        // Example: ShiftRegister.setOutput(def.pinOrBit, state);
        //DEV_ERROR_PRINTLN("[MainModuleV1_0] ERROR: Shift register output not implemented yet for output "+ String(def->toString()));
        return true;
    } else {
        // Handle direct GPIO output
        gpio_set_level(static_cast<gpio_num_t>(def->pinOrBit), state );
        DEBUG_PRINTLN("[MainModuleV1_0] INFO: Setting GPIO pin " + String(def->pinOrBit) + " to " + String(state));
        return true; //Assume always successful for now
    }
}
/**
 * @brief Get the current state of a digital output
 * 
 * @param def Output definition containing the pin information
 * @return true if the output state was retrieved successfully
 * @return false if an error occurred
 */
bool MainModuleV1_0::getOutput(OutputDefinition* def) {
    if(def->isShift) {
        //Check if shift register is accessible
        #ifdef MAINMODULE_NO_SHIFTREGISTER
        DEV_ERROR_PRINTLN("[MainModuleV1_0] Shift register functionality disabled. Check your code for the Makro \"MAINMODULE_NO_SHIFTREGISTER\". This macro prevents the usage of the shiftregister");
        return false;
        #endif
        //Check if shift register is accessible
        if(!_shiftregisterStatus==STARTED) return false;

        //Return the logic level of the pin
        
        bool result = shiftRegister.digitalRead(def->pinOrBit);
        DEBUG_PRINTLN("[MainModule] Shiftregister output "+ def->toString() + " is "+String(result));
        return result;
        // Handle shift register output
        // Example: ShiftRegister.getOutput(def.pinOrBit);
        //ERROR_PRINTLN("[MainModuleV1_0] ERROR: Shift register get output not implemented yet for output "+ String(def->toString()));
        
    } else {
        // Handle direct GPIO output
        int state = gpio_get_level(static_cast<gpio_num_t>(def->pinOrBit));
        return (state == HIGH);
    }
}

/**
 * @brief Starts the integrated shift register in I2C mode.
 * 
 * @return true, is started successfully
 * 
 */
bool MainModuleV1_0::startShiftRegister(){
        //Skip function call if already started
    if((_shiftregisterStatus==STARTED)){
        return true;
    }

    //Check if initialization failed previously
    if(_shiftregisterStatus==FAILED){
        return false;
    }

    //Check if I2C is initialized
    
    //Start in I2C mode
    
    bool result = shiftRegister.begin_I2C(SHIFTREGISTER_I2C_ADDRESS,&i2cCore.getWireInstance());
    if(!result) {
        ERROR_PRINTLN("[MainModuleV1_0] Failed to start shift register. Additional outputs in expander bus wont be usable");
        _shiftregisterStatus = FAILED;
        return false;
    }
    INFO_PRINTLN("[MainModuleV1_0] Shift register started successfully.");
    _shiftregisterStatus = STARTED;
    return result;
}
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

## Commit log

2025-12-14 Enhance README with CANTram framework details
    Added a description of the CANTram framework and its components.
2026-01-24 reordered framework directories
2026-01-24 Added KiCad circuit files and inventor CAD files
    [0395000002.iam, 0395000002_01.ipt, 0395000002_02.ipt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]
2026-01-24 removed esp32 cad modell cause its name caused probelms
    [32E_thermal_pad.STEP.ipt, Bauteil332.ipt, Board~QTmk.ipt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]

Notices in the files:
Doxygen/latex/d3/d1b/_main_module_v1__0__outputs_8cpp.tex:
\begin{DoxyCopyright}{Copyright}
